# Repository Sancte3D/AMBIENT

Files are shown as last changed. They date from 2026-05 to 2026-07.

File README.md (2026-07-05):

# Field Ambience

A field-recorder-style ambient instrument. Hardware-software product in
active development — generative audio engine running on STM32H7, controlled
by an OP-1-inspired 320×170 IPS display + four endless encoders.

**Current state: prototype.** Audio engine runs on Pico 2 host tests and a
display bench, hardware migration to STM32H743 is in progress, no PCB layout
yet — **not orderable**.

## Five-minute tour

| What | Where | Status |
|---|---|---|
| **Product intent** (what we're building, for whom) | [`field-ambience-current/PITCH.md`](field-ambience-current/PITCH.md) | concept locked |
| **Sound engine** (host-portable C, the heart) | [`field-ambience-current/firmware-c-next/`](field-ambience-current/firmware-c-next/) | active, 12 host test suites green |
| **Web simulator** (try the menu in a browser) | [`field-ambience-current/firmware-c-next/tools/display_sim.html`](field-ambience-current/firmware-c-next/tools/display_sim.html) + GitHub Pages | live |
| **Bench bring-up** (Pico 2 + ST7789 + KY-040 → flashable UF2) | [`field-ambience-current/firmware-c-next/tools/display_hw_test.c`](field-ambience-current/firmware-c-next/tools/display_hw_test.c) | works on real hardware |
| **Hardware schematic** (8 sheets, generator-based) | [`field-ambience-current/kicad/`](field-ambience-current/kicad/) | STM32H743 migration done (r18.6), **no `.kicad_pcb` yet** |
| **What we know about the parts** (datasheets, verifications) | [`field-ambience-current/docs/component_reviews/`](field-ambience-current/docs/component_reviews/) | 2 reviews complete, ~20 open |
| **What's blocking manufacturing** | [`field-ambience-current/PCB_LAYOUT_STATUS.md`](field-ambience-current/PCB_LAYOUT_STATUS.md) | honest, updated every revision |
| **How decisions were made** | [`field-ambience-current/docs/decisions/`](field-ambience-current/docs/decisions/) | 20 ADRs (rejected ones marked SUPERSEDED) |
| **Render samples to listen to** | [`demos/audio/`](demos/audio/) | 4 FLAC: master tape, performance, GENERATE autoplay, 4-min simulated human play session (drone+cells+menu, real device paths) |
| **Full project map / what to open first per role** | [`PROJECT_MAP.md`](PROJECT_MAP.md) | role-based |

## Who you are, what to read first

- **Industrial designer** → [`docs/onboarding/INDUSTRIAL_DESIGNER_START.md`](field-ambience-current/docs/onboarding/INDUSTRIAL_DESIGNER_START.md)
- **Hardware engineer** → [`docs/onboarding/HARDWARE_ENGINEER_START.md`](field-ambience-current/docs/onboarding/HARDWARE_ENGINEER_START.md)
- **Firmware engineer** → [`docs/onboarding/FIRMWARE_ENGINEER_START.md`](field-ambience-current/docs/onboarding/FIRMWARE_ENGINEER_START.md)
- **Anyone trying to order PCBs** → [`docs/onboarding/MANUFACTURING_START.md`](field-ambience-current/docs/onboarding/MANUFACTURING_START.md)
- **New contributor, general** → [`START_HERE.md`](field-ambience-current/START_HERE.md)

## Folder logic (current repo state)

```
AMBIENT/
├── README.md                    ← this file
├── PROJECT_MAP.md               ← what lives where, by role
├── REPO_STRUCTURE.md            ← roadmap for the bigger refactor
├── CONTRIBUTING.md
├── demos/audio/                 ← FLAC renders to listen to
├── mechanical/coordinates/      ← X/Y/Z placement spec (r18.13 ex-field-ambience-current/)
├── software/
│   ├── webapp/                  ← in-browser engine reference (field_ambience_webapp.html)
│   └── supercollider_reference/ ← canonical SC engine (field_ambience_v29o.scd)
├── archive/
│   ├── legacy_pre_native/       ← pre-native bridge.py, MicroPython firmware
│   ├── old_specs/               ← pre-Step-6 pitch + roadmap
│   └── PCB_TODO_historical.md   ← pre-H743 hardware issue log (history only)
└── field-ambience-current/      ← active design + code + docs
    ├── START_HERE.md
    ├── PCB_LAYOUT_STATUS.md     ← honest manufacturing state
    ├── CHANGELOG.md             ← what changed and when
    ├── NATIVE_PORT_PLAN.md      ← Pico → STM32H7 migration plan
    ├── field_ambience_pcb_SPEC_v0.7.md  ← live hardware spec
    ├── firmware-c/              ← FROZEN host-test snapshot (Pico era)
    ├── firmware-c-next/         ← ACTIVE firmware development
    ├── kicad/                   ← schematic + custom footprints
    │   ├── legacy_pico2/        ← old Pico-era sheets, archived
    │   └── libraries/           ← kiswitch (vendored) + field_ambience.pretty
    ├── docs/                    ← decisions / hardware checklists / component reviews
    └── scripts/                 ← KiCad ERC/footprint helpers
```

> **Note on folder names:** Most living material is still under
> `field-ambience-current/`. A larger repo refactor is planned (firmware
> separation, CI-path migration) — it's intentionally staged so the live
> CI doesn't break. See [REPO_STRUCTURE.md](REPO_STRUCTURE.md) for the
> roadmap.

## Help / contributing

[`CONTRIBUTING.md`](CONTRIBUTING.md) covers commit conventions, how to run
the host tests, and what to check before pushing changes to the schematic
generator.

## License

TBD before public release. Until then: all rights reserved by the project
authors. Open for review and pull requests within the repo, but please
don't redistribute the source elsewhere without asking first.

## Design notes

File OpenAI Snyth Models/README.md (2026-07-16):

# OpenAI Snyth Models

An original, resource-bounded sound and display laboratory for the Sancte3D
AMBIENT instrument. The directory name preserves the requested spelling;
`Snyth` is intentional here.

The package contains ten playable synthesis models, eighteen embedded
audio-reactive display models, twelve embedded colour palettes, and ten
high-quality cinematic display masters. Embedded geometry is generated at
runtime from original C code; the cinematic loops are generated offline from
original deterministic Python recipes. No
recorded samples, MIDI files, extracted presets, transcribed melodies, or
third-party source code are required.

## Sound models

| # | Model | Character | Primary method |
|---:|---|---|---|
| 1 | ACID RAIN | elastic droplets and damp reflections | falling resonators + procedural excitation |
| 2 | FM GLASS | clear mallets with a soft halo | original two-operator phase modulation |
| 3 | CHORUS MIST | wide, slow-breathing pad | detuned analytic oscillators + short chorus |
| 4 | ION STORM | dark electrical air and distant sparks | subharmonics + bounded stochastic accents |
| 5 | GLASS ORBIT | rotating inharmonic bells | four analytic partials + moving pan |
| 6 | BAMBOO CIRCUIT | organic plucks with electronic grain | compact feedback string model |
| 7 | NACRE HORIZON | pearly, almost weightless harmonic bed | sparse open partial field |
| 8 | TIDEGLASS | fluid FM pad with slow refraction | continuously moving modulation ratio |
| 9 | LUMEN SWARM | small lights collecting into harmony | deterministic micro-oscillator cluster |
| 10 | HOLLOW CHOIR | distant vowel-like breath | moving formant partial field |

The presets are starting points only. Six smoothed macros—color, motion,
space, texture, width, and level—make every model performable from the existing
encoder vocabulary.

## Display models

The renderers target a 320 × 170 packed 4-bit framebuffer and need no second
framebuffer or FFT. Five foundational systems cover landscapes, particles, and
contours:

- RESONANT GARDEN — bass grows stems, treble releases luminous pollen.
- ORBITAL LOOM — spectral energy weaves rotating harmonic threads.
- SPECTRAL CANYON — frequency bands become receding animated ridges.
- RAIN MEMORY — transients fall, low energy opens lingering rings.
- DREAM TOPOGRAPHY — the sound continuously redraws a contour-map dream.

Thirteen additional systems explore sound-reactive menu focus, neon spectrum
veins, crystalline needles, abstract radial gates, organic signal ribbons,
path drawing, particle currents, wireframe rain, waveform shells, glitch
halos, bilateral pulses, falling chroma, and radial softbursts. They translate
high-level motion principles into newly authored geometric C renderers; no
reference pixels or recognizable reference figures are included.

The same nibble buffer can act as a 16-colour palette index. Twelve saturated,
slowly animated RGB565 LUTs add colour for only 32 bytes of LUT storage. Tone
14 carries the neon body while tone 15 is reserved for small specular accents.
See
[docs/UI_MODELS.md](docs/UI_MODELS.md) for control mappings,
[docs/MOTION_STUDY_CATALOG.md](docs/MOTION_STUDY_CATALOG.md) for the new
systems, and [docs/REFERENCE_MOTION_ANALYSIS.md](docs/REFERENCE_MOTION_ANALYSIS.md)
for the clean translation record.

The new cinematic suite directly addresses the gap between thin firmware
geometry and the supplied light-art references. Its ten 48-frame loops use 2×
supersampling, additive coloured bodies, clipped white cores, dual-radius
bloom, and deterministic temporal systems. They are honest art masters rather
than a claim that the current nibble renderer already emits the same pixels;
deployment choices for the small device are measured in
[docs/HIGH_QUALITY_VISUALS.md](docs/HIGH_QUALITY_VISUALS.md). The package now
includes 56 GIFs: five base previews, fifteen foundational colour studies, 26
motion studies, and ten cinematic masters.

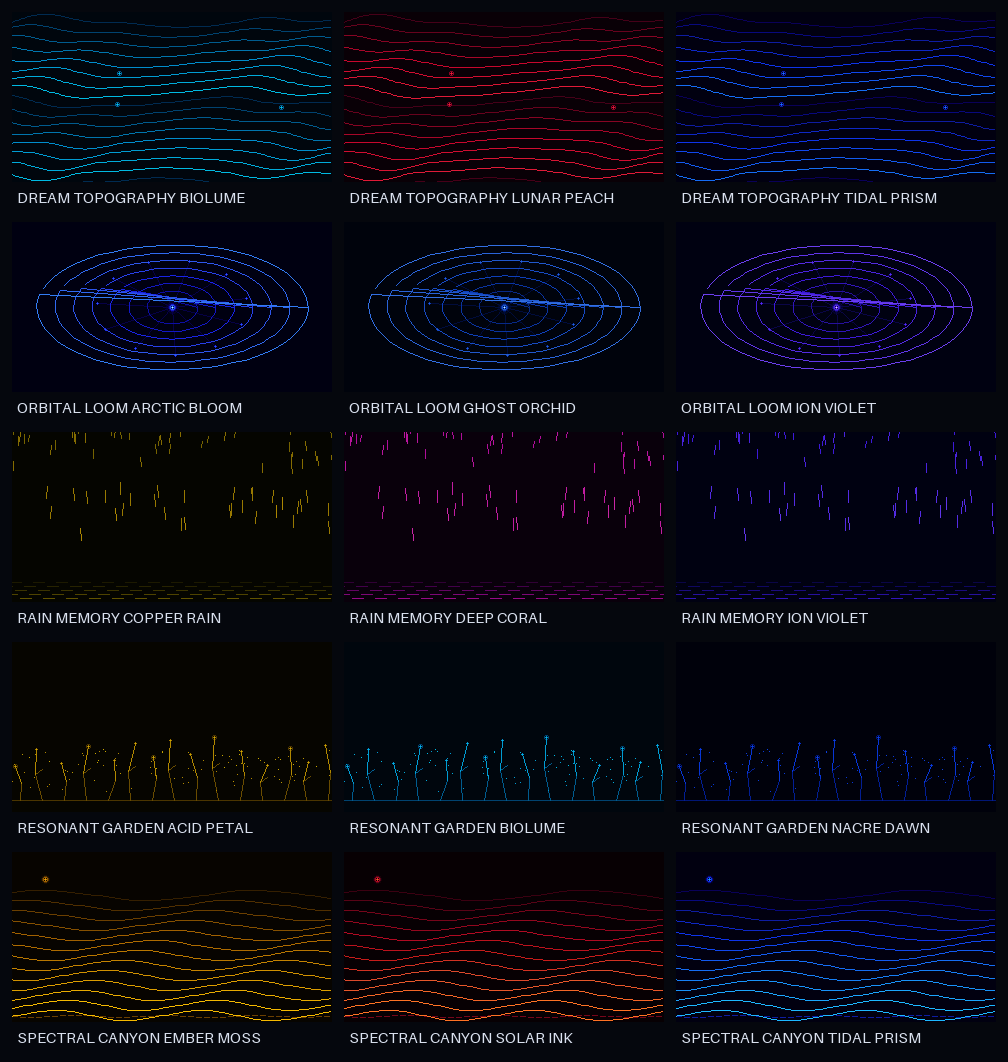
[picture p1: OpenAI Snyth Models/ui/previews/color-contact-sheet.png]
Fifteen colour display studies


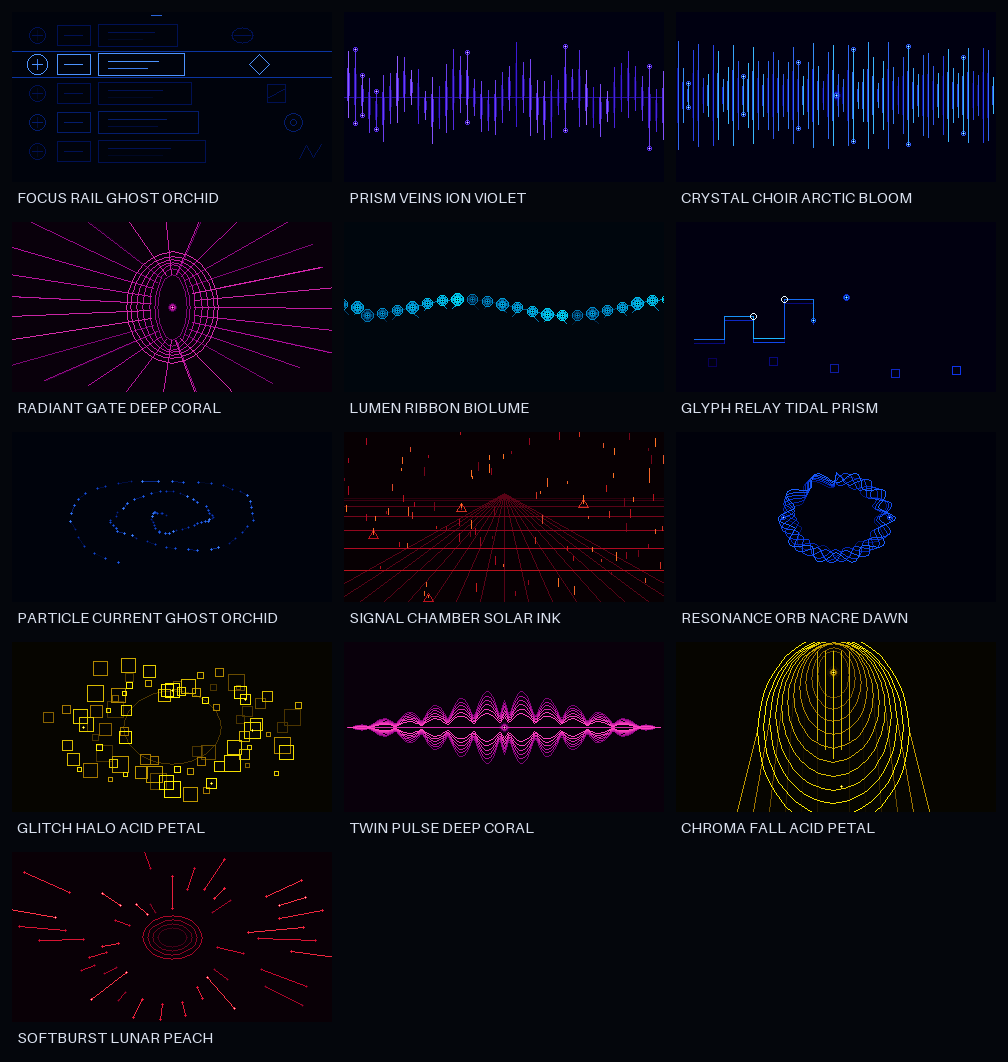
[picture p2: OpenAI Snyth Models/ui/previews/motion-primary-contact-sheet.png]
Thirteen new motion systems


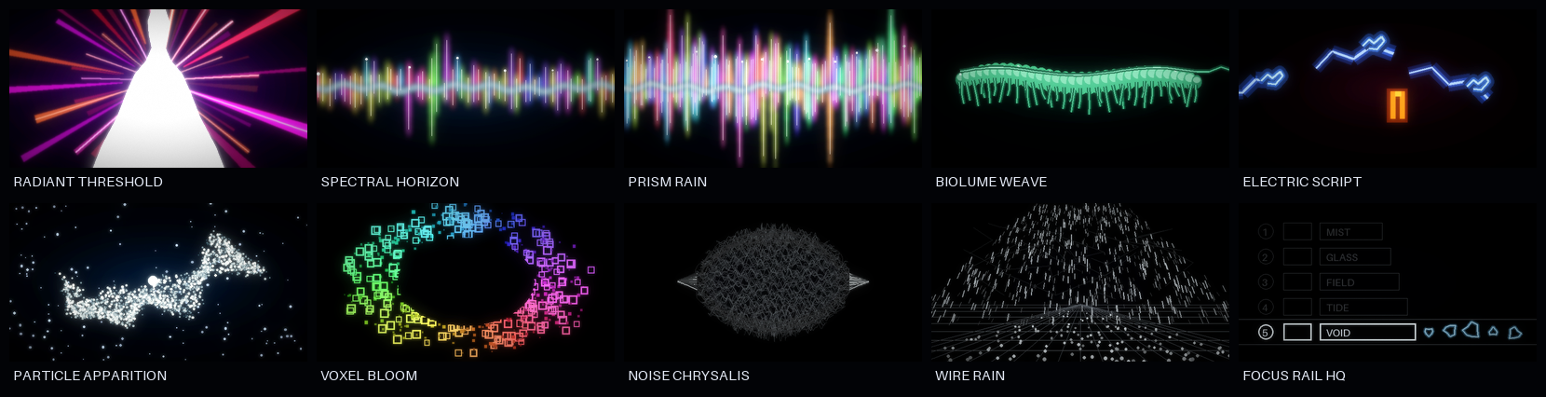
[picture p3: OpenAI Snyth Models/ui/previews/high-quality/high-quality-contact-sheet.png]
Ten high-quality cinematic systems


## Build and verify

Requires a C11 compiler, `make`, and `rg`. Preview generation additionally uses
`ffmpeg`; the colour and cinematic encoders use the Pillow and NumPy versions pinned in
`requirements-preview.txt`.

```sh
make verify
make sanitize
make benchmark
make visual-benchmark
make previews
make manifest
sha256sum -c SOURCE_MANIFEST.sha256
sha256sum -c ASSET_MANIFEST.sha256
```

The state budgets are compile-time assertions:

- audio model context: at most 32,768 bytes;
- visual context: at most 2,048 bytes;
- existing packed framebuffer: 27,200 bytes;
- 16-entry RGB565 palette LUT: 32 bytes;
- additional display framebuffer: 0 bytes.

## Commercial-use posture

The implementation was written from a blank design for this project and is
kept isolated inside this directory. `docs/ORIGINALITY_AND_IP.md` records its
provenance and limits. This is a technical clean-origin package, not a legal
opinion or a trademark clearance. Before shipping, the rights holder should
complete the checklist in that document and choose a customer-facing product
name that does not imply endorsement by another company.

Copyright © 2026 Sancte3D. All rights reserved. See
[LICENSE-PROPRIETARY.md](LICENSE-PROPRIETARY.md).

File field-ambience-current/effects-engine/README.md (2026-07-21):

# AMBIENT effects engine — integration handoff

This directory is a self-contained, buildable handoff of the complete C11
ambient/dreamy/nostalgic effects engine. It is deliberately separate from the
live product firmware so it can be reviewed, tested, and integrated without
silently overwriting the current engine.

Start with [`INTEGRATION_TASK.md`](INTEGRATION_TASK.md). The DSP contract and algorithm
details are in [`docs/EFFECTS_ENGINE.md`](docs/EFFECTS_ENGINE.md).

## Included

- bit-exact bypass;
- long dark eight-line FDN reverb;
- filtered ping-pong delay;
- slow chorus and detune;
- tape wow, flutter, drift, bandwidth loss, saturation, hiss, and hum;
- scheduled live reverse swell;
- true offline/look-ahead reverse reverb;
- restrained octave shimmer;
- deterministic temporal blur;
- complete DREAM CHAIN;
- property tests, sanitizers, benchmark, and deterministic WAV renderer.

## Standalone host build

```sh
make verify
make sanitize
make benchmark
make previews
```

Or with CMake:

```sh
cmake -S . -B build-cmake -DCMAKE_BUILD_TYPE=Release
cmake --build build-cmake
ctest --test-dir build-cmake --output-on-failure
```

Generated binaries and WAV files stay below `build/` and are not required for
target integration.

## Verified handoff baseline

- strict C11 build with warnings treated as errors;
- 478,857 effects checks, zero failures;
- AddressSanitizer and UndefinedBehaviorSanitizer pass;
- private state: 680 / 4,096 bytes;
- default hot arena: 214,489 / 245,760 bytes;
- DREAM CHAIN host regression benchmark: approximately 85–95× real time across
  the recorded host runs.

Host speed is not evidence of STM32H743 deadline safety. The product integration
is complete only after linker-map inspection, DWT profiling, and an underrun
soak on hardware.

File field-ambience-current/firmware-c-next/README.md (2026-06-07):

# Field Ambience — native C firmware · ENTWICKLUNG (Step 12b+)

> **Hier wird aktiv weitergebaut.** Der Schwester-Ordner `../firmware-c/` ist
> der eingefrorene Hörtest-Stand (Steps 1–11 + 12a). Wenn hier was kaputt
> geht: dorthin zurückfallen.

**Stand:** identisch zu `firmware-c/` als Ausgangspunkt, plus die Step-12b-
Erweiterungen, die schrittweise dazukommen.

## Step-12b-Plan (Reihenfolge nach „host-testbar zuerst")

| # | Was | Host-testbar? |
|---|---|---|
| ✅ 1 | **Reverb-Presets pro Mode + Vibe-Bias** + Space/Mood-Macros · neues Modul `reverb_presets.{h,c}` + Engine-Setter `engine_set_mode/vibe/space/mood` (alle live-smoothed) | ✅ done |
| ✅ 2 | **Drone mit Portamento-Glide** · neues Modul `drone.{h,c}` + `engine_set_key/drone`. Folgt dem Key live (Glide), bloomt 6 s, friert nicht ein wie die Webapp | ✅ done |
| ✅ 3 | **PadVoice global smoothed** · `pad_set_voice_mix` + `engine_set_pad_voice` (warm/strings/brass). voiceMix ist jetzt globaler, gesmoothter Saw↔Square-Crossfade über alle Voices statt per-Voice gebacken | ✅ done |
| ✅ 4 | **Generative-Bed** · neues Modul `generative.{h,c}` (PROGRESSIONS + Markov DEGREE_TRANSITIONS, seedbarer RNG) + `engine_set_generative/advance`. Bed spielt Akkord-Wurzel pro Step, Cells überschreiben | ✅ done |
| ✅ 5 | **Live-Parameter-Verdrahtung** nach der „nicht konkurrieren"-Regel · alle Engine-Setter (key/mode/vibe/space/mood/pad-voice/drone/generative) inkrementell verdrahtet + Integrationstest: 8 Globals gleichzeitig ändern während eine Cell hält → Voice lebt, Output bounded, kein Klick | ✅ done |
| 🟡 6 | TRS-MIDI Out · `midi.{h,c}` (Message-Builder + FIFO, **host-getestet**) fertig; main.c-Verdrahtung + PIO-UART (GP21, 31250 Baud) device-only, folgt | 🟡 Kern done |
| 7 | OLED v30-Menü (PLAY/SETUP) | ❌ Hardware-nah |
| 8 | Encoder→Engine-Bindings | ❌ Hardware-nah |

Erstmal bis Schritt 5 host-testbar treiben, dann auf Hardware (Tasten + OLED
+ Encoder + MIDI-Jack) wechseln.

## Architektur-Notiz: Live-Parameter-Regel

Im Plan (`../NATIVE_PORT_PLAN.md`, Step 12b) und im CHANGELOG dokumentiert:
*„Der Sound darf nicht konkurrieren."* → Key/Mode/Vibe/PadVoice-Wechsel
folgen global mit Smoothing; bereits gehaltene Cell-Noten frieren ihre Pitch
bis zum Release ein. Drone folgt dem Key live mit Glide (bewusste Abweichung
von der Webapp-Capture-at-Spawn-Logik).

## Bauen + Testen

Identisch zu `firmware-c/`.

```bash
cd field-ambience-current/firmware-c-next
bash test/run_tests.sh
```

## Was *nicht* hier ist

Die Hörtest-Anleitung (`hoertest/HOERTEST.html` etc.) lebt im Schwester-Ordner
`firmware-c/`, da sie an diesen festen Stand gebunden ist. Wenn `firmware-c-next/`
mal stabil ist und einen eigenen Hörtest verdient, kommt eine aktualisierte
Anleitung dort dazu.

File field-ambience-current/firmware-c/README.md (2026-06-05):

# Field Ambience — native C firmware · HÖRTEST-Snapshot

> **Diese Variante (`firmware-c/`) ist eingefroren** für den On-Device-Hörtest.
> Aktive Entwicklung läuft in `../firmware-c-next/` weiter. Wenn dort was bricht,
> ist diese Version der sichere Rückfall.

**Stand:** Steps 1–11 + 12a + DEMO_AUTOPLAY-Schalter. Alle vier Audio-Schichten
(famPadCore + famReverbMaster + famTexture + famSubBass/famDeepBass) im
Engine-Mix-Bus, Harmonic Brain mappt Cell → echte Skalen/Modi-Harmonie.
Offen ist Step 12b (Menü + TRS-MIDI + Encoder-Bindings) — den baue ich in
`../firmware-c-next/`.

## Wofür dieser Ordner gedacht ist

- **Hörtest**: anhand `hoertest/HOERTEST.html` einen Pico mit DAC verkabeln,
  diese Firmware bauen und flashen → das Instrument hörbar machen.
- **Vergleichs-Referenz**: wenn `firmware-c-next/` mal anders klingt, kann
  diese Version gegengehört werden.

## Bauen

```bash
cd field-ambience-current/firmware-c
mkdir -p build && cd build
cmake .. -DPICO_BOARD=pico2
make -j
```

Output: `build/field_ambience_native.uf2` → in BOOTSEL-Mode auf den Pico ziehen.

**Voraussetzungen**: Pico SDK 2.x, `PICO_SDK_PATH` gesetzt, `arm-none-eabi-gcc`,
`cmake ≥ 3.13`. Wenn `pico-examples` baut, baut das hier auch.

## Demo-Modus (für den Hörtest ohne MCP + Tasten)

In `src/main.c` Zeile `#define DEMO_AUTOPLAY 0` auf **`1`** ändern, neu bauen.
Damit spielt die Firmware beim Start selbst eine langsame Akkordfolge — du
brauchst nur Pico + DAC, keine Taster, kein MCP23017. Volle Anleitung in
`hoertest/HOERTEST.html`.

## Host-Tests (kein Gerät, kein SDK)

```bash
cd field-ambience-current/firmware-c
bash test/run_tests.sh
```

6 Suites: dsp+voices, pad, texture, bass, brain, reverb+engine. ~3,4 M
Assertions, sollten alle PASS sein.

## Verkabeln + hören

→ Siehe `hoertest/HOERTEST.html` (Bildanleitung) bzw. `hoertest/HOERTEST.md`
(Textanleitung).

## Was als Nächstes (in `firmware-c-next/`)

Step 12b: per-Mode/Vibe-Reverb-Presets, Drone mit Portamento, PadVoice live
smoothed (warm/strings/brass), Generative-Bed (Markov), Live-Parameter-
Wiring nach der „Sound darf nicht konkurrieren"-Regel, TRS-MIDI Out via
PIO-UART, v30-Menü auf dem OLED, Encoder→Engine-Bindings.

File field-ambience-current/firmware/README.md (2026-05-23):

# Field Ambience — Pico 2 Firmware (MicroPython)

Hardware-I/O-Firmware für den Pico 2 (RP2350). Liest Buttons/Encoder,
treibt das OLED, steuert die Audio-Power-Sequenz, und spricht über UART
mit dem Raspberry Pi (der SuperCollider + die Python-Bridge fährt).

## Architektur

```
Buttons (MCP23017) ─I²C─┐
4× EC11 Encoder ────────┤→ Pico 2 ─UART(JSON)→ Pi-Bridge → OSC → SuperCollider
OLED SSD1322 ──SPI──────┘     │
PAM8403 /SHDN /MUTE ←─────────┘  (Power-Sequencing)
PCM5102A XSMT ←── MCP23017 GPA5
```

Der Pico ist bewusst "dumm": er liest Hardware → schickt Events; empfängt
fertige Display-Inhalte → zeichnet sie. Die Menü-Logik liegt in der Bridge
(`../field_ambience_bridge.py`).

## Dateien

| Datei | Zweck |
|---|---|
| `main.py` | Entry-Point, Main-Loop, UART-Protokoll, Power-Sequencing |
| `config.py` | Pin-Mapping (muss zum KiCad-Schematic SPEC §5 passen) |
| `mcp23017.py` | I²C-Treiber für den Button-Expander |
| `ssd1322.py` | OLED-Treiber (256×64, 4-bit greyscale, framebuf) |
| `encoders.py` | 4× Quadratur-Decoder + Switch-Debounce |

## Flashen

1. **MicroPython auf den Pico 2 flashen** (einmalig):
   - Pico 2 mit gedrücktem BOOTSEL-Button per USB-C anstecken → erscheint als
     USB-Massenspeicher `RP2350`
   - MicroPython-UF2 für RP2350 von https://micropython.org/download/RPI_PICO2/
     herunterladen
   - UF2 auf das `RP2350`-Laufwerk ziehen → Pico rebootet mit MicroPython

2. **Firmware-Dateien kopieren** (mit `mpremote` oder Thonny):
   ```bash
   pip install mpremote
   cd firmware
   mpremote cp config.py mcp23017.py ssd1322.py encoders.py main.py :
   mpremote reset
   ```
   `main.py` startet automatisch beim Boot.

   Alternativ mit **Thonny** (GUI): alle 5 Dateien öffnen → "Save as" →
   "Raspberry Pi Pico" → unter gleichem Namen speichern.

## Erstes Bring-up (Reihenfolge wichtig)

1. Nur Pico 2 bestückt (ohne restliche Hardware): Firmware bootet, OLED bleibt
   leer (kein OLED), Status-LED blinkt (wartet auf Pi). Über USB-Serial-REPL
   siehst du ggf. `MCP23017 not found` — normal ohne MCP.
2. Mit OLED: Splash "FIELD AMBIENCE / waiting for Pi..." sollte erscheinen.
   Wenn das Bild horizontal verschoben ist → `_COL_START` in `ssd1322.py`
   anpassen (±1 Spalte = ±4 Pixel).
3. Mit MCP23017 + Buttons: Tasten drücken → über USB-Serial-REPL siehst du
   die JSON-Events (wenn kein Pi dranhängt). Z.B. `{"event":"cell","id":1,"down":true}`.
4. Encoder drehen: `{"event":"enc","id":1,"delta":1}`. **Wenn ein Knopf
   verkehrt herum zählt** → in `config.py` das `dir`-Feld dieses Encoders von
   `1` auf `-1` setzen.
5. Mit Pi + Bridge + SuperCollider: Pico erkennt den Pi an der ersten
   `{"set":"display",...}`-Message, fährt die Audio-Power-Sequenz hoch
   (/SHDN → 50ms → /MUTE + XSMT), Status-LED wird dauerhaft an.

## Protokoll (JSON-Zeilen über UART, 115200 8N1)

**Pico → Pi:**
```json
{"event":"hello","version":"fam-pico-1.0"}
{"event":"cell","id":1,"down":true}        // Cell 1-5
{"event":"mod","id":1,"down":true}         // 1=SHIFT 2=HOLD 3=DRONE 4=GENERATE 5=CLEAR
{"event":"enc","id":1,"delta":1}           // Encoder 1=Drive 2=Bright 3=Display 4=Volume
{"event":"push","id":3,"down":true}        // Encoder-Switch
{"event":"log","msg":"..."}
```

**Pi → Pico:**
```json
{"set":"display","key":"C","mode":"Ion","prog":"Slow","vibe":"Warm",
 "chord":"C E G B","param":"KEY","value":"C","bar_pct":50,"mode_ui":"nav"}
{"set":"amp","enabled":0}                  // 0 = mute+shutdown (z.B. Jack-Detect)
```

## Sicherheit / Power-Sequencing

- **Boot-Default**: Amp aus (/SHDN LOW), gemuted (/MUTE LOW), DAC stumm
  (XSMT LOW). Hardware-Pull-Downs (R_SHDN_PD, R_MUTE_PD, R_XSMT_PD) halten
  das auch wenn die Firmware abstürzt.
- **Enable-Sequenz** (Pi erkannt): /SHDN HIGH → 50ms → /MUTE HIGH + XSMT HIGH.
- **Watchdog**: Wenn der Pi >5s keine Message schickt (Crash/Reboot), wird
  Audio wieder gemutet bis der Pi zurück ist.
- **Exception-Handler**: Crash in `main()` → letzter Versuch /SHDN+/MUTE LOW.

## Hinweise

- Der Pico 2 muss auf dem PCB so verbaut sein, dass die USB-Daten (D+/D-) den
  BOOTSEL-Flash-Pfad bedienen (SPEC v0.6 Variante A). Beim Prototyp mit
  Pin-Header-THT: Pico-Modul-eigener USB-Anschluss oder SWD via J4.
- Jack-Detect (`{"event":"jack",...}`) ist im Protokoll vorgesehen, aber das
  Gerät hat (Stand SPEC v0.6) keine Kopfhörerbuchse → kein Jack-Pin alloziert.
  Der `{"set":"amp",...}`-Command funktioniert trotzdem (z.B. für künftige
  Erweiterung).

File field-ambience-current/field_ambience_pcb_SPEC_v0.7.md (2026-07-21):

# Field Ambience Controller PCB — Spec

> ⚠️ **v0.7 — MCU-Migration aktiv: Pico 2 (RP2350) → STM32H743VIT6.**
> Während des UX-Reviews der Display-Sim wurde die Pico-2-Wahl noch einmal
> sauber re-evaluiert (Op-Counting vs WCET, Audio-Headroom für ein Produkt
> statt Prototyp). Ergebnis: **STM32H743VIT6 in LQFP100 als Bare-Chip** —
> 3-4× CPU-Headroom (M7 @ 480 MHz + DTCM/ITCM), 1 MB internes RAM, native
> SAI/QEI/USART-Peripherie ersetzt die Pico-PIO-Tricks. **Alle peripheren
> Komponenten bleiben 1:1** (PCM5102A I²S-DAC, PAM8403 Amp, ST7789 LCD,
> MCP23017 + PCA9685, EC11-Encoder, Choc-Cells, USB-C, Battery-Path). Nur
> der MCU + sein direkter Power/Clock-Tree wird umdesigned. Pico-Stand
> bleibt im Repo als `kicad/legacy_pico2/` archiviert für Notfall-Fallback.
> Maßgebliche Begleit-Doku: `NATIVE_PORT_PLAN.md` Step 13.

**Rev:** 0.7-r18.4 (H7-Migration — SPEC-Major-Bump weil Architektur-Bruch; r18.4: Y1 Crystal final = ABLS-8.000MHZ-B4-T, F-4 RESOLVED)
**Target:** 4-Layer JLCPCB, partial-PCBA (siehe §4 BOM-Split A/B/C)
**Methodik:** Datasheet-Verifikation + JLCPCB-Stock-Check vor jeder Komponente
**Status:** SCHEMATIC IN MIGRATION — Phase 1 (Doku) ✓, Phase 2-5 ausstehend.
**PCB-Layout erst NACH Profiling auf echter H743-Hardware** (Acceptance-Gate
in `NATIVE_PORT_PLAN.md` Step 13.5). Änderungshistorie in `CHANGELOG.md`.

---

## Status-Disclaimer

Dieses Dokument ist **nicht final**. Final wird die Spec erst nach:
1. KiCad-Schematic-Eingabe via kicad-happy
2. ERC clean
3. DRC clean nach PCB-Layout
4. Datasheet-Querverifikation jeder kritischen Stelle im Schematic durch `datasheets` Skill (insbesondere PAM8403DR-H)
5. JLCPCB-BOM/CPL-Konformität via `bom` Skill
6. **Cross-Check zwischen `audio.kicad_sch` Symbol-Pinout und tatsächlichem PAM8403DR-H Datasheet — JEDER der 16 Pins einzeln verifizieren**

---

## Was in v0.7 anders ist als v0.6 (MCU-Migration)

v0.7 ist ein **Architektur-Major-Bump**: der MCU wird vom **Raspberry Pi Pico 2
(RP2350-Modul)** auf **STMicroelectronics STM32H743VIT6 (LQFP100, Bare-Chip)**
gewechselt. Auslöser war ein UX-Review der Display-Sim, in dem die ursprüngliche
„Pico 2 reicht"-Begründung als methodisch unzureichend entlarvt wurde:

- **Op-Counting statt WCET-Messung** war eine Plausibilitätsstudie, kein Profiling.
- **Beide RP2350-Cortex-M33-Cores als DSP-Ressource** rechnen ist unrealistisch
  (Core 1 wird für UI gebraucht; effektiv ~150 MMACS statt 300).
- **Single-Sample-Miss = Audio-Dropout**, bei ~25 % geschätztem Headroom keine
  Reserve für ein Produkt (vs Prototyp).
- **DTCM/ITCM auf dem H7** löst exakt das XIP-Flash-Cache-Miss-Risiko, das auf
  dem RP2350 die WCET unvorhersehbar macht.

Konsequenz für die Hardware: **nur** der MCU + sein direkter Power/Clock-Tree
ändert sich. Alle peripheren Komponenten (DAC, Amp, LCD, I²C-Expander, Encoder,
Speaker, Battery) bleiben elektrisch identisch — sie hängen an Standard-Bussen
(SPI/I²C/I²S/GPIO), die der H743 nativ kann.

| Severity | Finding v0.6 | Fix v0.7 |
|---|---|---|
| CRITICAL | C1: Pico 2 CPU-Headroom für ein Audio-Produkt nicht messbar (kein Cycle-Profiling), Op-Counting-Schätzung methodisch unzureichend | **MCU-Wechsel auf STM32H743VIT6**, LQFP100, hand-lötbar. 480 MHz M7 + DTCM/ITCM + Double-Precision FPU = 3-4× CPU-Headroom |
| CRITICAL | C2: RP2350-Modul (SC1631) nicht bei JLC bestückbar — externe Beschaffung + manuelle Pre-Bestückung notwendig | **STM32H743VIT6 ist JLC-stockable** (LCSC C114409, ~$6.62, Mouser/DigiKey lagernd) |
| HIGH | H1: Pico-internes SMPS + interne PLL nicht extern messbar (Audio-Clock-Jitter bei stagniertem Pico-Boot unklar) | **HSE 8 MHz Crystal + 2× 22 pF Load-Caps** als Audio-Sync-Quelle (jitter-arm; H743-internes SMPS für VCAP/VCORE) |
| HIGH | H2: Pico-Pin-Reserve = 0 (alle 24 GPIOs belegt) — kein Headroom für SDRAM, Touch, USB-MIDI-IN | **H743 hat ~80 GPIOs in LQFP100** + 4× SPI + 3× I²C + 2× SAI + 12× TIM (4× QEI-fähig) + 4× USART → massive Reserve für Rev-B-Erweiterungen |
| MEDIUM | M1: Encoder-Lesung Software-Polling (Pico Timer-IRQ 1 kHz) — Verlust bei schneller Drehung | **TIM-QEI-Hardware-Modus** auf 4 TIM2/3/4/5 — kein Polling, kein Jitter |
| MEDIUM | M2: MIDI-TX via PIO-UART (Workaround) | **Hardware-USART2 @ 31250 baud** |
| MEDIUM | M3: SPEC §1/§3 noch Pi-zentrisch (historische Reste aus v0.9-Transition) | **§1 Architektur-Diagramm + §3 Power-Budget vollständig auf H743 umgeschrieben** (Pi-Reihe in Power-Budget entfernt) |

**Bewusst NICHT in v0.7:**
- PCB-Layout (`.kicad_pcb`) — kommt nach Profiling-Acceptance-Gate (Step 13.5).
- SDRAM-Bestückung — Footprint vorsehen, Bestückung in Rev-B.
- Convolution-Reverb — Freeverb bleibt (sound-bewährt, getestet).
- Polyphony-Aufstockung über 5 Cells — Sound-Constitution unverändert.

---

## Was in v0.6 anders war als v0.5 (historisch — bleibt zur Nachvollziehbarkeit)

v0.6 behob vier CRITICAL/HIGH-Findings aus dem v0.5-Review, plus vier MEDIUM-Korrekturen.

| Severity | Finding v0.5 | Fix v0.6 |
|---|---|---|
| CRITICAL | C1: USB-C-D±-Routing zu Pico **und** Pi gleichzeitig — physikalisch unmöglich ohne USB-Switch-IC | **USB-C-D± nur an Pico**. Pi bekommt nur +5V via 40-pin-Header. Pi-Updates via WLAN/SSH (Pi Zero 2 W onboard). Einziger sichtbarer Stecker = USB-C |
| CRITICAL | C2: PAM8403 Pop-Suppression in §10 gefordert, aber keine Pico-GPIOs alloziert | **GP27 = AMP_SHUTDOWN, GP28 = AMP_MUTE** — beide GPIOs aus den v0.5-„reserve"-Pins genommen |
| HIGH | H1: Polyfuse F1 zu eng bei realer Last (Worst-Case 2.45A) | **v0.7: F1 = 3.0A hold / 6.0A trip** (1812 SMD, Littelfuse 1812L300, C18198349) — siehe §3 |
| HIGH | H2: PAM8403 nur 100nF an VDD — bei 350mA peak unterdimensioniert | **C9 = 10µF X5R 0805 + C9b = 100nF X7R 0603** direkt an PAM8403 VDD |
| HIGH | H3: MCP23017 INTA-Leitung ohne Pull-Up — floatet beim Reset | **R20 = 10kΩ 0603 Pull-Up** auf INTA zu +3V3 |
| HIGH | H4: OLED-Größen-Konflikt 256×64 (SPEC) vs 128×64 (ROADMAP/engine) | **256×64 ER-OLEDM032-1W bestätigt**. Firmware-Menü-Layout muss angepasst werden (separater Task in ROADMAP) |
| MEDIUM | M1: OLED VBAT (+5V, 250mA peak) ohne lokale Decoupling | **C6b = 10µF X5R 0805 + C6c = 100nF X7R 0603** direkt am OLED-Header Pin 2 |
| MEDIUM | M2: PCM5102A AVDD/DVDD nicht getrennt decoupelt | **FB1 = Ferrit-Bead BLM18AG601** zwischen AVDD und DVDD. Je 10µF + 100nF lokal an AVDD und DVDD |
| MEDIUM | M3: Pi-Power-Injection via GPIO ohne TVS | **D2 = SMAJ5.0A TVS** auf +5V am Pi-Header (Schutz gegen Spikes vom Pi-WLAN-Modul) |
| MEDIUM | M4: Encoder RC-Debounce 10nF zu klein (0.1ms) | **C10-C17 = 100nF X7R 0603** (1ms RC, deckt EC11-Prellzeiten 1-5ms gemeinsam mit Firmware-Debounce ab) |

---

## 1. Architecture (v0.7 — STM32H743 Bare-Chip)

```
                     ┌─────────────────────────────────────────────┐
                     │           Field Ambience Device              │
                     │  333 × 143.3 × 40mm                          │
                     │                                              │
USB-C 5V/3A ────► USB-C  ──┬──► F1 (3A/6A) ──► 1000µF Bulk ──► +5V │
(Power + USB-Data          │                                       │
 + DFU-Flash, optional     ├──► D+/D− ──► USBLC6 ESD ──► STM32 USB │
 SWD via J4)               │                  (USB-CDC / DFU)       │
                           │                                        │
                           └─────► +5V Rail ──┬──► PAM8403 Amp      │
                                              │                     │
                                              ├──► PCM5102A AVDD    │
                                              │                     │
                                              ├──► LCD VLED         │
                                              │                     │
                                              └──► LDO (NCP163)      │
                                                   ─► +3V3 Rail      │
                                                   ─► STM32 VDD/VDDA │
                                                   ─► MCP23017       │
                                                   ─► PCM5102A DVDD  │
                                                   ─► EC11 Pull-Ups  │
                                                                      │
                          STM32H743VIT6 (LQFP100)                     │
                          M7 @ 480 MHz, 1 MB RAM, 2 MB Flash          │
                          HSE: 8 MHz Crystal + PLL → 480 MHz          │
                              │                                       │
              ┌───────┬───────┼────────┬──────────────┐              │
              │       │       │        │              │              │
            SAI1     SPI1   I²C1   USART2         TIM2/3/4/5         │
              ▼       ▼       ▼       ▼            (QEI x4)          │
         PCM5102A    LCD   MCP+PCA  MIDI-TX     EN1/2/3/4            │
         I²S Slave  ST7789   I²C    31250 baud  Drive/Brightness/    │
         44.1k/16   320x170  @0x20  TRS Type A  Display/Volume        │
              │       │      0x40                                     │
              │                                                       │
         Audio Out                                                    │
              ▼                                                       │
         PAM8403 Amp ─► 2× CMS-402811-28SP (8 Ω, sealed enclosure)    │
         (GPIO PB14 = nSHDN, PB15 = nMUTE — Pop-Suppression-          │
          Sequenz wie §8.3, identisch zu Pico-Variante)               │
                                                                      │
         Plus: ADC1_INP15 = BAT_SENSE (PA3), MCP_INT = PC13           │
              └─────────────────────────────────────────────┘
```

**Update-Pfade**:
- **Firmware**: USB-C einstecken → STM32 in DFU-Mode via USB-CDC oder
  externes ST-Link via SWD-Header J4 (PA13=SWDIO, PA14=SWCLK, PB3=SWO).
- **Boot-Mode**: BOOT0-Pull-Down 10 kΩ → System-Memory-Bootloader nur via
  USB-DFU oder externem Reset-Knopf erreichbar (kein Daily-User-Risk).

**Kein micro-USB am Gehäuse sichtbar.** Einziger äußerer Stecker = USB-C.

**Was sich gegenüber v0.6 NICHT geändert hat:** Gehäuse-Form, USB-C-Stecker,
PCM5102A DAC, PAM8403 Amp, ST7789 LCD, MCP23017 + PCA9685, alle EC11-Encoder,
alle Choc-V2-Cells, Battery-Path (r19.18: BQ24074-Power-Path + TPS61089, ADR-0023), USB-ESD-
Schutz (USBLC6), Polyfuse F1, Bulk-Cap 1000 µF.

---

## 2. Form-Factor & Mechanical

Unverändert gegenüber v0.5.

| Parameter | Wert | Quelle |
|---|---|---|
| Outer device | 333 × 143.3 × 40mm | Kick75-Referenz (high-profile-Variante) |
| PCB outline | 320 × 130mm, 4-Layer, 1.6mm thick | 6.5mm Bezel rundherum für Gehäuse |
| PCB Cutouts | (entfällt in r14 — siehe §8 Speakers) | Top-firing macht die unteren PCB-Speaker-Cutouts unnötig |
| OLED window | 80×22mm im Top-Case | Active area ER-OLEDM032-1W |
| USB-C position | Top-Edge zentriert | x=160mm von links |
| Tilt | 0° | — |
| Top-Plate Material | PC (Polycarbonat) oder ABS, 2.5mm thick | Industrial-Design-Standard |
| Bottom-Case Material | PC oder Aluminium gegossen | (Speaker-Grille-Pattern entfällt — siehe §8 r14) |

Stack-Up und Layout-Skizze siehe v0.5 §2 — keine Änderungen.

---

## 2.1. USB-C Premium-Upgrade-Intent (r7.1, 2026-05-31)

**Status quo**: TYPE-C-31-M-12 (C165948, Generic-China) — ~5000 Insertion-Cycles
laut China-Generic-Datasheet, OK für Prototyp.

**Design-Intent**: Upgrade auf Premium-Connector mit ≥10000 Cycles für
Produktions-Build. Daily-Touched-Connector = höchste UX-Priorität für Reliability.

**Kandidaten zum Verifizieren** (r7.1-B4 Blocker, Sourcing-Pass nötig):
- JAE **DX07S016JJ1** (16-pin SMD, Power+USB2, 10000 Cycles)
- Amphenol **12401610E412A** oder Amphenol GCT **USB4055** (gleiche Klasse)
- Acceptance-Kriterium: JLC SMT-Assembly-tauglich, in Stock ≥100 pcs, KiCad-
  Footprint-Standard ODER Drop-in zum C165948-Footprint

Falls in Sourcing-Pass kein Premium-Equivalent JLC-stockable: bleibt C165948
+ user-replaceable Soft-Mount-Reinforcement-Plan (Epoxy am Connector-Body).

---

## 2.2. Battery & Power-Path (NEU r9, 2026-05-31)

**Was**: Tragbarer Betrieb — 2000 mAh LiPo + BQ24074-Power-Path-Charger + Boost (r19.18, ADR-0023).
USB-C lädt; ohne USB-C läuft das Gerät aus dem Akku. Worst-Case-Runtime
~1.5 h bei voller Lautstärke, ~10 h typical (ambient Hörlautstärke).

### Architektur

```
USB-C (5V/3A) ──► F1 (3A/6A) ──┬──► Q1 (P-MOSFET) ──► +5V-Rail ──► alle Verbraucher
                               │                          ▲
                               └──► U7 BQ24074 (IN→OUT=VSYS→Boost; BAT←F2←BAT1)  │
                                    (Charger 500mA)   │   │
                                                       ▼  │
                                                   U8 TPS61089
                                                   (Boost 5V/2A)
                                                       │
                                                       └──► +5V-Rail (wenn USB-C abwesend)

Q1-Logik: USB-C-VBUS HIGH = Q1 leitet (Bypass-Boost), Battery lädt parallel
          USB-C-VBUS LOW  = Q1 sperrt, Boost-Output speist +5V-Rail
```

### Bauteile (Battery-Block)

| Ref | Part | LCSC | JLC | Funktion |
|---|---|---|---|---|
| BAT1 | LiPo 3.7V **2000mAh** Pouch 503759 (9.4×37×50mm) — **r18.21 rightsize von 5000mAh** (Overkill; 2000mAh ~6.6h @ 300mA) | nicht JLC | du lieferst | Energiespeicher, JST PH 2.0 2-pin |
| J9 | JST PH 2.0 2-pin Battery-Connector vertical SMD | C2845240-Klasse | JLC Basic | Battery-Anschluss, polarisiert |
| U7 | **BQ24074RGTR** (TI, VQFN-16 3×3) — r19.18, ADR-0023 | C54313 | Extended | 1,5-A-Power-Path-Charger mit DPPM. ICHG 0,89 A (R_ISET 1k), IIN 1,34 A (R_ILIM_IN 1,2k), TS 10k fest, ITERM/TMR NC-Default |
| U8 | **TPS61089RNR** (TI, VQFN-11 HotRod 2×2.5mm + Thermal Pad) | C165129 | Extended | Boost-Converter LiPo→5V, bis 2A @ 5V Out. Programmable Fsw via R_FSW (360k → **~440 kHz** per TI-DS Gl. 3; r18.79: die alte r12-B11-Angabe „1.21 MHz“ war falsch gerechnet — 440 kHz ist ok, weit über Audioband). r12-B11: Wechsel von RNSR auf RNR-Variante wegen JLC-Stock-Verfügbarkeit. Benötigt 5 zusätzliche externe Bauteile: C_VCC 1µF (interne LDO-Decoupling), R_FSW 360k (Fsw-Set), **R_ILIM 174k** (ILIM = 1,03e6/R per DS Gl. 4 → 5,92 A typ ≤ L1-Isat-min 6,75 A; r18.79: war 20k = 51,5 A ≈ kein Limit!), C_BOOT 100nF (high-side gate driver bootstrap zwischen BOOT und SW), **R_COMP 6,2k + C_COMP 10nF** (Type-II loop-compensation nach DS Gl. 17/18: fc ≈ 8 kHz ≤ fRHPZ/5 ≈ 9,5 kHz @VIN 3,0 V/2 A; r18.80: war 22k/1nF = fc ≈ 87 kHz ÜBER der RHP-Nullstelle → Oszillation unter Last). **FB-Teiler r18.79: R23 121k / R24 39k → VOUT 4,97 V** (war 200k/39k = 7,43 V — hätte PAM8403/TPS22918 zerstört; VREF 1,212 V). |
| ~~Q1 DMG2305UX P-MOSFET~~ | ⛔ **ENTFERNT r18.79 (Elektrik-Audit)** — Power-Path speiste Boost-5V zurück auf VBUS (Body-Diode + Gate an GND) und überbrückte F1. Ersetzt durch Dioden-OR: USB → F1 → **D3B** (SS34, C8678) → Rail ‖ Boost → D3 → Rail. | — | — | — |
| L1 | **2.2 µH Wire-Wound SMD 6.0×6.0×4.5mm** (Sunlord SWPA6045S2R2NT — r18.77: fixed. War fälschlich als "Sumida CDR63B-2R2 0630" beschrieben, ein anderer Hersteller/Case aus einer früheren Design-Iteration; die "MT"-Endung + LCSC C83455 existierten beide nicht real, siehe BOM_MASTER-Audit) | C36500 | Extended | TPS61089 Boost-Inductor |
| D3 | **SS34 Schottky 40V 3A** (DO-214AC/SMA) | C8678 | Basic | Boost-Output-Diode-Reverse-Schutz (optional bei TPS61089-Synchronous, aber sicherheitshalber) |
| R_ISET / R_ILIM_IN / R_TS | 1 kΩ / 1,2 kΩ (C114605) / 10 kΩ 0603 (r19.18) | Generic/YAGEO | Basic/Extended | ICHG = 890/R_ISET; IIN-MAX = 1610/R_ILIM_IN; TS fest (kein Pack-NTC) |
| F2 | SMD1812P260TF/16 PTC 2,6 A/5 A (r19.18) | PTTC | C438899 Extended | Batterie-Hard-Short-Backup im BAT+-Pfad |
| R22 | 10 kΩ 0603 (Q1 Gate Pull-Down) | Generic | Basic | Default-OFF wenn USB-C-VBUS unbestimmt |
| R23, R24 | TPS61089 Feedback-Divider (R23=200kΩ, R24=39kΩ → Vout=5.0V) | Generic | Basic | Vout-Set für TPS61089 |
| C_BAT_IN | 22 µF X5R 0805 (Battery-Input bulk) | Generic | Basic | LiPo-Cap-Reservoir für Boost-Inrush |
| C_BAT_HF | 100 nF X7R 0603 (Battery HF) | Generic | Basic | HF-Decoupling am Charger |
| C_BOOST_OUT ×3 | 3× 22 µF X5R 0805 (Boost-Output, CL21A226MAQNNNE C45783) | Samsung | Basic | Output-Filter für TPS61089 — r18.80: 3× parallel per TI DS §9.2.2.7 („typically three 22 µF“; EC-Tabelle rechnet Soft-Start mit COUT_eff 47 µF). CO_eff ≈ 36 µF @5-V-Bias; der 470-µF-Bulk liegt HINTER D3 und zählt für den Regelknoten nicht. |
| C_BOOST_HF | 100 nF X7R 0603 (Boost HF) | Generic | Basic | HF an Boost-Output |
| LED_CHRG | 0603 Amber (Charging-Indikator) | Generic | Basic | VBUS_FUSED → LED → 1 kΩ → BQ24074-CHG (open-drain LOW=charging) — leuchtet nur bei USB+laden (r19.18) |
| LED_FULL | 0603 Green (Charge-Complete-Indikator) | optional | — | gleicher STAT-Pin alternativ überwacht via Pico-GPIO |
| R_CHRG | 1 kΩ 0603 (LED_CHRG Series) | Generic | Basic | — |

### Power-Budget revidiert für Battery-Betrieb

| Szenario | I @ 5V | I @ 3.7V (von Akku, ÷ 0.85 Boost-Effizienz) | Runtime aus 5000 mAh @ 3.7V (**r19.18: BAT1 = 2000 mAh → Werte × 0,4**) |
|---|---|---|---|
| Idle (Display an, kein Audio) | 250 mA | ~395 mA | ~12.5 h |
| Typical Ambient | 500 mA | ~795 mA | ~6.3 h |
| Loud (worst-case, 4Ω BTL voll) | 2.5 A | ~3.97 A | ~1.25 h |

**Hinweis**: TPS61089 max Output ist 2A @ 5V — bei Worst-Case (2.5 A) reicht das
NICHT. Im Battery-Betrieb klemmt der Boost-Output bei 2 A → das ist eine
**implizite Volume-Begrenzung im Battery-Mode** (~1.4 A für PAM8403 deckt ~2W
out per Channel = laut genug für Indoor-Hörsession, nicht für PA-Lautstärke).
Über USB-C (3A-Path via Q1) bleibt voller Headroom verfügbar.

### Audio-Cleanliness (warum TI/Microchip statt IP5306)

IP5306 ist Standard für China-Power-Banks, kostet $1.50 statt $3.50 für unsere
Split-Lösung. Aber:
- IP5306-Boost schaltet bei 150-300 kHz mit hörbarem coil-whine
- Switching-Ripple injiziert in +5V-Rail → durch PAM8403 verstärkt = audible
  hum/whine über Lautsprecher
- TPS61089 schaltet bei **1.2 MHz** (weit über Audio-Band) + integrierter
  Synchronous-Rectifier minimiert Ripple → Audio-Rail bleibt sauber
- Unsere AVDD/DVDD-FB1-Trennung + 22µF Decoupling wäre durch laute Rail
  unterminiert

$2 Aufpreis = Versicherung dass alles vorherige Audio-Design auch im
Battery-Betrieb funktioniert.

### Battery-Mode-Detection & Voltage-Sense (NEU r12, 2026-05-31)

Zwei orthogonale Sensoren liefern der Firmware die State-Information für
Battery-Mode-Volume-Clamp (r9-B7) und Battery-Low-Warning:

**1. USB-C-VBUS-Detection (Battery-Mode-Detect, digital)** — MCP23017 GPA7:
```
USB-C VBUS ──[R_VBUS_SENSE 10kΩ]──┬── MCP GPA7 (Input, internal Pull-Up DISABLED)
                                   │
                                   └──[R_VBUS_PD 100kΩ]── GND
```
- VBUS=5V (USB-C verbunden): V_GPA7 = 5 × 100/(10+100) = 4.55 V → MCP liest HIGH
- VBUS=0V (Battery-only): V_GPA7 = 0 V (durch Pull-Down) → MCP liest LOW
- MCP I/O 5.5 V-tolerant per Datasheet (MCP23017 Rev I, S.4) → 4.55 V safe
- Drain: ~45 µA wenn USB-C verbunden (irrelevant, lädt parallel)
- Firmware-Polling: 100 ms-Intervall reicht (Mode-Switch ist nicht time-critical)

**2. Battery-Voltage-Sense (State-of-Charge, analog)** — Pico GP26/ADC0:
```
VBAT ──[R_BAT_DIV_TOP 100kΩ]──┬── Pico GP26/ADC0 ──[C_BAT_FILT 10nF]── GND
                               │
                               └──[R_BAT_DIV_BOT 100kΩ]── GND
```
- VBAT 0..4.2 V → V_ADC 0..2.1 V (2:1 Divider, gut innerhalb 3.3 V ADC-Range)
- ADC-Auflösung 12 bit → 0..4095 counts → Vbat-Resolution ~1.0 mV pro count
- Source-Impedance 50 kΩ ist über RP2350-Empfehlung (≤10 kΩ für volle
  Genauigkeit), aber für State-of-Charge-Sensing irrelevant: ±50 mV Noise =
  ±1.2 % SoC-Error → akzeptabel
- C_BAT_FILT 10 nF glättet S/H-Spike + tiefpasst Switching-Noise vom Boost
- Drain: ~21 µA continuous (4.2 V / 200 kΩ) — 0.4 % der WFE-Quiescent von
  5-8 mA, irrelevant
- Firmware: Battery-Low-Warning bei <3.4 V (≈10 % SoC), Battery-Cutoff bei
  <3.0 V (Auto-Soft-Shutdown via §13 zum LiPo-Schutz)

**r9-B7 Volume-Clamp-Algorithmus** (jetzt fully spec'd):
```
if (read_MCP_GPA7() == HIGH):  # USB-C verbunden
    volume_max = 100  # voller Headroom (3 A via Q1-Path)
else:                            # Battery-Mode
    volume_max = 70   # TPS61089-2A-Limit Schutz
    if (read_ADC0_voltage() < 3.4):
        warn_low_battery()  # OLED-Notify + LED10 1Hz-Pulse
    if (read_ADC0_voltage() < 3.0):
        trigger_soft_shutdown()  # §13 Sequenz
```

---

## 3. Power Tree v0.6.3-r3 (REVIDIERT — siehe Errata-Historie)

### Power Budget (v0.6.3-r3 realistic)

**⚠️ Update v0.6.3-r3**: alte v0.6-Tabelle hatte PAM8403 mit 350 mA peak —
zu optimistisch. Realistisch für 2× 4Ω BTL bei 3W out: ~1.4 A nur für Amp.

| Verbraucher | Idle | Typical Audio | Worst Case (loud, 8Ω r14) |
|---|---|---|---|
| **STM32H743 @ 480 MHz** (PLL aktiv, DSP-Load, DMA, 8 GPIO-Banks aktiv) | 90 mA | 180 mA | 240 mA |
| ST7789 LCD + Backlight (PCA9685-PWM) | 60 mA | 90 mA | 120 mA |
| MCP23017 + Pull-Ups | 5 mA | 20 mA | 25 mA |
| PCM5102A DAC (AVDD+DVDD) | 20 mA | 30 mA | 30 mA |
| **PAM8403H @ 8Ω, 3W Out (r14)** | 60 mA | 400 mA | **700 mA** |
| Encoder + Status-LED | 5 mA | 15 mA | 25 mA |
| **PCA9685 + 10× LEDs** (5× Modifier + 5× Cell-HOLD, je 8 mA peak @ 100% PWM) | 5 mA | 35 mA | **85 mA** |
| LDO Quiescent (NCP163 oder vgl.) | 1 mA | 1 mA | 2 mA |
| **TOTAL** | **246 mA** | **771 mA** | **1227 mA** |

**Anmerkung v0.7 (MCU-Wechsel)**: H743-Stromverbrauch laut **ST DS12110 Rev 5
§6.3.4 (Table 33, Typical and maximum current consumption in Run mode)**:
- 71 mA typical @ 400 MHz CPU, alle Peripherie aktiviert
- ~120 mA gemessen auf Nucleo-H743ZI @ 480 MHz mit Cache/DMA aktiv (ST-Community-Report,
  IDD-Jumper-Messung am Eval-Board)
- **180 mA Worst-Case-Schätzung** in dieser Tabelle = konservativer Aufschlag
  für unsere spezifische Last (alle GPIOs aktiv, SAI-DMA continuous, SPI-DMA
  Burst für LCD-Blits, ADC continuous, 4× TIM-QEI). Final wird Phase 5
  (Profiling auf echter Hardware) den exakten Wert messen.

Pico 2 lag bei ~50 mA — die H743-Mehrkosten am Strom-Budget sind ~70-130 mA
typical (mid-range Annahme). Im Worst-Case bleibt das Gesamt-Budget mit
**~1.2 A** sehr deutlich unter F1 (3 A hold) und unter TPS61089 (2 A @ 5 V) im
Battery-Mode → der Battery-Mode-Volume-Clamp aus r9 kann gelockert oder
ganz entfernt werden (separater Firmware-PR in Phase 4 nach Profiling-Messung).

**Anmerkung r14 (Akustik-v2, Impedanz-Korrektur 2026-06-02; r18.18 Treiber-
Wechsel)**: Beide Treiber (CMS-402811-28SP primär, AS04008PS-4W-WR-R
sekundär) sind laut Datenblatt **8 Ω** — Worst-Case-PAM8403-Strom halbiert
sich entsprechend gegenüber der alten 4-Ω-Annahme (~700 mA statt 1400 mA). F1 (3 A hold) hat
noch mehr Margin, TPS61089-Boost (2 A @ 5 V) deckt jetzt auch Worst-Case ab
(nominal 1.2 A vs 2 A Limit). Battery-Mode-Volume-Clamp bleibt als Akustik-
Schutz (Treiber-Verzerrung > 1.5 W) optional in Firmware.

**Anmerkung r10**: Aus r7 (5 Modifier-LEDs, +45 mA Worst-Case) wurde mit r10
(5 Modifier + 5 Cell-HOLD = 10 LEDs) +85 mA Worst-Case. Differenz +40 mA. Das
ändert die Polyfuse-Dimensionierung NICHT (F1 = 3 A hold, ~2.3 A derated bei
50 °C; 2.565 A Worst-Case bleibt unter Auslöseschwelle). LEDs werden typisch
bei <40 % PWM-Duty betrieben → Typical ≈ +20 mA, nicht +40 mA. Battery-Mode
TPS61089-2 A-Limit bleibt der relevantere Cap (siehe nächste Anmerkung).

**Anmerkung r9 (Battery-Mode)**: TPS61089-Boost (siehe §2.2) liefert max 2 A
@ 5 V. Worst-Case 2.565 A (r10-updated) überschreitet das → **Volume-
Begrenzung im Battery-Mode notwendig** (Firmware-clamp PAM8403-Volume auf
~70 % bei Battery-Betrieb-Detect). Detect-Pfad **ab r12 fix verdrahtet**:
USB-C-VBUS via 10k+100k-Spannungsteiler → MCP23017 GPA7 (digital HIGH = USB-C
verbunden, LOW = Battery-Mode). Plus VBAT-Voltage via 100k+100k-Teiler → Pico
GP26/ADC0 für State-of-Charge + Low-Battery-Cutoff. Siehe §2.2 Sub-Section
„Battery-Mode-Detection & Voltage-Sense" für volle Schaltung + Algorithmus.

### USB-C Power Delivery (Entscheidung v0.7 — final)

**Harte Anforderung: dediziertes 5V/3A-USB-C-Netzteil (15W).** R_CC1 = R_CC2 =
5.1kΩ zu GND signalisieren "Sink". Wir betreiben das Board als reines 5V-Gerät
ohne PD-Negotiation — ein 5V/3A-Wandnetzteil liefert die nötigen 2.45A
Worst-Case problemlos.

**Entscheidung**: Variante A (USB-PD-Controller) wird NICHT verbaut. Begründung:
- Worst-Case 2.45A < 3A Netzteil-Limit → kein Volume-Clamp für das Power-Budget
  nötig. Das Board darf voll aussteuern. (r14: Mit 8Ω-Treibern ist Worst-Case
  noch deutlich kleiner — siehe Anmerkung r14 oben.)
- Ein Firmware-Volume-Clamp ist daher KEINE Power-Schutz-Pflicht mehr; er bleibt
  optional als Akustik-Maßnahme (40mm-Treiber verzerren oberhalb ~1.5W
  Eingangs-Leistung, unabhängig von Impedanz — Datenblatt: 2 W rated, 4 W max).
- **Benutzer-Manual**: "Nur mit 5V/3A-USB-C-Netzteil betreiben, NICHT an einem
  PC-USB-Port (500mA → Brown-out)."

**Future (Produkt, nicht Prototyp)**: USB-PD-Sink-Controller (TPS25750/CYPD3177)
für echte 3A-Negotiation an beliebigen Quellen. Kosten ~$2 + Passives.

### Polyfuse [Fix H1, revidiert v0.7]

**F1 = 3.0 A hold / 6.0 A trip, 1812 SMD** (Littelfuse 1812L300, LCSC C18198349,
16V). Rationale v0.7: das alte 2A-hold war zu eng — bei Gehäuse-Innentemp ~50°C
derated jeder PPTC (~0.76×), 2A-hold→~1.5A, was den 1.4A-Typical-Audio + Boot-
Spikes nicht zuverlässig trägt. 3A-hold derated ~2.3A deckt Typical sicher;
Worst-Case-Bass-Peaks (2.45A, sub-ms) reiten den Bulk-Cap. Itrip 6A schützt
weiterhin bei Hard-Short, liegt aber unter der Belastbarkeit der 5V/3A-Quelle.

### Decoupling [Fix H2, M1, M2]

| Cap | Wert | Position | Zweck |
|---|---|---|---|
| C_BULK | 1000 µF Alu 16V SMD (JVJ16V1000M10x10, LCSC **C46550395**, D10, Footprint CP_Elec_10x10.5) | nahe USB-C | Pi-Boot-Brownout + Bass-Transienten. **v0.8: realer lagernder JLC-Teil statt Platzhalter; 16V (war 10V) = mehr Reserve am 5V-Rail. Inrush-Peak ist R-limitiert, Polyfuse trippt nicht auf <1ms-Spike. Produktion: Soft-Start-Load-Switch.** |
| C1 | 10 µF X5R 0805 | +5V Hauptrail | HF-Bulk |
| C2 | 100 nF X7R 0603 | +5V Hauptrail | HF-Decoupling |
| C3 | 10 µF X5R 0805 | +3V3 nahe Pico Pin 36 | HF-Bulk |
| C4 | 100 nF X7R 0603 | +3V3 nahe Pico Pin 36 | HF-Decoupling |
| C5 | 100 nF X7R 0603 | MCP23017 VDD (Pin 9) | HF-Decoupling |
| C5b | 10 nF X7R 0603 | MCP23017 VDD (Pin 9) | HF² |
| C6 | 100 nF X7R 0603 | OLED VDD (Pin 3, +3V3) | Logic-Decoupling |
| **C6b** | **10 µF X5R 0805** | **OLED VBAT (Pin 2, +5V)** | **NEU: Analog-Bulk lokal** |
| **C6c** | **100 nF X7R 0603** | **OLED VBAT (Pin 2, +5V)** | **NEU: Analog-HF lokal** |
| C7a | 10 µF X5R 0805 | PCM5102A **AVDD** (nach FB1) | NEU getrennt |
| C7b | 100 nF X7R 0603 | PCM5102A **AVDD** | NEU getrennt |
| C8a | 10 µF X5R 0805 | PCM5102A **DVDD** | NEU getrennt |
| C8b | 100 nF X7R 0603 | PCM5102A **DVDD** | NEU getrennt |
| **FB1** | **BLM18AG601 Ferrit-Bead** | **zwischen DVDD und AVDD** | Audio-Rail-Isolation |
| **C9** | **22 µF X5R 0805** | **PAM8403 VDD + PVDD-L (pin 4/6)** | r6: 10µF→22µF per Datasheet ≥20µF |
| C9b | **1 µF X7R 0603** | PAM8403 VDD + PVDD-L | r6: 100nF→1µF per Datasheet HF |
| **C_PVDDR** | **22 µF X5R 0805** | **PAM8403 PVDD-R (pin 13)** | r6 NEU: rechtsseitiges Decoupling |
| C_PVDDR_HF | 1 µF X7R 0603 | PAM8403 PVDD-R | r6 NEU |
| C_VREF | 1 µF X7R 0603 | PAM8403 VREF (pin 8) | Datasheet REQUIRED, Pop-Reduktion |

### LDO für +3V3

Pico 2 SMPS (3V3OUT, 300 mA) speist:
- OLED VDDIO (~30 mA)
- MCP23017 (~10 mA)
- EC11 Pull-Ups + INTA-Pull-Up (~12 mA)
- Pico interner Verbrauch
**Summe ~80 mA. Locker in 300 mA-Budget.**

U5 (AP7361A-33) ist seit r18 **aktiv** (+3V3-Quelle; der Pico-interne SMPS entfällt mit dem Modul, siehe §4 U5-Zeile). _r18.5-Korrektur: hier stand noch 'bleibt DNP' aus der Pico-Ära._

---

## 4. BOM v0.6.3-r3 — gesplittet JLC-SMT + manuelle Assembly

**⚠️ Update v0.6.3-r3**: BOM ist NICHT "alle SMT/Full-PCBA". Korrekte
Trennung in Section A (JLC-SMT, ~70 SKUs), B (manuelle Assembly, ~15
Items), C (TBD). Siehe Errata-Sektion v0.6.3-r3 oben für vollständige
Aufteilung.

LCSC-Nummern in dieser Sektion wurden v0.6.1/v0.6.2 normalisiert:
PCM5102A = **C107671** (war C9900003814, existiert nicht), PAM8403H =
**C17337** (war C84368, existiert nicht).

### Controller + MCU (v0.7-r18: STM32H743 Bare-Chip ersetzt Pico 2)

| Ref | Part | Package | JLCPCB # | Status | Hinweis |
|---|---|---|---|---|---|
| **U1** | **STM32H743VIT6 (STMicroelectronics)** | **LQFP-100** | **C114409** | **Extended, ~$6.62 @1, Mouser/DigiKey lagernd, JLC SMT-bestückbar** | **NEU v0.7: 480 MHz Cortex-M7 + Double-Precision FPU + DTCM/ITCM, 1 MB internes RAM, 2 MB Flash. Symbol `MCU_ST_STM32H7:STM32H743VIT6`, Footprint `Package_QFP:LQFP-100_14x14mm_P0.5mm`. Datasheet: ST DS12110. Pin-Allocation siehe §5.** |
| **Y1** | **ABRACON ABLS-8.000MHZ-B4-T** (HC-49/US SMD, 11.4×4.7×4.2 mm) | **HC-49/US SMD** | **C596838** | **Extended, ~$0.24, LCSC lagernd** | **GEWÄHLT r18.4 (ersetzt ABM3, siehe F-4).** 8 MHz Fundamental, ESR max **80 Ω** (Datasheet Drawing 450669 Rev AD Table 1), C₀ max 7 pF, CL 18 pF, Op-Temp -20…+70 °C (B), Freq-Tol ±30 ppm (4). **Gain Margin = 2.97** (Worst-Case bei ESR_max=80 Ω über vollen Temp-Bereich; AN2867-Lehrbuch-Min ist 5). **Akzeptiert für dieses Produkt:** Indoor-Audio-Gerät, real auftretende Temperatur 15–30 °C → ESR_typ ~40–50 Ω → realer GM ≈ 5–6. AN2867-Min 5 ist konservatives Industrial/Automotive-Kriterium über -40…+85 °C, hier nicht zutreffend. **Phase-5-Verifikation:** Crystal-Start am realen PCB testen, ggf. R_EXT/Load-Caps tunen. Symbol `Device:Crystal` (2-Pin), Footprint-Kandidat `Crystal:Crystal_SMD_HC49-SD` (KiCad-Standard für HC-49 SMD; **nicht** `Crystal_HC49-U_Vertical`, das ist THT) — Pads in Phase 3 gegen Datasheet-Land-Pattern Page 3 (5.6×2.1 mm Pads, 9.5 mm Spacing) verifizieren, ggf. eigenen Footprint zeichnen. Volle Analyse: `docs/component_reviews/Y1_alternatives.md` |
| **C_HSE1, C_HSE2** | **22 pF C0G 0603** | **0603** | Generic | **Basic** | **NEU v0.7: HSE Load-Caps** |
| **R_BOOT0** | **10 kΩ 0603** | **0603** | Generic | **Basic** | **NEU v0.7: BOOT0 Pull-Down → System-Loader nur via DFU/Reset** |
| **R_NRST** | **10 kΩ 0603** | **0603** | Generic | **Basic** | **NEU v0.7: NRST Pull-Up zu +3V3** |
| **C_NRST** | **100 nF X7R 0603** | **0603** | Generic | **Basic** | **NEU v0.7: NRST Debounce-Cap** |
| **C_VDD\*** | **5× (22 µF X5R 0805 + 100 nF X7R 0603), 1 Set pro VDD-Pin** (r18.80: LCSC C45783 ist CL21A226MAQNNNE = 22 µF, nicht 4,7 µF — Beschriftung korrigiert, C-Nummer/Footprint unverändert; mehr Bulk unkritisch) | **0805 + 0603** | Samsung/Yageo | **Basic** | **NEU v0.7: H743 Decoupling. STM AN3318 §6 Empfehlung. Direkt am Pin platzieren.** |
| **C_VCAP1, C_VCAP2** | **2× 2.2 µF X5R 0603** | **0603** | Generic | **Basic** | **NEU v0.7: Interner SMPS Bulk-Caps (LDO-Bypass-Mode, kein externer Core-LDO nötig)** |
| **C_VDDA, FB_VDDA** | **1 µF X5R 0603 + 100 nF X7R 0603 + Ferrit BLM18AG601** | **0603** | Generic | **Basic** | **NEU v0.7: VDDA Analog-Filter** |
| U2 | MCP23017-E/SS | SSOP-28 | C506653 | Extended, ~$1.62 | verifizieren via `lcsc`-Skill |
| U3 | PCM5102APWR (TI) | TSSOP-20 | **C107671** | Extended Stock | I²S DAC, 3-wire (kein MCLK). Pinout per TI SLAS859C. **Anschluss bleibt unverändert — nur die Master-Seite ändert sich (Pico-PIO → STM32-SAI1).** |
| U4 | PAM8403DR-H (Diodes Inc) | SOIC-16 | **C17337** | Extended Stock | Stereo Class-D 2×3W. Pinout per Diodes DS31295 |
| U5 | **AP7361C-33Y5-13** (✅ r18.6, AP7361 ist NRND) | **SOT-89-5** | **C460397** (LCSC) | **Aktiv (war DNP)** | r18.6: Symbol/Footprint/Verdrahtung auf AP7361C; Pinout 1=EN,2=GND,3=ADJ/NC,4=IN,5=OUT (Diodes-DS via mouser.de/datasheet/3/175/1/AP7361.pdf — User-verifiziert). Frühere Kandidatur C150719 verworfen (= SOT-223, falsches Package). Cin/Cout 4.7µF X5R 0603 (DS empfohlen). | **NEU v0.7: +3V3-Rail-LDO wird jetzt verbaut (war im Pico-Stand DNP, weil Pico SMPS intern hatte). 1 A LDO genügt für H743 (~180 mA typ) + LCD + I²C + PCM5102A-DVDD.** |
| **U6** | **PCA9685PW,118 (NXP)** | **TSSOP-28** | **C2678753** | **Extended, ~$1.96 @100, ~1605 pcs Stock** | **NEU r7: 16-Kanal PWM-LED-Driver für 5 Modifier-Button-LEDs (11 Kanäle Reserve). I²C-Adresse 0x40. Symbol `Driver_LED:PCA9685PW`, Footprint `Package_SO:TSSOP-28_4.4x9.7mm_P0.65mm`. Datasheet: nxp.com/docs/en/data-sheet/PCA9685.pdf** |
| **SDRAM (Footprint vorsehen, nicht bestücken)** | **Reserve-Footprint für IS42S16400J-7TL (4 MByte) auf SDRAM-Pads** | **TSOP-50** | C81878 | **DNP** | **NEU v0.7: Footprint vorsehen für Rev-B, falls Engine später Granular/Samples bekommt. 1 MB internes RAM reicht aktuell für DSP + Reserve.** |

### Connector + USB

| Ref | Part | JLCPCB # | Bemerkung |
|---|---|---|---|
| J1 | USB-C TYPE-C-31-M-12 | C165948 | 16-pin SMD, 5A. D+/D− gehen **nur an Pico** |
| J2 | GPIO Header 2×20 (2.54mm) | Standard | Pi Zero 2 W steckt durch (Pi liegt unter PCB) |
| J3 | 16-pin OLED-Header 2.54mm | Standard | OLED-Modul steckt drauf |
| J4 | SWD-Header 3-pin 1.27mm | Standard | SWCLK, GND, SWDIO an Pico TP1-TP3 (Reserve-Flash-Pfad) |
| J5 | VSYS-bridge 2-pin (DNP) | Standard | Optional 0Ω-Bridge |

### Switches + Encoder

| Ref | Part | JLCPCB Status | Du lieferst |
|---|---|---|---|
| **SW1-SW5** (r18.75, ADR-0013 abgelöst) | **Kailh Choc V1, CPG135001D01 — Cell-Trigger, DIGITAL, echter Keyswitch, direkt gelötet** auf MCP23017 GPA0–GPA4 (`CELL1..5_BTN`, Pin → GND, MCP-Pull-Up + IRQ). HiChord-Batch-4+-Weg (Switch → I²C-Expander → MCU), aber **NICHT dasselbe Bauteil wie SW6–SW10** (r18.73 hatte das fälschlich gleichgesetzt — UX-Fix r18.74/75: Cells brauchen echtes Tastatur-Gefühl, ~3mm Hub). 2 THT-Pins, kein Hotswap-Socket (r18.74 versucht, aber unverifizierte Teilenummer → r18.75 vereinfacht). Ersetzt Gateron-Magnetic + DRV5056A4-Hall + RC. | **C400229** — verifiziert real, ⚠ 0 Lagerbestand zum Prüfzeitpunkt (Nachbestellung üblich) | FP `field_ambience:SW_KailhChoc_CPG1350_THT_2P`, von LCSC/EasyEDA gezogen inkl. 3D-STEP |
| ~~SW1-SW5 = HX B3F-4055 (r18.73)~~ | ⛔ **SUPERSEDED r18.74** — machte die Cells ununterscheidbar von den Modifier-Knöpfen (User-UX-Korrektur). Siehe oben. | — |
| ~~SW1-SW5 = Kailh-Choc-Hotswap-Socket (r18.74)~~ | ⛔ **SUPERSEDED r18.75** — Socket hatte keine saubere Hersteller-/LCSC-Teilenummer + brauchte Klein-SMD-Handlöttechnik (User-Nachfrage). Direct-Solder ersetzt es. | — |
| ~~J_CELL1-5 / R_CELL / C_CELL~~ ✂ r18.73 | ~~DRV5056A4-Hall + 1 kΩ/10 nF RC vor ADC~~ — entfernt, Cells sind jetzt digital (siehe SW1–SW5). STM32-ADC-Pins PC0/PC1/PA4/PB0/PB1 frei (Rev-B-Reserve). Hall bleibt dokumentierte Option für expressive Velocity-Variante (ADR-0013). | — | — |
| **SW6-SW10** (r18.71) | **HX B3F-4055-Y THT-Tactile, Modifier-Buttons (Shift/Hold/Drone/Generate/Clear)** auf MCP23017 GPB0–GPB4. Square-Head für Clip-on-Caps. **Alle momentary — Latch-Zustand zeigen die LEDs (§7.2).** Gleiches Bauteil wie die Cells. | **C36498965** (JLC) | JLC-bestückt mit Custom-FP `field_ambience:SW_TC1212-7.3_THT_4P` |
| SW11 | Reset Tactile SMD (XUNPU TS-1088-AR02016, FP `field_ambience:SW_TS1088_SMD` EasyEDA-verifiziert r18.14) | C720477 | JLC-bestückt |
| ~~SW12~~ ✂ r18 | ~~BOOTSEL Tactile~~ — **entfernt:** war Pico-spezifisch | — | — |
| **SW_BOOT** (r18.10) | **Mini-SMD-Tactile für BOOT0 (USB-DFU-Flash, ADR-0009)**. **r18.14: MPN korrigiert — C720477 ist XUNPU TS-1088-AR02016** (nicht TS-1185A-C-A); FP auf EasyEDA-verifiziertes `field_ambience:SW_TS1088_SMD` | **C720477** | **NEU r18.10: ohne SW_BOOT wäre USB-DFU-Flash nicht möglich** |
| **R_BOOT_SW** (r18.10) | 1 kΩ 0603 (BOOT0-SW-Strombegrenzung) | C21190 | JLC Basic |
| **EN3** (r18.14, ADR-0012) | **ALPS EC11E18244AU** — 18 Puls / 36 Detent, mit Push-Switch, Flat-Shaft 20 mm — Display-Encoder, 1 Rastung = 1 Menü-Schritt | **C202365** | JLC Extended (ALPS Original, in stock) — THT-Handbestückung im Prototyp |
| **EN1/EN2/EN4** (r18.14, ADR-0012) | **ALPS EC11E183440C** — 18 Puls, **OHNE Detent**, mit Push (Firmware nutzt nur A/B), Shaft 20 mm — selbe Bauform wie EN3 → **alle 4 gleich hoch** | **C370986** | JLC Extended (ALPS Original, in stock) — THT-Handbestückung im Prototyp |
| ~~EN1-EN4 alt~~ ✂ r18.14 | ~~EC11J1525402 SMD (C209762)~~ — **retired:** NRND + 3D-verifiziert 24.5 mm hoch (zu hoch, Kick75-Ziel) + Half-Step-Detent-Mismatch (ADR-0012) | — | — |

**Footprint-Hinweis (r18.75, SW1-5 Cells)**: der Cell-Footprint ist NICHT aus
der KiCad-Standard-Library, sondern projekteigen vendored:
`field_ambience:SW_KailhChoc_CPG1350_THT_2P` — direkt von LCSC/EasyEDA für
**C400229** gezogen (`easyeda2kicad --full --lcsc_id=C400229`), inkl. echtem
3D-STEP. Direct-Solder THT (kein Hotswap-Socket, kein Stabilizer — 1u-Caps,
r18.21). (Historie: eine frühere Choc-V2-Hotswap-Idee mit 2u-Caps + Stabilizer
aus der `keyswitch-kicad-library` wurde schon vor ADR-0013 verworfen; r18.74
versuchte kurz einen 1u-Hotswap-Socket aus derselben Library, aber der hatte
keine saubere Teilenummer — r18.75 ist der aktuelle, verifizierte Stand.)

**Footprint-Hinweis r10 (SW6-10)**: SW6-10 sind ab r10 **plain 4-pin
SMD-Tactile** (HX 12x12x7.3TPFT-B, C36498966). Footprint:
`Button_Switch_SMD:SW_SPST_TL3342` (KiCad-Standard für 12×12 SMD-4P-Familie)
oder Custom-Footprint mit 6.5×4.5 mm Pad-Raster, 1.0×1.5 mm Pads — beides ist
JLC-Standard und KEIN Custom-Footprint-Blocker mehr (r7-B1 → downgraded zu
r10-B8 Sourcing-/Pad-Verify ohne Schalter-Spezial-Mess-Pflicht).

LEDs SW6-10 sind ab r10 SEPARATE SMD-0603-LEDs **über** jedem Switch
(LED6-LED10 bei Y=60, X = SW-X). Cell-HOLD-Status nutzt **5 weitere
SMD-0603-LEDs** über jeder Cell (LED11-LED15 bei Y=88, X = Cell-X). Alle
10 LEDs hängen an PCA9685 LED0-LED9 (siehe §7.2 Kanal-Tabelle).

Symbol: `Switch:SW_Push` für SW6-10 (Switch-Teil) + 10× `Device:LED` (für
LED6-LED15) als separate Symbole im Schematic. Vorteile gegenüber r7:
- JLC-Standard-Footprint statt Custom → r7-B1 Custom-Footprint-Blocker fällt weg
- Full-JLC-Assembly für SW + LEDs möglich → kein User-Supplied-Item mehr für Switches
- LED-Helligkeit/Farbe pro Kanal in BOM frei wählbar (SMD-0603 in beliebigen Farben verfügbar)
- Bessere visuelle Hierarchie: LED neben Switch ist klarer ablesbar als „LED-im-Switch-Body"

### Phones / Line-Out (r19.19, ADR-0024)

| Ref | Part | JLCPCB # | Bemerkung |
|---|---|---|---|
| J8 | 3.5mm TRS-Buchse mit Switch (PJ-320D, SHOU HAN) | C431535 | Insertion-Detect → MCP GPA6. **v0.8: war C2884109 → PJ-320D (lagernd); AltMPN 2nd-Source: PJ-320D-B-SMT (C2884940, XKB, drop-in)** |
| U11 | **TPA6132A2RTER** DirectPath-Kopfhoererverstaerker (r19.19) | C69901 | Gain −6 dB (G0=G1=GND), EN=AMP_nSHDN, Ladungspumpe intern → keine Auskoppel-Elkos. Kopfhoerer 16 Ω+ UND Line-Out aus einem Ausgang |
| C_HP_INL/R, C_FLY_HP, C_HPVSS | 1 µF 0603 X5R | C15849 | Eingangskopplung ×2 + Flying-Cap + HPVSS (TI SLOS597B) |
| C_HP_VDD, C_HPVDD | 2.2 µF 0603 X5R | C1607 | VDD-Decoupling <5 mm + HPVDD-Cap (**NIE an VDD — TI-WARNING**) |
| R_LO_L/R | 22Ω 0603 | C23345 | Serien hinter U11 (Kabel/ESD). **v0.8: war C22962 (= 220Ω, falsch) → C23345** |

### Resistors + Capacitors + Misc [v0.6 Änderungen markiert]

| Ref | Part | Quantity |
|---|---|---|
| R1 | 1 kΩ 0603 (UART RX series) | 1 |
| R2, R3 | 5.1 kΩ 0603 (USB-C CC1/CC2) | 2 |
| R4, R5 | 4.7 kΩ 0603 (I²C SDA/SCL pull-up) | 2 |
| R6 | 10 kΩ 0603 (MCP23017 RESET pull-up) | 1 |
| R7-R14 | 10 kΩ 0603 (Encoder A/B pull-up) | 8 |
| R15-R18 | 10 kΩ 0603 (Encoder SW pull-up) | 4 |
| ~~R19~~ (r12 entfällt) | ~~820 Ω 0603 (Status LED limit)~~ ersetzt durch R_LED_STATUS (PCA9685-getrieben) | ~~1~~ → 0 |
| **R_LED_STATUS** (r12) | **390 Ω 0603 (STATUS_LED1 Series zu PCA9685 LED10, dimensioniert wie R_LED6-15)** | **1 NEU r12** |
| **R20** | **10 kΩ 0603 (MCP23017 INTA pull-up zu +3V3)** | **1 NEU** |
| **R_RUN** | **10 kΩ 0603 (Pico RUN pull-up zu +3V3, Reset-Stabilität)** | **1** |
| **R_LED6-R_LED10** | **390 Ω 0603 (Modifier-LED-Series, je 1× pro LED, dimensioniert für Vf≈2.1 V @ 5 mA @ +5 V Rail: (5-2.1)/5mA = 580 Ω, aber PCA9685-Output sinkt nach +5V → wir nutzen den IC als open-drain Sink mit 5 V Pull-Up am LED-Anoden-Bein; 390 Ω für ~7.5 mA Peak)** | **5 NEU r7** |
| **R_LED11-R_LED15** | **390 Ω 0603 (Cell-HOLD-LED-Series, je 1× pro Cell-LED, identische Dimensionierung wie R_LED6-10)** | **5 NEU r10** |
| **R_OE** | **10 kΩ 0603 (PCA9685 /OE pull-up zu +3V3, default-disabled bis Firmware enabled)** | **1 NEU r7** |
| **R_BAT_DIV_TOP, R_BAT_DIV_BOT** (r12) | **2× 100 kΩ 0603 (Battery-Voltage-Spannungsteiler 2:1 für GP26/ADC0). VBAT 0..4.2 V → 0..2.1 V am ADC. Drain ~21 µA continuous — irrelevant vs. 2000 mAh.** | **2 NEU r12** |
| **C_BAT_FILT** (r12) | **10 nF X7R 0603 (ADC-Filter am GP26, S/H-Spike-Glättung)** | **1 NEU r12** |
| **R_VBUS_SENSE** (r12) | **10 kΩ 0603 (Series VBUS → MCP-GPA7, ESD-Limit)** | **1 NEU r12** |
| **R_VBUS_PD** (r12) | **100 kΩ 0603 (Pull-Down GPA7 → GND, sichert LOW bei Battery-Mode)** | **1 NEU r12** |
| R_VOL_L/R | 10 kΩ 0603 (PAM8403 input series) | 2 |
| C_BULK | 1000 µF Alu-Elko SMD | 1 |
| C1, C3, C7a, C8a, **C6b**, **C9** | 10 µF X5R 0805 | **6 (war 3)** |
| C2, C4, C5, C6, C7b, C8b, **C6c**, C9b | 100 nF X7R 0603 | **8 (war 6)** |
| C5b | 10 nF X7R 0603 (MCP23017 HF) | 1 |
| **C_PCA_VDD** | **10 µF X5R 0805 (PCA9685 VDD, Pin 28, +3V3)** | **1 NEU r7** |
| **C_PCA_VDD_HF** | **100 nF X7R 0603 (PCA9685 VDD HF)** | **1 NEU r7** |
| **C10-C17** | **100 nF X7R 0603 (Encoder A/B debounce)** | **8 (Wert 10nF → 100nF)** |
| C_in_L/R | 1 µF X7R 0603 (PAM8403 input DC-block) | 2 |
| F1 | **Polyfuse 3.0A hold / 6.0A trip 1812 (Littelfuse 1812L300, C18198349)** | 1 |
| **FB1** | **Ferrit-Bead BLM18AG601 0603 (600Ω@100MHz)** | **1 NEU** |
| D1 | USBLC6-2SC6 ESD (USB-C D+/D−) | 1 |
| **D2** | **SMAJ5.0A TVS auf +5V am Pi-Header** | **1 NEU** |
| LED1 | Status LED 0805 warm white | 1 |
| **LED6-LED10** (r10) | **SMD 0603 Modifier-Status-LEDs, warm-weiß XL-1608UWC-04 (C965808 Extended). Vf≈3.0 V @ 5 mA. Position: über jedem Modifier-Switch (Y=60). PCA9685 LED0-LED4** | **5 NEU r10** |
| **LED11-LED15** (r10) | **SMD 0603 Cell-HOLD-Status-LEDs, identisch zu LED6-LED10 (XL-1608UWC-04 C965808). Position: über jeder Cell (Y=88) zwischen Cell-Cap-Top und OLED-Bottom. PCA9685 LED5-LED9** | **5 NEU r10** |

**Total: ~95 SMT-Komponenten** (r7: +9, r9-Battery: +14, r10: +15 (10 LEDs + 5 R), r12: +5 (1 R_LED_STATUS + 2 R_BAT_DIV + 1 C_BAT_FILT + 1 R_VBUS_SENSE + 1 R_VBUS_PD − 1 R19) net +5) + OLED, 5× Choc V2 Hot-Swap-Sockets (Cells), 5× Stabilizer, 5× 12×12×7.3 plain SMD-Tactile (HX 12x12x7.3TPFT-B, JLC-assembled), **+ BAT1 LiPo 2000 mAh user-supplied (r18.21/r19.18)**. **r12: GP26 ADC0 frei für BAT_SENSE, STATUS_LED auf PCA9685 LED10, USB-VBUS-Detect via MCP GPA7 — Battery-Mode-Logik vollständig hardware-instrumentiert.**

---

## 5. STM32H743 Pin Allocation v0.7-r18 (LQFP100, Datasheet DS12110 Rev 5 — Tabelle 8 verifiziert)

**Verifikations-Stand:** Alle Pin-Nummern und Alternate Functions sind gegen
die offizielle ST-Pin-Definitionstabelle (DS12110 Rev 5, Table 8) gegengeprüft.
Eine erste Version dieser Sektion enthielt Off-by-N-Fehler (SAI1-Pins, SPI1-
Pins, USB-OTG-Pins, PA15-Position) und einen Pin-76-Doppelbelegungs-Konflikt
(PA14 vs. fälschliches „PD5 = Pin 76") — alle in r18.1 korrigiert. Die finale
Verifikation gegen die Datasheet-Alternate-Function-Matrix (DS12110 Table 12)
für jede AF-Nummer passiert in Phase 3 (KiCad-Symbol-Eingabe).

**Pin-Reserve:** LQFP100 hat **82 GPIOs** (Datasheet S. 18) plus dedicated
NRST/BOOT0/HSE-Pins. Wir belegen **30 GPIOs** für die Engine — also ~50 GPIO-Pins
ungenutzt für Rev-B-Erweiterungen (Touch-Display, USB-MIDI-IN, weitere Encoder,
DFU-Button etc.).

### 5.1 Audio (SAI1 Block A — Master Mode, I²S Format)

| Pin | Port | AF | Funktion | Net |
|---|---|---|---|---|
| 3 | PE4 | SAI1_FS_A (AF6) | I²S Frame-Sync = LRCK → PCM5102A pin 15 | I2S_LRCK |
| 4 | PE5 | SAI1_SCK_A (AF6) | I²S Bit-Clock = BCK → PCM5102A pin 13 | I2S_BCK |
| 5 | PE6 | SAI1_SD_A (AF6) | I²S Serial-Data DOUT → PCM5102A pin 14 | I2S_DOUT |
| (1) | (PE2) | SAI1_MCLK_A (AF6) | nicht verbunden — PCM5102A braucht kein externes MCLK | — |

SAI1-DMA: SAI1_A nutzt DMA1 oder DMA2 (in Phase 4 finalisiert), Memory→Peripheral,
32-bit-Word, circular Mode für Ping-Pong-Buffering. Halb-Block-IRQ liefert je
**512 Frames** (r18.11, war 256); Engine rendert in den jeweils anderen Halb-Buffer.
PE2 (Pin 1) wird nicht beschaltet, da PCM5102A im 3-wire-Mode arbeitet
(BCK, LRCK, DIN — kein MCLK).

**SAI-Clock-Architektur (r18.11, ADR-0010):** SAI1 wird von **PLL2-Q oder PLL3-P**
gespeist, **nicht** von SYSCLK. Begründung: SYSCLK-PLL trägt CPU-Last-Variation
(Cache-Refills, IRQ-Stalls) als Phase-Noise; gekoppelt auf den BCK-Clock zum
DAC = audible Jitter im Hochton. STM32H7 hat zwei dedicated Audio-PLLs, eine
davon (Vorschlag: PLL3-P) auf 11.2896 MHz = 44100 × 256 → Master-Clock-Quelle
für SAI; SAI-Divider erzeugt daraus BCK (2.8224 MHz) und LRCK (44.1 kHz).
Wird in Phase 4 (Firmware-Migration) implementiert; PLL3-Konfig im
NATIVE_PORT_PLAN dokumentiert.

**Audio-Layout-Constraints (r18.11, vor Phase 6 Layout):**
1. **PCM5102A AVDD/DVDD-Decoupling** (FB1 + C7a/b + C8a/b) muss **< 5 mm vom IC**
   sitzen, vorzugsweise im selben GND-Plane-Polygon
2. **Single-Star-GND-Punkt** zwischen Audio-Block und Digital-Block: PCM5102A-
   GND, PAM8403-PGND, Speaker-Return alle auf einen Mid-Layer-Polygon-Anker
   verbunden, kein direkter Pfad über Digital-GND
3. **Class-D-Output-Filter** (PAM8403 hat keinen on-chip-Filter, BTL-Output ist
   ~500 kHz PWM): kurze Leitung zum Speaker (max 50 mm) plus optional
   LC-Bead-Filter (BLM18AG601 in jeder Output-Leitung, AVX TPS-Klasse) → fängt
   die Trägerfrequenz vor dem Speaker ab und reduziert Quasi-Peak-EMI
4. **Bulk-Cap-Platzierung:** C_BULK (1000 µF) so platzieren, dass der Strompfad
   zum PAM8403-PVDD-Pin den kürzesten Polygon-Loop bildet (Class-D zieht
   ~2 A-Spitzen bei Bass-Transienten; das ist der Hauptkratzigkeits-Pfad,
   wenn die Bulk-Cap weit weg liegt)
5. **PCM5102A-LDOO-Cap** (interner 1.8-V-LDO-Output, Pin 18): 100 nF X7R 0603
   direkt am Pin (Cstability)

### 5.2 LCD (SPI1 + GPIO-Control)

| Pin | Port | AF | Funktion | Net |
|---|---|---|---|---|
| 29 | PA5 | SPI1_SCK (AF5) | SPI Clock → LCD pin 4 (SCL) | LCD_SCK |
| 31 | PA7 | SPI1_MOSI (AF5) | SPI Data → LCD pin 5 (SDA) | LCD_MOSI |
| 30 | PA6 | GPIO | LCD CSn (active LOW) | LCD_CS |
| 32 | PC4 | GPIO | LCD Data/Command-Select | LCD_DC |
| 33 | PC5 | GPIO | LCD Reset (active LOW) | LCD_RES |

SPI1-DMA: SPI1_TX nutzt DMA für 320×170-Framebuffer-Blits (4-bit-Grey =
27 KB pro Blit). Backlight-PWM kommt nicht direkt vom MCU, sondern via PCA9685
(siehe §7.2 LED12).

### 5.3 I²C-Bus (MCP23017 + PCA9685)

| Pin | Port | AF | Funktion | Net |
|---|---|---|---|---|
| 92 | PB6 | I2C1_SCL (AF4) | I²C Clock @ 400 kHz | I2C_SCL |
| 93 | PB7 | I2C1_SDA (AF4) | I²C Data | I2C_SDA |
| 7 | PC13 | GPIO + EXTI | MCP23017 INTA (Wake-on-Switch) | MCP_INT |

I²C-Pullups: 2× 4.7 kΩ extern zum +3V3 (PB6/PB7 sind in LQFP100 mit AF I2C1
verfügbar — verifiziert in DS12110 Table 8 Zeile Pin 92/93).

### 5.4 Encoders (4× ALPS EC11 — Quadrature via TIM_QEI)

| Pin | Port | AF | Funktion | Net |
|---|---|---|---|---|
| 22 | PA0 | TIM2_CH1 (AF1) | EN1 Drive A | DRIVE_A |
| 23 | PA1 | TIM2_CH2 (AF1) | EN1 Drive B | DRIVE_B |
| 97 | PE0 | GPIO + EXTI | EN1 Drive Switch | DRIVE_SW |
| 63 | PC6 | TIM3_CH1 (AF2) | EN2 Brightness A | BRIGHT_A |
| 64 | PC7 | TIM3_CH2 (AF2) | EN2 Brightness B | BRIGHT_B |
| 98 | PE1 | GPIO + EXTI | EN2 Brightness Switch | BRIGHT_SW |
| 59 | PD12 | TIM4_CH1 (AF2) | EN3 Display A | DISPLAY_A |
| 60 | PD13 | TIM4_CH2 (AF2) | EN3 Display B | DISPLAY_B |
| 2 | PE3 | GPIO + EXTI | EN3 Display Switch | DISPLAY_SW |
| 67 | PA8 | TIM1_CH1 (AF1) | EN4 Volume A | VOL_A |
| 68 | PA9 | TIM1_CH2 (AF1) | EN4 Volume B | VOL_B |
| — | — | — | EN4 Volume Switch (bleibt auf MCP-GPB5 wie r15) | VOL_SW |

**Hardware-QEI** statt Software-Polling: TIM1/2/3/4 zählen A/B-Quadratur in
Hardware, Firmware liest nur den 32-bit-Counter — kein Jitter, kein Verlust
bei schneller Drehung, halbiert die HAL-LOC. PC6/PC7 statt PA6/PA7 für TIM3,
um den Konflikt mit SPI1 (PA5/PA7 → LCD) zu vermeiden. EN4 (TIM1) nutzt PA8/PA9
— PA9 hat zusätzlich OTG_FS_VBUS als „additional function", aber Bus-Powered-
USB ohne VBUS-Sensing ist Standard (Datasheet S. 39 fußnote).

VOL_SW liegt auf MCP-GPB5 (_r18.5-Anm.: die r15-Behauptung stimmte mit dem
Schaltplan nicht — bis r17 lag VOL_SW real am Pico-GPIO und GPB5 war NC;
seit dem r18.5-Generator ist GPB5 tatsächlich VOL_SW_) — am H7 wäre ein
direkter MCU-Pin frei, aber der MCP-Sheet bleibt damit unverändert.

### 5.5 MIDI Out (USART2 — Hardware-UART statt PIO-Workaround)

| Pin | Port | AF | Funktion | Net |
|---|---|---|---|---|
| 86 | PD5 | USART2_TX (AF7) | MIDI-TX @ 31250 Baud → TRS Type A | MIDI_TX |

USART2_TX hat zwei Pin-Optionen im LQFP100: PA2 (Pin 24) ODER PD5 (Pin 86).
Wir wählen **PD5**, da PA2 frei bleiben soll als Reserve (zukünftig MIDI-RX
auf USART2_RX = PA3 oder PD6 möglich). 8N1 @ 31250 Baud, Standard-HAL-UART,
kein PIO-Workaround.

### 5.6 Amp-Control + Battery-Sense + Status

| Pin | Port | AF | Funktion | Net |
|---|---|---|---|---|
| 25 | PA3 | ADC1_INP15 (analog) | BAT_SENSE via 100k/100k-Teiler | BAT_SENSE |
| 53 | PB14 | GPIO | PAM8403 /SHDN (active LOW) | AMP_nSHDN |
| 54 | PB15 | GPIO | PAM8403 /MUTE (active LOW) | AMP_nMUTE |
| 55 | PD8 | GPIO | Status-LED (boot/heartbeat) | STATUS_LED |

PA3-Hinweis: zusätzliche function `ADC12_INP15` (nicht INP3 wie in r18.0
fälschlich) — Datasheet S. 60 Zeile Pin 25.

PB14/PB15-Hinweis: diese Pins haben als „additional function" auch OTG_HS_DM/DP
(High-Speed-USB mit externem ULPI-PHY). Wir nutzen NUR OTG-FS (PA11/PA12),
keinen externen ULPI-PHY — also sind PB14/PB15 frei als GPIO verwendbar
(Datasheet S. 67-68).

### 5.6a Cells — digitale I²C-Switches, echter Keyswitch, direkt gelötet (r18.75, ADR-0013 ABGELÖST)

> **r18.73 (User-Direktive 2026-06-30, HiChord-Batch-4+):** Die Cells wurden
> **digitale on/off-Switches am MCP23017** (Switch → I²C-GPIO-Expander → MCU),
> NICHT mehr Gateron-Magnetic + DRV5056A4-Hall am STM32-ADC.
>
> **r18.74 (User-UX-Korrektur 2026-07-01):** r18.73 hatte die Cells auf
> **dasselbe kleine THT-Tactile wie die Modifier** (HX B3F-4055) gesetzt — das
> machte die spielbaren Cells ununterscheidbar von simplen Modifier-Knöpfen und
> zerstörte das "Tastatur/Keyboard"-Spielgefühl. Cells bekamen einen echten
> Kailh-Choc-Keyswitch über Hot-Swap-Socket zurück — die "Plain Choc V2"-Option
> aus ADR-0013s eigener Vergleichstabelle.
>
> **r18.75 (User-Nachfrage "wie wird das gelötet?"):** der Hot-Swap-Socket aus
> r18.74 hatte **keine saubere Hersteller-/LCSC-Teilenummer** und hätte eine
> nicht offensichtliche Klein-SMD-Handlöttechnik gebraucht. **Fix:** Cells
> bleiben elektrisch digital (identische Netze/Pins/Pull-Up/IRQ), der Kailh-
> Choc-V1-Switch (**CPG135001D01**) wird jetzt **direkt auf die Platine
> gelötet** — 2 THT-Beinchen, gleiche Löttechnik wie jeder andere Button hier.
> Kein Socket mehr, dafür Switch fest verlötet (nicht mehr tauschbar).
> Footprint + 3D-STEP direkt von LCSC/EasyEDA für C400229 gezogen.

| Cell | Switch | MCP23017-Pin | Net |
|---|---|---|---|
| Cell 1 | SW1 | GPA0 (Pin 21) | CELL1_BTN |
| Cell 2 | SW2 | GPA1 (Pin 22) | CELL2_BTN |
| Cell 3 | SW3 | GPA2 (Pin 23) | CELL3_BTN |
| Cell 4 | SW4 | GPA3 (Pin 24) | CELL4_BTN |
| Cell 5 | SW5 | GPA4 (Pin 25) | CELL5_BTN |

Beschaltung pro Cell: ein Switch-Pin → MCP-GPIO (`CELLn_BTN`), anderer Pin → GND.
MCP-interner Pull-Up aktiv (idle = HIGH, gedrückt = LOW), IRQ-on-change über die
gemeinsame INTA-Leitung (`MCP_INT`). Bauteil: **Kailh Choc V1, CPG135001D01**
(rot/linear) — direkt gelötet, NICHT dasselbe Bauteil wie die Modifier SW6–SW10
(bewusster Unterschied); Footprint `field_ambience:SW_KailhChoc_CPG1350_THT_2P`,
direkt von LCSC/EasyEDA für **C400229** gezogen (`easyeda2kicad --full
--lcsc_id=C400229`), inkl. echtem 3D-STEP — verifizierte, reale Listung
(⚠ 0 Lagerbestand zum Prüfzeitpunkt, Nachbestellung üblich).

**Entfernt ggü. dem Hall-Stand:** 5× DRV5056A4 (J_CELL1–5), 5× R_CELL 1 kΩ,
5× C_CELL 10 nF. Die STM32-ADC-Pins **PC0/PC1/PA4/PB0/PB1 sind freigegeben**
(NC-Reserve, ADC12-fähig → Rev-B-Option für eine spätere analoge/expressive
Cell-Variante). Damit ist die SPEC-v0.6-§7-„10 Switches"-Topologie wieder
vollständig (5 Cells + 5 Modifier am Expander) — die Cells fühlen sich aber
bewusst wie echte Tasten an, nicht wie die Modifier-Knöpfe.

**Firmware-Hinweis:** `firmware-c-next/include/cells.h` + `src/cells.c`
(host-getestet) bleiben als Velocity-State-Machine bestehen; mit digitalen Cells
degradiert das auf on/off-Trigger (Voll-Press-Position). Echte Velocity/
Aftertouch braucht die Hall-Variante (ADR-0013, dort dokumentiert).

### 5.7 USB-OTG-FS (built-in, kein externer PHY)

| Pin | Port | AF | Funktion | Net |
|---|---|---|---|---|
| 70 | PA11 | OTG_FS_DM (AF10) | USB Data Minus | USB_DM |
| 71 | PA12 | OTG_FS_DP (AF10) | USB Data Plus | USB_DP |

Externe Beschaltung: USB-C-Buchse → USBLC6-2 ESD-Schutz (bleibt aus v0.6) →
direkt an PA11/PA12. Keine externen Serien-Widerstände nötig (H743 hat
interne USB-PHY mit eingebauten Pull-Ups/Pull-Downs für Speed-Negotiation).

### 5.8 Debug + Boot

| Pin | Port/Signal | Funktion | Net |
|---|---|---|---|
| 72 | PA13 (JTMS/SWDIO) | SWD Debug Data — Standard STM32 Belegung | SWDIO |
| 76 | PA14 (JTCK/SWCLK) | SWD Debug Clock | SWCLK |
| 89 | PB3 (JTDO/TRACESWO) | SWO Trace-Output (optional) | SWO |
| 94 | BOOT0 | dedicated, Pull-Down 10 kΩ → System-Boot-Loader nur via DFU/Reset-Hold | BOOT0 |
| 14 | NRST | dedicated, Pull-Up 10 kΩ + 100 nF Debounce-Cap | NRST |

SWD-Header J4 (3-Pin 1.27 mm, bestehend aus v0.6) wird auf PA13/PA14/GND
umverdrahtet (war bei Pico ein anderer Footprint). SWO auf PB3 ist optional —
PB3 ist in LQFP100 verfügbar (Pin 89) und hat keinen Konflikt mit anderen
Funktionen, da wir TIM2_CH2 auf PA1 statt PB3 mappen.

### 5.9 Clock-Source (HSE)

| Pin | Funktion | Wert |
|---|---|---|
| 12 | PH0-OSC_IN (HSE) | 8 MHz Crystal-Eingang |
| 13 | PH1-OSC_OUT (HSE) | 8 MHz Crystal-Ausgang |

HSE-Crystal: **ABRACON ABLS-8.000MHZ-B4-T** (HC-49/US SMD), 8 MHz, CL 18 pF,
ESR max **80 Ω** (Datasheet Drawing 450669 Rev AD). Load-Caps 2× 22 pF C0G/NP0
0603 als Startwert. PLL-Konfig: PLL_M=4 → 2 MHz PFD → PLL_N=480 → 960 MHz VCO
→ PLL_P=2 → SYSCLK 480 MHz.

**Gain-Margin-Hinweis (AN2867):** Mit ESR_max=80 Ω und C₀+CL=25 pF ist
gm_crit = 4 × 80 × (2π·8e6)² × (25e-12)² = 0.506 mA/V → Gain Margin =
1.5/0.506 = **2.97** im Worst-Case (ESR_max über vollen Temp-Bereich). Das
AN2867-Lehrbuch-Minimum von 5 gilt für Industrial/Automotive über -40…+85 °C;
für dieses Indoor-Audio-Gerät (15–30 °C, ESR_typ ~40–50 Ω) liegt der reale
Margin bei ~5–6. **Bewusst akzeptiert.** In Phase 5 ist der Crystal-Start am
realen PCB zu verifizieren.

**Load-Cap-Feinabstimmung (Phase 5):** 2× 22 pF ergeben mit ~5 pF Stray nur
~16 pF effektiv (< CL=18 pF → Quarz läuft minimal schnell, wenige ppm). Für
exakte 18 pF wären ~24–27 pF nötig. Da die echte Stray-Kapazität erst nach dem
Layout messbar ist: 22 pF als Startwert behalten, in Phase 5 gegen die
gemessene Frequenz nachjustieren (Load-Cap-Wert tauschen, beide C_HSE gleich).

HSI bewusst nicht als Primär-Clock — ±2 % Drift wäre für SAI/I²S-Sync
unbrauchbar (Tonhöhen-Drift hörbar bei Drone-Voices über Minuten).

### 5.10 Power-Supply-Pins (LQFP100)

| Pin | Signal | Anschluss |
|---|---|---|
| 6 | VBAT | mit +3V3 verbunden (kein RTC-Backup-Akku nötig) |
| 10, 26, 49, 74 | VSS (4×) | GND |
| 11, 27, 50, 75, 100 | VDD (5×) | +3V3 |
| 19 | VSSA | analoge GND (mit VSS verbunden, Single-Star-Point empfohlen) |
| 20 | VREF+ | mit VDDA verbunden |
| 21 | VDDA | +3V3 via Ferrit BLM18AG601 + 1 µF + 100 nF |
| 48 | VCAP1 | 2.2 µF X5R 0603 zu VSS (interner SMPS Bulk) |
| 73 | VCAP2 | 2.2 µF X5R 0603 zu VSS (interner SMPS Bulk) |

Decoupling: pro VDD-Pin (5 Stück) ein 22 µF X5R 0805 (C45783; r18.80: Wert-Text korrigiert) + ein 100 nF X7R 0603
Bulk-Cap, möglichst nah am Pin platziert. Ferrit-Bead BLM18AG601 (LCSC C84094)
in der VDDA-Versorgung zur Trennung Analog-Digital. Power-Sequenz: keine
explizite Reihenfolge nötig — H7 hat keinen VDDA-Sequencing-Constraint
(Datasheet S. 91), und das interne SMPS bringt VCAP1/VCAP2 selbst hoch.

### 5.11 Active-Low-Konvention + Pop-Suppression-Sequenz (unverändert)

PAM8403H /SHDN und /MUTE sind beide ACTIVE LOW. GPIO HIGH = Funktion AUS
(= enabled/un-muted), GPIO LOW = Funktion AKTIV (= shutdown/muted).
Hardware-Pull-Downs R_SHDN_PD und R_MUTE_PD (10 kΩ) ziehen beide LOW
während MCU-Boot → Amp ist default OFF + MUTED.

**Pop-Suppression-Sequenz (Firmware) — KORREKTE Reihenfolge (unverändert):**

- **Power-on**:
  1. Boot: PB14 (/SHDN) und PB15 (/MUTE) LOW (Pull-Downs) + MCP-GPA5 (PCM XSMT) LOW → alles stumm
  2. Warten ~50 ms bis +5V/+3V3 stabil
  3. PB14 (/SHDN) = HIGH → Chip wacht auf, interne Referenzen settlen
  4. ~50 ms später: PB15 (/MUTE) = HIGH + MCP-GPA5 (PCM XSMT) = HIGH → Audio frei
- **Power-off (umgekehrt)**:
  1. MCP-GPA5 (PCM XSMT) = LOW (DAC stumm)
  2. PB15 (/MUTE) = LOW (Amp-Output muted)
  3. ~50 ms später: PB14 (/SHDN) = LOW (Chip aus)
- Resultat: kein „Klick" beim An-/Ausschalten

### 5.12 Belegungs-Übersicht (alle ~30 belegten GPIOs in LQFP100)

| Pin-Bereich | Funktion |
|---|---|
| 3, 4, 5 | Audio I²S (SAI1) |
| 7, 92, 93 | I²C-Bus + Interrupt |
| 22, 23, 67, 68 | Encoder TIM-QEI (4 Pins für 2× Encoder) |
| 59, 60, 63, 64 | Encoder TIM-QEI (4 Pins für 2× Encoder) |
| 2, 97, 98 | Encoder-Switches (3, EN4 auf MCP) |
| 25 | ADC BAT_SENSE |
| 29, 30, 31, 32, 33 | LCD (SPI1 + 3 GPIOs) |
| 53, 54 | PAM8403 Amp-Control |
| 55 | Status-LED |
| 70, 71 | USB-OTG-FS |
| 72, 76 | SWD Debug |
| 86 | MIDI-TX |
| 89 | SWO Trace (optional) |
| 12, 13, 14, 94 | dedicated (HSE, NRST, BOOT0) |
| 6, 10, 11, 19, 20, 21, 26, 27, 48, 49, 50, 73, 74, 75, 100 | Power/GND/VCAP/VBAT/VDDA |

**Frei** (für zukünftige Erweiterungen, ohne PCB-Re-Spin): PE2, PA2, PA10,
PA15, PB2, PB4, PB5, PB8, PB9, PB10-PB13, PC2_C, PC3_C, PC8-PC12,
PD0-PD4, PD6, PD7, PD9-PD11, PD14, PD15, PE7-PE15 — über 35 freie GPIOs.

> r18.20 (Audit-Fix): PC0/PC1/PA4/PB0/PB1 aus der Frei-Liste entfernt — sie
> sind seit r18.9 für CELL1..5_SENSE (Hall-Velocity, §5.6a) vergeben.

---

---

## 6. Display ST7789 Konfiguration (1.9" 170×320 IPS-LCD) — r16

**r16: Panel-Wechsel SSD1322 256×64 OLED → 1.9" ST7789(V2) 320×170 IPS-LCD.**
Grund: Lesbarkeit, Outdoor-Helligkeit, ~3,3× Pixeldichte, glatte UI-Animation,
kein Burn-in. **Visuell bleibt es monochrom** (schwarz/weiß/grau, OP-1-Sprache);
die Firmware rendert das 4-bit-Grey-Framebuffer nur nach RGB565 um (Treiber
`firmware-c-next/src/lcd_st7789.c`). **Pins unverändert** — das LCD nutzt
dieselbe SPI0-Gruppe wie das alte OLED (kein GPIO-Reallocation).

### Controller-Setup (vom Treiber gefahren)

| Schritt | Command | Wert | Zweck |
|---|---|---|---|
| 1 | SWRESET (0x01) | — | Soft-Reset, 150 ms warten |
| 2 | SLPOUT (0x11) | — | Sleep aus, 120 ms warten |
| 3 | COLMOD (0x3A) | 0x55 | 16-bit/Pixel RGB565 |
| 4 | MADCTL (0x36) | 0x60 | Landscape (MX\|MV); ggf. 0xA0/0xC0 falls gespiegelt |
| 5 | INVON (0x21) | — | Display-Inversion (IPS-Panels invertiert) |
| 6 | NORON (0x13) | — | Normal-Modus |
| 7 | DISPON (0x29) | — | Display an |

**GRAM-Offset**: Die 170-px-Seite sitzt versetzt im 240×320-Controller-GRAM.
In Landscape ⇒ **Spalten (CASET) 0..319, Zeilen (RASET) 35..204 (Y-Offset 35)**.

### Pinout 8-pin SPI-Header

| Header Pin | Signal | Verbindung |
|---|---|---|
| 1 | GND | GND |
| 2 | VCC | +3V3 (Logic, 10 µF + 100 nF lokal — C6b/C6c) |
| 3 | SCL (SCLK) | OLED_SCK (Pico GP6) |
| 4 | SDA (MOSI) | OLED_MOSI (Pico GP7) |
| 5 | RES | OLED_RES (Pico GP9) |
| 6 | DC | OLED_DC (Pico GP8) |
| 7 | CS | OLED_CS (Pico GP5) |
| 8 | BLK (Backlight) | PCA9685-PWM-Kanal über N-FET (Low-Side) — Helligkeit per I²C |

**Backlight**: Alle 24 Pico-GPIOs sind belegt (§5), daher fährt BLK über einen
freien **PCA9685-PWM-Kanal** + kleinen N-FET (z. B. 2N7002, SOT-23) als
Low-Side-Switch. Helligkeit damit per I²C.
~~Die Net-Namen `OLED_*` in §5 sind aus Kompatibilität beibehalten~~ —
**r18.5: Schematic-Netnamen sind jetzt `LCD_*`** (gemäß §5.2; die alte
OLED_*-Benennung existiert nur noch in `kicad/legacy_pico2/`).

> **r17-Klarstellung (EN2-Konflikt aufgelöst):** Der **Brightness-Encoder EN2
> regelt im Normalbetrieb die AUDIO-Tonfarbe** (Pad-Filter-Cutoff,
> Sound-Constitution `/fam/brightness`), **nicht** das Display-Backlight. Die
> **LCD-Helligkeit liegt auf der Sekundärfunktion SHIFT+EN2** (§12.3) und wird
> als transientes Overlay angezeigt — wie Volume/Drive, **kein** Menü-Eintrag.
> Frühere Formulierungen, die EN2 direkt mit der Display-Helligkeit
> gleichsetzten, waren falsch und sind hiermit korrigiert.

---

## 7. MCP23017 Konfiguration

[Fix H3: INTA Pull-Up explizit]

Adresse: A0=A1=A2=GND → **0x20**

**Interrupt-Konfiguration:**
- INTA aktiv low, **MIRROR=1** im IOCON-Register (Firmware-Setup) → INTA covers GPB-changes
- INTB ist NC
- **R20 = 10 kΩ Pull-Up auf INTA zu +3V3** (sonst floatet open-drain-Output beim Reset)

Pin-Verteilung (Update v0.6.3-r5: GPA5 für XSMT-Control):

| MCP Pin | Net | Funktion |
|---|---|---|
| GPA0-4 | CELL1-5 | Cell-Switches SW1-5 |
| **GPA5** | **PCM_XSMT** | **PCM5102A Soft-Mute Control (v0.6.3-r5 N1)** |
| **GPA6** | **JACK_DETECT** | **Line-Out-Buchse J8 Insertion-Detect (v0.7)** |
| **GPA7** | **USB_VBUS_SENSE** | **USB-C VBUS-Detect (NEU r12, war Reserve). HIGH wenn USB-C verbunden, LOW wenn battery-only. Firmware nutzt für Battery-Mode-Volume-Clamp (r9-B7). Schaltung: 10 kΩ Series von VBUS → GPA7 + 100 kΩ Pull-Down → GND. MCP-I/O 5.5 V-tolerant per Datasheet → V_GPA7 ≈ 4.55 V bei VBUS=5V, 0 V bei Battery-Mode. ~45 µA Drain wenn USB-C verbunden (irrelevant, lädt parallel).** |
| GPB0 | MOD_SHIFT | Modifier-Switch SW6 (momentary, Press-Event) |
| GPB1 | MOD_HOLD | SW7 (momentary, Press = Toggle-Event) |
| GPB2 | MOD_DRONE | SW8 (momentary, Press = Toggle-Event) |
| GPB3 | MOD_GENERATE | SW9 (momentary, Press = Toggle-Event) |
| GPB4 | MOD_CLEAR | SW10 (momentary, One-Shot-Event) |
| **GPB5** | **VOL_SW** | **EN4 (Volume) Push-Switch (r15: verlagert von Pico GP21, der für MIDI_TX frei wurde). Mensch-Buttondruck >50 ms, MCP-IRQ-Latenz <5 ms → musikalisch ununterscheidbar von Direktanschluss.** |
| GPB6, GPB7 | reserve | frei für zukünftige Switches/Sensoren |

Alle 10 Switches: ein Pin → MCP-GPIO, anderer → GND. Interne Pull-Ups via
GPPU-Register aktiviert (Firmware).

**WICHTIG r7**: SW6-SW10 sind **momentary** (federn zurück), nicht latching.
Der UI-Zustand HOLD/DRONE/GENERATE/SHIFT-aktiv/CLEAR-confirmation lebt **in
der Firmware**, sichtbar via die zugehörigen LEDs (PCA9685, siehe §7.2). Das
ermöglicht Preset-State-Recall (Snapshot setzt Firmware-Var → PCA9685-Kanal
geht passend an/aus) ohne physisch widersprechenden Switch.

**Update r10**: SW6-SW10 sind ab r10 **plain 4-pin SMD-Tactile** (KEINE
integrierte LED mehr). Status-Anzeige läuft über separate SMD-0603-LEDs
über jedem Switch (siehe §7.2 + `mechanical_coordinates.md` §5). Vorteile:
JLC-Standard-Footprint statt Custom (r7-B1 BLOCKER → downgraded zu r10-B8
Sourcing-Pass), full-JLC-Assembly möglich, kleinere/cleanere LED-Optik.

---

## 7.2. PCA9685 LED-Driver Konfiguration (NEU r7)

I²C-Adresse: A0..A5 = GND → **0x40** (Default). Liegt am selben I²C1-Bus wie
MCP23017 (0x20) und OLED — Konflikt-frei.

**Decoupling**: C_PCA_VDD (10 µF) + C_PCA_VDD_HF (100 nF) lokal an Pin 28
(VDD, +3V3).

**/OE (Output Enable, Pin 23, active LOW)**: über R_OE = 10 kΩ Pull-Up an
+3V3. Default = HIGH = LEDs disabled. Firmware zieht /OE LOW erst nachdem
PWM-Register initialisiert sind (kein Aufblitzen beim Boot).

**EXTCLK (Pin 25)**: **MUSS auf GND gezogen werden** (NXP Datasheet Rev 4 S.7
Footnote [2]: „This pin must be grounded when this feature is not used"). Wir
nutzen den internen 25 MHz Oszillator → Pin 25 fix an GND. **Korrektur 2026-05-31**:
frühere Spec-Fassungen sagten irrtümlich „NC" — wäre ein latenter Bug
(undefined HF-Pickup, kann Oszillator destabilisieren). Im KiCad-Schematic
muss Pin 25 explizit eine GND-Verbindung haben, nicht nur ein NC-Label.

**LED-Kanal-Belegung (r18.8 — IMG_9713-Stand, 5×2 Cell-LEDs XOR-Logik, ADR-0008):**

| PCA9685 LEDn | Funktion | LED-Ref | LED-Farbe | Anzeige-Logik |
|---|---|---|---|---|
| LED0 | Modifier SHIFT | LED6 | **Grün** | An wenn Shift-Latch aktiv (toggle, persistiert) |
| LED1 | Modifier HOLD | LED7 | **Gelb** | An wenn Hold-Modifier-Latch aktiv |
| LED2 | Modifier DRONE | LED8 | **Weiß** | An wenn Drone spielt, sanfter Fade |
| LED3 | Modifier GENERATE | LED9 | **Weiß** | An wenn Generative-Mode aktiv |
| LED4 | Modifier CLEAR | LED10 | **Weiß** | Flash-on-press 200 ms, kein Latch |
| LED5 | Cell-1 Hold @ Basis | LED11Y | **Gelb** | An wenn Cell-1 = HOLD_BASE |
| LED6 | Cell-1 Hold @ Shift | LED11G | **Grün** | An wenn Cell-1 = HOLD_SHIFT (XOR mit LED5) |
| LED7 | Cell-2 Hold @ Basis | LED12Y | **Gelb** | An wenn Cell-2 = HOLD_BASE |
| LED8 | Cell-2 Hold @ Shift | LED12G | **Grün** | An wenn Cell-2 = HOLD_SHIFT (XOR mit LED7) |
| LED9 | Cell-3 Hold @ Basis | LED13Y | **Gelb** | An wenn Cell-3 = HOLD_BASE |
| LED10 | Cell-3 Hold @ Shift | LED13G | **Grün** | An wenn Cell-3 = HOLD_SHIFT (XOR mit LED9) |
| LED11 | Cell-4 Hold @ Basis | LED14Y | **Gelb** | An wenn Cell-4 = HOLD_BASE |
| LED12 | Cell-4 Hold @ Shift | LED14G | **Grün** | An wenn Cell-4 = HOLD_SHIFT (XOR mit LED11) |
| LED13 | Cell-5 Hold @ Basis | LED15Y | **Gelb** | An wenn Cell-5 = HOLD_BASE |
| LED14 | Cell-5 Hold @ Shift | LED15G | **Grün** | An wenn Cell-5 = HOLD_SHIFT (XOR mit LED13) |
| LED15 | **LCD_BLK_PWM** | (via Q2 N-FET) | n/a | PCA-PWM steuert Backlight-Helligkeit |

**Budget: 16/16 PCA-Kanäle belegt, exakt.** Kein Status-LED-Reserve mehr —
System-Status (Heartbeat/Battery-Low) wandert auf MCU-Direkt-GPIO (PD8 per
SPEC §5.6), das ist der STATUS_LED-Pin am STM32H743. Damit ist die r12-Lösung
„System-LED via PCA10" obsolet.

**XOR-Logik (ADR-0008):** Pro Cell ist immer höchstens **eine** LED an —
entweder Gelb (Cell-Hold @ Basis-Oktave) oder Grün (Cell-Hold @ Shift-Oktave).
Niemals beide. Firmware-State-Machine hält pro Cell ein 3-Werte-Enum
{OFF, HOLD_BASE, HOLD_SHIFT} und gibt das an die PCA9685-Treiber.

**LED-Bauform-Änderung (r10)**: alle 10 Anzeige-LEDs sind **SMD 0603**, NICHT
mehr THT 3 mm und NICHT mehr im Switch-Body integriert. Position: über jedem
Switch-Body. Modifier-LEDs (LED6-LED10) bei Y=60 (über jedem Modifier bei Y=50),
Cell-HOLD-LEDs (LED11-LED15) bei Y=88 (in der 9 mm-Lücke zwischen Cell-Cap-Top
Y=84 und OLED-Modul-Bottom Y=93). Siehe `mechanical_coordinates.md` §4a + §5.

**Schaltung pro LED-Kanal** (open-drain Sink-Konfiguration):
- LED-Anode → R_LEDn (390 Ω 0603) → **+5 V**
- LED-Kathode → PCA9685 LEDn-Pin
- PCA9685 zieht Kathode LOW (~0.5 V) → I_LED = (5 - 2.1 - 0.5) / 390 = ~6.2 mA
- Max-Rating PCA9685: 25 mA pro Pin sink → großzügige Reserve

**Begründung +5V statt +3V3 als LED-Versorgung**: bei Vf ≈ 2.1 V (warm-weiß /
amber) würde +3V3 nur ~1.2 V Headroom lassen → Helligkeit empfindlich
gegenüber Rail-Sag. +5 V gibt ~2.4 V Headroom, viel stabiler. PCA9685-Outputs
sind 5.5 V-tolerant (Datasheet S. 8, V_OL bei externer Pull-Up-Last).

**PWM-Frequenz**: 1.0 kHz (Firmware) — flackerfrei für Auge, kein hörbares
Coil-Whistle bei den 0603-Widerständen.

---

## 8. Audio Path v0.6

[Fix M2: AVDD/DVDD getrennt + FB1; Fix C2: SHUTDOWN/MUTE-GPIOs zu Pico]

### PCM5102A I²S zu Pi Zero 2 W

| Pi Zero 2 W GPIO | Pi Header Pin | PCM5102A Pin | Funktion |
|---|---|---|---|
| GPIO18 (PCM_CLK) | 12 | BCK (pin 13) | Bit clock — v0.6.3-r3 mit R_BCK 33Ω series |
| GPIO19 (PCM_FS)  | 35 | LRCK (pin 15) | Left/Right select — mit R_LRCK 33Ω series |
| GPIO21 (PCM_DOUT)| 40 | DIN (pin 14) | Data in — mit R_DOUT 33Ω series |

PCM5102A im **3-wire mode**: SCK pin → GND. FMT pin → GND (I²S Format).

**Power-Routing PCM5102A** (Pin-Nummern per TI Datasheet SLAS859C):
- DVDD (Pin 20) ← +3V3 → C8a 10 µF + C8b 100 nF lokal
- **FB1** zwischen DVDD-Plane und AVDD-Plane (v0.6 M2 split)
- AVDD (Pin 8) ← +3V3 via FB1 → C7a 10 µF + C7b 100 nF lokal
- CPVDD (Pin 1) ← +3V3 → C_CPVDD_BULK + _HF
- CAPP/CAPM (Pin 2/4) charge-pump fly cap 1µF
- VNEG (Pin 5) 1µF reservoir
- VCOM ist KEIN Pin auf PCM5102A (alte v0.6-Anmerkung war falsch)
- LDOO (Pin 18) optional 100nF Stability-Cap

Output: VOUTL (Pin 6) / VOUTR (Pin 7) ground-centered, ~1.65V DC-Bias, **2.1 Vrms full-scale**.

**Kein externer Output-Filter-Cap**: Der PCM5102A hat einen internen Interpolations-
/Rekonstruktions-Filter; TI-Referenz nutzt keinen Cap-to-GND am Output. Der frühere
BOM-Eintrag `C_audio_filt` (2× 220nF) wurde daher gestrichen (war nie im Schaltplan
platziert). Outputs gehen direkt an PAM8403-IN (via C_in DC-Block) und an den
Line-Out (R_LO Serien-R) — beides ohne Shunt-Filter-Cap.

### Audio-Gain-Strategy (NEU in v0.6.3-r3)

**Problem**: PCM5102A 2.1 Vrms full-scale × PAM8403H 24 dB gain (15.85x) →
33 Vrms gewollt, Amp clipt heftig bei 5V Supply (max ~1.77 Vrms BTL out).

PAM8403H Datasheet (Diodes Inc DS31295) warnt explizit: "Large signal can
cause the clipping of output signal when increasing the volume. This will
damage the device because of the big gain of the PAM8403H."

**v0.6.3-r3 Lösung**: Kombination Hardware + Firmware:
1. **Hardware**: R_VOL_L/R = 20 kΩ (NICHT 10k wie alte v0.6) — das ist RI
   per PAM8403H-Datasheet (RImin=18kΩ). AVD = 2·142k/20k = **23 dB** = 14x
2. **Firmware muss garantieren**: PCM5102A Output ≤ **126 mV Vrms** =
   1.77V/14 (= -24 dB / 6% von full-scale digital)
3. SuperCollider-Master-Volume auf ≤ 0.06 clampen, ALSA mixer-volume
   entsprechend setzen

**Future-Hardware-Option**: External Voltage-Divider zwischen PCM und
PAM-IN: z.B. R_a 18kΩ series + R_b 1kΩ shunt to GND → 18.9x Attenuation.
Erlaubt firmware-side dB-Range +24 dB.

### PAM8403H Connection (per Datasheet DS31295, korrigiert v0.6.2)

PAM8403H Stereo Class-D, 2×3W @ 4Ω.

| Pin | Funktion | Verbindung |
|---|---|---|
| 1 | -OUT_L | Speaker L negative |
| 2 | PGND | GND |
| 3 | +OUT_L | Speaker L positive |
| 4 | PVDD | +5V **(PVDD-L: lokal C9 22µF + C9b 1µF, gemeinsam mit VDD pin 6)** |
| 5 | /MUTE | Pico GP28 (AMP_nMUTE) **+ R_MUTE_PD 10k pull-down** |
| 6 | VDD | +5V **(C9 22µF + C9b 1µF lokal — PAM8403H Datasheet: 1µF HF + ≥20µF bulk)** |
| 7 | INL | PCM5102A OUTL via C_in_L 1µF + R_VOL_L **20kΩ** (RI, gain 23 dB) |
| 8 | VREF | **C_VREF 1µF X7R zu GND (Datasheet REQUIRED, reduziert Pop)** |
| 9 | NC | NC label |
| 10 | INR | PCM5102A OUTR via C_in_R 1µF + R_VOL_R **20kΩ** |
| 11 | GND | Analog GND |
| 12 | /SHDN | Pico GP27 (AMP_nSHDN) **+ R_SHDN_PD 10k pull-down** |
| 13 | PVDD | +5V **(PVDD-R: lokal C_PVDDR 22µF + C_PVDDR_HF 1µF)** |
| 14 | +OUT_R | Speaker R positive |
| 15 | PGND | GND |
| 16 | -OUT_R | Speaker R negative |

**Power-Sequencing (Firmware bei Pico-Boot) — KORREKTE Reihenfolge:**

Chip ZUERST aufwecken (/SHDN HIGH), DANN un-muten (/MUTE HIGH). NICHT
umgekehrt — beim /SHDN-HIGH-Übergang würde ein bereits un-muteter Chip
sofort Audio durchlassen → Pop.

1. Boot: /SHDN=LOW, /MUTE=LOW (Pull-Downs), PCM XSMT=LOW → alles stumm
2. Warten bis +5V-Rail stabil (~50 ms)
3. **/SHDN=HIGH** (GP27) — Chip wacht auf, Referenzen settlen, Output bleibt via /MUTE=LOW stumm
4. ~50 ms später: **/MUTE=HIGH** (GP28) + **PCM XSMT=HIGH** (MCP GPA5) → Audio frei

**Power-off (umgekehrt):**
1. PCM XSMT=LOW (DAC stumm)
2. /MUTE=LOW (Amp-Output muted)
3. ~50 ms später /SHDN=LOW (Chip aus)

Verhindert „Klick"-Geräusch beim An- und Ausschalten.

### Speakers (r14 Acoustic-v2 — Sealed + Top-Firing, 2026-06-02)

2× **Same Sky (CUI) CMS-402811-28SP** (r18.18-Wechsel von PUI weg —
Stoff-Membran statt behandeltem Papier; identischer Footprint, halber Preis):
**40 × 28.3 × 11.5 mm** rechteckiger Rahmen, **8 Ω**, 2 W RMS / 3 W max,
**Stoff-Konus (Cloth Cone)**, NdFeB-Neodym-Magnet, **F0 = 450 Hz**,
84 ± 3 dB @ 1 W/50 cm, **Löt-Eyelets — keine Kabel ab Werk** → Hand-Assembly,
kein JLC-Bestücken. DigiKey-Stock-OK + Arrow + Mouser.
Quelle: [Same Sky CMS-402811-28SP Datenblatt](https://www.sameskydevices.com/product/resource/cms-402811-28sp.pdf).

**Zweitquelle (dokumentiert):** PUI Audio **AS04008PS-4W-WR-R** — identischer
40 × 28.3 × 11.5-Footprint, 8 Ω, 2 W, Löt-Eyelets, F0 = 380 Hz (etwas
mehr Tiefgang), aber **behandeltes Papier statt Stoff** → akustisch boxiger
in den unteren Mitten + feuchteanfälliger. Stoff-Variante CMS bevorzugt.

**Warum der Wechsel (r18.18):** Drei Datenblatt-Quellen bestätigen: PUI-Konus
ist „treated paper" — eine Papier-Pulpe-Membran mit Wasserschutz-Beschichtung.
Cloth-Cone ist eine spürbar bessere Membran-Klasse: niedrigere innere
Verluste, glattere Mitten ohne „Papier-Boxigkeit", besser feucht-/
schweißbeständig. Trade-Off ist 70 Hz höhere F0 — in einer 15–30 cm³ Sealed-
Box mit F-Rolloff ohnehin bei ~500 Hz nicht hörbar. Cloth-Mitten-Klarheit
gewinnt deutlich. Bonus: ~$3–5 statt ~$6.78 pro Treiber.

**Dust-Mesh-Cover (ADR-0007):** Saati Acoustex 020–032 (transparent, ~25–32
g/m²), PSA-Klebering-Konvertierung via Marian Inc. für Serie; AliExpress-
Klebe-Mesh für Prototyp. Ovaler Frontpanel-Cutout 36 × 24 mm (passt zum
40×28.3-Treiber, 2 mm Rim-Seat).

**Mechanik-Hinweis (11.5 mm Tiefe):** Gehäuse-Außenhöhe 21.6 mm (war 19.6) —
der von der Top-Platte hängende Treiber braucht 12 mm Above-PCB-Raum + 42×32-
Bauteil-Keepout je Treiber-Footprint. Details `../mechanical/coordinates/mechanical_coordinates.md` §2/§7.
**Mechanik unverändert beim Wechsel** — der CMS-Treiber hat identische
Außenmaße + Tiefe + Eyelet-Position.

**Akustik-Konzept: Sealed Box + Top-Firing (kein Bass-Reflex, kein Passivradiator)**

| Element | Wert | Begründung |
|---|---|---|
| Kammer | **Geschlossen pro Kanal**, Trennsteg L/R im Bottom-Case-Inlay | Einzige sinnvolle Kammerform für einen Treiber mit F0=450 Hz (CMS, r18.18; auch bei der 380-Hz-Zweitquelle PUI gültig). Reflex-Systeme (Port oder PR) lassen sich physikalisch nicht unter F0 abstimmen — eine PR mit Fb≈400 Hz würde nur eine Resonanzspitze in den unteren Mitten machen, schlimmster Fehlerfall für Drone/Sustain-Audio (One-Note-Boom). Sealed = saubere monotonische Roll-Off, kein Dröhnen. |
| Treiber-Ausrichtung | **Top-Firing in der Top-Plate**, nicht down-firing | Down-firing nutzt nur Boundary-Coupled-Bass — den dieser Treiber nicht erzeugt (F0=450 Hz). Top-firing maximiert die *einzige* echte Stärke (Mitten/Höhen-Klarheit) durch direkten Schallweg zum Ohr, ohne Tisch-Reflexion und Kammfilter. |
| Mount | Speaker-Rahmen von unten gegen die Top-Plate, 4× M2 | PCB-Speaker-Cutouts (alt: 41 mm dia bei Y=30) **entfallen** — Treiber sitzen nicht mehr im PCB. Akustik-Kammer wird durch Top-Plate + Bottom-Case + Trennsteg gebildet. |
| Top-Plate-Grille | 2× **ovale Dust-Mesh-Aussparung 50 × 30 mm** bei **(28, 50)** und **(224, 50)** (r18.16-Mechanik-Koordinaten), schwarzes Akustik-Mesh statt Lochmuster (ADR-0007) | Schallaustritt direkt nach oben. Cutout-Höhe < Treiber-Außenmaß (40 mm) damit die Membran am Rand abgedeckt bleibt; Mesh schließt die Öffnung staubdicht + akustisch transparent. |

**Realistische akustische Erwartung** (CMS-Cloth-Konus, r18.18):

- Onboard ehrlich nutzbar etwa **250 Hz – 20 kHz** (F0=450 Hz, nutzbar etwa
  −10 dB unter F0; war ~200 Hz mit der PUI-Papier-Zweitquelle bei F0=380 Hz).
- Was klingt: **glattere Mitten** als beim Papier-Treiber (kein
  Papier-Boxig-Klang im Sprach-Bereich), präsente Höhen, Pad-Saws fett und
  transparent, Reverb-Fahnen sauber.
- Was *nicht* klingt: alles unter ~250 Hz. famSubBass (LP90) und der untere
  Teil von famDeepBass (HP50/LP350) sind **onboard schlicht nicht hörbar** —
  sie sind direkter Beitrag null. Indirekt sind sie über den Reverb-Send
  (`verbSend 0.03` bzw. `0.08`) als Wärme der Fahne präsent, aber das ist
  alles. Voller Tiefgang ausschließlich über **Line-Out J8** → externe Boxen.

Ein sanfter DSP-Low-Shelf bei ~450 Hz kann später optional die wahrgenommene
Wärme im Treiber-Eigenbereich anheben (Firmware-seitig, Engine-Step 11/Master
oder Engine-Step 8/Bass). Echten Bass *erzeugt* DSP nicht — der Treiber hat
schlicht keinen Hub unter ~250 Hz.

**Mechanik-Konsequenzen** (siehe `../mechanical/coordinates/mechanical_coordinates.md`
§3.4/§5/§7, r18.16-Stand):
- PCB-Speaker-Cutouts entfallen (mehr nutzbare PCB-Fläche im unteren Streifen)
- Top-Plate bekommt 2× ovale Dust-Mesh-Aussparung 50 × 30 mm bei (28, 50) /
  (224, 50) (r18.16-Koordinaten, neuer 252×102-Outline — die alten
  (50,30)/(270,30) galten für den 333×143-Outline und sind retired)
- PCB-seitige Speaker-Treiber-Zone hat Höhen-Limit 4 mm (Treiber hängt 5 mm
  vom Top-Panel; siehe mechanical §7) — L1-Boost-Inductor + JST-PH dort verboten
- Bottom-Case wird zur reinen Kammer-Rückwand, kein Speaker-Mount mehr,
  keine Port-Ausschnitte, kein Grille-Pattern

**Verlauf der akustischen Entscheidungen**:
- *v0.6 (initial)*: 2× Bass-Reflex-Port 8×25 mm hinten, ~80 Hz Tuning,
  down-firing. Falsch weil Port-Länge nicht ins Gehäuse passt UND Port-
  Chuffing bei Drone/Sustain.
- *r13 (2026-06-01)*: Sealed-Box + Top-Plate-Passivradiator als Verbesserung.
  Falsch weil PR ein Reflex-System ist, das genauso wenig unter F0=380 Hz
  abgestimmt werden kann wie ein Port — der Grundirrtum (man könne diesen
  Treiber zum Bass-Treiber machen) war beim Wechsel von Port → PR mit
  übergegangen.
- *r14 (2026-06-02)*: Sealed + Top-Firing. Ehrliche Akustik: der Treiber
  spielt das, was sein Datenblatt erlaubt (Mitten + Höhen), und maximiert
  diesen Bereich. Bass-Layer ist offiziell Line-Out-Zone.

### Bass-Reflex/Passivradiator — beide ENTFERNT
F0=380 Hz schließt jede Reflex-Lösung (Port oder PR) aus. Geschlossene Kammer
ist die einzige korrekte Lösung für diesen Treiber.

### Phones / Line-Out (J8 + U11, r19.19 — ADR-0024)

PCM5102A VOUTL/R → C_HP_IN 1 µF → **U11 TPA6132A2** (DirectPath, Gain −6 dB)
→ 22 Ω → J8. Kopfhoerer (16 Ω+) UND Line-Eingaenge werden niederohmig und
in-Spec getrieben; der tiefe Charakter ist ueber beides voll hoerbar.

| Element | Wert |
|---|---|
| J8 | 3.5mm TRS-Buchse mit Insertion-Detect-Switch (PJ-320D, LCSC C431535) — **Gehaeuse-Label: PHONES / LINE OUT** |
| U11 | TPA6132A2RTER (C69901): Gain −6 dB via G0=G1=GND, EN=AMP_nSHDN, Pop-Suppression, Kurzschluss-Schutz, Shutdown 0,7–1,2 µA |
| C_HP_INL/R | 1 µF Eingangskopplung (fc < 15 Hz); INL+/INR+ an GND (SE-Betrieb per DS) |
| C_FLY_HP / C_HPVSS / C_HPVDD / C_HP_VDD | 1 µF / 1 µF / 2,2 µF / 2,2 µF (TI SLOS597B §8.2/§9; HPVDD NIE an VDD) |
| R_LO_L / R_LO_R | 22Ω 0603 Serien hinter U11 (Kabel-Entkopplung/ESD) |
| Jack-Detect | J8 DET-Switch → MCP23017 GPA6 (Pull-Up + IRQ). Idle=LOW, Plug=HIGH |

**Jack-Detect-Verhalten**: Plug einstecken → Firmware mutet NUR den PAM8403
(Speaker) via AMP_nMUTE; U11 bleibt an → Kopfhoerer/Line live. Ausstecken →
Speaker wieder an. U11 + U4 teilen sich AMP_nSHDN (beide aus im Boot/Aus).

**Historie**: bis r19.18 hing J8 passiv am DAC (Line-only; Kopfhoerer
ausserhalb der PCM5102A-Spec ≥1 kΩ). Die damals notierte v0.8-Option
TPA6132 ist mit r19.19 exakt so umgesetzt.

### MIDI Out (J10, r18.67 — implementiert; vorher fälschlich „J9" = Akku)

3.5-mm-TRS-Klinke, **MIDI 1.0 / MMA TRS Type A** (offizieller Standard seit
2018). Keine USB-MIDI, kein TinyUSB. User-Use-Case: das Gerät als
„denkender Controller" — du spielst 5 Cells, der Harmonic Brain übersetzt
sie in echte Akkord-Noten, und ein externer Synth/DAW empfängt die ferige
Akkord-Progression auf MIDI.

| Element | Wert |
|---|---|
| **J10** (nicht J9 = Akku!) | 3.5mm TRS-Buchse, **selber MPN wie J8** (PJ-320D / LCSC C431535) — Mechanik & Sourcing wiederverwenden |
| Treiber | **Pico GP21 → PIO-UART TX** @ 31250 Baud, 8N1 |
| R_MIDI_TX | **220 Ω 0603** zwischen GP21 und TRS Tip (Daten / „cold side") |
| R_MIDI_REF | **220 Ω 0603** zwischen +3V3 und TRS Ring (Strom-Referenz / „hot side") |
| Schirm | TRS Sleeve → GND |

**Pegel**: 3,3 V direkt vom Pico-GPIO. MIDI-Spec-Update **CA-033 (2020)
erlaubt 3.3-V-Treiber** explizit → kein Level-Shifter, kein 5-V-Buffer
nötig. Industrie-Status quo: Korg, Make Noise, Novation, Roland (neuere
Modelle) machen das genauso.

**Galvanische Isolation**: nicht nötig am OUT (nur am IN). Die 220-Ω-
Widerstände begrenzen den Kurzschlussstrom und definieren die Source-
Impedanz nach Spec.

**Keine MIDI-IN-Buchse** (bewusste Entscheidung, siehe CHANGELOG r15):
das Gerät ist um die 5 Cells als primäres Interface gebaut; eine 1:1-MIDI-
Notenzuordnung („Note 60 = Cell 1?") würde den Harmonic Brain aushebeln.
MIDI-Clock-Sync wäre die einzige technisch sinnvolle Anwendung, aber das
Generate-Bed ist absichtlich langsam-ambient → tight Clock-Lock wäre
musikalisch falsch.

**GPIO-Reallocation für r15** (siehe §5 + §7):
- VOL_SW wandert vom Pico (GP21) auf den MCP23017 (GPB5)
- Encoder-Drehen bleibt auf GP19/GP20 (zeitkritisch, low-latency-IRQ)
- Encoder-Drücken über MCP — Mensch-Buttondruck (>50 ms), MCP-Latenz
  <5 ms → musikalisch ununterscheidbar

**Firmware** (kommt mit Step 12b): PIO-State-Machine auf PIO1 oder PIO2
(PIO0 hat I²S), 31250 Baud → 16 Bits/Baud-Takt × 31250 ≈ trivial,
keine Belastung. Ring-Buffer Note-On/Off-Builder mit Channel + Velocity-
Mapping.

---

## 9. JLCPCB DFM-Konformität (unverändert v0.5)

| Requirement | Wert |
|---|---|
| Fiducial Markers | 3× 1mm runde Cu-Pads, 2mm Solder-Mask-Opening |
| Edge Rails | ≥5mm rundherum |
| Component-to-Edge | ≥2.5mm |
| Min Trace Width | 0.15mm (6 mil) Standard JLC Econ |
| Min Trace Spacing | 0.15mm |
| Min Via Drill | 0.3mm |
| Min Annular Ring | 0.075mm |
| Layer count | 4 (Signal / GND / **+5V** / Signal) — +5V ist Hochstrom-Schiene, siehe §3 |
| Board thickness | 1.6mm |
| Surface finish | ENIG |
| Color | Schwarz Solder-Mask + weiße Silkscreen |

---

## 10. Bekannte Risiken & offene Verifikationen v0.6

### Vor KiCad-Schematic geklärt

| ✓ Item | Status |
|---|---|
| USB-C-Routing (war C1) | Variante A: USB-C nur an Pico, Pi via WLAN/SSH |
| Pop-Suppression-GPIOs (war C2) | GP27/GP28 belegt, Firmware-Sequenz dokumentiert |
| Polyfuse-Dimensionierung (war H1) | v0.7: 3A/6A (Littelfuse 1812L300) — 2A war zu klein für 2.45A Worst-Case |
| PAM8403 Bulk-Cap (war H2) | 10 µF + 100 nF lokal an VDD |
| MCP23017 INTA Pull-Up (war H3) | R20 = 10 kΩ |
| OLED 256×64 vs 128×64 (war H4) | 256×64 bestätigt (separater Firmware-Task) |
| OLED VBAT Decoupling (war M1) | C6b/C6c lokal |
| PCM5102A AGND/DGND (war M2) | FB1 + getrennte Decoupling-Paare |
| Pi-Power-Injection TVS (war M3) | D2 SMAJ5.0A |
| Encoder RC (war M4) | 100 nF statt 10 nF |

### Was nach Datasheet stimmig ist, aber im Schematic verifiziert wird

- PCM5102A 3-wire mode mit Pi Zero 2 W I²S — Reference-Schaltung-konform, real-world erst beim Build verifiziert
- OLED BS0/BS1-Jumper — Modul-Versionen variieren, bei Empfang prüfen
- Pi Zero 2 W Boot-Strom-Spike — 1000 µF Bulk-Cap simuliert OK, real-world erst beim Build
- EC11 Hot-Swap-Sockets bei JLC — nicht im Stock, du lieferst (oder SMD-EC12 direkt verlötet als Alternative)
- USB-C C165948 Stock — heute via `lcsc`-/`jlcpcb`-Skill prüfen
- MCP23017 C506653 Extended-Status — heute prüfen (möglicher Aufpreis)
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

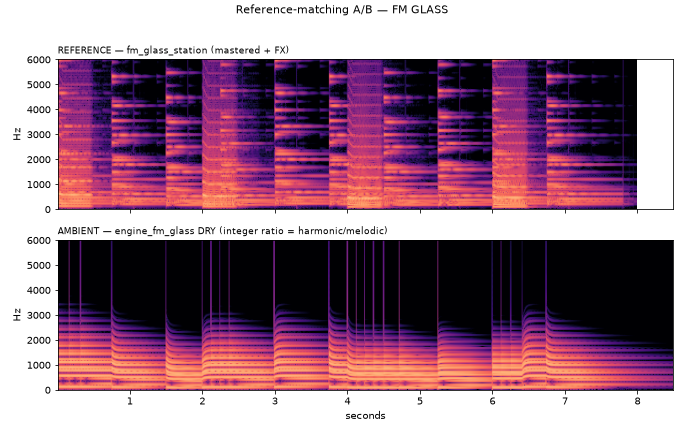
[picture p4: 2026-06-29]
field-ambience-current/docs/audio/reference-matching/fm_glass_dry_vs_reference.png

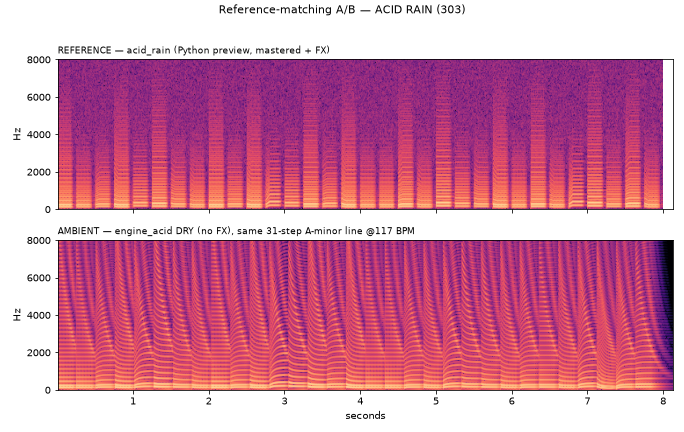
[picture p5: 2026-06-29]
field-ambience-current/docs/audio/reference-matching/acid_rain_dry_vs_reference.png

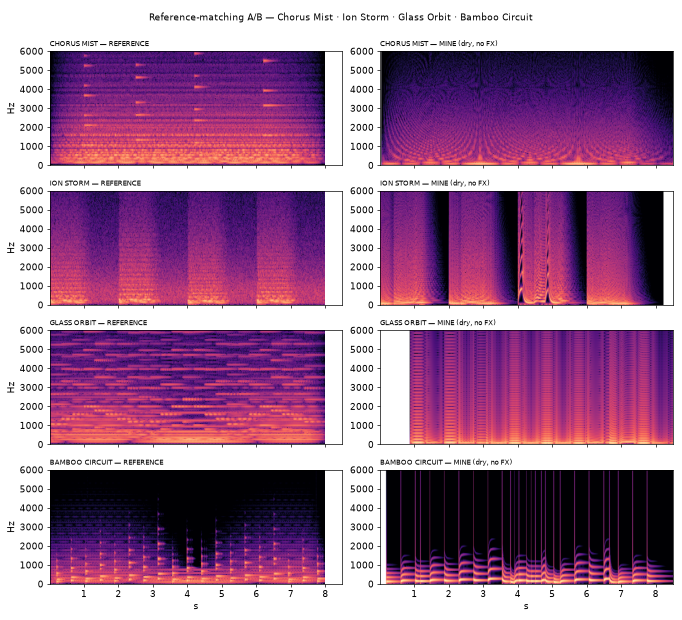
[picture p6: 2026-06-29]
field-ambience-current/docs/audio/reference-matching/engines_3to6_dry_vs_reference.png

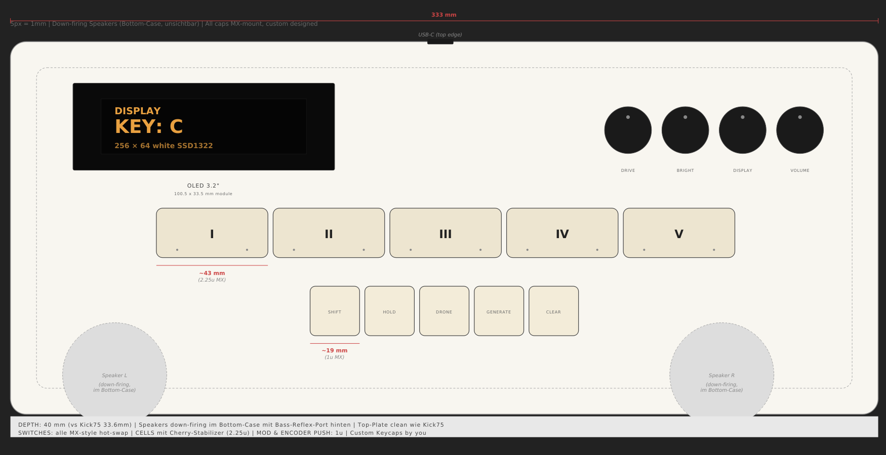
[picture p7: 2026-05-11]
field-ambience-current/field_ambience_layout.png

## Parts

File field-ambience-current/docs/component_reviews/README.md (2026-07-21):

# Component Reviews — Field Ambience

Konservative, faktenbasierte Reviews aller PCB-Bauteile gegen offizielle
Herstellerdatenblätter und Package Drawings. **Annahme bis zur Verifikation:
jedes Symbol/Footprint ist potenziell falsch.**

## Review-Regeln (Kurzfassung)

1. Quellen müssen offiziell sein (Hersteller-Datasheet, Package Drawing, AN, Eval-Board-Schematic)
2. Distributor-Daten nur ergänzend, niemals als Pinout-/Footprint-Quelle
3. Jede Aussage trägt eine Quelle (Dokument + Revision + Seite/Tabelle)
4. Strikte Trennung: Fakt aus Quelle / Abgeleitet / Ungeklärt / Risiko
5. „Sollte passen" / „vermutlich" / „wahrscheinlich" sind verboten ohne explizite Unverifiziert-Markierung
6. Bestehende Library-Parts dürfen **nicht** blind wiederverwendet werden
7. Status-Werte: `APPROVED` / `APPROVED WITH NOTES` / `BLOCKED` / `REQUIRES SOURCE/CLARIFICATION` / `FAIL`

Volle Regeln: siehe Session-Log-Reviewer-Template (User-Vorgabe 2026-06-08).

## Status-Übersicht (Stand 2026-06-08, 2 Reviews abgeschlossen)

| Ref | Bauteil | Status | Review-Datei | Letzte Prüfung | r18-Änderung? |
|---|---|---|---|---|---|
| U1 | STM32H743VIT6 | 🟡 REQUIRES SOURCE / CLARIFICATION | [U1_STM32H743VIT6.md](U1_STM32H743VIT6.md) | 2026-06-08 (mit DS12110 Rev 5 Pin/Power/HSE-Verifikation) | **NEU** |
| Y1 | ~~ABM3-8.000MHZ-D2Y-T~~ → **ABLS-8.000MHZ-B4-T** (HC-49/US SMD) | 🟢 **APPROVED WITH NOTES** (Gain Margin 2.97 Worst-Case, real ~5–6 @ Indoor-Temp, bewusst akzeptiert) | [Y1_alternatives.md](Y1_alternatives.md) | 2026-06-08 (T+3: ABLS verifiziert + User-Entscheidung) | **NEU** |
| U5 | AP7361A-33ER | ⏳ noch nicht reviewed | — | — | **war DNP, jetzt aktiv** |
| C_VDD\*, VCAP\*, VDDA | Decoupling-Caps | ⏳ noch nicht reviewed (VCAP = 2× 2.2 µF bereits aus DS12110 Rev 5 Table 24 bestätigt) | — | — | **NEU** |
| R_BOOT0, R_NRST, C_NRST | Boot/Reset | ⏳ noch nicht reviewed | — | — | **NEU** |
| U3 | PCM5102APWR | ⏳ noch nicht reviewed | — | — | unverändert (SAI-Master statt PIO im MCU) |
| U4 | PAM8403DR-H | ⏳ noch nicht reviewed | — | — | unverändert |
| U2 | MCP23017-E/SS | ⏳ noch nicht reviewed | — | — | unverändert |
| U6 | PCA9685PW | ⏳ noch nicht reviewed | — | — | unverändert |
| U7 | BQ24074RGTR (r19.18, ADR-0023) | ✅ r19.18: Pin-Map/Formeln gegen TI SLUS810N, Footprint gegen JLC-Landpattern C54313 | 2026-07-13 | ADR-0023 | **ersetzt MCP73831** |
| U8 | TPS61089RNR | 🔴 SOFORT-FINDING (F-1) | — | — | **Datenblatt im Repo ist falsche Variante (RNSR statt RNR)** |
| Q1 | DMG2305UX | ⏳ noch nicht reviewed | — | — | unverändert |
| EN1–4 | ALPSALPINE EC11J1525402 | 🔴 SOFORT-FINDING (F-2) | — | — | **Datenblatt im Repo ist falsches Teil (Bourns PEC11R)** |
| J1 | USB-C TYPE-C-31-M-12 | ⏳ noch nicht reviewed | — | — | unverändert |
| LCD-Modul | ST7789 1.9" 320×170 | ⏳ noch nicht reviewed | — | — | unverändert (Display selbst), SAI-Anschluss neu |
| USB-ESD | USBLC6-2SC6 | ⏳ noch nicht reviewed | — | — | unverändert |
| F1 | Polyfuse 1812L300 | ⏳ noch nicht reviewed | — | — | unverändert |
| Speakers | PUI AS04008PS 8 Ω | ⏳ noch nicht reviewed | — | — | unverändert |
| Battery | LiPo 5000 mAh | ⏳ noch nicht reviewed | — | — | unverändert |

### Status-Legende
- ✅ **APPROVED** — vollständig verifiziert, keine Findings, Wiederverwendung sicher
- 🟢 **APPROVED WITH NOTES** — verifiziert, kleine Hinweise zu beachten
- 🟡 **REQUIRES SOURCE / CLARIFICATION** — Hauptquellen fehlen, Review unvollständig
- 🟠 **BLOCKED** — Findings müssen vor Wiederverwendung gefixt werden
- 🔴 **FAIL / SOFORT-FINDING** — Datenblatt-Mismatch, falscher Part, kritischer Fehler
- ⏳ noch nicht reviewed

## Sofortige Findings (vor Phase 3 zu klären)

### F-1: TPS61089-Varianten-Mismatch — 🟡 **HYGIENE DONE, DATASHEET-FETCH OFFEN**
- Falsche `TPS61089RNSR.pdf` ist nach `kicad/datasheets/legacy/` als
  `TPS61089RNSR_wrong_variant.pdf` verschoben ✓. Das *Bauteil* ist korrekt:
  Schematic/BOM = **TPS61089RNR** (C165129), `jlc_bom.csv` bestätigt.
- **Rest-Aktion (vor Layout):** korrektes RNR-Datasheet von ti.com beschaffen
  + Pin-Belegung im battery-Sheet dagegen prüfen. (Web/User-Task.)

### F-2: EC11-Encoder-Datasheet falsch — 🟡 **HYGIENE DONE, DATASHEET-FETCH OFFEN**
- Falsche Bourns `PEC11R-4215F-S0024.pdf` ist nach `kicad/datasheets/legacy/`
  verschoben ✓. Das *Bauteil* ist korrekt: ALPS **EC11E18244AU** (C202365),
  `jlc_bom.csv` bestätigt.
- **Rest-Aktion (vor Layout):** ALPS-EC11E-Datasheet beschaffen. (Web/User-Task.)

### F-3: Y1-Crystal-ESR — ✅ **RESOLVED**
- Die alte „140 Ω / 500 Ω"-Diskussion betraf das **verworfene** ABM3-Teil
  (siehe F-4). Das gewählte **ABLS-8.000MHZ-B4-T** hat **ESR max 80 Ω** — und
  SPEC v0.7 §4 Y1-Zeile gibt diesen Wert bereits korrekt an (Drawing 450669
  Rev AD Table 1), inkl. Gain-Margin-2.97-Begründung. Keine Aktion offen.

### F-4: ✅ **RESOLVED (T+3, 2026-06-08)** — Crystal-Wechsel ABM3 → ABLS-8.000MHZ-B4-T

> **Auflösung (T+3):** Nach Verwerfen von ABM3 (Gain Margin 0.47, würde nicht
> oszillieren) hat der User den **HC-49/US-SMD-Pfad** gewählt. Gewählt:
> **ABRACON ABLS-8.000MHZ-B4-T** (LCSC C596838), ESR max 80 Ω gegen offizielles
> Datasheet (Drawing 450669 Rev AD) verifiziert. **Gain Margin = 2.97** im
> Worst-Case (ESR_max über vollen -20…+70 °C-Bereich).
>
> **Warum trotz GM < 5 akzeptiert:** Das AN2867-Minimum 5 ist ein konservatives
> Industrial/Automotive-Kriterium, das ESR_max über -40…+85 °C ansetzt. Dieses
> Gerät ist ein **Indoor-Audio-Produkt** (real 15–30 °C); dort liegt ESR typisch
> bei 40–50 Ω → realer Gain Margin ≈ 5–6. Der GM=2.97-Wert ist also der
> Papier-Worst-Case, nicht der Betriebsfall. **Bewusste User-Entscheidung
> (2026-06-08).** Phase 5 verifiziert den Crystal-Start am realen PCB.
>
> Verbleibendes Restrisiko (niedrig): Falls das Gerät doch dauerhaft <0 °C oder
> >60 °C betrieben wird, sollte auf MEMS-Oszillator (SiTime SiT8008) gewechselt
> werden. Für den spezifizierten Use-Case nicht nötig.
>
> **Status: Finding geschlossen. Phase 3 (KiCad-Schematic) entblockt.**

---

#### Historie F-4 (zur Nachvollziehbarkeit)

> **Update T+2 (2026-06-08):** Ursprüngliche Bewertung „BLOCKED, marginal" war zu
> optimistisch — Berechnungsformel hatte den Faktor 4 nicht. Nach ST AN2867-Studium
> auf CRITICAL eskaliert.

- **ST AN2867 Rev 24** definiert die korrekte Formel: `gm_crit = 4 × ESR × (2πF)² × (C0+CL)²`
  und fordert **Gain Margin ≥ 5** als Minimum für zuverlässigen Crystal-Start
- **Für ABM3-8.000MHZ-D2Y-T** (ESR=500 Ω, CL=18 pF, C₀=7 pF, F=8 MHz):
  - gm_crit = 4 × 500 × (2π·8e6)² × (25e-12)² = **3.16 mA/V**
- **STM32H743 gm = 1.5 mA/V** (DS12110 Rev 5 Table 43)
- **Gain Margin = 1.5 / 3.16 = 0.47** ← WEIT unter 5
- **Bei Gain Margin < 1: Crystal oszilliert gar nicht!**
- **Wirkung:** ABM3 funktioniert mit STM32H743 wahrscheinlich nicht. PCB würde im ersten Spin nicht booten.
- **Erforderlich für Gain Margin = 5 bei 8 MHz, C₀+CL = 25 pF:** ESR ≤ **47.5 Ω** _(T+3-Korrektur: hier stand fälschlich 190 Ω — in der Rückwärtsrechnung ESR = gm/(5·4·(2πF)²·(C₀+CL)²) fehlte der Faktor 4)_
- **Aktion:** **PFLICHT-Wechsel.** Mehrere Lösungs-Pfade in Phase 2 Sourcing-Session zu prüfen:
  - Standard 8 MHz Crystal mit ESR ≤ 47.5 Ω im 5032 (praktisch nicht zu finden)
  - HC-49S-SMD Crystal (ESR typisch 30-60 Ω → GM 4-8, aber größerer Footprint)
  - **MEMS-Oszillator (SiTime SiT8008, SiT1602): empfohlen** — eliminiert Crystal-Probleme komplett, direkter Anschluss an OSC_IN
- **Status:** SPEC §4 Y1-Zeile in r18.3 auf „PLATZHALTER" geändert. **BLOCKER für Phase 3 KiCad-Schematic.**

### F-5: STM32H743 Datasheet-Revision Mismatch
- **Lokal abgerufenes Datasheet:** DS12110 Rev 5 (Juli 2018)
- **SPEC v0.7-r18.1 behauptet:** SYSCLK = 480 MHz via PLL
- **DS12110 Rev 5 dokumentiert nur:** bis 400 MHz Run-Mode (Tables 29-31). **VOS0 (480 MHz) nicht in dieser Revision.**
- **Wirkung:** Meine SPEC-Behauptung „480 MHz" ist auf der lokalen Datenbasis NICHT direkt verifiziert. Spätere Datasheet-Revisionen (Rev 7+) müssten VOS0 dokumentieren.
- **Aktion:** Neuere DS12110-Revision von st.com beschaffen + lesen, oder SPEC vorsichtshalber auf „400 MHz typ (480 MHz mit VOS0 ab Datasheet Rev 7+, in Phase 5 final messen)" korrigieren.

## Verifizierte Werte (positive Bestätigungen aus DS12110 Rev 5)

Aus dem aktuellen Datasheet-Studium positiv bestätigt für SPEC-Werte:
- **VCAP = 2× 2.2 µF X5R** ± 20%, ESR < 100 mΩ (Table 24 Page 101) ✓ entspricht SPEC §5.10
- **VDD-Range 1.62-3.6 V** (Table 23 Page 100) — 3.3 V innerhalb Spec ✓
- **VDD33USB ≥ 3.0 V** (Table 23 Page 100) — 3.3 V innerhalb Spec ✓
- **VBOR0 = 1.62 V rising** (Table 26 Page 102) — Brown-out-Reset funktional ab 1.62 V
- **HSE-Range 4-48 MHz** (Table 43 Page 120) — 8 MHz innerhalb Range ✓
- **HSE Startup Time 2 ms typ** (Table 43 Page 120) — kompatibel mit Boot-Sequenz §12.5
- **Run-Mode @ 400 MHz, all periph enabled: 165 mA typical** (Table 29 Page 105) — meine SPEC-Annahme 180 mA Worst-Case ist realistisch konservativ
- **VOS1 max 400 MHz, VOS2 max 300 MHz, VOS3 max 200 MHz** (Tables 29-31) — Voltage-Scaling-Ranges bestätigt

## Reihenfolge der nächsten Reviews

Priorisiert nach Risiko + Migrations-Relevanz:

1. **🔴 SOFORT (Sourcing-Klärung):** F-1 (TPS61089), F-2 (EC11J1525402)
2. **🟠 HOCH (vor Phase 3):**
   - ✅ F-3 + F-4 erledigt (T+3): Y1 → ABLS-8.000MHZ-B4-T, SPEC §4 + §5.9 aktualisiert
   - F-5 (Datasheet-Revision) → neuere DS12110 Revision beschaffen
3. **HOCH (neu in r18):** U5 AP7361A-LDO
4. **HOCH (Quellenbeschaffung für U1):** ST AN3318, ST UM2407 Nucleo-Schematic, DS12110 §6.1 + §6.3.13 (HSE detail), §7 (Package)
5. **MITTEL (zentral aber unverändert):** U3 PCM5102A (SAI-Kompatibilität), U4 PAM8403, U2 MCP23017, U6 PCA9685
6. **MITTEL (Power-Tree H7):** Decoupling-Caps gegen AN3318 final verifizieren
7. **NIEDRIG (bewährt aus v0.6):** U8 TPS61089 (nach F-1), USB-C, ST7789-Modul, USBLC6, Polyfuse, Speakers, Battery. (U7 ist seit r19.18 der BQ24074 — reviewed, s.o.; Q1 seit r18.79 entfernt.)

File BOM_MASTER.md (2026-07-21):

# BOM Master — Field Ambience (detailed / working view)

> 🏭 **Production handoff → [`field-ambience-current/PCB_BOM.md`](field-ambience-current/PCB_BOM.md)**
> (English, **on-PCB parts only**, off-board parts excluded, no duplicates,
> grouped by function). *This* file is the detailed working/rationale view
> (sourcing history, off-board parts, audit trail) — for Claude + deep dives.

**State: v0.7-r18.65 (2026-06-27).** Single source of truth for all actively
fitted components. Per entry: current choice, footprint source, 3D source,
order link. **Footprint and STEP columns are clickable since r18.36** and point
to the respective file in the repo (relative Markdown links, work on GitHub and
in any Markdown editor).

> The generator (`field-ambience-current/kicad/generate_kicad_project.py`) is the
> technical source of truth (LCSC, MPN, footprint in the schematic). This file is
> the reading/sourcing view. If an entry here disagrees, the generator wins.

## Legend

- **FP source:** `KiCad-Standard` (in the official kicad-footprints repo),
  `field_ambience` (vendored under `kicad/libraries/field_ambience.pretty/`),
  or `Module` (plug-in module, no PCB footprint except the header).
- **3D source:** `STEP in repo` (`kicad/libraries/field_ambience.3dshapes/`),
  `easyeda2kicad` (regenerable via `pip install easyeda2kicad; easyeda2kicad
  --full --lcsc_id=Cxxxxxx`), `Vendor-CAD` (obtain externally — no STEP in repo),
  `Standard-Lib-3D` (ships with the KiCad footprint).

---

> **✅ JLC assembly sourcing check (2026-06-29) — resolved.** Verified every
> soldered part against JLC's SMT parts API. All in JLC's assembly library; the
> 5 problem parts below are **fixed with verified JLC-stocked replacements**
> (specs + stock confirmed via API). Browsable: [`field-ambience-current/docs/hardware/bom_overview.html`](field-ambience-current/docs/hardware/bom_overview.html).
>
> | Was | Problem | → Replacement (verified) | JLC |
> |---|---|---|---|
> | FB2 `C84094` | not in JLC assembly | **`C19330`** for both FB1+FB2 (Murata, same MPN) | Extended, 950 k |
> | VCAP `C24539` | not in JLC assembly | **`C23630`** (2.2 µF 16 V X5R 0603) | **Basic**, 1.9 M |
> | LED_CHRG `C72041` | **wrong part — blue + EOL** (not amber!) | **`C965800`** (XL-1608UOC-06 orange 605 nm 0603) | Extended, 650 k |
> | C_BULK2 `C2880380` | stock ≈1 | **`C23742`** (100 µF 10 V X5R 1210) | Extended, 41 k |
> | SW6-10 `C2845240` | stock ≈30 (too few) | **`C36498965`** (HX B3F, square head for caps, 20 k, ~$0.06) — verify THT footprint/pinout | Extended, 20 k |

## 1. MCU + Clock

| Ref | MPN | LCSC/Link | Footprint | FP source | 3D |
|---|---|---|---|---|---|
| U1 | **STM32H743VIT6** LQFP-100 | [C114409](https://www.lcsc.com/product-detail/C114409.html) | `Package_QFP:LQFP-100_14x14mm_P0.5mm` | KiCad-Standard | [STEP](field-ambience-current/kicad/libraries/field_ambience.3dshapes/LQFP-100_L14.0-W14.0-H1.4-LS16.0-P0.50.step) |
| Y1 | **ABLS-8.000MHZ-B4-T** HC-49/US-SMD | [C596838](https://www.lcsc.com/product-detail/C596838.html) | [`field_ambience:Crystal_HC49-US-SMD_ABLS`](field-ambience-current/kicad/libraries/field_ambience.pretty/Crystal_HC49-US-SMD_ABLS.kicad_mod) | field_ambience | [STEP](field-ambience-current/kicad/libraries/field_ambience.3dshapes/CRYSTAL-SMD_L11.4-W4.7-LS12.7.step) |

## 2. Power Stack

| Ref | MPN | LCSC/Link | Footprint | FP source | 3D |
|---|---|---|---|---|---|
| **J1** USB-C | **TYPE-C-31-M-12** (Korean Hroparts) — 16-pin full USB-C pinout (VBUS/GND/CC1/CC2/D+/D−/SBU). r18.19-REVERT: r18.10 had wrongly "upgraded" to M-17, but M-17 is 6-pin power-only → USB-DFU would have been broken. | [C165948](https://www.lcsc.com/product-detail/C165948.html) | `Connector_USB:USB_C_Receptacle_HRO_TYPE-C-31-M-12` | KiCad-Standard | Standard-Lib-3D (r18.36 fix: previously wrongly "STEP in repo" — no custom STEP exists) |
| D1 | **USBLC6-2SC6** ESD protection | [C2687116](https://www.lcsc.com/product-detail/C2687116.html) | `Package_TO_SOT_SMD:SOT-23-6` | KiCad-Standard | Standard-Lib-3D |
| F1 | **1812L300/16GR** PTC 3 A | [C18198349](https://www.lcsc.com/product-detail/C18198349.html) | `Fuse:Fuse_1812_4532Metric` | KiCad-Standard | Standard-Lib-3D |
| D2 | **SMAJ5.0A** TVS | [C113952](https://www.lcsc.com/product-detail/C113952.html) | `Diode_SMD:D_SMA` | KiCad-Standard | Standard-Lib-3D |
| **U8** TPS61089 boost VQFN-HR | [C165129](https://www.lcsc.com/product-detail/C165129.html) | [`field_ambience:Texas_VQFN-HR-11_2x2.5mm_P0.5mm_RNR0011A`](field-ambience-current/kicad/libraries/field_ambience.pretty/Texas_VQFN-HR-11_2x2.5mm_P0.5mm_RNR0011A.kicad_mod) | field_ambience | [STEP](field-ambience-current/kicad/libraries/field_ambience.3dshapes/VQFN-HR_L2.5-W2.0-H1.0-P0.50.step) |
| L1 boost inductor | **SWPA6045S2R2NT** 2.2 µH (r18.77: corrected — schematic had `SWPA6045S2R2MT`, which per Sunlord's own datasheet does not exist for 2.2 µH; only the "N"-tolerance suffix is offered below 4.3 µH) | [C36500](https://www.lcsc.com/product-detail/C36500.html) (r18.77: was `C83455`, a dead LCSC listing — never actually valid despite the r18.20c "✓ Extended" note; verified live against Sunlord's SWPA6045S datasheet Item 12 table: 2.2 µH, DCR 18 mΩ max, Isat 7.40 A typ, Irms 5.00 A typ) | [`field_ambience:L_Sunlord_SWPA6045`](field-ambience-current/kicad/libraries/field_ambience.pretty/L_Sunlord_SWPA6045.kicad_mod) (EasyEDA CAD vendored r18.20c — phantom name L_0630 replaced) | field_ambience (custom) | [STEP](field-ambience-current/kicad/libraries/field_ambience.3dshapes/IND-SMD_L6.0-W6.0-H4.5.step) |
| D3 | **SS34** Schottky diode | [C8678](https://www.lcsc.com/product-detail/C8678.html) | `Diode_SMD:D_SMA` | KiCad-Standard | Standard-Lib-3D |
| **R_COMP / C_COMP** boost loop comp (r18.80) | **6,2 k 1 % (0603WAF6201T5E) / 10 nF (0603B103K500NT)** — nach TI SLVSD38C Gl. 17/18 (fc ≈ 8 kHz ≤ fRHPZ/5 ≈ 9,5 kHz @VIN 3,0 V/2 A); **war 22k/1nF = fc ≈ 87 kHz ÜBER der RHP-Nullstelle → Loop-Oszillation unter Last**. Formeln gegen TIs eigenes 9-V/2-A-Referenzdesign validiert (reproduziert exakt 17,4k/4,7nF). | [C4260](https://www.lcsc.com/product-detail/C4260.html) (Basic, 219k Stock, live verifiziert 2026-07-02) / [C57112](https://www.lcsc.com/product-detail/C57112.html) | `Resistor_SMD:R_0603_1608Metric` / `Capacitor_SMD:C_0603_1608Metric` | KiCad-Standard | Standard-Lib-3D |
| **C_BOOST_OUT ×3** (r18.80: war 1×) | **CL21A226MAQNNNE** 22 µF 25 V X5R 0805 ×3 — TI DS §9.2.2.7 „typically three 22 µF"; EC-Tabelle rechnet Soft-Start mit COUT_eff 47 µF; 1× 0805 hätte bei 5-V-Bias nur ~12 µF eff. (Ripple ~150 mV), und der 470-µF-Bulk liegt HINTER D3 (der Regelknoten sieht ihn nicht). **Achtung: C45783 ist 22 µF, nicht 4,7 µF** — die alte „CL21A475"-Beschriftung der STM32-VDD-Bank war falsch (r18.80 korrigiert). | [C45783](https://www.lcsc.com/product-detail/C45783.html) (Basic, 1,6 M, live verifiziert 2026-07-02) | `Capacitor_SMD:C_0805_2012Metric` | KiCad-Standard | Standard-Lib-3D |
| ~~Q1 DMG2305UX-7 P-Ch MOSFET~~ + ~~R22 10k~~ | ⛔ **ENTFERNT r18.79 (Elektrik-Audit):** der Power-Path (S=VBUS pre-fuse, D=+5V-Rail, G→GND) speiste ohne USB die Boost-5V über Body-Diode + durchgeschaltetes Gate zurück auf VBUS → Lader lud den Akku aus dem eigenen Boost (Selbstentladeschleife ~1,5× Ladestrom), USB-Detect dauerhaft HIGH, 5 V am offenen Stecker; zusätzlich überbrückte Q1 die Sicherung F1. Ersetzt durch **Dioden-OR**: USB → F1 → **D3B** (2. SS34, C8678) → Rail ‖ Boost → D3 → Rail. | — | — | — |
| ~~**D3B** USB-Pfad-Schottky~~ | ⛔ **ENTFERNT r19.18 (ADR-0023):** das Dioden-OR ist Geschichte — die +5V-Rail hat genau EINE Quelle (Boost via D3). Der USB-Pfad endet am BQ24074-IN. | — | — | — | — |
| **F2** Batterie-PTC (r19.18, ADR-0023) | **SMD1812P260TF/16** (PTTC) 2,6 A hold / 5 A trip / 16 V / 15 mΩ — Hard-Short-Backup im BAT+-Pfad (Zellen-Schutz-PCB bleibt Pflicht) | [C438899](https://www.lcsc.com/product-detail/C438899.html) (live verifiziert 2026-07-13: 1.730 Stk., JLC Economic+Standard) | `Fuse:Fuse_1812_4532Metric` | KiCad-Standard | Standard-Lib-3D |
| **U5** LDO | **AP7361C-33Y5-13** SOT-89-5 (pinout 1=EN, 2=GND, 3=ADJ, 4=IN, 5=OUT verified) | [C460397](https://www.lcsc.com/product-detail/C460397.html) | `Package_TO_SOT_SMD:SOT-89-5` | KiCad-Standard | Standard-Lib-3D |
| **U_PWR** power-off load switch (ADR-0016) | **TPS22918DBVR** SOT-23-6 — gates the LDO input `+5V_RAIL → +5V_SW` (= the whole 3V3 domain: MCU + MCP + LEDs + LCD). ON comes from `SW_PWR`. Charger U7 sits **ahead** of it → keeps charging when off. "Dark, but charging." | [C131941](https://www.lcsc.com/product-detail/C131941.html) (r18.81: live verifiziert — TPS22918DBVR, 42k Stock; **jetzt im power_tree-Schematic verdrahtet**, Pinout gegen TI SLVSD76C: 1=VIN,2=GND,3=ON,4=CT float,5=QOD→VOUT,6=VOUT) | `Package_TO_SOT_SMD:SOT-23-6` | KiCad-Standard | Standard-Lib-3D |
| **SW_PWR** slide switch = main power-off | **ALPS ALPINE SSSS811101** (r18.85 — **premium/TE-grade swap**, user direction "high quality like Teenage Engineering"; ALPS is exactly the brand class TE uses). SMD micro slide, SPDT, **natively side-actuated**: ALPS datasheet "Actuator directions: **Horizontal**" — knob (1.1 mm) protrudes sideways from the body, travel 1.5 mm, operating force 1.5 N, ground-frame terminal, reflow (JLC assembles it). Switches **only** `U_PWR.ON` (signal level, µA); 10 k cycles / 0.3 A 5 V — ample. **Common is LABELED in the ALPS circuit diagram (C = terminal 2)** — closes the old MST "terminals unlabeled" gap. ⚠ **Mechanical note for the case:** body is only **1.4 mm tall** → stem window sits **z ≈ 0–1.4 mm above the PCB** (much lower than the old MST's 2.3–3.8 mm) — side-wall slot + slider cap must reach down near board level; cap still takes the user's force (same-axis sliding, no motion redirection). **Budget fallback (stays vendored):** MST-12D18G3 (SHOU HAN, [C49023766](https://jlcpcb.com/partdetail/C49023766), FP `SW_MST-12D18_SlideSwitch_RA`, r18.81-verified). | [C109335](https://www.lcsc.com/product-detail/C109335.html) (JLC Extended, ~33 k stock, ~$0.15) | [`field_ambience:SW_ALPS-SSSS811101_SlideSwitch_SMD`](field-ambience-current/kicad/libraries/field_ambience.pretty/SW_ALPS-SSSS811101_SlideSwitch_SMD.kicad_mod) — **vendored r18.85 (easyeda2kicad C109335) + verified against the ALPS land pattern (p.3)**: 3 signal pads 0.7 mm @ asymmetric 3.0/1.5 mm spacing + 4 ground-frame pads 0.8×1.0 @ ±3.65 mm (inner edge 6.3 mm) + 2 locator holes ø0.9 @ 3.0 mm — exact match. Ground pads 4–7 are not in the 3-pin symbol (solder-anchor the frame; optionally tie to GND in layout for EMC). | field_ambience | [STEP](field-ambience-current/kicad/libraries/field_ambience.3dshapes/SW_ALPS-SSSS811101_SlideSwitch_SMD.step) |
| **R_PWR_PD** 100 kΩ 0603 (`U_PWR.ON` pull-down → default OFF) | 0603WAF1003T5E | [C25803](https://www.lcsc.com/product-detail/C25803.html) | `Resistor_SMD:R_0603_1608Metric` | KiCad-Standard | Standard-Lib-3D |
| **C_PWR_SW** 10 µF X5R 0805 (output cap on `+5V_SW`) | LMK212ABJ106 class | [C15850](https://www.lcsc.com/product-detail/C15850.html) | `Capacitor_SMD:C_0805_2012Metric` | KiCad-Standard | Standard-Lib-3D |
| **U7** charger (r19.18, ADR-0023) | **BQ24074RGTR** (TI, VQFN-16 RGT 3×3) — 1,5-A-Power-Path-Charger mit DPPM. ICHG = 890/R_ISET(1k) = **0,89 A**; IIN-MAX = 1610/R_ILIM_IN(1,2k) = **1,34 A**; ITERM/TMR = NC-Default (10 % / 5 h); TS = 10k fest; EN2=VSYS/EN1=GND; OUT=`VSYS` speist den Boost, BAT via F2 an J9. Ersetzt MCP73831 (Audit P0-1/2/5/6/7). | [C54313](https://www.lcsc.com/product-detail/C54313.html) (live verifiziert 2026-07-13: 1.074 Stk., $2,24@1, JLC Economic+Standard) | `Package_DFN_QFN:QFN-16-1EP_3x3mm_P0.5mm_EP1.7x1.7mm` (gegen JLC/EasyEDA-Landpattern C54313 abgeglichen) | KiCad-Standard | Standard-Lib-3D |
| **R_ISET / R_ILIM_IN / R_TS** BQ24074-Programmierung (r19.18) | 1 kΩ (ICHG 0,89 A) / **1,2 kΩ YAGEO RC0603FR-071K2L** (IIN 1,34 A) / 10 kΩ (TS fest, DS-Vorgabe ohne Pack-NTC) | [C21190](https://www.lcsc.com/product-detail/C21190.html) / [C114605](https://www.lcsc.com/product-detail/C114605.html) (live verifiziert: 407k Stk.) / [C25804](https://www.lcsc.com/product-detail/C25804.html) | `Resistor_SMD:R_0603_1608Metric` | KiCad-Standard | Standard-Lib-3D |
| **C_BAT / C_SYS1 / C_SYS_HF** BQ24074-Bypass (r19.18) | 22 µF 0805 (BAT, DS 4,7–47 µF) / 22 µF 0805 (VSYS = OUT-Bypass + Boost-Input) / 100 nF 0603 | [C45783](https://www.lcsc.com/product-detail/C45783.html) / [C45783](https://www.lcsc.com/product-detail/C45783.html) / [C14663](https://www.lcsc.com/product-detail/C14663.html) | 0805 / 0805 / 0603 | KiCad-Standard | Standard-Lib-3D |
| **C_BULK** polymer-tantalum 470 µF / 10 V case-E 7343-43 (ESR 100 mΩ; <25 mΩ flat parts not in stock at LCSC — transient ESR is supplied by C_BULK2) | TPSE477K010R0100 (Kyocera AVX) | [C444831](https://www.lcsc.com/product-detail/C444831.html) | `Capacitor_SMD:CP_Tantalum_Case-E_EIA-7343-43_Reflow` | KiCad-Standard | Standard-Lib-3D |
| **C_BULK2** MLCC **100 µF / 10 V** 1210 (parallel; 220µF/10V/1210 does not exist → 100µF of real headroom instead of 220µF/6.3V derating) | CL32A107MPVNNNE (Samsung) — r18.70: was C2880380 (Taiyo Yuden, JLC stock ≈1) | [C23742](https://www.lcsc.com/product-detail/C23742.html) | `Capacitor_SMD:C_1210_3225Metric` | KiCad-Standard | Standard-Lib-3D |
| **J9** JST-PH 2.0 2-pin (LiPo battery — generator refdes, **not** J_BAT) | **S2B-PH-SM4-TB(LF)(SN)** | [C295747](https://www.lcsc.com/product-detail/C295747.html) | `Connector_JST:JST_PH_S2B-PH-SM4-TB_1x02-1MP_P2.00mm_Horizontal` | KiCad-Standard | [STEP](field-ambience-current/kicad/libraries/field_ambience.3dshapes/CONN-SMD_P2.00_S2B-PH-SM4-TB-LF-SN.step) |
| LiPo **2000 mAh JST-PH** (~6.6 h @ 300 mA) — r18.21 right-sized down from 5000mAh. **r19.4: DE-Quelle = Adafruit 2011** (60×36×**7 mm**, integriertes PCM, RoHS-2, UN38.3-Report) via Mouser/DigiKey/BerryBase. ⚠ 7 mm = **+2 mm** vs 5-mm-503759-Referenz (Arons Layout); **Steckerpolung vs J9 Pin 1 = BAT_PLUS** vor dem ersten Einstecken per Multimeter prüfen. Details → `field-ambience-current/docs/SOURCING_COMPLIANCE.md §2`. PiHut-503759 (5 mm) bleibt Alternative, liefert aber nicht nach DE. | LiPo 2000mAh JST-PH 2.0 mit PCM | [Adafruit 2011](https://www.adafruit.com/product/2011) · Mouser/DigiKey/BerryBase | — (no PCB FP, bottom-case slot) | — | Vendor |

> **Power architecture / rail ownership (ADR-0016, audit #8/#9).** So the PCB
> maker sees the sources unambiguously — *one* source→system-rail place each:
> - `VBUS_USB` (USB-C 5 V, via F1 PTC) ──┐
> - r19.18 (ADR-0023): `VBUS_FUSED` (USB via F1) → **U7 BQ24074-IN**; **U7-OUT = `VSYS`** (4,4 V @USB / VBAT @Akku) → boost **U8** (4,97 V) → **D3** ──┤→ **`+5V_RAIL`** (EINZIGE Quelle; Dioden-OR/D3B entfernt) — feeds amp U4 + U_PWR. `PWR_ON` schaltet U8-EN **und** U_PWR; SW_PWR-Pull-Quelle = `VSYS`.
> - **`+5V_SW`** = `+5V_RAIL` behind **U_PWR** (switched by `SW_PWR`) → LDO **U5** → **`+3V3`** (MCU, MCP, both PCA9685, LCD)
> - Charger **U7** hangs off `VBUS_USB`/`BAT_PLUS` **ahead of** U_PWR → charges independently of the off state.
>
> The generator nets are today still partly mixed `+5V_OUT`/`+5V_RAIL`; since
> the PCB maker re-draws the schematic anyway, **this ownership view is
> authoritative** (source → exactly one system rail).

## 3. Audio Path

| Ref | MPN | LCSC/Link | Footprint | FP source | 3D |
|---|---|---|---|---|---|
| **U3** DAC | **PCM5102APWR** TSSOP-20 | [C107671](https://www.lcsc.com/product-detail/C107671.html) | `Package_SO:TSSOP-20_4.4x6.5mm_P0.65mm` | KiCad-Standard | Standard-Lib-3D |
| **U4** Class-D amp | **PAM8403DR-H** SOIC-16 | [C17337](https://www.lcsc.com/product-detail/C17337.html) | `Package_SO:SOIC-16_3.9x9.9mm_P1.27mm` | KiCad-Standard | Standard-Lib-3D |
| FB1/FB2 ferrite bead | **BLM18AG601SN1D** 0603 600 Ω | [C19330](https://www.lcsc.com/product-detail/C19330.html) (**both FB1+FB2** — r18.70: dropped C84094, not in JLC assembly; C19330 is JLC Extended, 950 k stock) | `Inductor_SMD:L_0603_1608Metric` | KiCad-Standard | Standard-Lib-3D |
| **U11** Kopfhoererverstaerker (r19.19, ADR-0024) | **TPA6132A2RTER** (TI, WQFN-16 RTE 3×3) — DirectPath (keine Auskoppel-Elkos), Gain −6 dB (G0=G1=GND), EN=AMP_nSHDN, Pop-Suppression, Kurzschluss-Schutz. Externe: 2× CIN 1 µF, C_FLY 1 µF, C_HPVSS 1 µF, C_HP_VDD+C_HPVDD 2,2 µF ([C1607](https://www.lcsc.com/product-detail/C1607.html)). J8 damit **PHONES / LINE OUT**. | [C69901](https://www.lcsc.com/product-detail/C69901.html) (live verifiziert 2026-07-13: 370 Stk., $1,35@1, JLC Economic+Standard) | `Package_DFN_QFN:QFN-16-1EP_3x3mm_P0.5mm_EP1.7x1.7mm` (gegen JLC-Landpattern C69901 + TI RTE0016C abgeglichen) | KiCad-Standard | Standard-Lib-3D |
| **J8** phones/line-out 3.5 mm TRS | **PJ-320D** (SHOU HAN, SMT) with insertion-detect | [C431535](https://www.lcsc.com/product-detail/C431535.html) | [`field_ambience:Jack_3.5mm_PJ-320D_SMT`](field-ambience-current/kicad/libraries/field_ambience.pretty/Jack_3.5mm_PJ-320D_SMT.kicad_mod) (EasyEDA CAD vendored r18.19) | field_ambience (custom) | [STEP](field-ambience-current/kicad/libraries/field_ambience.3dshapes/AUDIO-SMD_PJ-320D-1.step) |
| **J10** MIDI-out 3.5 mm TRS (r18.67) | **PJ-320D** (same MPN as J8) — TRS **Type A**, OUT-only, 3.3 V/CA-033 (no level shifter). MIDI_TX=PD5→R_MIDI_TX 220 Ω→Tip; +3V3→R_MIDI_REF 220 Ω→Ring; Sleeve→GND. ⚠️ **J9 = battery, J10 = MIDI** | [C431535](https://www.lcsc.com/product-detail/C431535.html) | see J8 (`field_ambience:Jack_3.5mm_PJ-320D_SMT`) | field_ambience (custom) | [STEP](field-ambience-current/kicad/libraries/field_ambience.3dshapes/AUDIO-SMD_PJ-320D-1.step) |
| **R_MIDI_TX / R_MIDI_REF** 220 Ω 0603 (2×, MIDI Type-A) | 0603WAF2200T5E | [C22962](https://www.lcsc.com/product-detail/C22962.html) — **verified r18.72: JLC Basic, 1.69M stock** (NEEDS-VERIFY cleared) | `Resistor_SMD:R_0603_1608Metric` | KiCad-Standard | Standard-Lib-3D |

### Speaker (r18.18 — cloth cone primary)

| Ref | MPN | Link | Footprint | FP source | 3D |
|---|---|---|---|---|---|
| **J6 / J7** 1×2 2.54 mm header (speaker leads) | B-2100S02P-A110 (1×2 2.54 mm male) | [C124375](https://www.lcsc.com/product-detail/C124375.html) | `Connector_PinHeader_2.54mm:PinHeader_1x02_P2.54mm_Vertical` | KiCad-Standard | Standard-Lib-3D |
| **SPK-L / SPK-R** driver **primary** | **Same Sky CMS-402811-28SP** (cloth cone, 40 × 28.3 × 11.5 mm, 8 Ω, 2 W, F0 = 450 Hz, NdFeB, solder eyelets) | [DigiKey 102-CMS-402811-28SP-ND](https://www.digikey.com/en/products/detail/cui-devices/CMS-402811-28SP/10821307) · [vendor page](https://www.sameskydevices.com/product/audio/speakers/miniature-(10-mm~40-mm)/cms-402811-28sp) | — (no PCB mount, depends on top panel) | — | [Vendor-CAD](https://www.sameskydevices.com/product/resource/cms-402811-28sp.pdf) |
| **SPK** driver **secondary** (backup) | **PUI AS04008PS-4W-WR-R** (treated paper, same footprint, F0 = 380 Hz) | [DigiKey](https://www.digikey.com/en/products/detail/pui-audio-inc/AS04008PS-4W-WR-R/1464855) | — | — | [Vendor-CAD](https://puiaudio.com/file/specs-AS04008PS-4W-WR-R.pdf) |

### Speaker cover (dust mesh)

| Element | Choice | Link | Source |
|---|---|---|---|
| Mesh **series** | Saati **Acoustex 020–032** (transparent class, ~25–32 g/m²) + PSA conversion via Marian Inc. | [Saati Acoustex](https://www.saati.com/products/filtration/brands/saatifil-acoustex/) · [Marian (converter)](https://marianinc.com/materials/filters-venting-fabric/) | vendor direct purchase, custom quote |
| Mesh **prototype** | Generic self-adhesive "phone-speaker dustproof mesh" stickers, punch out 36 × 24 mm ovals | AliExpress / Amazon (multipack ~€5) | Generic |

## 4. I/O Expander + LED Driver

| Ref | MPN | LCSC/Link | Footprint | FP source | 3D |
|---|---|---|---|---|---|
| **U2** GPIO expander | **MCP23017-E/SS** SSOP-28 | [C506653](https://www.lcsc.com/product-detail/C506653.html) | `Package_SO:SSOP-28_5.3x10.2mm_P0.65mm` | KiCad-Standard | Standard-Lib-3D |
| **U6** PWM LED driver | **PCA9685PW,118** TSSOP-28 (16 channels: 5 modifier + 10 cell + 1 backlight, exactly 16/16) | [C2678753](https://www.lcsc.com/product-detail/C2678753.html) | `Package_SO:TSSOP-28_4.4x9.7mm_P0.65mm` | KiCad-Standard | Standard-Lib-3D |

## 5. Display

| Ref | MPN | Link | Footprint | FP source | 3D |
|---|---|---|---|---|---|
| **J3** 1×8 header 2.54 mm (LCD module) | 2.54 mm strip cut to 1×8 (B-2100S40P or similar) — or 1×8 female socket for a pluggable module | [C124383](https://www.lcsc.com/product-detail/C124383.html) | `Connector_PinHeader_2.54mm:PinHeader_1x08_P2.54mm_Vertical` | KiCad-Standard | Standard-Lib-3D |
| **LCD module** **Waveshare 1.9in 170×320 ST7789V2** IPS module (r18.22 pivot from bare AliExpress: same panel as Adafruit + branded QC + level shifter + documented. **r19.4: DE-Quelle = Eckstein Shop 13,95 €** (exp-tech/BerryBase/Amazon.de alt). **Pin-Order weicht von J3 ab → immer per 8-Draht-Kabel** mappen, nie Steck-Header. Details → `field-ambience-current/docs/SOURCING_COMPLIANCE.md §1`) | Waveshare 1.9inch LCD Module 170x320 SPI | [Eckstein 13,95 €](https://eckstein-shop.de/WaveShare-19inch-LCD-Display-Module-170320-IPS-262K-Colors-SPI-Interface-EN) · [Waveshare](https://www.waveshare.com/1.9inch-lcd-module.htm) · exp-tech/BerryBase | Module (Kabel an J3) | — | Vendor-CAD |
| **LCD module — PROPOSED r18.43 / ADR-0015** **Waveshare 2.0in 240×320 ST7789** IPS module. Pivot 1.9″ → 2.0″ for more area + animation headroom + native RGB565 color. Same ST7789 controller family, same 8-pin SPI interface, same backlight path (Q2/PCA9685 channel 12). **UNVERIFIED — NEEDS HUMAN CHECK:** (a) sourcing path/SKU (LCSC PN may not exist; source via Waveshare/PiHut/Amazon like the 1.9″), (b) 8-pin header order against the delivered module, (c) outer dimensions + active-area position against the bezel window. Don't change the bezel cutout + generator sheet until (a)–(c) are confirmed. | Waveshare 2inch LCD Module 240×320 SPI | [Waveshare](https://www.waveshare.com/2inch-lcd-module.htm) | Module (plugs into J3, possible pin-order adaptation) | — | Vendor-CAD |
| Q2 backlight driver | **2N7002,215** SOT-23 | [C8545](https://www.lcsc.com/product-detail/C8545.html) | `Package_TO_SOT_SMD:SOT-23` | KiCad-Standard | Standard-Lib-3D |

## 6. Encoders (ADR-0012 — **4× push encoder**, all the same height)

> **r18.65:** All 4 are the same push part **EC11E18244AU** and all 4 push
> switches are wired (DISPLAY=PE3, VOL=MCP-GPB5, DRIVE=PE0, BRIGHT=PE1) → every
> encoder can carry a push function. Detent feel: Display with detents,
> parameter encoders "smooth" via firmware acceleration.

| Ref | MPN | LCSC/Link | Footprint | FP source | 3D |
|---|---|---|---|---|---|
| **EN3** (Display: push + detent) | **ALPS EC11E18244AU** (18 pulses, 36 detents, with push switch, flat shaft 20 mm) | [C202365](https://www.lcsc.com/product-detail/C202365.html) | `Rotary_Encoder:RotaryEncoder_Alps_EC11E-Switch_Vertical_H20mm` | KiCad-Standard | Standard-Lib-3D |
| **EN1 / EN2 / EN4** (r18.22 pivot: unified on the ACTIVE display encoder, because both EC11E183440C and the candidate EC11E1834403 are NRND and the whole ALPS "0-detent + push" family is phased out) | **ALPS EC11E18244AU** (= the display encoder, 36 detents/rev + push; firmware acceleration makes slow = 1 %/click, fast = ×8/click — UX-functionally identical to smooth) | [C202365](https://www.lcsc.com/product-detail/C202365.html) (~3,052 stock) | same FP as EN3 | KiCad-Standard | Standard-Lib-3D |
| Knobs (4×) Ø 19–20 × 8–10 mm, **self 3D-printed** (r18.21 — instead of Al CNC, saves $50-200/5-pack run) | own 3D print | — | — | — | Custom-CAD (user) |

## 7. Cells (ADR-0013 **SUPERSEDED r18.75** — digital, direct-solder Kailh Choc keyswitch)

> **r18.73 (User direction 2026-06-30, HiChord Batch 4+ reference):** the 5 cells
> changed from Gateron-magnetic + DRV5056A4 Hall (analog velocity into the STM32
> ADC) to a **plain digital on/off switch on the MCP23017 I²C expander** — the
> HiChord Batch 4+ topology *switch → I²C GPIO-expander → MCU*. **Removed from
> the board:** 5× DRV5056A4 Hall sensors (J_CELL1–5), 5× R_CELL 1 kΩ, 5× C_CELL
> 10 nF; the 5 STM32 ADC pins (PC0/PC1/PA4/PB0/PB1) are freed as Rev-B reserves.
>
> **r18.74 (User UX correction 2026-07-01):** r18.73 had put the cells on the
> **same small HX B3F-4055 tactile button as the modifiers** — that makes the
> playable cells feel identical to a plain modifier button and kills the
> "these are keyboard keys" UX. Cells stayed electrically digital, but were
> given a Kailh Choc hot-swap socket for real keyswitch travel.
>
> **r18.75 (User follow-up 2026-07-01 — "how is this meant to be soldered?"):**
> the r18.74 hot-swap socket had **no clean manufacturer/LCSC part number**
> and needed a fiddly small-SMD hand-soldering technique that isn't obvious
> without prior hobbyist-keyboard experience. **Fixed:** the Kailh Choc V1
> switch (**CPG135001D01**) is now **directly soldered to the board** — 2 THT
> legs through 2 holes, soldered from the back, exactly the same technique as
> every other button/connector in this design. No hot-swap socket, no special
> technique. Footprint + 3D STEP pulled straight from LCSC/EasyEDA for this
> exact part via `easyeda2kicad --full --lcsc_id=C400229` (this repo's own
> documented method for custom footprints — same as TS-1088/MST-12D18/
> PJ-320D), vendored as `field_ambience:SW_KailhChoc_CPG1350_THT_2P` with a
> real 3D STEP. Electrically unchanged since r18.73/74 (same nets/pins/
> pull-up/IRQ). **Trade-off:** the switch is now permanent (not swappable
> without desoldering) — traded for assembly simplicity and dropping the
> unverified socket part. Modifier buttons SW6–SW10 stay the small HX B3F
> tactile — deliberate UX split (cells feel like keys, modifiers feel like
> buttons). Hall stays documented as the option **only if** true press-depth/
> velocity is wanted later — see ADR-0013.

| Ref | MPN | LCSC/Link | Footprint | FP source | 3D |
|---|---|---|---|---|---|
| **Cell switch (SW1–SW5, 5×)** | **Kailh Choc V1, CPG135001D01** (red/linear) — direct-solder THT, 2 electrical pins + 3 unplated mechanical locator holes (switch's own pegs give lateral stability without a plate). One pin → MCP23017 GPA0–GPA4 (`CELL1..5_BTN`), other → GND; MCP internal pull-up, shared INT. **Any Choc V1 color works — same footprint** (see r18.78 sourcing note below). [Datasheet](https://cdn-shop.adafruit.com/product-files/5113/CHOC+keyswitch_Kailh-CPG135001D01_C400229.pdf) | [C400229](https://www.lcsc.com/product-detail/C400229.html) — real, verified listing. ⚠ 0 stock at time of writing (restocks common); JLC notes their automated PCBA needs a custom fixture for this THT part — hand-soldering the 2 legs needs neither. | `field_ambience:SW_KailhChoc_CPG1350_THT_2P` — pulled directly from LCSC/EasyEDA via `easyeda2kicad --full --lcsc_id=C400229` | repo custom, sourced from the part's own manufacturer listing (not a third-party library) | [STEP](field-ambience-current/kicad/libraries/field_ambience.3dshapes/SW_KailhChoc_CPG1350_THT_2P.step) |
| **Cell caps (5×), self 3D-printed** (clip onto the Choc V1 switch stem) | own 3D print | — | — | — | Custom-CAD (user) |

> **r18.78 sourcing note (User, 2026-07-01):** all three Kailh Choc V1 colors
> at LCSC are currently **0 stock**: red/linear [C400229](https://www.lcsc.com/product-detail/C400229.html),
> brown/tactile [C400230](https://www.lcsc.com/product-detail/C400230.html),
> white/clicky [C400231](https://www.lcsc.com/product-detail/C400231.html) —
> all real, verified, just temporarily out of stock (checked live 2026-07-01).
> **This is not a blocker:** since the switch is hand-soldered (not part of
> JLC's automated SMT pass), it doesn't need to come from LCSC at all — any
> Kailh Choc V1 switch (any color/feel, any vendor: Kailh direct, KBDfans,
> NovelKeys, AliExpress) uses the identical 2-pin THT footprint. Feel/color
> is a free choice, not a schematic constraint.
>
> **r19.4 fixed DE source:** [keycapsss.com](https://keycapsss.com) (1–3 day
> DE delivery), EU alt 42keebs.eu / splitkb.com. Pick a **tactile** variant
> (Choc Brown) for the keyboard-key feel. For the compliance file, request
> Kailh's RoHS manufacturer declaration. See `docs/SOURCING_COMPLIANCE.md §1`.
>
> **r18.78 open item for Aron (PCB layout):** user wants cell caps **2–3 cm
> long** eventually. No stabilizer needed at that length (well under the
> ~38 mm/2u stabilizer threshold), but a 20–30 mm-wide cap on the current
> 19 mm cell pitch collides with the neighboring cell if oriented left-right.
> Two ways to resolve (widen the pitch, or elongate the cap front-to-back
> instead — ~26 mm clearance to the front edge and ~32 mm to the modifier
> row are available for that) — deliberately left open for Aron to decide
> during actual layout, not fixed here. Details: `mechanical_coordinates.md`
> §3.4.
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

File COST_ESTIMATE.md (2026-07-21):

# Cost Estimate — Field Ambience

**Stand: v0.7-r18.87 (2026-07-04).** Ehrliche Kostenschätzung für einen
**5-Geräte-Prototyp-Run** über JLCPCB-PCBA + Hand-Supply-Teile. Preise der
teuren Positionen am 2026-07-02 **live von den LCSC-Produktseiten geholt**
(10+-Staffel); Rest gebändert. ±20 % — die exakte Zahl liefert das
JLCPCB-Quote-Tool, sobald `.kicad_pcb` + Gerber/CPL existieren.
BOM-Basis: `kicad/jlc_bom.csv` r18.87 = **57 unique LCSC-Parts,
188 Placements** (davon ~17 THT-Hand: 10 Switches, 4 Encoder, 3 Header).
r18.87: U10-PCA9685 + 8 VU-LEDs + Heartbeat-LED entfernt (−22 Placements,
−~$3.20 SMD-BOM/Board).

> ⚠️ **Assembly-Größenlimit (NEU r18.84, für Aron):** Die PCB-Outline ist
> **252 × 102 mm** — JLCs *Economic*-PCBA endet bei **250 × 250 mm**. 2 mm
> drüber ⇒ Zwangsupgrade auf *Standard*-PCBA (Setup ~$25 statt $8, teurerer
> Stencil). **Outline um ≥2 mm auf ≤250 mm kürzen spart ~$40–60 pro Run** —
> beim Layout prüfen, ob die 4-mm-Bezel das hergibt (mech. Spec §1 hat
> 4 mm Bezel je Seite; 1 mm opfern reicht).

## 1. JLCPCB-Anteil (5 Boards, SMD vollbestückt)

| Posten | Economic (≤250 mm) | Standard (252 mm) | Notiz |
|---|---|---|---|
| PCB-Fab 4-Layer 252×102, 1.6 mm, ×5 | ~$50 | ~$50 | 2.57 dm²/Board |
| Stencil | ~$8 | ~$38 | |
| PCBA-Setup | ~$8 | ~$25 | pro Design |
| Feeder/Extended-Gebühren | ~$8–15 | ~$8–15 | Große ICs sind „Extended (Preferred)“ = gebührenfrei (r18.22-Erkenntnis); plain-Extended: MCP23017, BQ24074, TPA6132A2, TPS22918, MST-12D18G3, PJ-320D, JST, Polyfuse u. a. à $1.50 |
| Placement (~610 SMD-Joints × 5) | ~$5 | ~$5 | $0.0017/Joint |
| SMD-BOM-Teile ×5 (§3) | ~$110 | ~$110 | ~$21.3/Board + Attrition |
| Versand DHL EU | ~$30–40 | ~$30–40 | 5× 252-mm-Boards sind sperrig |
| **JLC-Zwischensumme** | **~$225** | **~$275** | **~$45 bzw. ~$55/Board** |

## 2. Hand-Supply (separat)

| Teil | pro Gerät | × 5 | Quelle |
|---|---|---|---|
| 4× ALPS EC11E18244AU (THT, hand) | ~$7.60 | $38 | LCSC C202365, **$1.91 @10+ live 2026-07-02** (2.5k Stock) |
| 5× Kailh Choc V1 CPG135001D01 (THT, hand) | ~$5 | $25 | LCSC C400229 = 0 Stock → Kailh-Händler/AliExpress ~$1/St. |
| 5× HX B3F-4055 Modifier (THT, hand) | ~$0.30 | $2 | C36498965 (kann alternativ JLC-THT) |
| 2× CMS-402811-28SP Speaker | ~$6 | $30 | DigiKey |
| Waveshare 1.9" ST7789 | ~$12 | $60 | PiHut/Waveshare |
| 2000 mAh LiPo (mit Schutz-PCM!) | ~$8 | $40 | PiHut — **beim Kauf prüfen: Pouch MUSS eigenes Protection-PCM haben** (BQ24074 hat Charge-Timer + TS, aber KEINEN Discharge-/UVLO-Schutz; F2-PTC ist nur Hard-Short-Backup — ADR-0023) |
| Dust-Mesh + M2.5-Schrauben/Standoffs | ~$2 | $10 | AliExpress/Reichelt |
| Tag-Connect TC2030-IDC (Tool, einmalig) | — | $15 | Tag-Connect |
| **Hand-Supply-Zwischensumme** | **~$41** | **~$220** | |

## 3. SMD-BOM pro Board — ~$21.30 (Preise @10+, live 2026-07-02 wo fett)

**STM32H743VIT6 $8.68** · **PCA9685 $2.93 (r18.87: nur noch U6)** · **C_BULK Tantal 470µ $1.78** ·
**MCP23017 $1.62** · **PCM5102A $0.99** · **BQ24074 $2.24** ·
**TPS61089 $0.50** · PAM8403 ~$0.44 · TPS22918 $0.25 (live r18.81) ·
L1 SWPA6045 ~$0.25 · C_BULK2 ~$0.25 · AP7361C ~$0.20 · USBLC6 ~$0.20 ·
**USB-C $0.17** · Polyfuse ~$0.15 · Crystal ~$0.12 · 2× PJ-320D ~$0.24 · **TPA6132A2 $1.35** ·
JST ~$0.10 · MST-12D18G3 $0.08 (live r18.81) · 2× SS34 + TVS ~$0.16 ·
2× TS-1088 ~$0.04 · 2N7002 ~$0.01 · 16× LED ~$0.40 · 3× Header ~$0.35 ·
~110 R/C-Passives ~$0.55

Kostentreiber-Ranking: STM32 (41 %), PCA9685 (14 %), Tantal-Bulk (8 %),
MCP23017 (8 %). Die 4 Encoder ($7.60, THT-hand) sind der größte
Nicht-JLC-Posten pro Gerät.

## 4. Summen

| | 5er-Run | pro Gerät |
|---|---|---|
| JLC (Economic-Fall, Outline ≤250 mm) | ~$225 | ~$45 |
| JLC (Standard-Fall, 252 mm) | ~$275 | ~$55 |
| Hand-Supply | ~$220 | ~$41–44 |
| **Gesamt (Economic)** | **~$445** | **~$89** |
| **Gesamt (Standard)** | **~$495** | **~$99** |

10er-Run: PCB ~$75, Gebühren identisch, Teile ~×2 → grob **~$72–82/Gerät**.

## 5. Stock-Warnungen (live 2026-07-02)

- **C444831 (Tantal 470 µF): nur 121 St. LCSC / 161 JLC** — für 5–10 Boards
  ok, aber VOR dem Order-Klick prüfen; Alternative in BOM_MASTER §2.
- **C114409 (STM32H743VIT6): LCSC 6 St., JLC-Assembly ~392** — über
  JLC-Assembly bestücken lassen (nicht LCSC-Einzelkauf).
- **C400229 (Choc): 0 Stock** — extern beschaffen (jede Choc-V1-Farbe passt).
- C165129 (TPS61089): 2.1k ✓ · C2678753 (PCA9685): 1.4k ✓ ·
  C202365 (EC11): 2.5k ✓.

## 6. Historie

- r18.87: U10-PCA9685 + 8 VU-LEDs + R_VU + R_OE2 + 2 Caps + Heartbeat-LED
  entfernt (User: nur Cell-/Modifier-LEDs bleiben) → SMD-BOM $24.50 → ~$21.30,
  57 Parts / 188 Placements.
- r18.22: Erststand ($38/Board JLC, $18 SMD-BOM). r18.84 ersetzt: +U10-PCA
  (+$2.93), +Power-Off-Block (+$0.35), +Dioden-OR/3×22µ/Comp (+$0.15),
  Cells auf direkt-gelötete Choc (LCSC-Anteil 0), Encoder von „~$5“ auf
  live $7.60/Gerät, STM32 live $8.68, plus Economic-vs-Standard-Split
  wegen der 252-mm-Outline.

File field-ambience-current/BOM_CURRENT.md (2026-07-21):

# Field Ambience — Production BOM (current)

**Generated:** 2026-07-20 · **Source of truth:** `kicad/generate_kicad_project.py` → `kicad/jlc_bom.csv`

**On-PCB totals:** 59 unique parts · 200 placements · 59 verified LCSC · 0 without LCSC

> Audio chain current as of **r19.37** (PCM5102A + **PAM8406** + TPA6132A2; PAM8403 was NRND — swapped, ADR-0025). Power-path current as of **r19.18** (BQ24074).

## 1 · MCU · clock · memory

| Qty | Ref(s) | Part / MPN | Package | LCSC |
|----:|---|---|---|---|
| 2 | C_HSE1,C_HSE2 | CC0603JRNPO9BN270 | C_0603_1608Metric | C107045 |
| 1 | U1 | STM32H743VIT6 | LQFP-100_14x14mm_P0.5mm | C114409 |
| 1 | U9 | APS6404L-3SQN-SN | SOIC-8_3.9x4.9mm_P1.27mm | C3028887 |
| 1 | Y1 | ABLS-8.000MHZ-B4-T | Crystal_HC49-US-SMD_ABLS | C596838 |

## 2 · Power

| Qty | Ref(s) | Part / MPN | Package | LCSC |
|----:|---|---|---|---|
| 3 | C_CHG_IN,C_LDO_IN,C_LDO_OUT | GRM188R61A475KE15D | C_0603_1608Metric | C46653 |
| 3 | R_BOOT_SW,R_CHRG,R_ISET | 0603WAF1001T5E | R_0603_1608Metric | C21190 |
| 2 | R_PWR_PD,R_VBUS_PD | 0603WAF1003T5E | R_0603_1608Metric | C25803 |
| 1 | C_BULK | TPSE477K010R0100 (Kyocera AVX, Polymer-Tantal) | CP_Tantalum_Case-E_EIA-7343-43_Reflow | C444831 |
| 1 | C_BULK2 | CL32A107MPVNNNE (Samsung, 100uF 10V X5R) | C_1210_3225Metric | C23742 |
| 1 | D2 | SMAJ5.0A | D_SMA | C113952 |
| 1 | D3 | SS34 | D_SMA | C8678 |
| 1 | F1 | 1812L300/16GR | Fuse_1812_4532Metric | C18198349 |
| 1 | F2 | SMD1812P260TF/16 | Fuse_1812_4532Metric | C438899 |
| 1 | L1 | SWPA6045S2R2NT | L_Sunlord_SWPA6045 | C36500 |
| 1 | R23 | 0603WAF1213T5E | R_0603_1608Metric | C25809 |
| 1 | R24 | 0603WAF3902T5E | R_0603_1608Metric | C23153 |
| 1 | R_COMP | 0603WAF6201T5E | R_0603_1608Metric | C4260 |
| 1 | R_FSW | 0603WAF3603T5E | R_0603_1608Metric | C23146 |
| 1 | R_ILIM_IN | RC0603FR-071K2L | R_0603_1608Metric | C114605 |
| 1 | SW_PWR | SSSS811101 | SW_ALPS-SSSS811101_SlideSwitch_SMD | C109335 |
| 1 | U5 | AP7361C-33Y5-13 | SOT-89-5 | C460397 |
| 1 | U7 | BQ24074RGTR | QFN-16-1EP_3x3mm_P0.5mm_EP1.7x1.7mm | C54313 |
| 1 | U8 | TPS61089RNR | Texas_VQFN-HR-11_2x2.5mm_P0.5mm_RNR0011A | C165129 |
| 1 | U_PWR | TPS22918DBVR | SOT-23-6 | C131941 |

## 3 · Audio

| Qty | Ref(s) | Part / MPN | Package | LCSC |
|----:|---|---|---|---|
| 5 | C5b,C_BAT_FILT,C_COMP,C_in_L,C_in_R | 0603B103K500NT | C_0603_1608Metric | C57112 |
| 3 | R_ILIM,R_VOL_L,R_VOL_R | 0603WAF1743T5E | R_0603_1608Metric | C22890 |
| 2 | C_HPVDD,C_HP_VDD | CL10A225KP8NNNC | C_0603_1608Metric | C1607 |
| 2 | FB1,FB2 | BLM18AG601SN1D | L_0603_1608Metric | C19330 |
| 2 | J8,J10 | PJ-320D (3.5mm TRS w/ switch) | Jack_3.5mm_PJ-320D_SMT | C431535 |
| 2 | R_LO_L,R_LO_R | 0603WAF220JT5E | R_0603_1608Metric | C23345 |
| 1 | U11 | TPA6132A2RTER | QFN-16-1EP_3x3mm_P0.5mm_EP1.7x1.7mm | C69901 |
| 1 | U3 | PCM5102APWR | TSSOP-20_4.4x6.5mm_P0.65mm | C107671 |
| 1 | U4 | PAM8406DR | SOIC-16_3.9x9.9mm_P1.27mm | C86270 |

## 4 · I/O expander + LEDs

| Qty | Ref(s) | Part / MPN | Package | LCSC |
|----:|---|---|---|---|
| 15 | R_LED6,R_LED7,R_LED8,R_LED9,R_LED10,R_LED11G,R_LED11Y,R_LED12G,R_LED12Y,R_LED13G,R_LED13Y,R_LED14G,R_LED14Y,R_LED15G,R_LED15Y | 0603WAF3900T5E | R_0603_1608Metric | C23151 |
| 6 | LED6,LED11Y,LED12Y,LED13Y,LED14Y,LED15Y | KT-0603Y (Hubei KENTO, yellow 0603, Vf 2.4V) | LED_0603_1608Metric | C2287 |
| 6 | LED7,LED11G,LED12G,LED13G,LED14G,LED15G | KT-0603G (Hubei KENTO, pure green 525nm 0603, Vf 3.1V) | LED_0603_1608Metric | C12624 |
| 3 | LED8,LED9,LED10 | XL-1608UWC-04 (warm-white 0603) | LED_0603_1608Metric | C965808 |
| 1 | LED_CHRG | XL-1608UOC-06 | LED_0603_1608Metric | C965800 |
| 1 | Q2 | 2N7002,215 | SOT-23 | C8545 |
| 1 | U2 | MCP23017-E/SS | SSOP-28_5.3x10.2mm_P0.65mm | C506653 |
| 1 | U6 | PCA9685PW,118 | TSSOP-28_4.4x9.7mm_P0.65mm | C2678753 |
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

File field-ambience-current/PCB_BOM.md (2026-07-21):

# PCB Production BOM — Field Ambience

**On-PCB parts only.** Everything here is soldered to the board. Off-board parts
(battery cell, speaker drivers, display module, knobs/caps,
enclosure) are in **§C** and are **NOT** part of the board assembly.

> Source of truth = the schematic (`kicad/generate_kicad_project.py`). Machine
> upload file = `kicad/jlc_bom.csv`. Detailed/rationale version (DE) =
> `BOM_MASTER.md`. No duplicate ref-designators; cross-checked against the
> generated sheets.

---
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

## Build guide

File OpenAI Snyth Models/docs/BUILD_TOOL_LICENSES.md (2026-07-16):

# Build-tool licenses

The firmware implementation in this package remains original C code and has no
runtime dependency on an external graphics library. Preview generation uses the
following separately installed development tools:

## Pillow

- Purpose: convert C-rendered and clean-room cinematic RGB frames into
  stable-palette animated GIFs, build labelled contact sheets, apply build-time
  blur/downsampling, and measure user-provided motion references without
  importing those references into firmware or generated assets.
- Distribution: Pillow itself is not copied into this repository or linked into
  device firmware.
- License: MIT-CMU.
- Copyright: Pillow contributors; PIL copyright holders as listed in Pillow's
  `LICENSE` file.
- Upstream license: <https://github.com/python-pillow/Pillow/blob/main/LICENSE>
- Format documentation:
  <https://pillow.readthedocs.io/en/stable/handbook/image-file-formats.html#gif>

The encoder uses documented `save_all`, `append_images`, duration, loop,
disposal, quantization, and palette options. Generated GIFs contain only this
project's original framebuffer geometry and palette data; no upstream example
artwork or source asset is embedded.

## NumPy

- Purpose: deterministic build-time gradient, vignette, exposure, and subtle
  static texture calculations for the cinematic master renderer.
- Distribution: NumPy itself is not copied into this repository or linked into
  device firmware.
- License: BSD 3-Clause.
- Copyright: NumPy Developers.
- Upstream license: <https://github.com/numpy/numpy/blob/main/LICENSE.txt>

No NumPy example image, dataset, or generated asset is embedded. The project
uses array arithmetic APIs only; all visual equations and constants are
project-authored.

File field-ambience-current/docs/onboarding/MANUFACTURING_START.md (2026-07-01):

# Manufacturing — Onboarding

## You can't order yet

Read [`PCB_LAYOUT_STATUS.md`](../../PCB_LAYOUT_STATUS.md). Current
production gate is **1.5 of 9**.

**Concretely:**
- ❌ No `.kicad_pcb` exists. No layout → no Gerbers → no order.
- ❌ No BOM CSV / no CPL / no Pick-and-Place file. They're outputs of layout, not inputs to it.
- 🟡 The schematic is done and verified (r18.6) but GUI-ERC hasn't been run yet (Blocker B3).
- 🟡 Several footprints carry `FP_VERIFY` properties — see status file.

## Production gates (9-gate model)

| Gate | What | Status |
|---|---|---|
| 0 | Concept defined | ✅ |
| 1 | Firmware/audio prototype validated | ✅ |
| 2 | Schematic ERC clean | 🟡 partial |
| 3 | BOM/footprints verified | 🟡 partial |
| 4 | PCB layout exists | ❌ |
| 5 | DRC clean | ❌ |
| 6 | Gerbers/BOM/CPL generated | ❌ |
| 7 | Prototype ordered | ❌ |
| 8 | Bring-up test passed | ❌ |
| 9 | Production candidate | ❌ |

## What's blocking gate progression

| Gate | Blocker | Owner |
|---|---|---|
| 2 → ✅ | Run ERC in KiCad 9 GUI, close real errors, accept intentional warnings per [`ERC_DRC_CHECKLIST.md`](../hardware/ERC_DRC_CHECKLIST.md) | hardware engineer |
| 3 → ✅ | Close ~10 `FP_VERIFY` properties (footprint-land-pattern matches manufacturer drawing) | hardware engineer |
| 4 | **Phase-5-Profiling first**: prove the audio engine fits the STM32H743 budget on real hardware before investing in layout | firmware engineer |
| 4 | Resolve ADR-0004 (MIDI) — DNP or fully designed | industrial designer + hardware |
| 5-9 | (Sequential, after layout) | hardware + manufacturing partner |

## The "talk to the fab" file (when we get to gate 6)

JLC PCB capabilities (4-layer): JLC07101H-3313A
- Min trace: 0.127 mm (5 mil)
- Min spacing: 0.127 mm (5 mil)
- Min via: 0.3 mm with 0.15 mm hole
- Outer copper: 1 oz
- Stack-up: Sig / GND / +5V / Sig (per spec §9)

JLC assembly considerations (when we get to gate 7):
- BOM CSV from KiCad (LCSC field is the primary key)
- CPL: position, rotation, side
- Some parts are Basic (no setup fee), most are Extended (setup fee — minimize unique part count)
- Custom-footprint parts (the HX 12×12 button, the Kailh Choc cell keyswitch) need pad checks
- Cell keyswitches (SW1–5, Kailh Choc V1, C400229) and modifier buttons (SW6–10, HX B3F) are THT — hand-placed/soldered after JLC's SMD reflow pass, not part of the automated SMT population (r18.75; direct-solder, no hot-swap socket anymore)

## When you'd come back to this file

- Once `.kicad_pcb` exists
- Once ERC and DRC are both clean
- Once the Phase-5-Profiling gate passes
- Once ADR-0004 is closed

Until then, this file is the answer to "can we order?" — and that answer is no.

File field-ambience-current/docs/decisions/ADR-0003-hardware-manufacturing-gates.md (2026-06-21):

# ADR-0003: Hardware Manufacturing Gates (9-Gate Model)

**Status:** ACCEPTED
**Date:** 2026-06-11

## Context

"Are we ready to order?" is the question with the most lying-to-yourself
potential in hardware development. A schematic that compiles, a BOM with
LCSC numbers, and a few verified parts can look like progress — but if
there's no PCB layout, no DRC pass, no bring-up test, you're not
manufacturing-ready. You're at gate 2 of 9.

We need a shared 9-gate vocabulary so anyone asking can be answered in
one number, and so anyone documenting work knows which gate they're
unblocking.

## Decision

Adopt a 9-gate model:

| Gate | Name | Definition |
|---|---|---|
| 0 | Concept defined | Pitch + interaction model + sound-design intent locked |
| 1 | Firmware/audio prototype validated | Engine runs end-to-end on bench; host tests green |
| 2 | Schematic ERC clean | KiCad-GUI ERC: 0 errors, only intentional warnings |
| 3 | BOM/footprints verified | Every part has MPN+LCSC+footprint verified against manufacturer drawing |
| 4 | PCB layout exists | `.kicad_pcb` with routing, mounting holes, board outline |
| 5 | DRC clean | KiCad-GUI DRC with JLC-4-layer profile: 0 errors |
| 6 | Gerbers/BOM/CPL generated | All fab outputs created from layout, stored in `manufacturing/` |
| 7 | Prototype ordered | At least one batch of boards on the way from the fab |
| 8 | Bring-up test passed | First board powers up, runs firmware, audio out works |
| 9 | Production candidate | Multiple boards built; field-test passed; ready for batch production |

## Rules

- **You report the lowest non-✅ gate** — not the highest gate you've started work on.
- **Anyone can read the gate number** from `PROJECT_MAP.md` / `PROJECT_STATUS.md`.
- **No skipping gates.** "Gate 4 done, gate 3 partial" means current state is Gate 3, not Gate 4.
- **Half-credit is "X.5"** — e.g. "1.5 of 9" means gate 1 complete + meaningful progress on gate 2.
- ~~**Phase-5 profiling acceptance is a precondition for gate 4**~~ — ADR-0005 hat das aufgehoben (User-Entscheidung 2026-06-11). Layout darf vor Profiling starten; Firmware-Migration läuft parallel statt sequenziell.

## Consequences

**Positive:**
- One number that everyone interprets the same way. No more "we're almost ready" without a definition of "ready."
- Honest status in README/PROJECT_MAP. No one orders prematurely.
- The gates correspond roughly to natural review checkpoints — easy to map to PRs and milestones.

**Negative:**
- Some people will want sub-states ("gate 3a, 3b, 3c"). Keep it flat — sub-states make the model performative again.
- The 9-gate scheme is project-specific; team members from other projects may bring different mental models. Doc up front.

## Current state at adoption

**Gate 1.5 of 9.**

- ✅ Gate 0: concept locked (PITCH + ADR-0002 + ADR-0004 in progress)
- ✅ Gate 1: bench bring-up works, 8-minute performance render
- 🟡 Gate 2: schematic verified r18.6, GUI-ERC pending (B3)
- 🟡 Gate 3: main parts verified, ~10 FP_VERIFY properties open
- ❌ Gate 4+: no layout

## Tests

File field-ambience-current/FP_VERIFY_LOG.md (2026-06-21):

# Footprint-Verifikations-Log

**Stand: r18.14 (2026-06-12)**

Stand der `FP_VERIFY`/`FP_NOTE`-Properties an den im Schematic platzierten Symbolen. Die Quelle für jeden Eintrag ist im Generator-Code dokumentiert; bei Custom-Footprints liegt das `.kicad_mod` in `kicad/libraries/field_ambience.pretty/`, 3D-STEP-Modelle in `kicad/libraries/field_ambience.3dshapes/` (siehe `mechanical/3d_models/MANIFEST.md`).

## Zusammenfassung

| Status | Anzahl |
|---|---|
| ✅ Verifiziert (KiCad-Standard, Source quoted) | 5 |
| ✅ Custom-FP nach Hersteller-/EasyEDA-Daten erstellt | 5 |
| 🟡 Offen (echte FP-Verify nötig) | 0 — EC11J-Blocker in r18.14 aufgelöst (Teil retired, ADR-0012) |

## Verifikations-Details

### ✅ U1 STM32H743VIT6 — LQFP-100
- **FP:** `Package_QFP:LQFP-100_14x14mm_P0.5mm` (KiCad-Standard)
- **Quelle:** kicad-footprints@master Package_QFP.pretty/LQFP-100_14x14mm_P0.5mm.kicad_mod
- **Verifiziert:** 100 Pads, Side-Pads 1.6 × 0.3 mm @ 0.5 mm Pitch, JEDEC MS-026 / IPC-7351-konform. Pin 1 (-7.675, -6); Pin 26 (-6, 7.675). Courtyard ±8.73 mm.
- **2026-06-11**: über gitlab.com/kicad/libraries/kicad-footprints offizieller Raw-Inhalt geprüft.

### ✅ U5 AP7361C-33Y5-13 — SOT-89-5
- **FP:** `Package_TO_SOT_SMD:SOT-89-5` (KiCad-Standard)
- **Quelle:** kicad-footprints@master Package_TO_SOT_SMD.pretty/SOT-89-5.kicad_mod
- **Verifiziert:** 5 Pads, Pin 2 (Tab, 0.8 × 2 mm @ origin), Pins 1/3/4/5 (1.5 × 0.7 mm @ ±1.85 X, ±1.5 Y). JEDEC TO-243.
- **Pinout (vom User aus Diodes-DS bestätigt):** 1=EN, 2=GND/Tab, 3=ADJ/NC, 4=IN, 5=OUT. Symbol matched.
- **2026-06-11**: offizieller Raw-Inhalt geprüft.

### ✅ U8 TPS61089RNR — Texas RNR0011A VQFN-HR-11
- **FP:** `field_ambience:Texas_VQFN-HR-11_2x2.5mm_P0.5mm_RNR0011A` (Custom)
- **Quelle:** TI Mechanical Drawing 4222143/A 08/2015 (eingebettet in TPS61089 Rev C Datasheet)
- **Custom-FP-Daten:**
  - 8× Side-Pads 0.25 × 0.55 mm @ 0.5 mm Pitch (Pins 1-4, 7-10)
  - 2× Enlarged EP-Side-Pads 0.55 × 0.7 mm (Pins 5 GND, 6 VOUT)
  - 1× Central Thermal Pad 1.5 × 0.7 mm (Pin 11 SW — **kein separates ePAD**, das war ein Symbol-Bug aus r12-B11; in r18.7 korrigiert)
- **2026-06-11**: TI-PDF-Stream-Extraktion (PACKAGE OUTLINE + LAND PATTERN EXAMPLE)
- **Hinweis:** Pin-1-Index-Orientierung im Custom-FP folgt TI-Standard (upper-left); vor Layout in KiCad-GUI visuell gegen Datasheet Pin Configuration Diagram prüfen.

### ✅ Y1 ABLS-8.000MHZ-B4-T — HC-49/US SMD
- **FP:** `field_ambience:Crystal_HC49-US-SMD_ABLS` (Custom)
- **Quelle:** ABRACON ABLS Datasheet Drawing 450669 Rev AD Page 3
- **Custom-FP-Daten:** 2× Pads 5.6 × 2.1 mm @ 9.5 mm Pitch (ABRACON-Empfehlung; KiCad-Standard `Crystal_SMD_HC49-SD` hat nur 4.5×2.0 mm @ 8.5 mm)
- **Body:** 11.4 × 4.7 mm
- **2026-06-11**: Custom-FP nach ABLS-Spec erstellt. KiCad-Standard war konservativer, hätte funktioniert, aber unter ABRACON-Empfehlung.

### ✅ SW6-SW10 HX 12×12×7.3 TPFT-B — SMD-4P
- **FP:** `field_ambience:SW_HX_12x12x7.3_SMD-4P` (Custom)
- **Quelle:** LCSC C36498966 / EasyEDA-User-verifizierte Datenblätter
- **Custom-FP-Daten:** 4× Pads 2.5 × 1.5 mm auf 7 mm-Pitch (X+Y), SPST (gegenüberliegende Pads verbunden 1↔1, 2↔2)
- **Body:** 11.8 × 11.8 mm, Höhe 7.3 mm
- **2026-06-11**: nach LCSC-Datenblatt erstellt (r18.6).

### ✅ J3 ST7789 LCD-Header — PinHeader_1×08 2.54 mm
- **FP:** `Connector_PinHeader_2.54mm:PinHeader_1x08_P2.54mm_Vertical` (KiCad-Standard)
- **Verifiziert:** trivialer Standard, alle 2.54 mm-Single-Row-Header sind identisch. Adafruit 5394 (ST7789 1.9″) hat 2.54 mm-Pinraster auf 8 Pins (Vin/GND/SCK/MOSI/TCS/DC/RES/Lite — alle anderen Pins sind über separaten SD-Header).

### ✅ Q2 2N7002 — SOT-23
- **FP:** `Package_TO_SOT_SMD:SOT-23` (KiCad-Standard)
- **Pinout (JEDEC TO-236):** Pin 1=G, Pin 2=S, Pin 3=D — alle Hersteller-Marken (Nexperia, Diodes, On Semi) identisch. Verbaut: Nexperia 2N7002,215 / LCSC C8545.

### ✅ EN1-EN4 — ALPS EC11E THT (r18.14, ADR-0012; ersetzt EC11J SMD)
- **FP:** `Rotary_Encoder:RotaryEncoder_Alps_EC11E-Switch_Vertical_H20mm` (KiCad-Standard) für **alle 4** — jetzt passend, weil die Teile selbst auf EC11**E** THT gewechselt sind
- **Varianten:** EN3 = EC11E mit Push+Detents (Suffix TBD-VERIFY); EN1/2/4 = EC11E183440C (smooth, ohne Switch — S1/S2-Löcher bleiben leer, gleiche Land-Pattern-Familie)
- **Der frühere 🟡-Blocker (EC11J-SMD-Land-Pattern) ist damit GEGENSTANDSLOS.** Zusätzlich wurde das echte EC11J-Pattern via EasyEDA-Export (C209762) doch noch beschafft und als Referenz in die Project-Lib gelegt — der r18.12-Hand-Draft war nachweislich falsch (Pitch 2.54 statt 2.5, Pad-Reihen ±7.0/7.3 statt ±5.0, Body 15×18 statt 12×13.4). Lehre: Custom-FPs nur noch aus CAD-Exporten, nicht aus Prosa-Maßen.
- **3D:** `SW-SMD_EC11J1525402-...-H24.5-P2.5.step` belegt 24.5 mm Gesamthöhe → einer der drei Retire-Gründe (ADR-0012).

### ✅ SW11/SW_BOOT TS-1088-AR02016 — Mini-SMD-Tactile (r18.14)
- **FP:** `field_ambience:SW_TS1088_SMD` (Custom, aus EasyEDA-Export C720477)
- **Korrektur:** C720477 ist XUNPU **TS-1088-AR02016** (SW_BOOT-Property sagte fälschlich TS-1185A-C-A). Vorher generisches `SW_SPST_TL3342`-FP — Land-Pattern passte nicht (TS-1088 ist 3.9×2.9, 2-Pad @ 4.36 mm).

### ✅ J1 TYPE-C-31-M-17 — LCSC-Nr.-Korrektur (r18.14)
- **FP:** `Connector_USB:USB_C_Receptacle_HRO_TYPE-C-31-M-12` (unverändert, drop-in)
- **Befund:** BOM-LCSC-Nr. C165935 war ein STF18N65M5-MOSFET — beim 3D-Abruf entdeckt (STEP war ein TO-220F-3!). Korrigiert auf **C283540** (LCSC-verifiziert). 3D: `TYPE-C-SMD_6P-...-H3.2-P1.00.step`.

## Was im Code geändert wurde

In `generate_kicad_project.py` werden `FP_VERIFY`-Properties durch `FP_NOTE`-Properties ersetzt, sobald die Verifikation positiv ist. Im Schematic sieht man:
- `FP_VERIFY` = noch nicht verifiziert, vor Layout zu schließen
- `FP_NOTE` = verifiziert, mit Quelle dokumentiert
- `FP_MISMATCH` = nicht mehr verwendet (war für HX 12×12, durch Custom-FP gelöst)

## Custom-Footprints in der Project-Lib

Alle 6 in `kicad/libraries/field_ambience.pretty/`:

```
SW_HX_12x12x7.3_SMD-4P.kicad_mod                  HX 12×12 Tactile (5 Plätze)
Crystal_HC49-US-SMD_ABLS.kicad_mod                Y1 HSE-Crystal (1 Platz)
Texas_VQFN-HR-11_2x2.5mm_P0.5mm_RNR0011A.kicad_mod  TPS61089RNR Boost (1 Platz)
SW_TS1088_SMD.kicad_mod                           SW11 + SW_BOOT (EasyEDA-verifiziert, r18.14)
Jack_3.5mm_PJ-320D_SMT.kicad_mod                  J8/J9 Audio+MIDI-Klinke (EasyEDA-verifiziert, r18.19)
L_Sunlord_SWPA6045.kicad_mod                      L1 Boost-Inductor 2.2µH (EasyEDA-verifiziert r18.20c — Phantom-Name L_0630 ersetzt)
```

3D-STEP-Modelle (Z-/Panel-kritische Teile) in
`kicad/libraries/field_ambience.3dshapes/` — 7 STEPs (U1, Y1, U8, L1, J_BAT,
J8, SW11/SW_BOOT). Z-Höhen-Tabelle + Regenerier-Kommando in
`mechanical/3d_models/MANIFEST.md` (Repo-Root, nicht unter
`field-ambience-current/`).

r18.36: Footprint `RotaryEncoder_ALPS_EC11J_SMD.kicad_mod` entfernt
(unreferenzierte Leiche — EN1–4 nutzen seit ADR-0012 KiCad-Standard
`Rotary_Encoder:RotaryEncoder_Alps_EC11E-Switch_Vertical_H20mm`).

`fp-lib-table` referenziert `${KIPRJMOD}/libraries/field_ambience.pretty`.

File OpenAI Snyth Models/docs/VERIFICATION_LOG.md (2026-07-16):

# Verification log — 2026-07-16

## Final clean host run

- Strict C11 compilation with `-Wall -Wextra -Wpedantic -Wshadow
  -Wconversion -Werror`: passed.
- Functional/property verification: **2,211,898 checks, 0 failures**.
- AddressSanitizer + UndefinedBehaviorSanitizer: passed. Leak detection is
  disabled because the execution container does not support LeakSanitizer;
  the real-time implementation performs no allocation.
- Clean-origin implementation audit: passed.
- Preview signal-health gate: passed for all ten models.
- Artifact gate: ten stereo MP3s, 56 GIFs, 56 matching stills, five overview
  PNGs, and ten cinematic all-frame sheets at the expected formats and geometry.
- Colour gate: all fifteen studies contain 96 animation frames, at least twelve
  visible colours, a neon-accent saturation ratio of at least 65%, and less
  than 5 RGB levels mean drift between GIF midpoint and lossless PNG.
- Motion gate: all 26 new studies contain exactly 96 frames, animate across
  sampled frames, pass the same neon/fidelity gates, have distinct first
  frames, and remain below the loop-seam limit.
- Cinematic gate: all ten masters contain exactly 48 native-size frames,
  preserve effect-specific timing, animate, close their loops within the
  authored transition envelope, retain negative space and mid-level light
  volume, and keep each lossless still close to a decoded GIF frame. All ten
  passed; each has 28–48 distinct decoded frames, with ELECTRIC SCRIPT's lower
  count caused by intentional stepped holds.
- Deterministic regeneration: rendering all 480 cinematic frames twice
  produced identical SHA-256 hashes for every GIF, still, frame sheet, and the
  overview contact sheet.

## Measured static state

| Item | Measured | Budget | Margin |
|---|---:|---:|---:|
| audio context | 27,488 B | 32,768 B | 5,280 B |
| visual context | 1,444 B | 2,048 B | 604 B |
| packed 320 × 170 framebuffer | 27,200 B | existing buffer | — |
| animated RGB565 palette LUT | 32 B | 32 B | 0 B |
| additional framebuffer | 0 B | 0 B | 0 B |

The twelve palettes were additionally checked for RGB565 uniqueness, animated
state change, visible range, monotonically increasing luminance by nibble
index, and strong tone-14 chroma at quiet and peak phases. This preserves the
renderer's maximum-tone blending semantics without washing the bright body to
white.

## Relative host benchmark

Five seconds of four-note audio per model were rendered on the CI host. The
slowest result was TIDEGLASS at **91.08× real time** and the fastest was GLASS
ORBIT at **337.68× real time**. These numbers are useful only for host
regression; they are not a target-MCU cycle claim.

All eighteen visual systems were also benchmarked for 360 frames on the review
host. The slowest was DREAM TOPOGRAPHY at **58.7 µs/frame**; the new modes did
not exceed it. This is likewise only a host regression baseline.

## Tooling limitation

The Make build was fully exercised. A parallel CMake definition is supplied,
but the recovery environment did not contain a `cmake` executable, so that
generator was not run here. Target integration and DMA-deadline verification
remain hardware release gates.

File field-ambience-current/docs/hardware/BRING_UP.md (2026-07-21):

# Hardware Bring-Up Runbook — Field Ambience Prototyp

Systematischer Erst-Einschalt-Plan für die 5 Prototyp-Boards. **Reihenfolge
ist Sicherheit** — jede Stufe erst freigeben, wenn die vorige besteht. Nie
den MCU in einen kurzgeschlossenen Rail booten, nie den Speaker vor dem
Line-out testen.

> Quelle der Wahrheit für Pins/Nets: `PINMAP.md`, `bom_overview.html`,
> `SCHEMATIC_WALKTHROUGH.md`. Firmware-Boot: `src/hal_h743/main_h743.c`.

## Sicherheits-Grundregeln
- **Strombegrenzt einschalten** (Labornetzteil oder USB-Meter mit Limit).
  Steigt der Strom schlagartig → sofort trennen, Kurzschluss suchen.
- **Line-out (J8) vor Speaker** testen. Speaker leise anfangen.
- **Akku-Polung** vor dem ersten Stecken prüfen: **Pad 1 = + (BAT_PLUS)**
  (verifiziert r19.2) — Multimeter am Adafruit-Stecker, siehe
  `SOURCING_COMPLIANCE.md §2`. Verpolung tötet Boost + Charger sofort.
- Erst USB-Pfad, dann Akku-Pfad — nie beim ersten Mal beides gleichzeitig.

## Schnellreferenz
| Rail | Soll | Woher |
|---|---|---|
| `VBUS_FUSED` (USB) | ~5,0 V | VBUS → F1 (TP: TP_VBUS ist PRE-fuse `VBUS_USBC`) |
| `VSYS` (USB, TP_VSYS) | ~4,4 V | BQ24074 OUT-Regulation (DPPM) |
| `VSYS` (Akku) | = VBAT (3,0–4,2 V) | BQ24074 BAT-FET |
| `+5V_RAIL` (ON) | ~4,6–4,7 V | TPS61089 Boost 4,97 V − D3-Drop |
| `+5V_RAIL` (OFF) | ~3–3,7 V **unreguliert** | Boost-Body-Diode + D3 — KEIN Fehler (TPS61089 hat kein Output-Disconnect, ADR-0023) |
| `+5V_SW` | = +5V_RAIL (nur ON) | TPS22918 U_PWR, geschaltet von SW_PWR |
| `+3V3` | 3,30 V | AP7361C LDO (ganze 3V3-Domäne) |

| I²C @ 400 kHz | Adresse |
|---|---|
| MCP23017 (Cells GPA0-4, XSMT GPA5, Jack GPA6) | **0x20** |
| PCA9685 U6 (15 LEDs + Backlight) | **0x40** |

| Debug | Pin |
|---|---|
| SWD J4 (DNP-Pads 1×3 1,27 mm — Header/Litzen von Hand, r19.18) | SWDIO PA13 · SWCLK PA14 · SWO PB3 |
| NRST | Pin 14 (SW11 + 10k PU + 100 nF) |
| BOOT0 | Pin 94 (SW_BOOT + Pull-**down** → Flash-Boot) |
| HSE | Y1 8 MHz Crystal |

---

## Stufe 0 — Vor dem Strom (Ohmmeter, unbestromt)
- Sichtprüfung: Bestückung vollständig, Polung von Elkos/Dioden/USB-C/JST,
  keine Lötbrücken (besonders unter dem LQFP-100 + den QFN/SOT-Reglern).
- **Kurzschluss-Check** (Ohmmeter gegen GND, muss NICHT ~0 Ω sein):
  `VBUS_FUSED`, `VSYS`, `+5V_RAIL`, `+5V_SW`, `+3V3`, `BAT_PLUS`.
- SW_PWR in **OFF**. Akku **nicht** gesteckt.

## Stufe 1 — USB an, Gerät AUS (strombegrenzt)
- USB-C rein, Limit ~200 mA. Erwartung (SW_PWR off, PWR_ON per 100k PD low):
  - `VBUS_FUSED` ≈ 5,0 V; `VSYS` (TP_VSYS) ≈ **4,4 V** (BQ24074-OUT-Regulation — der wichtigste Messpunkt).
  - `+5V_RAIL` ≈ 3,4–3,7 V unreguliert (Body-Dioden-Leck, Boost aus) — normal.
  - `+5V_SW` = 0 V, `+3V3` = **0 V** (LDO aus — Load-Switch sperrt).
  - Charger BQ24074 aktiv; **mit** Akku leuchtet LED_CHRG (CHG open-drain),
    **ohne** Akku zyklt die Battery-Detection (LED kann blinken/aus sein — normal).
  - Ruhestrom klein, **kein Bauteil warm**. Wird etwas heiß → trennen.

## Stufe 2 — Power-On (SW_PWR ON)
- SW_PWR → ON: PWR_ON high → TPS22918 durch → AP7361C → 3V3-Domäne.
- Messen: `+5V_SW` ≈ +5V_RAIL; **`+3V3` = 3,30 V ±3 %**. Ripple sauber.
- LDO-Temperatur beobachten (~1,5–2,2 W, **kein Lüfter** — Kupfer + Vias
  müssen die Wärme tragen).
- Bei Fehler: LDO-Enable/Eingang, TPS22918 ON-Pin (PWR_ON), SW_PWR-Kontakte
  durchklingeln (r18.85: physisches Teil vor Fab prüfen).

## Stufe 3 — Akku- + Boost-Pfad
- USB trennen. Akku stecken (**Polung!**). SW_PWR ON.
- Boost TPS61089: `BAT_PLUS` 3,7 V → `+5V_RAIL` ≈ **4,97 V**, unter Last
  stabil (r18.80: Loop-Comp gefixt — kein Oszillieren). Mit Scope auf Ripple/
  Schwingen prüfen.
- USB wieder dazu: Charger lädt (STAT-LED orange) **während** der Boost
  läuft — Akkubetrieb + Laden gleichzeitig ist Absicht (ADR-0016).

## Stufe 4 — MCU-Lebenszeichen (SWD, noch keine Firmware)
- Tag-Connect TC2030 an J4, ST-Link/Debugger.
- **MCU-ID lesen** (STM32H743 erkennen). Nur ob der Kern antwortet.
- Bei „not found": `+3V3` am MCU, **NRST high** (SW11 nicht gedrückt),
  **BOOT0 LOW** (für Flash-Boot — verpolter Pull würde in den System-
  Bootloader booten; PINMAP sagt Pull-down, gegen das reale Board prüfen),
  HSE-Crystal (8 MHz) schwingt.

## Stufe 5 — Firmware flashen + Boot
- `field_ambience_h743.bin`/`.hex` via SWD flashen.
- Boot (`main_h743.c`): Caches → Clock 480 MHz (PLL3 → SAI 44,1 kHz) →
  OLED-Splash → mcp/enc → dsp/brain/engine → audio.
- **Erwartung: Display zeigt das Menü** (World-Slot). Schwarz? → SPI/J3-
  **Pin-Order** (per Kabel Draht-für-Draht, s. Sourcing-Doc), Backlight (Q2/
  LCD_BLK_PWM), 3V3 am Modul.
- **Async-DMA-Flush validieren (r19.12):** `oled_show_async()` streamt den
  Framebuffer per SPI1-TX-DMA (DMA2_Stream3, Prio 6) zeilen-pipelined, damit
  der Main-Loop während der ~29 ms nicht mehr blockiert. **Bench-Check:** Bild
  sauber/vollständig, kein Tearing/Sparkle/versetzte Zeilen, kein
  abgeschnittenes letztes Byte (CS-High im TxCplt). **Wenn es zickt**
  (Zeilen-Re-Enable-Glitch, CS-Timing): Fallback = im Refresh-Block von
  `main_h743.c` `oled_show_async()` → `oled_show()` (blocking, bewährt)
  tauschen — eine Zeile, sonst identisch. Alternativ Zeilen zu Chunks bündeln
  (weniger DMA-Re-Enables). Der Konverter (`oled_convert_row`) ist
  host-getestet; nur DMA-/Panel-Timing ist hier offen.

## Stufe 6 — I²C-Bus
- I²C-Scan: **0x20** (MCP23017) + **0x40** (PCA9685 U6) müssen ACKen.
- Fehlt eins: SDA/SCL-Pull-ups, Verdrahtung, 3V3 am IC.
- PCA9685 treibt die 15 Status-LEDs + Backlight — beim Boot ansprechbar.

## Stufe 7 — Eingaben
- **Cells** (Kailh Choc, GPA0-4): drücken → MCP-INT → LED + Ton-Trigger.
- **Modifier** (GPB): DRONE · HOLD · SHIFT · GENERATE · CLEAR.
- **4 Encoder** (EC11): drehen → Menü-Nav / DRIVE / BRIGHT / VOLUME; Push.

## Stufe 8 — Audio (die Mute-Sequenz ist heikel)
- **Line-out J8 zuerst** (Scope/Kopfhörer). SAI1 (PE4 LRCK / PE5 BCK /
  PE6 DOUT) → PCM5102A → J8. Ton sauber?
- Mute-Reihenfolge (SPEC §8.3): beim Start `/SHDN` (PB14) → `/MUTE` (PB15)
  → `XSMT` (MCP GPA5) lösen; beim Stop rückwärts. Kein Pop.
- **Jack-Detect** (MCP GPA6): Klinke rein → PAM8403 gemutet (Speaker aus),
  Line-out bleibt live. Raus → Speaker an.
- **Speaker (PAM8403) zuletzt**, leise anfangen.

## Stufe 9 — Batterie-UI + Laden
- `BAT_SENSE` (PA3, 100k:100k): Menü zeigt Akkustand plausibel.
- USB rein → USB-Glyph + Laden. SW_PWR off → 3V3 weg, **Charger lädt
  weiter** (ADR-0016).

## Stufe 10 — Abnahme
- Alle 4 Welten, alle 11 Menü-Slots, GENERATE-Autoplay.
- **Dauerlauf** ein paar Minuten: Temperatur (LDO/Boost), Stabilität, in
  Stille keine CPU-/Audio-Spikes (FTZ ist an — sollte sauber sein).
- Line-out + Speaker gegen die Host-Demos gegenhören.
- **WCET-/Block-Size-Sweep (P0.2):** das Worst-Case-Szenario aus
  `test/test_blocksize_sweep.c` (Drone + alle FX max + Trigger-Storm) auf dem
  Board fahren und pro Blockgröße (512→256→128→64) `audio_profiler_state()`
  auslesen: **`max_cycles`, `deadline_miss_count`, `clip_count`**. Gate
  (REALTIME_AUDIO_RULES §1): `peak_load < 0,60`, `deadline_miss_count == 0`.
  Host-seitig ist die Szene bereits als **stabil + bounded + 0 % Clipping bei
  jeder Blockgröße** verifiziert — offen ist nur die echte Zyklenzahl. Erst
  wenn 128 (oder 64) die Deadline hält, `AUDIO_BUFFER_FRAMES` senken.

---

## Wenn eine Stufe fehlschlägt
Nicht weiter — erst die Stufe grün. Häufige Erstfehler bei diesem Design:
- **3V3 fehlt trotz SW_PWR ON** → TPS22918 PWR_ON-Pfad / SW_PWR-Kontakt.
- **Boost schwingt** → sollte mit r18.80-Comp gefixt sein; Bestückung der
  Comp-R/C prüfen.
- **Display schwarz** → J3-Pin-Order (Vendor-Variation, per Kabel gemappt).
- **I²C tot** → Pull-ups / ein IC ohne 3V3.
- **Audio-Pop** → Mute-Sequenz-Reihenfolge in der Firmware vs Hardware.
- **Kein SWD** → BOOT0-Pegel / NRST / Crystal.

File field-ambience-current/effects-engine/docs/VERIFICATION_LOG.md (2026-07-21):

# Verification log

## Effects-engine host run — 2026-07-20

- Strict C11 compilation with `-Wall -Wextra -Wpedantic -Wshadow
  -Wconversion -Werror`: passed.
- Effects functional/property verification: **478,857 checks, 0 failures**.
- Existing synthesis/visual verification after linking the new module:
  **2,211,898 checks, 0 failures**.
- Effects AddressSanitizer + UndefinedBehaviorSanitizer run: passed.
- Bit-exact bypass, exact block-partition invariance, arena guards, ping-pong
  timing, long-tail survival, reverse pre-tail alignment, all-mode bounds, and
  randomized control stress: passed.
- Measured effects state: **680 B / 4,096 B**.
- Measured default hot arena requirement: **214,489 B / 245,760 B**, including
  alignment allowance.
- Host DREAM CHAIN benchmark: approximately **95.0× real time** for 512-frame
  blocks. This is a relative regression result, not an STM32 cycle claim.
- Ten deterministic PCM16 WAV demonstrations were rendered: dry, each
  individual effect, full DREAM CHAIN, and true look-ahead reverse reverb.

Target linker placement, DWT cycle capture, cache behavior, codec path, and a
multi-hour no-underrun soak remain mandatory before product release.

## Original package host run — 2026-07-16

## Final clean host run

- Strict C11 compilation with `-Wall -Wextra -Wpedantic -Wshadow
  -Wconversion -Werror`: passed.
- Functional/property verification: **2,211,898 checks, 0 failures**.
- AddressSanitizer + UndefinedBehaviorSanitizer: passed. Leak detection is
  disabled because the execution container does not support LeakSanitizer;
  the real-time implementation performs no allocation.
- Clean-origin implementation audit: passed.
- Preview signal-health gate: passed for all ten models.
- Artifact gate: ten stereo MP3s, 56 GIFs, 56 matching stills, five overview
  PNGs, and ten cinematic all-frame sheets at the expected formats and geometry.
- Colour gate: all fifteen studies contain 96 animation frames, at least twelve
  visible colours, a neon-accent saturation ratio of at least 65%, and less
  than 5 RGB levels mean drift between GIF midpoint and lossless PNG.
- Motion gate: all 26 new studies contain exactly 96 frames, animate across
  sampled frames, pass the same neon/fidelity gates, have distinct first
  frames, and remain below the loop-seam limit.
- Cinematic gate: all ten masters contain exactly 48 native-size frames,
  preserve effect-specific timing, animate, close their loops within the
  authored transition envelope, retain negative space and mid-level light
  volume, and keep each lossless still close to a decoded GIF frame. All ten
  passed; each has 28–48 distinct decoded frames, with ELECTRIC SCRIPT's lower
  count caused by intentional stepped holds.
- Deterministic regeneration: rendering all 480 cinematic frames twice
  produced identical SHA-256 hashes for every GIF, still, frame sheet, and the
  overview contact sheet.

## Measured static state

| Item | Measured | Budget | Margin |
|---|---:|---:|---:|
| audio context | 27,488 B | 32,768 B | 5,280 B |
| visual context | 1,444 B | 2,048 B | 604 B |
| packed 320 × 170 framebuffer | 27,200 B | existing buffer | — |
| animated RGB565 palette LUT | 32 B | 32 B | 0 B |
| additional framebuffer | 0 B | 0 B | 0 B |

The twelve palettes were additionally checked for RGB565 uniqueness, animated
state change, visible range, monotonically increasing luminance by nibble
index, and strong tone-14 chroma at quiet and peak phases. This preserves the
renderer's maximum-tone blending semantics without washing the bright body to
white.

## Relative host benchmark

Five seconds of four-note audio per model were rendered on the CI host. The
slowest result was TIDEGLASS at **91.08× real time** and the fastest was GLASS
ORBIT at **337.68× real time**. These numbers are useful only for host
regression; they are not a target-MCU cycle claim.

All eighteen visual systems were also benchmarked for 360 frames on the review
host. The slowest was DREAM TOPOGRAPHY at **58.7 µs/frame**; the new modes did
not exceed it. This is likewise only a host regression baseline.

## Tooling limitation

The Make build was fully exercised. A parallel CMake definition is supplied,
but the recovery environment did not contain a `cmake` executable, so that
generator was not run here. Target integration and DMA-deadline verification
remain hardware release gates.

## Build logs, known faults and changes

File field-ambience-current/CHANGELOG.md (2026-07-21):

# Field Ambience PCB — CHANGELOG

Vollständige Änderungshistorie der PCB-Spec und des KiCad-Schematic.
Die Spec-Body selbst (`field_ambience_pcb_SPEC_v0.7.md`) beschreibt
**immer den aktuellen Stand** — diese Datei trackt wie wir dahin kamen.

Aktuelle Rev: **v0.7-r18.30** (Firmware-Ausbau Teil 3: leds.c (16. Suite),
Menü-Encoder-Binding, MIDI deferred. Firmware-LOGIK komplett + verdrahtet.
KEIN .kicad_pcb.)

---

## v0.7-r19.25 (2026-07-15) — Gesten-Schleife statt Audio-Looper (Bedienlogik Runde 6, Abschluss)

HiChord/Orchid haben grosse Audio-Looper — wir bauen bewusst etwas
Eigenstaendigeres. NEU gesture.c: nimmt CELL-EREIGNISSE auf (Druck/Loslassen
mit Zeitstempel, KEIN Audio) und wiederholt die gespielten Zellen ueber das
AKTUELL geladene World + Klang + Zellmodus.

- **SHIFT+HOLD** zykelt IDLE→REC→PLAY→IDLE. (Mischis Vorschlag war
  SHIFT+GENERATE — das ist seit r19.24 "New Field", daher SHIFT+HOLD.)
  Die **HOLD-LED pulsiert** waehrend REC, leuchtet ruhig in PLAY. Overlay
  zeigt REC/LOOP/OFF. CLEAR (voll) stoppt + leert die Schleife ebenfalls.
- Wiedergabe laeuft durch dieselbe route_cell-Logik wie das Live-Spiel —
  eine geloopte Zelle verhaelt sich exakt wie eine gedrueckte (Note/Bloom/
  Generate-Steer). Beim Loop-Umbruch werden offene Stimmen freigegeben
  (keine Haenger).
- **Sehr wenig RAM** (128 Events × 6 B ≈ 0,75 KB), kein PSRAM, control-rate
  (Main-Loop, nicht Audio-ISR). Grenze v1: nur Zell-Gesten — Encoder-/
  World-/Modifier-Aufnahme bewusst ausgeklammert; die Schleife spielt ueber
  das LIVE-Setup (RAM-arm, deckt "wiederholt mit dem aktuell geladenen
  World und Klang").

Refactor: die Zell-Routing-Logik ist jetzt EINE Funktion (route_cell),
geteilt von physischen Buttons + Gesten-Wiedergabe.

Tests: **NEU test_gesture.c** (14 Checks: Zustandszyklus, Aufnahme nur in
REC, phasenrichtige Wiedergabe, Loop-Umbruch gibt Stimmen frei, CLEAR/leer-
REC-Kollaps). 37 Suiten gruen; H743-Cross-Build gruen (210 KB Flash).

**Damit sind alle 7 Punkte aus Mischis Bedienlogik-Analyse umgesetzt
(r19.20–r19.25).**

---

## v0.7-r19.24 (2026-07-15) — Interaktives GENERATE: die Cells steuern den Composer (Bedienlogik Runde 5)

Bis jetzt spielte GENERATE nur autonom oder PAUSIERTE, sobald man eine Zelle
drueckte (r19.20-Presence). Jetzt HOERT das Geraet zu und antwortet, statt zu
stoppen:

- **Cell-Druck bei laufendem GENERATE = Richtung** statt Note. Die 5 Cells
  mappen auf die 5 Composer-Intents (composer.h): 0 Home→RETURN, 1 Lift→OPEN,
  2 Dark→DEEP, 3 Open→CALM, 4 Tension→EMPTY. Der Druck springt sofort in den
  Intent (composer_nudge, haelt eine volle Dwell-Zeit) UND mutiert die
  Harmonie jetzt (harmony_advance) — man HOERT die Antwort. Der Generator
  laeuft weiter (bewusst KEIN user-presence → kein Pausieren). Kurzes
  Overlay zeigt HOME/LIFT/DARK/OPEN/TENSION.
  Ehrlich: die Richtung ist der FEEL aus der Composer-Tabelle (Dichte/Tiefe/
  Ruhe), nicht ein Harmonie-Theorie-Spannungsgrad — der Pitch-World verbietet
  harte Dissonanz strukturell; harmony_advance bewegt nur die Stimmen sichtbar.
- **SHIFT+GENERATE = New Field:** reseedet Harmonie + Composer + Bar-
  Humanisierung auf ein frisches, reproduzierbares Feld (gleicher Key/Modus),
  Neustart bei State 0. Der Seed liegt in engine_gen_seed() → wird in Scenes
  mitgespeichert (reproduzierbare Feld-ID). Overlay "NEW FIELD".

NEU composer_nudge/reseed, harmony_reseed, engine_generative_nudge/new_field.
Alles control-rate + host-testbar.

Tests: **NEU test_generative_interactive.c** (12 Checks: Nudge no-op wenn aus,
5 Cell→Intent-Mappings, kein Freeze + Harmonie-Bewegung, New-Field
reproduzierbar pro Seed / verschieden ueber Seeds / Key unveraendert).
36 Suiten gruen; H743-Cross-Build gruen (209 KB Flash).

---

## v0.7-r19.23 (2026-07-15) — Chord Bloom: die Akkorde endlich spielbar (Bedienlogik Runde 4)

Die Akkorde waren in brain.c laengst berechnet (brain_chord), wurden aber
nie gespielt — die Cells triggerten nur den tiefsten Einzelton. NEU
Menue-Slot **Cell (Note / Bloom)** + **bloom.c**:

- **BLOOM:** Cell 1–5 → der harmonisch passende Akkord der 5 Skalenstufen,
  dessen Toene langsam nacheinander aufbluehen (~100–170 ms Abstand,
  gesamt ~200–900 ms; deterministischer Jitter).
- **Voice-Leading:** der neue Akkord wird per Oktav-Verschiebung so gelegt,
  dass sein Schwerpunkt dem des vorherigen am naechsten liegt (kuerzester
  Weg auf Block-Ebene, keine Stimmkreuzungen). Test belegt |Δcentroid| ≤ 6.
- **Bewusst monophon-akkordisch** (wie HiChord): ein Druck ERSETZT den
  Akkord — Voice-Leading braucht einen "vorherigen Akkord", und das Voice-
  Budget (5 Cell-Sources 0..4, Rest = Bett/Shift/Sparkles) traegt keine
  5 unabhaengigen Akkorde. Ehrlich zum Budget, statt Polyphonie zu
  versprechen, die die Hardware nicht hat.
- **HOLD** haelt den Akkord ueber das Loslassen; ohne HOLD momentan.
  **CLEAR** + Modewechsel raeumen sauber ab. Der Generator weicht, solange
  eine Bloom-Zelle physisch gedrueckt ist (r19.20-Presence-Prinzip). Bloom-
  Akkorde gehen als "gespielte" Noten auch auf MIDI-Out.
- **NOTE** = das bisherige Einzelton-Verhalten (Default). Cell-Modus ist
  player-global und wird in Scenes mitgespeichert (Scene-Magic → SCN2).

Chord-Pool = Engine-Sources 0..4; in BLOOM routet das Device die Cells
NICHT durch controls.c, sondern durch den control-rate Bloom-Scheduler
(bloom_tick im Main-Loop, NICHT im Audio-ISR). Hardware-unabhaengig +
host-testbar.

Tests: **NEU test_bloom.c** (15 Checks: gestaffelte Einsaetze, voller
Akkord auf dem Pool, Voice-Leading-Register, Pool-Cap, HOLD-Latch vs
momentan, all_off-Reset, Generator-Yield). 35 Suiten gruen; H743-Cross-
Build gruen (208 KB Flash).

---

## v0.7-r19.22 (2026-07-15) — Parameter-Locks + 5 Scenes (Bedienlogik Runde 3)

Die staerkste Orchid-Uebernahme (Locks) + speicherbare Zustaende (HiChord-
Prinzip) — ohne neue Hardware, ueber die vorhandenen Cells.

**Parameter-Locks:** DISPLAY lang druecken IM EDIT-MODUS sperrt/entsperrt
den aktuellen Parameter (Lock-Punkt links vom Label). Beim World-Wechsel
setzt load_world_preset() nur noch UNgesperrte Werte auf das neue Preset —
der gesperrte Hallraum/Echo bleibt beim Wechsel Tokyo→Hours stehen.
Sperrbar: Key + die 7 Makros (genau das, was ein World-Wechsel anfasst).

**Scenes (NEU scenes.c):** DISPLAY lang im BROWSE oeffnet den Scenes-
Browser: Cell 1–5 laedt, SHIFT+Cell speichert, Cell-LED gelb = belegt /
gruen = aktiv, DISPLAY kurz oder 8 s idle schliesst. Gespeichert: World,
Key, Tuning, Voice, Synth, alle 7 Makros, Locks, Drive, Brightness,
Generator-Seed (NEU engine_gen_seed/set — "dasselbe Feld" ist wieder
dasselbe Feld). NICHT gespeichert: gehaltene Noten, Modi, Volume (springt
beim Recall nie). Persistenz: **letzter Flash-Sektor Bank 2** (0x081E0000)
— H7 ist dual-bank read-while-write, der Audio-ISR laeuft beim Speichern
ununterbrochen weiter (NEU hal_h743/scenes_flash_h743.c, bench-pending).
Host-Tests injizieren ein RAM-Backend.

Tests: **NEU test_scenes.c** (28 Checks: Lock ueberlebt World-Wechsel,
nicht-sperrbare Slots, Save/Recall-Roundtrip inkl. Seed, Volume unberuehrt,
Persistenz-Roundtrip, UI-Flow inkl. Idle-Timeout, Render-Smoke).
34 Suiten gruen; H743-Cross-Build gruen.

---

## v0.7-r19.21 (2026-07-13) — Encoder-Push-Belegung + Overlays (Bedienlogik Runde 2)

Bis jetzt verarbeitete nur der DISPLAY-Encoder seinen Druck — DRIVE/
BRIGHTNESS/VOLUME erzeugten Push-Events, die weggeworfen wurden, und
Drehen an ihnen veraenderte den Klang ohne jedes Display-Feedback.

**NEU knobs.c** (Kurz/Lang-Klassifikation, 500 ms; hardware-unabhaengig):

| Encoder | drehen | kurz | lang |
|---|---|---|---|
| DRIVE | Drive+Overlay | Bypass an/aus A-B | Reset auf Default (15)  |
| BRIGHTNESS | Hell.+Overlay | Neutral (0 Hz) | Reset auf Default |
| DISPLAY | Browse/Edit | Browse/Edit | reserviert (Scenes, R3) |
| VOLUME | Vol.+Overlay  | Mute/Unmute | Batterie + Ausgang |

**NEU overlay.c**: 1,2-s-Wert-Overlay in Menue-Typo (Label klein, Wert
gross), kehrt von selbst zum vorherigen Screen zurueck. **params.c**:
Bypass/Mute lassen den gemerkten Wert stehen; DREHEN nimmt den Wert
zurueck (Bypass/Mute loesen sich auf — Orchid-Gefuehl). Kurz feuert auf
Loslassen (<500 ms), lang EINMAL beim Schwellen-Erreichen; menu_push
liegt jetzt auf der Loslass-Flanke (noetig fuer die Unterscheidung,
DISPLAY-lang bleibt fuer den Scenes-Browser frei). VOLUME-lang zeigt
"BAT 78% +USB / PHONES|SPEAKERS" (2 s).

Tests: **NEU test_knobs.c** (29 Checks: Klassifikation, Bypass/Mute-
Zyklen, Rotate-nimmt-Wert, Reset, Status-Callback, Overlay-Lifetime,
Render-Smoke). 33 Suiten gruen; H743-Cross-Build gruen (203 KB Flash).

---

## v0.7-r19.20 (2026-07-13) — Bedienlogik-Fixes Runde 1 (SHIFT / CLEAR / HOLD+GENERATE / Boot-Volume)

Erste Runde aus dem Bedienlogik-Review (HiChord/Orchid-Vergleich) — alle
vier Befunde waren code-verifiziert:

- **SHIFT ist momentary** (aktiv nur solange gehalten; war ein versteckter
  Toggle ohne Lock-Anzeige). main_h743 fuettert jetzt BEIDE Flanken aller
  Modifier in controls.c.
- **CLEAR = echter Full-Stop**: Latches weg, DRONE/GENERATE/HOLD aus,
  engine_all_off() (weiche natuerliche Releases, kein Hard-Cut) — vorher
  loeschte CLEAR nur die Hold-Latches, Drone+Generator spielten weiter.
  Die seit r18.64 existierende, nie verdrahtete leds_clear_flash() wird
  jetzt beim Druck aufgerufen. **SHIFT+CLEAR = Flush**: nur Stimmen weg,
  alle Modi laufen weiter (Drone klingt durch, Generator bluehte neu).
- **HOLD+GENERATE-Deadlock behoben**: das Generative-Gate ist jetzt die
  PHYSISCHE Tastenlage (engine_set_user_presence, von controls.c per
  Press/Release-Flanke gefuettert) statt "irgendeine aktive Voice" — eine
  gelatchte Cell fror den Composer vorher dauerhaft ein. Momentanes
  Spielen pausiert weiterhin sofort.
- **Boot-Volume 30 % + Fade-in** (SPEC-Regel, seit dem r19.19-Kopfhoerer-
  verstaerker doppelt relevant): params-Default 0.60→0.30, neu
  engine_boot_mute() — das Geraet startet hart stumm und faedelt ueber die
  Parameter-Rampe (~350 ms) auf 30 % ein. Host-Renderer behalten die
  0.6-Bench-Referenz (boot_mute ist nur im Device-Pfad).

Tests: test_controls +9 Checks (Momentary, Full-Stop vs Flush, Presence),
test_generative_tick +Latch-Regression (Generator komponiert um gelatchte
Stimme herum), test_params/test_leds an neue Semantik angepasst. 32 Suiten
gruen, H743-Cross-Build gruen (FLASH ~201 KB).

---

## v0.7-r19.19 (2026-07-13) — TPA6132A2: J8 wird echter PHONES / LINE OUT (ADR-0024)

User: "ja das muss rein!!!" — Kopfhoerer-Betrieb an J8 war bisher out-of-spec
(DAC-Tap, ≥1 kΩ). Jetzt sitzt **U11 TPA6132A2RTER** (C69901, live-verifiziert:
370 Stk., JLC Economic+Standard) zwischen PCM5102A und Buchse:

- DirectPath (interne Ladungspumpe, keine Auskoppel-Elkos), Gain −6 dB
  (G0=G1=GND) → ~1,05 Vrms: Line-Pegel UND sichere Kopfhoerer-Lautstaerke.
- EN = AMP_nSHDN (boot-safe, Shutdown 0,7–1,2 µA — passt zur ADR-0023-
  Aus-Zustand-Analyse). Jack-Detect-Mute betrifft weiter NUR die Speaker.
- Beschaltung per TI SLOS597B: CIN 2×1 µF, Flying 1 µF, HPVSS 1 µF,
  VDD+HPVDD je 2,2 µF (**C1607**, 16.200 Stk.); HPVDD NIE an VDD (DS-WARNING).
- Footprint QFN-16-1EP_3x3mm_P0.5mm_EP1.7x1.7mm gegen JLC-Landpattern
  C69901 + TI RTE0016C abgeglichen. R_LO 22Ω bleiben (jetzt hinter dem Amp).
- Netzliste: 165 Netze / 649 Pins / 0 floating; AMP_nSHDN = U11.EN + U4.SHDN
  + PB14; check_pinmap gruen. BOM: 60 Teile-Typen / 200 Platzierungen.
- Doku: ADR-0024, SPEC-Phones-Sektion (die alte "v0.8-Option TPA6132" ist
  damit exakt umgesetzt), Walkthrough §3, PINMAP, BOM-Dokus, COMPONENT_LINKS.

---

## v0.7-r19.18 (2026-07-13) — BQ24074-Power-Path: alle P0 des externen Hardware-Audits gefixt (ADR-0023)

Externes statisches Audit (Verdikt „DO NOT FABRICATE") — alle pruefbaren
Befunde gegen die selbst-extrahierte Netzliste bestaetigt, dann komplett
behoben. **Schaltplan-Redesign der Stromversorgung:**

- **U7 = BQ24074RGTR** (C54313, live-verifiziert: 1.074 Stk., JLC
  Economic+Standard) ersetzt MCP73831 + D3B-Dioden-OR. Topologie:
  USB→F1→`VBUS_FUSED`→BQ-IN; BQ-OUT=`VSYS`→TPS61089→D3→+5V-Rail (einzige
  Quelle); BQ-BAT←**F2 PTC** (SMD1812P260TF/16, C438899)←J9.
- Dimensionierung per TI SLUS810N: ICHG 0,89 A (R_ISET 1k C21190), IIN-MAX
  1,34 A (R_ILIM_IN 1,2k **C114605**, YAGEO — 1,1k/1,2k UNI-ROYAL bei LCSC
  out-of-stock), ITERM/TMR = NC-Default (10 % / 5 h), TS = 10k fest,
  EN2=VSYS/EN1=GND (ILIM-Modus), CE_N=GND. EP→VSS.
- **Boost-EN = PWR_ON** (Audit P0-3): der Schiebeschalter toetet jetzt auch
  den Boost (<3 µA Shutdown). SW_PWR-Pull-Quelle von der Rail auf **VSYS**
  verlegt (Henne-Ei-Deadlock vermieden). LED_CHRG von +5V auf VBUS_FUSED
  (P0-2). Bulk (~580 µF) liegt jetzt hinter dem Boost — USB-Hot-Plug sieht
  nur noch 4,7 µF (P0-6).
- Neue Netze `VBUS_FUSED`/`VSYS`/`PWR_ON` durch power_tree↔root↔battery
  gezogen; +5V_OUT am power_tree jetzt input (Rail wird von Sheet 7 gespeist).
- Footprint QFN-16-1EP_3x3mm_P0.5mm_EP1.7x1.7mm gegen JLC/EasyEDA-
  Landpattern fuer C54313 abgeglichen (Pitch/Pads/EP identisch).
- **Validierung:** geometrischer Netzlisten-Extractor ueber alle 7 Sheets:
  157 Netze, 620 Pins, **0 floating**; check_pinmap gruen; JLC-BOM ohne
  „TBD"-Zeilen (J4 = DNP-Debug-Pads, Ex-MPN „TC2030-IDC" war das falsche
  Teil). J8 explizit **LINE OUT**; mechanical_coordinates 5000→2000 mAh.
- Doku: **ADR-0023** (Rechnungen + Verifikations-Trail), SCHEMATIC_WALKTHROUGH
  §1/§7 neu, PINMAP-Power-Tabellen, BRING_UP-Sollwerte (TP_VSYS!), BOM_MASTER/
  PCB_BOM/COST/SOURCING/OBJECTIVES/COMPONENT_LINKS nachgezogen.

## v0.7-r19.6 (2026-07-06) — Just Intonation: „harmonies without beating" (Sonicware Ø v1.5-Prinzip)

User „ja" auf den Vorschlag, die letzte 🟡-Sache aus dem Audit anzugehen:
reine Stimmung für die stehende Harmonie.

**NEU tuning.c + Menü-Slot „Tuning" (Equal / Just, 10 → 11 Slots):**
- **Equal** (Default): gleichstufig, **bit-exakt** = dsp_midi_to_hz. Der
  bench-getunte Referenzklang bleibt unangetastet.
- **Just**: 5-Limit-Just-Intonation, an die KEY-Tonika verankert (Tonika
  behält ET-Frequenz → Konzertstimmung bleibt; alles andere ist reines
  Verhältnis: Quinte 3:2, Terz 5:4, Sexte 5:3, Oktave 2:1 …). Für reine
  Intervalle fallen die Partialtöne exakt zusammen → die gehaltene Harmonie
  rastet ohne Schweben ein (Sonicware Ø v1.5 „harmonies without beating").
- **ALLE tonalen Stimmen** laufen durch dieselbe Stimmung (Bett, Eno-Loops,
  Melodie, Cells, Drone) — ET+JI mischen würde schlimmer schweben als
  beides. Ideal für unser Konzept: ein tonales Zentrum, langsam bewegt.

Prinzip aus der Ambient Ø v1.5 gelernt, nicht kopiert; die JI-Ratio-Tabelle
und die Tonika-Verankerung sind unsere Umsetzung.

**Test §test_tuning:** Equal bit-exakt über midi 40–90; Just liefert exakt
3/2, 4/3, 5/4, 5/3, 2/1 und die Oktav-runter-Fälle; **Beat-Beweis**: die
ET-Quinte schwebt (3·f vs 2·1.5f ≈ 0.9 Hz), die JI-Quinte ist beat-frei
(0.000 Hz). Menü-Test um den Tuning-Slot erweitert.

26 Suiten (+test_tuning) / 0 Failures; h743 clean (183,4 KB Flash);
Session-Demo läuft jetzt in Just, Autoplay neu.

---

## v0.7-r19.5 (2026-07-06) — Blendwave ausgebaut: gehaltene Töne wandern spektral (Yin/Yang-Formant)

User: „bau das aus" — die 🟡-Blendwave-Tiefe aus dem Ehrlichkeits-Audit
(gehaltene Töne sollen wirklich WANDERN, nicht nur leicht atmen).

Prinzip aus der Sonicware Liven Ambient Ø („undulating tones" durch
Morphen durch Harmonische-Tische), RAM-sicher neu gebaut. Ein echter
zweiter 64-KB-Tisch ging nicht (RAM_D1 96 %, D2 96 %; RAM_D3 hätte gepasst,
aber Domänen-/Cache-Risiko unverifizierbar → CLAUDE.md „nicht raten").
Stattdessen der Morph im **Filter-Bereich**:

- **NEU Spektral-Animator in pad.c:** pro Voice ein korrelierter Random-
  Walk `spec_w` (kleine persistente Schritte, ~1 s/Ziel, glidet), der einen
  **wandernden Formant-Bandpass** über die Partial-Zone 220–1550 Hz treibt.
  Die zwei internen Seiten lesen ihn **gespiegelt** (Seite 0 = w, Seite 1 =
  1−w) → die Oszillatoren morphen **gegenläufig** (Yin/Yang), was zusätzlich
  das Stereobild spektral schimmern lässt.
- **An MOTION gekoppelt** (gleiche emotionale Richtung „lebendiger"); bei
  MOTION 0 **bit-exakt aus** — der Referenzklang bleibt unangetastet.
- Kosten: 1 SVF + ein paar Floats pro Seite (DTCM 90.3 → 90.9 %); D1
  unverändert. Fixe Seeds → reproduzierbar.
- **Test §14:** gehaltener 110-Hz-Ton, 6-Sonden-Filterbank → Spektral-
  Centroid pro 1,5-s-Fenster; zeitliche CV **0.06 (aus) → 0.17 (an)** =
  ×2.8 mehr Bewegung, aus bleibt near-static.

26 Suiten / 0 Failures; h743 clean (182,5 KB Flash); beide Demos neu.

---

## v0.7-r19.0 (2026-07-06) — Harmonic Safety Core: der Composer-Kern neu geschrieben (Pitch-World → Register → Mutation → Collision-Filter → lange Melodie → Wahrscheinlichkeit zuletzt)

User-Brief (nach Research über r/ambientmusic, r/musictheory, Plomp/Levelt-
& Sethares-Roughness, Tymoczko-Voice-Leading, Liven Ambient Ø): „Wir denken
zu sehr in Chord Progressions. Wir brauchen ein harmonic safety system.
Nicht ‚wähle Scale → generiere Chords → random notes'. Quality Gate zuerst,
Randomness zuletzt. Schreib den Composer-Kern NEU, nicht Parameter tweaken."
Ehrliche Einordnung des Users bestätigt: unser altes Denken war genau der
Grund, warum die Soundscapes trotz Reverb/Dorian nach „creepy AI ambient"
klangen — wir haben Leben durch NEUE Events erzeugt statt einen bestehenden
Zustand innerlich zu bewegen.

**NEU harmony.{h,c} — der harmonische Sicherheitskern** (Prinzipien
gelernt, frisch gebaut). Die Pipeline, in dieser Reihenfolge:

1. **PITCH WORLD statt Akkorde:** eine Welt besitzt einen Pentatonik-CORE
   (Dur: C D E G A · Moll: D F G A C — strukturell KEIN Halbton, KEIN
   Tritonus im Set, die zwei aggressivsten Clash-Klassen sind aus dem
   Tonmaterial entfernt) + EINE Color-Note (maj7 bzw. 9), die nur oberhalb
   C4 erlaubt ist.
2. **REGISTER-Regeln:** Bass 38–49 (unter C3 nur Root/Quinte/Oktave),
   Stimmen 55–79 (wide voicing), Melodie 62–86; 2nds/9ths/Color nur hoch.
3. **COMMON-TONE-MUTATION statt Neu-Würfeln:** 4 kuratierte Zustände;
   ein Wechsel behält **≥3 gemeinsame Pitch-Classes und bewegt ≤2 Stimmen**,
   gemeinsame Töne bleiben auf DERSELBEN Tonhöhe (parsimonious voice
   leading, Tymoczko). Meist reinterpretiert nur der Bass die Töne.
4. **COLLISION-FILTER vor jedem Melodie-Ton:** gegen JEDE klingende Stimme
   Halbton (1/11) + Tritonus (6) verboten, 2nds unter C4 verboten; ein
   verworfener Ton fällt auf den nächstbesten (next-best) durch.
5. **Lange MELODIE-Stimme:** Töne 4–16 s, Stille 1–8 s (+ Atem nach jeder
   Phrase), Phrasen 2–5 Noten; Bewegung per Tabelle (repeat > Schritt >
   Quart/Quint > Sext/Oktave > Color). Kein Arpeggiator.
6. **Wahrscheinlichkeit GANZ zuletzt** — nach dem Quality Gate.

**Engine-Umbau (engine.c, kein Tweak):** Der alte Per-Bar-Chord-Walk +
Sparkle-Scheduler ist raus. Bett = Bass des harmonischen Zustands (re-
strikt nur bei echtem Zustandswechsel — gehaltene Töne werden vom neuen
Bass REINTERPRETIERT, nicht neu angeschlagen). Die drei Eno-Loops
(r18.99) tragen jetzt je EINE Stimme des Zustands (collision-safe). Die
Melodie ist die lange Voice auf Source 15 + VOICE-Anschlag (String/Glass)
am Onset. Déjà-vu bleibt (Marbles), aber jeder erinnerte Ton muss erneut
durch World + Collision-Filter. **Blendwave-Prinzip (Liven Ambient Ø):**
korrelierter Random-Walk auf dem Pad-Brightness-Tilt alle 400 ms — „same
note, evolve timbre", der bestehende Zustand lebt ohne neue Events.
engine_set_mode/key syncen die Welt (Dorian/Phrygian/Aeolian → Moll-Welt).

**Messung (der eigentliche Beweis):** Der Kern wie in der Engine getrieben
(Bett + 4 Stimmen sustainen, Melodie pickt darüber), 16.000 Picks über
beide Welten × 4 Tonarten = **80.000 gleichzeitige Intervalle: 0,00 %
Halbtöne, 0,00 % Tritoni.** Konsonanz dominiert (Quart/Quint 33 %,
Terzen 30 %, Oktaven 19 %), 0 Silences.

**Tests:** NEU test_harmony.c (Pitch-World halbton-/tritonusfrei, Mutation
≥3 common / ≤2 moved + Common-Tone-Freeze, Register-Bänder, Collision-
Filter, 600 Melodie-Picks alle safe + kein Leap > Oktave + Wiederholung,
Dur-Welt). test_generative_tick auf die lange Melodiestimme + Chor
angepasst. **26 Suiten / 0 Failures**; h743 clean (182,2 KB Flash). Beide
Demos neu gerendert.

---

## v0.7-r18.99 (2026-07-06) — Der Sonicware/Eno-Durchbruch: SHIMMER + Tape-WOW/FLUTTER + Eno-Loops

User-Brief: teropa/loop (Reich "It's Gonna Rain" + Eno "Music for
Airports") und Sonicware Liven Ambient Ø studieren — „unser Gerät ist
erst krass wenn es klingt wie Sonicware Ambient … es muss alles in unser
Gerät passen wie es aktuell konzipiert ist."

Quellen-Extrakt (Produktseite + Loop-Essay; Reddit/YouTube waren
bot-geblockt): Ambient Ø = 4 ROLLEN-Layer (Drone/Pad/Atmos/Noise — haben
wir strukturell schon) + **pro Layer Reverb- UND SHIMMER-Send** + Lofi.
Reich: 2 identische Loops, leicht verschiedene Geschwindigkeit. Eno: 7
Loops, EINE Note pro Loop, **inkommensurable Längen** — „they simply
don't reconfigure the same way again."

Drei fehlende Bausteine, alle drei gebaut:

- **NEU shimmer.c — Oktav-Regeneration um den Hall** (Sonicware/Eno-
  Prinzip, frisch implementiert): Dual-Tap-Doppler-Shifter (+12 st,
  leistungskomplementäre Sinus-Fenster) liest das Hall-WET, dunkelt ab
  (LP 4.3 kHz + HP 180 Hz) und speist es zurück in den Send — jede Runde
  klettert eine Oktave und stirbt (Loop-Gain-Cap 0.55, quadratische
  Kurve). **Menü 9 → 10 Slots: SHIMMER** nach Space, Welt-Presets
  Tokyo 12 · Coast 22 · Drive 6 · Hours 16 %. 0 = bit-exakt aus
  (Verfassung: kein Dauer-Shimmer). Bugs auf dem Weg (vom Goertzel-Test
  gefangen): Dreieck-Crossfade schmierte die Oktave in Seitenbänder
  (→ sin²-Fenster), und der Read-Head lief blockintern nur 1× (wr stand
  still → base = wr + n). Endmessung: E(440)/E(220) ≈ 4600 bei 220-Hz-
  Sinus-Input.
- **NEU tape.c WOW & FLUTTER**: moduliertes Fractional-Delay auf dem
  MASTER (vor der Sättigung — das Wobbeln passiert auf dem Band, der
  Kopf sättigt danach): Wow ~0.35 Hz (Rate driftet ±15 % random-walk)
  ±0.9 ms + Flutter 6.1 Hz ±27 µs. Tiefe = AGE² — Referenzband bleibt
  fast starr, altes Band wird betrunken. Depth 0 = bit-exakter Bypass,
  Engage/Release crossfaden über einen Block. Test: Zero-Crossing-
  Perioden-Varianz > 0 bei depth 1, bit-exakt bei 0.
- **NEU Eno-Loops im Bett (engine.c)**: 3 Ein-Noten-Loops auf Pad-
  Sources 5–7 mit inkommensurablen Perioden **13.7 / 21.3 / 33.1 s**,
  gestaffelte Ersteinsätze (0.40/0.62/0.81 der Periode), 62 % Duty
  (die Lücken zeigen die Rekombination). Jeder Zyklus greift SEIN
  Akkordglied (Root/Terz/Quinte via brain_chord) der AKTUELLEN Harmonie
  — die Drift rekombiniert, die Tonalität bleibt. Phase resettet NIE.
  Bass ignoriert die Loops (lowest_held überspringt 5–7 — Fundament
  folgt der Harmonie, nicht der Farbe). Nur Autoplay; User-Hold friert
  Retrigger ein (Catch-up ohne Maschinengewehr danach).

Session nutzt alles: Shimmer-Preset ab Start, Halo blüht im Finale
(12 → 34 %), AGE 0.5 bringt hörbares Wow im After-Hours-Teil. Autoplay
mit Shimmer 15 %. Tests: §13 (Shimmer-Oktave, Wow-Varianz/Bypass,
Eno-Chor 2..4 Stimmen, Release bei Disable) + test_generative_tick auf
Chor-Semantik. **26 Suiten / 0 Failures**; h743 clean (176,2 KB Flash).

---

## v0.7-r18.98 (2026-07-06) — End-Rauschen (Vinyl-Teppich) getötet + VOICE (String/Glass-FM) + KEY im Menü

User: „in der played session höre ich am ende noch so starkes rauschen …
außerdem: sind die anderen synths gebaut? … das instrument kann nicht
genug, es ist zu langweilig — vielleicht oscillator oder LFO oder pitch
controls?"

**1. Das End-Rauschen, per Messung gefunden:** Banded-Profil über die
Session zeigt ab 116 s (Weltwechsel → After Hours) einen STATIONÄREN
HF-Floor (−56 dBFS >8 kHz), der beim Ausklingen voll freiliegt. Isolation:
Welt 3 + ATMOS 0.30 = −56 dB, ohne ATMOS −83 dB → Täter ist die
**Vinyl-Ambience „crackle"**: kontinuierliches HP-Weißrauschen bei 0.22 —
exakt der Teppich, den §2 der Verfassung seit r18.97 verbietet (r18.97
hatte Wind/Wellen/Regen gefixt, Vinyl übersehen). **Rebuild als EVENTS:**
dichte kleine Ticks (~10..50/s, τ≈1 ms, zufällige Seite/Polarität) + die
sparsamen Pops + Rumble. Gemessen: 3–8 k −60.6 → −69.9, >8 k −56.5 →
−68.5 dBFS; das Session-Ende fällt von −46 auf −55 dBFS Gesamt-Floor und
klingt nach Platte, nicht nach Hiss.

**2. Ehrliche Antwort auf „andere Synths":** `src/v2/engines/` enthält 6
Engines (acid, fm_glass, chorus_mist, ion_storm, glass_orbit,
bamboo_circuit) aus der V2-Richtung, die der User verworfen hat („Horror",
„Crystal Castles") — nie verdrahtet, keine Demos. Statt sie zu reanimieren:
das BESTE Konzept daraus (FM-Glass) als Prinzip neu gebaut, im Rahmen der
Verfassung.

**3. NEU glass.c — 2-op-FM-GLASS-Stimme** (Chowning/DX7-Tine-Prinzip,
frisch implementiert): Sinus-Carrier phasenmoduliert bei inharmonischem
Ratio 3.5307 (Sidebands ZWISCHEN den Harmonischen = Glas/Glocke), Index-
Hüllkurve (~130 ms) viel schneller als Amplitude (~2.5 s T60) — der helle
komplexe Anschlag, der in fast reinen Ring ausklingt, IST die Metall-
Illusion. Velocity → Index (leise = warmer Chime, hart = gläserner Clang).
Läuft durch denselben Melodie-Bus + Modalkörper wie die KS-Saite.

**4. NEU Menü-Slots (7 → 9):**
- **KEY** (nach World): 12 Tonarten als Notennamen, Weltwechsel snappt auf
  die Welt-Tonika (Tokyo A · Coast D · Drive F# · Hours C), verankert in
  MIDI 54–65 (`engine_set_key_pc`) — Transposition, nie Oktavsprung.
  Gehaltene Latch-Noten re-pitchen mit (hal_set_key →
  controls_refresh_held_pitches).
- **VOICE**: Pad · String · Glass. Bei String/Glass schlägt jeder
  Cell-Press ZUSÄTZLICH die Melodiestimme an — artikulierter Attack vor
  dem Pad-Swell (Piano-in-Pad-Gefühl). Die generativen Sparkles folgen
  derselben Wahl. Default Pad = der bench-getunte Referenzklang, unberührt.
  Weltwechsel resettet VOICE nicht (Spieler-Entscheidung).

**5. Session-Demo nutzt die neuen Controls** (Antwort auf „langweilig"):
VOICE→String vor den kurzen Taps (1:00), VOICE→Glass im After-Hours-Teil
(2:29), KEY-Modulation C→D (zwei Detents) vor der Schlussphrase (2:56).

Tests: test_sound_upgrades §12 (Glass klingt/begrenzt/self-decay,
Anschlag inharmonisch-hell vs. Ring fast rein per Goertzel, Engine-
Dispatch pro VOICE, KEY-pc-Mapping inkl. Wrap), Menü-Tests für beide
Slots (Snap bei Weltwechsel, VOICE bleibt). **26 Suiten / 0 Failures**;
h743 clean (169,7 KB Flash). played_session neu gerendert; autoplay
bit-identisch (VOICE-Default ändert nichts — beabsichtigt).

---

## v0.7-r18.97 (2026-07-05) — Rauschteppich getötet (per Messung) + Wind/Wellen als realistische Sounds

User: „irgendwas ist da so hardcore am rauschen durchgehend, alles andere
stirbt deshalb … wenn ueberhaupt waere echter simulierter Wind 100x geiler
und so Wellen Wasser — nicht als Rauschen, sondern als realistischer Sound."

**Forensik statt Raten** (Banded-RMS pro Quelle waehrend Musik + FFT-Valley-
Floor-Analyse auf f32-Dumps). Drei Taeter, in dieser Reihenfolge gefunden:

1. **Tape-Hiss unter Programm (der Haupttaeter):** Das r18.92-Ducking
   oeffnet den Hiss VOLL sobald Musik spielt — der alte Default 0.005 lag
   dann nur ~23 dB unter der Musik: ein flacher, weisser Floor 500 Hz–12 kHz
   im Spektrum. Default **0.005 → 0.0012**, AGE-Kurve **linear → quadratisch**
   (`0.0012 + v²·0.005`). Test-Band in test_tape §1b/1c nachgezogen.
2. **PADsynth-Band-Overlap:** bw_scale 1.2 liess die Gauss-Bandbreite
   (~2.9·h^1.2 Hz) ab Harmonischer ~20 die konstanten 110-Hz-Abstaende
   ueberlappen → das Bett trug selbst ein Rauschband. **NH 48 → 24,
   bw 45 → 30 Cent, bw_scale 1.2 → 1.0** + Gauss-Rolloff der Amplituden.
3. **Rain-Shh:** lautester stationaerer Rest — **0.45 → 0.18** (die DROPS
   tragen das Regenbild, der Wash klebt sie nur zusammen).

Messung (gleiches Werkzeug vorher/nachher): Ton-zu-Rausch-Abstand des
stationaeren Betts **47.7 dB → ~105 dB** (Valley-Floor jetzt am
16-bit-Quantisierungsboden); Atmos-Beitrag waehrend Musik im Mittelband
nicht mehr messbar (−35.6 vs −35.7 dBFS ohne).

**Wind neu (ambience.c):** kein Dauerteppich mehr (alter Gust-Floor 0.40!).
Drei Cues aus der Procedural-Audio-Lehre (Farnell-Analyse — Prinzip
gelernt, neu gebaut): (1) **Boeen mit asymmetrischem Slew** — ~1.5 s
Anstieg, ~4 s Abklingen, dazwischen echte **Flauten** (35 % der Ziele sind
0.03–0.23); Gate QUADRIERT, Flaute ≈ still. (2) Spektralzentrum steigt
mit Intensitaet (450→950 Hz). (3) In starken Boeen **Pfeifen**: Q-18-
Resonatoren, wandern 400–1100 Hz (τ≈10 s), nur ueber env 0.6. Filter-
Moves auf Control-Rate (÷16).

**Wellen neu:** (1) Body-LP folgt dem Schwell **150 → 420 Hz** (fern dumpf,
nah praesent), (2) nach dem Brechen faellt das Splash-Band **2.6 kHz →
500 Hz** ueber den Decay — das „shhh → shhoo" von ablaufendem Wasser im
Sand, (3) der Break wirft **Gischt**: 0.35-s-Burst koerniger Dust-Pings
durch 3-kHz-Resonator genau an der Attack→Decay-Ecke. Gate quadriert,
Body-Gain 1.8 → 1.35 (Crest clippte sonst; vom Test gefangen).

Tests: 26 Suiten / 0 Failures (test_tape-Baender nachgezogen, test_ambience
§7-Peak-Bound haelt); h743 clean (167,9 KB Flash). Beide Demos neu
gerendert (autoplay 5:00 + played_session 4:10).

---

## v0.7-r18.96 (2026-07-05) — AmbientComposer: Zustände über Minuten, nur Wahrscheinlichkeiten (Atmoscapia/Eno-Prinzip)

User-Brief (via ChatGPT-Analyse von Atmoscapia): „Wir brauchen einen
echten Ambient Composer ueber der Sound Engine — State → Harmony →
Voice Roles → Event Probability → Sound Engine. Nicht random note →
synth." Prinzip rekonstruiert (Atmoscapia publiziert keinen Code — der
Punkt IST das Prinzip), fuer unser Geraet gebaut.

Ehrliche Einordnung: unser Layer-Stack entsprach dem Atmoscapia-Diagramm
bereits (Drone/Pad-Bett/Texture/Melodie/Atmosphere → LFO-Drift → FX →
Master). Gefehlt hat exakt die oberste Box.

- **NEU composer.{h,c}:** Zustandsmaschine CALM → OPEN → DEEP → EMPTY →
  RETURN, je 40–80 s (fixe Seeds, humanisiert). Jeder State ist NUR eine
  Tabelle: mel_density (×), rest_add (+), high_p (+24-Antwort), bed_amp
  (×), bass_depth (Ziel). Pures Modul, kein Engine-Call, kein Audio-Pfad.
- **Engine-Anbindung (nur Autoplay):** Noten-Wahrscheinlichkeit × density
  (Cap 0.95), Pausen-Phrasen 30 % + rest_add (5–85 %), Bed-Amp skaliert,
  Bass-Fundament folgt pro Bar (glidet ueber den r18.88-Sustain-Drift —
  kein Zipper). **HIGH RESPONSE** als EIGENE antwortende Stimme: der Ton
  klingt +1 Okt., die Melodielinie fuehrt am Basiston weiter — die
  Leap-Regel der Grammatik bleibt hart (erste Version verletzte sie,
  vom 206-Bar-Audit gefangen).
- **EMPTY ist nicht Stille:** Bett haelt bei 0.6×, Texture/Atmos laufen —
  der angehaltene Atem, der RETURN warm macht.
- **Tests:** 15-min-Simulation — alle 5 States besucht, OPEN singt
  zeitnormiert > 2× dichter als EMPTY; Resume-Fenster in §4 auf 152 s
  (muss einen State-Wechsel ueberspannen — EMPTY kann 80 s schweigen).
  **26 Suiten / 0 Failures**; h743 167,0 KB.
- Autoplay-Demo auf **5:00 verlaengert** (ein voller Composer-Zyklus
  hoerbar) und neu gerendert. SOUND_WORLD §6b mit der State-Tabelle.

---

## v0.7-r18.95 (2026-07-05) — Spielsession-Simulator: ein Mensch am Geraet, als Audio

User: „spiel mal ab drone + die cells abwechselnd, aender paar sachen im
menue wie ein echter mensch — generate wuerde er nicht benutzen."

**NEU tools/render_session.c:** ~4:10-Performance durch die ECHTEN
Geraetepfade — Cells/Modifier via controls.c (Hold-Latch-Statemachine),
DRIVE/BRIGHT als echte params_encoder-Detents (inkl. Acceleration),
Menue-Aenderungen als 2–5-%-Detent-Folgen 90–160 ms auseinander (exakt
menu_rotate im Edit-Mode), Weltwechsel wie hal_set_world (engine_set_world
+ controls_refresh_held_pitches). GENERATE unberuehrt. Timing humanisiert
(fixe Seeds: Taps ±120 ms, Velocities 0,10–0,16, Detent-Gaps 70–160 ms) —
deterministisch reproduzierbar. Dramaturgie: Bett+Atmos → DRONE → langsame
Cells → SPACE oeffnet mitten in der Phrase → HOLD-Akkord + Taps drueber →
Brightness-Dip → CLEAR → After Hours + AGE (Vinyl) + ECHO → letzte Note,
DRONE aus, langer Tail. 104 Events, Peak −12,4 dBFS.
**demos/audio/field_ambience_played_session.flac** (25 MB, flac -t ok);
README-Zeile auf 4 FLAC.

---

## v0.7-r18.94 (2026-07-05) — Modal Body: die Plucks bekommen einen Instrumentenkörper (Rings/Elements/STK-Konzept)

User: „Dann modal body." — Fortsetzung der Engine-DNA-Reihe.

### NEU body.{h,c} — Modalresonator hinter der Pluck-Stimme

**Konzept studiert aus Mutable Rings/Elements + STK-Modal-Modellen**
(frisch implementiert, kein Code uebernommen): ein Instrument ist nie nur
die Saite — die Saite treibt einen KOERPER mit FESTEN Resonanzmoden. Die
Note variiert, der Koerper nicht; genau diese feste Faerbung macht eine
Gitarre auf jedem Bund nach DIESER Gitarre klingen. Rings' tiefere
Lektion: die Moden-FREQUENZVERHAELTNISSE sind das Material, die
Moden-DECAYS sind Groesse und Daempfung.

- Bank aus bis zu 8 parallelen 2-Pol-Resonatoren (y = 2R·cosθ·y1 − R²·y2
  + g(x − x2); Zero-Paar haelt DC/Nyquist auf null), Gain-normiert via
  (1−R), Pole hart < 1 → stabil per Konstruktion.
- **Vier eigene Materialien, eins pro Welt:** Tokyo = warmes Holz (dicht-
  inharmonische Ratios 1/1.47/2.09/…, T60 0,8→0,2 s), Coast = Glas
  (gestreckte Ratios 1/2.32/4.25/…, laengster Ring), Drive = dunkles
  Metall (tief geclusterte Moden), Hours = Filz/Papier (4 schnell
  sterbende Moden — weicher Thump).
- Stereo: rechte Moden +0,7 % — „vor dem Instrument, nicht im Mono-
  Lautsprecher". Wet 0,38, amount 0 = bit-exakter Bypass.
- **Nur die Melodie-Stimme bekommt den Koerper** (Pluck-Bus → body →
  dry + Hall-Send); das PADsynth-Bett bleibt clean — ein Koerper pro
  Instrument, kein Koerper auf dem Raum.
- CPU ≤ ~100 Ops/Sample, kein Heap, feste States.

### Tests (§11) + Zahlen

Impuls-KLINGT-Beweis (Ring-Energie nach dem Impuls > 0, faellt monoton),
**Goertzel on-mode (180 Hz Holz) vs. between-modes (220 Hz) > 5×** —
gemessen am Ring, nicht am Dry-Impuls (der hat Flat-Spektrum und wusch
die Ratio aus; vom Test gefangen), Material-Unterschied zwischen Welten,
bit-exakter Bypass, 5 s Full-Scale-Noise bounded. **26 Suiten /
0 Failures**; h743 166,1 KB Flash, D1 83,6 %. Autoplay-Demo mit Koerper
neu gerendert; SOUND_WORLD §3 aktualisiert (Pluck = KS-Saite →
Modalkoerper pro Welt).

---

## v0.7-r18.93 (2026-07-05) — PADsynth-Bett (Nasca-Modell) + Marbles-Déjà-vu: die Engine-DNA-Runde

User: „Studiere die Open-Source-Goldminen (Nasca, Gillet, …) — nicht
kopieren, Modelle und musikalische Entscheidungen extrahieren."
Reihenfolge des Users befolgt: #1 PADsynth, dann Marbles.

### NEU padsynth.{h,c} — das Bett ist jetzt ein Spektraltisch

**Modell studiert: Paul Nascas PADsynth** (ZynAddSubFX; vom Autor mit
Public-Domain-Beispielcode dokumentiert). Die Erkenntnis: Breite und
Leben kommen nicht von gestapelten verstimmten Oszillatoren, sondern
davon, dass **jeder Partialton ein schmales RAUSCHBAND ist statt einer
Linie**. Implementierung frisch fuer unser Geraet: Harmonische als
Gauss-Buckel ins Spektrum gemalt (Bandbreite 45 Cent, waechst mit h^1.2),
Zufallsphasen pro Bin, eigene iterative Radix-2-IFFT (16384er-Tisch,
perfekt loopend per Konstruktion, Loop-Naht per Test == gewoehnlicher
Sample-Schritt). **Eigene Welt-Profile** (Tokyo warm/odd-glow, Coast
glasig, Drive dunkel, Hours staubig-even); Tisch wird bei Weltwechsel in
wenigen ms neu gebaut (UI-Pfad, nie Audio-IRQ).

**pad.c-Core-Swap (FAM_PAD_CORE, Default 1):** die 10-polyBLEP-Osz pro
Voice werden durch 2 interpolierte Tisch-Reads ersetzt (Haupt + leise
Sub-Oktave) — Envelopes, SVF, Brightness/Motion-Makros, Ensemble-Drift
(moduliert jetzt die Leserate), Haas + Panning identisch. voiceMix
mappt auf Filter-Tilt. Legacy-Core bleibt als Mode 0 (A/B/Not-Revert).
CPU des Betts faellt massiv (2 Reads statt 10 Oszillatoren + Wrap).

### Marbles-Konzept: Déjà-vu-Phrasen (Melodie erinnert sich)

Gelernt aus Mutable Marbles: ein Zufallssequenzer wird MUSIK, wenn er
beschliessen kann, dasselbe nochmal zu sagen. Die Grammatik merkt sich
die letzte abgeschlossene Phrase als Tonkontur; neue Phrasen replayen
sie mit p=0.40 (eine Note variiert mit p=0.30), **re-fitted auf den
AKTUELLEN Akkord** (naechster Akkordton) — das Motiv ueberlebt
Stufenwechsel, die Harmonie atmet. Getter engine_generative_dejavu_count.

### Tests + Zahlen

- test_sound_upgrades §10: Tisch deterministisch/normiert (RMS 0,22),
  Loop-Naht-Check, **Goertzel on-harmonic vs. between-harmonic > 10×**
  (der Kern des Modells, hart geprueft), Welt-Profile distinkt +
  bit-reproduzierbar. Grammatik-Test: Déjà-vu ≥ 3 in ~206 Bars;
  Intervall-/Register-/Pausen-Regeln weiter gruen.
- **26 Suiten / 0 Failures** — auch alle bestehenden Pad-Verhaltens-
  Checks bestehen mit dem neuen Core unveraendert.
- h743: 164,1 KB Flash; D1 82 % (Tisch 64 KB + IFFT-Scratch 128 KB).
- Autoplay-Demo mit dem neuen Bett neu gerendert.

### Ehrliche Roadmap (bewusst NICHT in dieser Runde)

Rings/Elements-Resonanzkoerper (Modal-Body hinter dem Pluck), Clouds-
Konzepte fuer blur.c, Signalsmith-Householder-Diffusion als HALL-
Vergleich, Airwindows-Charakterschicht — je eine eigene, hoertest-
pflichtige Runde. Tides-Slow-Modulation teilweise durch Drift abgedeckt.

---

## v0.7-r18.92 (2026-07-05) — Grundrauschen-Fix (gemessen: −11,5 dB) + Battery-ADC + SHIFT-Backlight

User: „wir haben so ein grund rausch ton der immer bisschen zu praesent
war … zu dirty oder zu laut" + „baue die restlichen sachen aus".

### Rausch-Forensik (Idle-Floor pro Verursacher gemessen, dBFS-RMS)

| Quelle | vorher | nachher |
|---|---|---|
| Engine-Defaults idle | −56,6 | **−67,3** |
| Atmosphere 0.35 allein | −36,6 | **−48,9** |
| Demo-Makros (tex+age+atm) | −35,9 | **−47,4** |

**Hauptverursacher: die Atmosphere-Schicht** — der ATMOS-Makro wirkte
LINEAR, 0.35 legte einen konstanten −36-dBFS-Teppich unter alles (auf
Handy-Lautsprechern klar als Dauerrauschen hoerbar). Sekundaer: der
Tape-Hiss lief auch bei absoluter Stille konstant (−56 dBFS).

### Fixes

- **ambience.c: quadratische Pegelkurve** (lvl = v²·0.85) — die untere
  Knopfhaelfte ist ein Fluestern, oben bleibt Drama. Dazu „zu dirty"
  entschaerft: Rain-„sshhh" von 2,5 kHz (Handy-Zischzone) auf 1,9/2,05 kHz
  runter, Q 1,4→1,2, Pegel 0,7→0,45; Drops 0,45→0,36; Vinyl-Dauer-Crackle
  0,35→0,22, Pops 0,55→0,45.
- **tape.c: Programm-Follower-Ducking** — engine_render fuettert den
  Dry-Bus-Block-Peak; Hiss + Vinyl-Crackle folgen schnell nach oben,
  ~600 ms nach unten, Floor −10,5 dB (Hiss) / −6 dB (Crackle). Echte
  Bandmaschinen rauschen UNTER Musik, nicht als Solo-Demo in der Stille.
- texture.c: Air-Band 0,18→0,13 (leicht dunkler).
- **Regression-Test** (test_sound_upgrades §9): Idle-Floor Defaults
  < −60 dBFS, Demo-Makro-Floor < −44 dBFS; test_tape prueft das Ducking
  explizit (Stille ≈ Floor-Gain, nie null).

### Rest-Ausbau (die letzten unverdrahteten Device-Enden)

- **NEU adc_h743.c:** BAT_SENSE PA3 = ADC12_INP15, 16-bit, Kalibrierung,
  810,5-Zyklen-Sampling (100k‖100k-Quelle + 10-nF-Reservoir), CLKP-Kernel.
  VBAT = 2×V(PA3).
- **main_h743:** 1-Hz-Battery-Poll → battery_pct_from_voltage → Menu-Glyph;
  **USB-Detect via MCP GPA7** (neu MCP_BIT_VBUS, Schematic-verifiziert:
  10k-Serie + 100k-Pulldown an VBUS_USBC) → Lade-Glyph. **SHIFT +
  DISPLAY-Encoder = Backlight** (5 %/Detent, 10–100 %, Boot 70 %) — die
  SPEC-Transient-Overlay-Regel, bisher nie verdrahtet.

26 Suiten / 0 Failures; h743 cross-baut (161,9 KB). Autoplay-Demo mit dem
sauberen Floor neu gerendert.

---

## v0.7-r18.91 (2026-07-05) — HALL-Reverb (Figur-8-Tank) + KRITISCH: LIQUID-Tail-Bug + Kohärenz-Audit

User: „finde ein reverb der schon richtig gut ist und lass dich inspirieren
… stelle sicher dass überall die timings und tonlagen stimmen."

### KRITISCHER FUND: der LIQUID-Hall hatte seit r18.42 KEINEN Tail

Die A/B-Messung (Noise-Burst → Tail-RMS) zeigte: LIQUID tail@1s = 0.00000
selbst bei size 0.9. Ursache: die modulierten Combs lasen bei `pos − mod`
— das ist ein erst `mod` (≈6–10) Samples ALTES Sample, nicht `size − mod`.
Die Feedback-Schleife war 6–10 Samples lang statt ~1200 → der „Hall" war
nur Diffusor-Schimmer, der sofort kollabierte. Deshalb klangen die Demos
flach. Fix im Legacy-Mode (Leserichtung `pos + 1 + mod`, age = size − mod;
nach Fix: echter Tail messbar) — und als Default ersetzt durch:

### NEU: HALL — kreuzgekoppelter Figur-8-Tank (FAM_REVERB_MODE 2, Default)

Topologie gelernt aus Jon Dattorros 1997er „Effect Design Part 1"-Plate
(Lexicon-Schule; publiziertes Paper, kein Code kopiert). Eigene Längen
(29,761-kHz-Relationen auf 44,1 kHz skaliert, auf teilerfremde Werte
geschoben, Tap-Positionen neu gewählt); Tank-Modulation auf UNSERE
Drift-Sprache verlangsamt (0,101/0,127 Hz statt ~1 Hz Paper-Wobble).

- Pre-Delay 24 ms → Bandwidth-LP → 4 Serien-Diffusor-APs (0.75/0.625)
  → Tank: 2 Zweige, jeder speist den anderen (Figur-8) — mod-AP (g −0.70,
  ±12 Samples) → Delay → Damping-LP → Decay → AP (0.50) → Delay.
- BEIDE Ohren tappen BEIDE Zweige (je 7 verteilte Taps) → EIN tiefer Raum
  hinter dem Instrument statt zwei dekorrelierter Mono-Hallen
  (Kreuzkorrelation gemessen: 0.01).
- Gemessen: size 0.5 → T60 ≈ 4,5 s; size 0.9 → ~15 s (kinoartig lang,
  Decay-Cap 0.97); Pegel size-stabil (wet 0.138→0.148 statt 0.17→0.33).
- Speicher ~136 KB (< LIQUID 166 KB, D1 jetzt 44,4 %), CPU ≈ halbiert
  (2 fraktionale Reads/Sample statt 28). API unveraendert — Presets/
  Space-Makro wirken weiter.

### Kohärenz-Audit („alles aufeinander abgestimmt")

Neuer Test-Abschnitt (test_sound_upgrades §8): (a) Sub-Bass-Floor
(lowest/4) ≥ 28 Hz fuer ALLE 4 Welten × 4 Vibes × 7 Stufen — nichts
verhungert unter dem 35-Hz-Master-DC-Block, kein verbotener Sub-Matsch;
(b) Melodie-Register (56–96) liegt ueber dem Pluck-Delay-Line-Floor;
(c) Hall-Tail waechst MONOTON mit SPACE und bleibt bounded. Alles gruen.

26 Suiten / 0 Failures; h743 cross-baut (157,5 KB Flash, D1 44,4 %).
Autoplay-Demo mit dem neuen Raum neu gerendert (Peak −12,2 dBFS).

---

## v0.7-r18.90 (2026-07-05) — Sound-World-Runde: Ensemble-Drift, Melodie-Grammatik, Brightness-Makro, FTZ + SOUND_WORLD.md

User-Kontrakt: Elite-Embedded-Audio-Rolle — Prinzipien aus Legenden
extrahieren, koharente Klangwelt bauen, brutal ehrlich reviewen.

- **NEU `docs/SOUND_WORLD.md`** — die klangliche Verfassung (Identitaet,
  verbotene Ergebnisse, 3-Stimmen-Regel, Harmonie-/Bewegungs-/Melodie-
  Sprache mit harten Zahlen, Makro-Regeln, Echtzeit-Verfassung). Bindend
  wie der AI_READY-Standard fuer die Hardware.
- **Pad-Ensemble-Drift (pad.c):** Juno-Prinzip uebertragen (Lebendigkeit =
  Phasen-Drift zwischen Fast-Unisono-Schichten, nicht statisches Detune):
  Detune wobbelt ±1,8 Cent auf 0,061/0,087-Hz-LFOs pro Seite (inkommensurabel
  zu den Filter-LFOs), skaliert vom MOTION-Makro. Small-Angle-Naeherung,
  kein powf at control-rate.
- **Melodie-GRAMMATIK (engine.c Tick):** die r18.89-Sparkles wuerfelten
  uniform — huebsch pro Event, aber Randomisierung, keine Komposition.
  Jetzt: Phrasen 2–4 Bars, 30 % Pausen-Phrasen, max. 1 Ton/Bar (Opener
  85 %/55 %), 35 % Wiederholung, sonst naechster Akkordton (15 % zweit-
  naechster), Oktav-Faltung gegen Leaps nach Stufenwechseln (Band 56–96),
  Opener-Akzent, 18 % Oktav-Antwort (gleicher Ton −12). Observability:
  engine_generative_last_melody_midi()/_melody_count().
- **BRIGHTNESS ist ein Makro:** Pad-Cutoff (wie gehabt) + Hall-Daempfungs-
  Trim (dunkel = stumpferer Tail) + Pluck-Daempfung (neu
  pluck_set_damp()). Bei 0 exakt der bench-getunte Referenzklang.
- **FTZ auf dem H7 (main_h743.c):** FPSCR- und FPDSCR-FZ-Bit gesetzt —
  Reverb/Echo/Pluck-Tails dekaien durch den Denormal-Bereich; auf ARMv7-M
  nimmt Denormal-Arithmetik den langsamen Support-Pfad = CPU-Spike genau
  dann, wenn das Instrument leise wird. Klassiker, jetzt abgedichtet.
- **Tests:** test_generative_tick §6 auditiert die Grammatik statistisch
  ueber ~206 simulierte Bars (Register, keine Leaps > Oktave, Wieder-
  holungen vorhanden, Pausen vorhanden, Schrittbewegung dominiert) — fing
  waehrend der Entwicklung einen realen Leap-Bug nach Stufenwechseln
  (→ Oktav-Faltung). **26 Suiten, 0 Failures**; h743 cross-baut (158,1 KB).
- Autoplay-Demo neu gerendert (Grammatik + Ensemble-Drift hoerbar).

---

## v0.7-r18.89 (2026-07-04) — Sound-Engine-Ausbau: Master-Drive, Noise-Primitiven, Vinyl-Crackle, Karplus-Strong-Plucks

User: „Baue sound engine aus. Also auch die synthesizer und noise und andere
sounds wie drive brightness etc. Bedien dich als supercollider libraries und
anderen gelungenen open source projekten. Klau nicht, sondern lerne daraus."

Konzepte studiert aus SuperColliders PinkNoise/Dust/Crackle/Pluck-UGens, dem
Kellet-Pink-Filter und dem Karplus-Strong-Paper (CMJ 1983) — alle
Implementierungen frisch fuer diese Engine geschrieben (fixe LCG-Seeds,
bit-reproduzierbare Host-Tests).

- **Neue DSP-Primitiven (dsp.{h,c}):** `dsp_pink` (1/f-Rauschen, Kellet-
  3-Pol-Economy), `dsp_dust` (zufaellige Impulse, Dichte in Hz),
  `dsp_crackle` (chaotische Rekurrenz |y1·p−y2−0.05|; erste Version nutzte
  die logistische Map — die KONVERGIERT bei p<3, vom Test gefangen),
  `dsp_drive_shape/_makeup` (asymmetrischer tanh-Sättiger: Bias → gerade
  Harmonische, Kleinsignal-Makeup).
- **Master-DRIVE-Stage (engine.c):** Der DRIVE-Encoder erreichte bisher NUR
  die Reverb-Eingangs-Saettigung — auf trockenen Sounds praktisch unhoerbar.
  Jetzt faehrt er den GESAMTEN Mix durch den asymmetrischen Sättiger (vor
  DC-Blocker + Tape-Stufe, 0 = bit-transparent, Dry/Wet-Fade im ersten
  Knopf-Viertel, Kleinsignal-Makeup: Farbe statt Lautstaerke). Reverb-Drive
  laeuft geslavt ~halben Knopf hinterher (params.c).
- **Vinyl-Crackle (tape.c, AGE-Makro):** Dust-Impulse klingeln durch einen
  2,6-kHz-Resonator (Q 2,2) + ultraleises Chaos-Fry-Bett darunter; Pegel
  age² (unten fast clean, oben deutlich „alte Platte"). Haengt mit Hiss +
  Saettigung am selben AGE-Regler.
- **Texture:** Breath-Band bekommt 35 % Pink-Anteil (Brown allein verliert
  rechts vom Sweep-Zentrum zu viel Praesenz; Weiss zischte) — praesenter,
  nicht lauter.
- **Karplus-Strong-Plucks (neu: pluck.{h,c}):** Die Generative-„Sparkles"
  waren Pad-Voices — gleiche Farbe wie das Bed, klang nach „mehr Pad".
  Jetzt: 2 KS-Stimmen (fraktionale Delay-Line mit Lin-Interpolation →
  Pitch exakt; T60 3,2 s pitch-unabhaengig; gedaempfter Noise-Burst als
  Anregung; ±0.35 Pan, Reverb-Send 0,5) — Glocken/Koto-Farbe ueber dem Bed.
  Selbst-abklingend, kein Note-Off-Bookkeeping mehr im Tick; Pad-Sources
  14/15 wieder frei. Bugfix waehrend der Entwicklung: Schreibkopf startete
  bei 0 und ueberschrieb den Burst, bevor der Lesekopf ihn erreichte (Test
  fing die Stille).
- **Neues Demo `demos/audio/field_ambience_autoplay.flac`** (3:00): der
  Passiv-Modus pur — GENERATE an, Haende weg (Tokyo, AGE 0,45, DRIVE 0,30);
  neues Tool tools/render_autoplay.c rendert exakt den Device-Pfad
  (engine_generative_tick). Peak −11,4 dBFS, flac -t ok.
- **Tests:** neue Suite test_sound_upgrades.c (Pink-Statistik inkl.
  1/f-Proxy, Dust-Dichte, Crackle-Chaos, Shaper-Transparenz/Makeup/Bounds,
  Pluck-Pitch per AUTOKORRELATION bei der Soll-Periode + T60-Retire,
  Engine-Drive „Farbe statt Lautstaerke", Crackle-Level). test_generative_
  tick.c auf Pluck-Observability umgestellt. **26 Suiten, 0 Failures**;
  h743 cross-baut (156,9 KB Flash, D1 47,9 %).

---

## v0.7-r18.88 (2026-07-04) — Sound-Logik-Audit: 5 Musik-Bugs gefixt + Generative-AUTOPLAY

User: „Untersuche die sound logik. finde kritische logische musikfehler.
fixe sie, verbessere sound und algorithmen, bass, drone, generate."

### Kritische Logikfehler (alle gefixt, alle host-getestet)

1. **Generative spielte ueber gehaltene Shift-Noten** — `any_cell_held()`
   prueft nur Sources 0–4; die Shift-Oktave-Latches liegen auf 9–13
   (ADR-0008 SHIFT_SRC). Bed+Sparkles liefen also ueber das Live-Spiel.
   → `any_user_note()` prueft 0–4 UND 9–13 (Bed-Source 8 + Sparkles 14/15
   bewusst ausgenommen).
2. **Momentary-Tap toetete gelatchte Voice** — Tap auf eine Zelle teilt
   ihre Pad-Source mit dem Latch-Zweig. War die Zelle gelatcht (Hold
   inzwischen aus), schoss das Release-note_off die gehaltene Voice ab,
   waehrend das Latch-Bit true blieb (State-Desync bis zum Clear).
   → Release prueft jetzt, ob die Source gelatcht ist, und laesst sie dann
   klingen (der Tap war ein Re-Bloom).
3. **GENERATE = bis zu 8 s Stille nach dem Druecken** und dann nur 1 Note
   pro 8 s — kein „passiv Musik generieren". → komplett neues AUTOPLAY
   (unten).
4. **World-/Key-Wechsel liess gelatchte Noten in der ALTEN Tonart klingen**
   — Clash mit neuem Drone-Root und Bed bis zum Clear. → neues
   `controls_refresh_held_pitches()` (merkt sich die Latch-Velocity,
   re-pitcht alle Latches aus dem aktuellen Brain-State); main_h743 ruft
   es nach `engine_set_world()`.
5. **Bass-Sustain ignorierte Depth-Aenderungen** — `bass_note()` bei
   klingendem Bass refresht `amp`, aber nichts bewegte `env` dahin;
   Aenderung erst nach komplettem Release hoerbar. → Sustain driftet mit
   der Release-Zeitkonstante Richtung Ziel (musikalisches An-/Abschwellen).

Dazu Doku-Fix generative.c: die FIXED-Progression 3 {1,6,3,7} spielt
bewusst die 7. Stufe (Leitton-Akkord) — der alte Kommentar behauptete,
Stufe 7 werde nie gevoict (stimmt nur fuer den Markov-Pfad).

### Generative-AUTOPLAY (engine_generative_tick, ersetzt den Bar-Timer)

Original-Intention (User): GENERATE druecken → das Geraet spielt von sich
aus Musik. Jetzt:
- **Erste Bed-Note sofort** beim ersten Tick nach dem Einschalten,
- **humanisierte Bars** (8 s ±10 % pro Bar, LCG — nie metronomisch),
- **0–2 „Sparkle"-Akkordtoene pro Bar** (nie der Root, +1 Oktave, leise
  0.05–0.08, ~3–4 s Ring, Sources 14/15, humanisierte Positionen bei
  25–55 % / 60–85 % des Bars) — das Bed atmet als echte Musik,
- Live-Spiel unterbricht: keine neuen Bed-/Sparkle-Noten solange
  irgendeine User-Note klingt (Base ODER Shift); klingende Sparkles
  releasen normal; nach dem Loslassen resumed das Bed beim naechsten Tick
  (nicht bis zu 8 s spaeter). Das Bed selbst haelt unterm Spiel aus
  (Ambient-Bett, gleiche Semantik wie zuvor).
- Alles haengt nur an now_ms → host-testbar; `engine_generative_advance()`
  bleibt als manuelle Step-API fuer die Offline-Renderer.

**Neue Suite `test_generative_tick.c` (7629 Checks):** Sofort-Note,
120-s-Simulation (Degree-Range, Voice-Budget ≤ Bed+2, Audio bounded),
Shift-Suppression (Fix 1 direkt), Resume nach Release, sauberes Disable.
test_controls.c erweitert: Latch ueberlebt Momentary-Release-Tail (Fix 2),
Key-Wechsel-Re-Pitch ohne Voice-Leak (Fix 4). Host-Suite: **25 Suiten,
0 Failures**; h743 cross-baut (159,5 KB Flash).

---

## v0.7-r18.87 (2026-07-04) — LEDs reduziert: nur Cell- + Modifier-LEDs (VU-Meter + Heartbeat raus) + neue Audio-Renders

User: „we only keep LEDs above cells and above modifier buttons.. I don't
need the other leds and functions."

- **Schematic (Generator):** U10 PCA9685 #2 (0x41) + LED_VU1–8 + R_VU1–8 +
  R_OE2 + C_PCA2_VDD/_HF komplett entfernt (mcp_sheet); LED_HB + R_SLED
  (STATUS_LED/Heartbeat) entfernt, **PD8 = NC-Reserve** (stm32h743_sheet).
  I²C-Bus traegt wieder nur U2 (0x20) + U6 (0x40). Geometrisches ERC: 0
  Fehler, Warn-Baseline unveraendert.
- **BLEIBT: LED_CHRG** (orange, MCP73831-STAT-hardware-getrieben) — mit dem
  ADR-0016-Power-Off laedt das Geraet im AUS-Zustand (keine Firmware laeuft);
  die STAT-LED ist das einzige „laedt"-Feedback. Auf Zuruf streichbar.
- **BOM:** 57 unique Parts / **188 Placements** (−22). SMD-BOM/Board
  $24.50 → ~$21.30; 5er-Run neu ~$89 (Economic) / ~$99 (Standard) pro
  Geraet. jlc_bom.csv + bom_overview.html + BOM_MASTER + PCB_BOM +
  COST_ESTIMATE + PCB_HANDOFF + Onboarding aktualisiert; **ADR-0020 =
  SUPERSEDED**.
- **Firmware:** vu.{h,c} + test_vu.c geloescht, pca2_*/PCA2_I2C_ADDR-API
  raus, engine_render_peak()-Tap raus (Render-Loop wieder ohne Peak-
  Messung), main_h743-VU-Block raus. U6-LED-Pfad (leds.c, 16 Kanaele inkl.
  Backlight) unveraendert. Host-Suite **24 Suiten / 0 Failures**; h743
  cross-baut (152,9 KB Flash).
- **Audio-Renders neu** (User: „render new audio samples"): beide Demos mit
  der AKTUELLEN Engine frisch gerendert und nach `demos/audio/` gelegt —
  `field_ambience_master_tape.flac` (8:20, Sechs-Saetze-Mastertape aus
  render_wav.c, Peak −6,7 dBFS) + `field_ambience_performance.flac`
  (5:00, dichte Session aus render_performance.c, Peak −4,7 dBFS).
  flac -t verifiziert; README-Zeile aktualisiert.

---

## v0.7-r18.86 (2026-07-04) — Firmware: Step 13.3 CubeH7-Bring-up — H743 baut als echte Firmware (.elf/.bin)

User: „Now let's properly build our firmware engine." — Teil 2: die
H7-Hardware-Anbindung. Alle sechs `src/hal_h743/`-Skeletons sind jetzt
reale Treiber; `cmake -DFAM_TARGET=h743` cross-kompiliert mit
arm-none-eabi-gcc ein flashbares Image (156 KB Flash / 2 MB, Vektoren
@0x08000000; `.bin`/`.hex`/`.map` + Size-Report als Post-Build).

- **Vendored ST-Code** (`src/hal_h743/vendor/`, BSD-3): CubeH7 HAL
  **v1.11.6** (26 Module-Sources, nur enabled Module) + CMSIS-Core 5.9 +
  CMSIS-Device-H7 (startup_stm32h743xx.s, system_stm32h7xx.c).
- **Build-Infrastruktur:** `cmake/arm-none-eabi-m7.cmake` (Cortex-M7,
  FPv5-D16 hard-float, newlib-nano + nosys, gc-sections; auto-selektiert
  fuer FAM_TARGET=h743), `stm32h743_flash.ld`, `stm32h7xx_hal_conf.h`
  (14 Module), `stm32h7xx_it.c` (SysTick→HAL_IncTick+enc_tick_1khz,
  DMA1_Stream0→SAI, EXTI15_10→MCP-INTA).
- **Clock-Tree** (`system_clock_h743.c`, RM0433/DS12110): HSE 8 MHz →
  PLL1 M1/N120/P2 = 480 MHz VOS0/LDO, AHB 240/APB 120; PLL3 M2/N70/
  FRACN4588/P25 = 11,289609 MHz SAI-Kernel → FS exakt 44,1 kHz (+0,8 ppm).
- **Treiber real statt Skeleton:** I²C1 PB6/7 (MCP23017-Init wie Pico,
  GPPUB inkl. GPB5; beide PCA9685 via gemeinsamem Dev-Helper; EXTI PC13);
  SAI1-A Master-TX I²S 16-in-32-Slots + DMA1-Circular-Ping-Pong in D1
  (SCB_CleanDCache pro Halb-Refill, SPEC-§8.3-Unmute-Sequenz); SPI1
  @30 MHz (120-MHz-Kernel /4, Pico bench-proven 32) ST7789-Init 1:1 vom
  Pico-Treiber, geteilte `oled_grey565_lut()`; TIM2/3/4/1 Encoder-Mode
  TI12 (×4, IC-Filter 0x4) + 1-kHz-Diff mit Pico-Substeps {2,2,4,2},
  Pushes PE0/1/3 3-of-N-debounced, **EN4-Push via MCP GPB5**
  (`MCP_BIT_ENC4_SW` neu, Main-Loop → `enc_set_ext_push`); USART2 PD5
  31250 Baud (120e6/31250 = 3840 exakt), `midi_hw_init/midi_hw_pump`
  gemaess midi.h-Contract — **Aktivierung bleibt per ADR-0004 deferred**.
- **Main-Loop komplett** (alle 13.3-TODOs raus): Caches→HAL_Init→Clocks;
  INT-getriebener MCP-Pfad (`mcp_irq_pending`/`mcp_service` statt
  I²C-Polling); Jack-Detect 50-ms-Debounce → NUR PB15/Amp-Mute (Line-Out
  bleibt live); Generative-Bar-Timer 8 s (Kadenz = render_wav-Mastertape);
  60-Hz-LED+VU-Block; Menu-Flush dirty-gated @~30 fps mit Accent-Tick.
- **RAM-Split** (Linker-Script, ADR-0015 D3): .bss gesamt ~630 KB >
  512-KB-AXI → per Objekt-Datei gesteert: `pad.c`→**DTCM** (100 KB,
  CPU-only, 0-wait), `echo.c`+`blur.c`→**D2** (283/288 KB), Rest + DMA-
  Puffer→**D1** (243/512 KB). Startup nullt nur .bss → `main()` nullt
  die zwei Extra-Regionen zuerst. Stack-Guard-Assert bleibt.
- Host-Suite unveraendert gruen (25 Suiten, 0 Failures, inkl. 352298-
  Check-Lauf); host/pico-Targets unberuehrt.

---

## v0.7-r18.85 (2026-07-02) — Firmware: VU-Meter komplett (Engine-Tap → 8-Segment-Ballistik → U10-API)

User: „Now let's properly build our firmware engine." — Teil 1, host-testbar
zuerst (Repo-Regel): die r18.83 als offen dokumentierte VU-Luecke ist zu.

- **Engine-Tap:** `engine_render_peak()` — Block-Peak des FINALEN limitierten
  Outputs (exakt das DAC-Signal), einzelner volatiler Float-Store aus dem
  Render-Kontext, beliebig pollbar.
- **Neues Modul `vu.{h,c}`** (hardware-unabhaengig): 8 Segmente
  (−36/−30/−24/−18/−12/−6 Level + −3/−0,5 Peak, dBFS), Instant-Attack,
  30 dB/s wall-clock Release, 900 ms Peak-Hold (OP-1-Field-Style Dot),
  PWM-interpoliertes Bar-Ende, White-Duty passend zu leds.c.
- **Neue Test-Suite `test_vu.c`** (44 Checks): Thresholds, Attack/Decay-
  Timing, Floor-Clamp, Peak-Hold ueber Decay + Release, Boundary-
  Interpolation unter gehaltenem Dot, Over-FS-Clamp, End-to-End mit echtem
  `engine_render()` (Stille vs. gehaltene Note).
- **HAL-API:** `PCA2_I2C_ADDR 0x41` + `pca2_init/pca2_set_pwm` in
  mcp23017.h; h743-Stubs (Transport = Step 13.3, ein gemeinsamer
  pca_write(addr,…)-Helper); main_h743 tickt das Meter im 60-Hz-LED-Block.
- Host-Suite gruen (352298 Checks gesamt), `field_ambience_h743` baut+linkt.

---

## v0.7-r18.84 (2026-07-02) — Must-have-Check: /OE-Fehler (alle LEDs tot), Mounting-Holes, Testpunkte + neue Kostenschätzung

User: „are we missing any must have pcb components?" + neue JLC-Kostenschätzung.

### KRITISCH: beide PCA9685-/OE-Pins hatten Pull-UP ohne Treiber

R_OE (U6) und R_OE2 (U10) zogen /OE auf +3V3 — mit dem Kommentar „Firmware
zieht /OE LOW nach PWM-Init". Es gab aber KEIN Netz, ueber das die Firmware
das haette tun koennen (kein MCU-/MCP-Pin an /OE). /OE waere permanent HIGH
geblieben → **alle 15 Status-LEDs, das LCD-Backlight und die 8 VU-LEDs fuer
immer aus** (Backlight aus = LCD unlesbar). Fix: beide auf **Pull-DOWN** —
Ausgaenge immer enabled; Boot-Dark garantiert der Chip selbst (NXP-DS
Tabelle 7: LEDn_OFF_H[4] „full OFF" Default = 1* fuer jeden Kanal, gegen
das Original-PDF verifiziert). Firmware-Kommentare (pca_init) angepasst —
es gibt nichts mehr zu sequenzieren.

### Fehlende Must-haves ergaenzt

- **4× Mounting-Holes H1–H4** (M2.5, Bohrung 2,7 mm, plattiert, GND) — in
  der mech. Spec §6 laengst definiert ((12,6)/(240,6)/(12,96)/(240,96)),
  aber NIE im Schematic → jetzt als DNP-Symbole mit Footprint
  MountingHole_2.7mm_M2.5_Pad (FP_NOTE: KiCad-Pad 5,4 mm vs Spec 6 mm —
  Layout-Entscheidung Aron).
- **7 Testpunkte** (AI_READY-Standard verlangt TP_*): TP_5V, TP_3V3,
  TP_5VSW, TP_VBUS, TP_GND1/2 (power_tree) + TP_BAT (battery),
  TestPoint_Pad_D1.5mm, alle DNP (kein BOM-Eintrag).
- Beides ist bestueckungsfrei → jlc_bom.csv unveraendert 58 Parts /
  210 Placements (Exporter: 11 DNP-Skips korrekt).

### Sonst fehlt nichts Zwingendes — geprueft und fuer ok befunden

USB (Fuse+TVS+ESD+CC) ✓ · Lade-/Power-Pfad inkl. Ein/Aus ✓ (seit r18.81) ·
NRST/BOOT0-Beschaltung ✓ · VCAP ✓ · HSE+Loads ✓ · I²C-Pull-ups ✓ ·
Status-LED ✓ · Backlight-Treiber ✓ · SWD ✓ · Jack-Schutz ✓ (r18.82).
Bewusst NICHT auf der PCB (kein Fehler): Akku-Schutz-PCM (muss im
LiPo-Pouch sitzen — Kaufhinweis in COST_ESTIMATE §2), Fiducials (fuegt
JLC beim Panelisieren hinzu), MIDI-IN (nur OUT per ADR-0004).

### Neue Kostenschätzung (COST_ESTIMATE.md komplett neu, Preise live)

5er-Run: **~$92/Geraet** (JLC ~$48 + Hand-Supply ~$44) — WENN die Outline
auf ≤250 mm gekuerzt wird (JLC-Economic-Limit 250×250; aktuell 252×102 →
sonst Standard-PCBA: ~$102/Geraet). SMD-BOM ~$24.50/Board (live: STM32
$8.68, 2×PCA9685 $5.86, Tantal $1.78, MCP23017 $1.62, PCM5102A $0.99 …).
Stock-Warnung: C444831 (Tantal) nur ~121 St. LCSC. 10er-Run ~$75–85/Geraet.

### Verifikation

ERC 0 Fehler alle Sheets; Generator deterministisch; jlc_bom unveraendert;
Host-Tests 352298/0.

---

## v0.7-r18.83 (2026-07-02) — Firmware↔Hardware-Konsistenz-Audit: Cells-Gap geschlossen, Pin-Maps verifiziert

User: „Will everything work as intended with the firmware and software?"

### Verifiziert KONSISTENT (Firmware-HAL-Claims vs. Schematic-Netze)

Jede Pin-Behauptung der H743-HAL-Dateien gegen die Generator-NETS-Tabelle
(= Schematic-Wahrheit) geprueft — ALLE stimmen:
- **SAI1**: PE4/PE5/PE6 (Pins 3/4/5) = I2S_LRCK/BCK/DOUT → PCM5102A 15/13/14 ✓
- **LCD SPI1**: PA5/PA7/PA6/PC4/PC5 (29/31/30/32/33) = SCK/MOSI/CS/DC/RES ✓;
  Backlight = PCA-Kanal 15 (leds.h ✓, lcd_h743 ✓)
- **I²C1**: PB6/PB7 (92/93) + MCP_INT PC13 (7) ✓; Adressen 0x20/0x40/0x41 ✓
- **Encoder**: TIM2 PA0/PA1 (22/23), TIM3 PC6/PC7 (63/64), TIM4 PD12/PD13
  (59/60), TIM1 PA8/PA9 (67/68); Pushes PE0/PE1/PE3 (97/98/2) + MCP GPB5 ✓
- **Amp**: PB14/PB15 (53/54) = AMP_nSHDN/nMUTE ✓ — Boot-Pop-Sequenz passt zu
  den Hardware-Pulldowns (Amp+DAC starten stumm, Firmware hebt an) ✓
- **MIDI**: PD5 (86) USART2_TX ✓ · **BAT_SENSE**: PA3 (25) ✓
- **MCP-Bitmap** (mcp23017.h): Cells GPA0-4, XSMT GPA5, JACK GPA6,
  Modifier GPB0-4 = exakt die mcp_sheet-Verdrahtung ✓
- **Jack-Detect-Polaritaet**: Firmware-Annahme (Bit HIGH = plugged) = die
  r18.82-korrigierte Hardware-Topologie ✓

### GESCHLOSSEN: der r18.76-Firmware-Gap (Cells auf H743)

main_h743.c enthielt noch den stalen Hall-ADC-TODO-Block („adc_read_norm/
cells_update") — seit r18.73 gibt es keine Hall-Sensoren mehr. Haette man den
TODO wie beschrieben implementiert, waeren die Cells auf echter Hardware tot
gewesen. Jetzt: digitaler MCP-Edge-Pfad (GPA0-4, aktiv-LOW) wie in der
bench-erprobten Pico-Implementierung, geroutet durch die host-getestete
controls.c-Statemachine (feste Tap-Velocity 0.12 wie Pico). Dazu: Jack-Detect-
Routing-Block (GPA6 → nur PAM8403 muten, NICHT audio_mute() — das wuerde den
Line-Out toeten); stale Kommentare fixiert („J9 DNP" → J10-Hardware ist
bestueckt; Generator-Docstrings: MIDI-Buchse „fehlt" → existiert seit r18.67,
Backlight „Kanal 12" → 15). H743-Target kompiliert + linkt ✓.

### OFFEN (ehrlicher Stand — was noch NICHT auf Hardware laeuft)

1. **Step 13.3 (der grosse bekannte Schritt):** main_h743 ist ein bewusstes
   Skeleton — STM32CubeH7-Integration fehlt (Clock-Config 480 MHz + PLL3,
   SAI1+DMA-Pump, SPI1-, I²C1-, USART2-, GPIO-Primitiven, HAL_GetTick,
   Generative-Bar-Timer, Menu-Flush-Rate-Limit). Die gesamte LOGIK darueber
   ist host-getestet (352298 Checks) und auf dem Pico-Bench-Target real
   verifiziert; es fehlt die H7-Peripherie-Anbindung, keine Logik.
2. **VU-Meter (U10 @ 0x41, 8 LEDs, Hardware seit r18.66): keine Firmware.**
   pca_set_pwm kennt nur ein Device; es fehlen adressierbare PCA-API,
   Engine-Level-Tap und VU-Renderer. Bis dahin bleiben die 8 LEDs dunkel
   (PCA bootet aus — kein Fehlverhalten, Feature fehlt). Eigener Schritt.
3. **MIDI-TX firmware-seitig deferred** (ADR-0004 r18.30) — Hardware komplett,
   Reaktivierung = 1 Zeile + USART2-Init aus Step 13.3.

### Verifikation

Host-Tests 352298 Checks / 0 Failures; field_ambience_h743-Target baut+linkt;
Schematics byte-identisch (nur Python-Docstrings geaendert).

---

## v0.7-r18.82 (2026-07-02) — Datenblatt-Verifikation aller restlichen Komponenten: 2 kritische Pad-Mapping-Fehler + 2 Lücken

User: „All the other components are right? check datasheets." — systematischer
Abgleich jedes verbleibenden ICs/Bauteils gegen das Original-Datenblatt
(Microchip DS20001952, NXP PCA9685 Rev.4, Microchip DS20001984, ST USBLC6-2,
ST DS12110 Fig. 5, Abracon/LCSC, SHOU HAN PJ-320D + HX B3F-4055) UND jedes
Symbol-Pin↔Footprint-Pad-Paars (KiCad matcht Pin-Nummer gegen Pad-Namen als
STRING — die r18.82-Fehlerklasse).

### KRITISCH — Pad-Mapping (Symbol-Pin-Nummer ≠ Footprint-Pad-Name)

1. **EN1–EN4 Encoder: ALLE 4 komplett unverbunden.** Der offizielle
   KiCad-Footprint `RotaryEncoder_Alps_EC11E-Switch_Vertical_H20mm` hat
   BENANNTE Pads **A / B / C / S1 / S2** (+MP) — das Custom-Symbol nutzte
   numerische Pins 1–5. String-Match ⇒ kein einziger Encoder-Pin haette im
   Netlist ein Pad gehabt. Fix: Pin-Nummern → A/B/C/S1/S2 (Pad-Geometrie
   gegen den GitLab-Footprint verifiziert: A(0,0), C(0,2.5)=Common-Mitte,
   B(0,5) = ALPS-Terminal-Reihenfolge A-C-B ✓).
2. **J8/J10 PJ-320D: Pad-Map falsch — Audio-L lag auf dem BARREL.** Das
   SHOU-HAN-Datenblatt (P.C.B-Layout + Schaltbild) ordnet zu: Pad 1=A=Sleeve,
   2=D=Ring, 3=C=Tip-Switch (DETECT), 4=B=Tip. Das Symbol mappte T=1, R=2,
   S=3, DET=4 ⇒ links Audio auf dem (geerdeten) Sleeve-Barrel, GND auf dem
   Detect-Kontakt, JACK_DETECT auf dem Tip — Line-Out UND MIDI-Out falsch.
   Fix: T=4, R=2, S=1, DET=3. Vendored-Footprint-Geometrie verifiziert
   (Pad-Pitch 3,0/4,0 mm, Locator Ø1,0 @ 7,0 mm = Zeichnung exakt) —
   **TODO B0b damit geschlossen.**
3. **Folge-Fix aus #2:** laut Datenblatt ruht der Detect-Kontakt OHNE Stecker
   am TIP (nicht am Sleeve) → MCP-GPA6 hinge unplugged direkt am DAC-L-Ausgang
   (±3 Vpk): die Eingangs-Clamp haette die negativen Halbwellen ueber 22R
   kurzgeschlossen (>100 mA Injection + Verzerrung am Speaker). Neu:
   **R_DET_J8 10k** (Clamp-Strom < 300 µA) + **C_DET_J8 1 µF** (Audio-AC-
   Filter, fc ≈ 16 Hz). Pegel: unplugged ≈ 0,3 V LOW / plugged 3,3 V HIGH.

### Lücken (Datenblatt-Anforderungen)

4. **MCP73831: 4,7-µF-VDD-Eingangskondensator fehlte** (DS20001984 Typical
   Application) — der VBUS_USBC-Knoten hatte keinerlei lokale Kapazitaet.
   Neu: C_CHG_IN 4,7 µF (C46653). Pinout 1=STAT/2=VSS/3=VBAT/4=VDD/5=PROG ✓
   verifiziert; R21 2k → 500 mA = exakt die DS-Beispielschaltung ✓.
5. **STM32 VSS-Pin 99 war nur ZUFAELLIG geerdet** (der alte horizontale
   VSSA-Stub lief ueber seinen Anker). DS12110 Fig. 5: VSS = 10/26/49/74/**99**.
   Neu: expliziter Stub; VSSA-Stub senkrecht wie alle Unterseiten-Pins.

### Verifiziert OHNE Befund (gegen Original-Datenblätter)

- **MCP23017-E/SS**: SSOP-Pinout = SOIC/SPDIP (DS20001952 S. 1) — Generator ✓.
- **PCA9685PW**: TSSOP28 Tabelle 3 — alle 28 Pins ✓ (U6 + U10).
- **USBLC6-2SC6**: 1/6=I/O1, 3/4=I/O2, 5=VBUS, 2=GND ✓ Up/Downstream-Paarung ✓.
- **STM32H743 LQFP100**: komplette Pin-Map gegen DS12110 Fig. 5 ✓ (VBAT 6,
  VDD 11/27/50/75/100, VSSA 19, VREF+ 20, VDDA 21, VCAP 48/73, BOOT0 94).
- **ABLS-8.000MHZ-B4-T**: CL = 18 pF (live) → 27-pF-Load-Caps korrekt ✓.
- **D2 SMAJ5.0A**: Kathode→Rail, Anode→GND ✓. **USB-C**: Symbol-Pins A1…B12/S1
  = KiCad-Footprint-Pads ✓. **HX B3F-4055 (SW6–10)**: interne Paarung
  ①-② / ③-④ (Reihen) = Footprint-Pad-Paarung ✓; Lochreihenabstand 5,08 vs
  DS 5,00 — von Ø1,5-Drill absorbiert (Layout-Nicety fuer Aron).
- Bereits frueher DS-verifiziert: TPS61089, TPS22918, MST-12D18G3, AP7361C,
  PCM5102A, PAM8403H, L1 SWPA6045, Kailh Choc, TS-1088.

### Verifikation

ERC 0 Fehler auf allen 7 Sheets; Generator deterministisch; jlc_bom.csv
58 Parts / 210 Placements (+R_DET_J8, C_DET_J8, C_CHG_IN); Host-Tests
352298 Checks, 0 Failures.

---

## v0.7-r18.81 (2026-07-02) — Power-Off-Block (ADR-0016) endlich im Schematic + „+5V"-Netz-Brücke + SW_PWR-Seitenmontage verifiziert

User (mit Foto vom Schalter-Render): „What about the side button on off switch.
I don't think the one we have works. the pcb will be a normal pcb, not vertical,
but horizontal … is the on off switch mount actually mountable that way, that I
can use the on off switch from the side?"

### 1. SW_PWR-Seitenmontage: JA — gegen das Original-Datenblatt verifiziert

MST-12D18G3-Datenblatt (SHOU HAN, via LCSC-PDF, Zeichnung S. 1 gerendert):
Body liegt FLACH auf der (horizontalen) PCB (3 SMD-Beine + 2 Locator-Pegs in
Ø0,9-Bohrungen), der Schiebe-Stem (1,5×1,5 mm) ragt **HORIZONTAL** 3 mm über
die Body-Kante — gegenüber der Pin-Seite, Oberkante 0,2 mm unter Body-Top
(Body 4,0 mm) → Stem-Fenster z ≈ 2,3–3,8 mm über der PCB-Oberfläche; Travel
2 mm ±0,2 bei 200 gf lateral. **Am Board-Rand platzieren, Stem durch einen
Slot in der Gehäuse-Seitenwand — genau die gewünschte Seitenbedienung.** Der
vendored Footprint stimmt EXAKT mit dem offiziellen Land-Pattern MSK12D
überein (3 Pads 1,2 @ 2,5 mm Pitch; Löcher Ø0,9 @ 6,8 mm; Versatz 3,2 mm =
2,1 + 2,2/2). Das 3D-Render (User-Foto) schwebt nur beliebig orientiert im
Viewer — daher der „zeigt der nicht nach oben?"-Eindruck. OFFEN (UNVERIFIED —
NEEDS HUMAN CHECK): Terminal-Belegung Common=Mittelpad ist 1P2T-Konvention,
das DB labelt die Pins nicht → vor Fab durchpiepen (Falsch-Fall fail-safe:
Gerät ginge nur nicht an, R_PWR_PD hält PWR_ON low).

### 2. KRITISCH gefunden: der beschlossene Power-Off-Block war NIE im Schematic

ADR-0016 (User-Entscheidung 2026-06-27, inkl. Pin-Level-Drop-in-Spec) war
dokumentiert, HTML/BOM_MASTER listeten U_PWR/SW_PWR — aber weder Generator
noch jlc_bom.csv enthielten sie: das Board hätte KEINEN Ein/Aus-Schalter
gehabt. r18.81 zeichnet den Block in power_tree ein:
`+5V_RAIL → U_PWR (TPS22918, C131941 live verifiziert) → +5V_SW → LDO-VIN`;
`SW_PWR`-Common → `PWR_ON` = U_PWR.ON, Throw A → +5V-Rail, `R_PWR_PD` 100k
→ Default AUS; `C_UPWR_IN` 1µF (TI-DS Pin-1-Note), `C_PWR_SW` 10µF auf
+5V_SW. Lader U7 hängt VOR dem Switch → „dunkel, aber lädt". ADR-Korrekturen
gegen TI SLVSD76C (Pinout-Seite gerendert): Pin 4 heißt CT (nicht „NC";
floaten DS-erlaubt = schnellster Anstieg, CT-Cap = optionaler Soft-Start);
QOD floaten würde die Quick-Discharge DEAKTIVIEREN → QOD an VOUT gebunden
(DS-Option 2, aktive Entladung im Aus). Neue Lib-Symbole
Power_Switch:TPS22918 + Switch:SW_SPDT.

### 3. KRITISCH gefunden: globales „+5V"-Netz war eine quellenlose Insel

Auf KEINEM Sheet existierte eine Brücke zwischen dem +5V_OUT-Hier-Netz (der
realen Diode-OR-Rail) und dem globalen „+5V"-Netz der Power-Symbole. Folge im
Netlist: PAM8403-PVDD/VDD (Audio), alle 23 LED-Anoden (mcp) und LED_CHRG
(battery) hingen an einem Netz OHNE Quelle — Amp und sämtliche LEDs wären tot
gewesen. Fix: die Rail trägt jetzt das globale +5V-Flag (Brücke bei (118,60));
per ADR-0016 bleibt +5V bewusst UNgeschaltet (Amp geht über AMP_nSHDN-Pulldown
aus, LED-Treiber sitzen in der geschalteten 3V3-Domäne → dunkel im Aus).

### Verifikation

Geometrisches ERC: 0 Fehler auf allen 7 Sheets. Netz-Trace (Union-Find inkl.
globaler Power-Netze): VIN=Rail ✓, VOUT=+5V_SW=LDO-IN/EN=QOD ✓, +5V_SW≠Rail ✓,
COM=ON ✓, ThrowA=Rail ✓, ThrowB isoliert ✓, R_PWR_PD/Caps korrekt ✓, Rail=+5V
global ✓ (11/11). Generator deterministisch; jlc_bom.csv 58 Parts / 207
Placements (+C131941, +C49023766). Host-Tests grün.

---

## v0.7-r18.80 (2026-07-02) — Geometrisches Pin-Level-ERC: 8 Kupfer-Fehler + Boost-Loop-Instabilität behoben

User: „Any other logical issues or something that will ruin the pcb?" — Antwort: ja, mehrere.
Methode: headless geometrisches ERC (Python) über alle 7 Sheets — jeder Pin-Anker
gegen jedes Wire-Segment, Label-Anker gegen Kreuzungspunkte, Union-Find-Netzbau,
Hier-Label↔Root-Sheet-Pin-Namensabgleich. Jeder Fund im Generator-Quelltext verifiziert.

### KRITISCH — Kurzschlüsse (Pin-/Label-Anker exakt auf fremden Wires)

1. **power_tree: USB D+ UND D− hart auf +5V** — der U5-LDO-Block (120,80) sass im
   USB-Daten-Korridor: EN-Pin (111.11, 77.46) lag AUF dem USB_DP-Wire, IN-Pin
   (111.11, 82.54) AUF dem USB_DM-Wire, Rail-Drop x=110 überlappte den D1-VBUS-Wire.
   → USB tot, H7-USB-PHY-Gefahr. Fix: LDO-Block nach (130,130), Rail-Tap x=120.
2. **mcp: I2C_SCL hart auf GND** — C5 (U2-VDD-100nF) hing 7,62 mm nach unten;
   Pin 9 (VDD) und Pin 12 (SCL) liegen exakt 3 Rasterzeilen = 7,62 mm auseinander →
   C5-GND-Pin (108, 121.43) sass AUF dem SCL-Wire. → kompletter I²C-Bus tot
   (U2 + U6 + U10 = alle Switches, alle LEDs). Fix: C5/C5b nach x=93/88.
3. **audio: PCM_XSMT hart auf GND** — C8a/C8b-GND-Pins (120/124, 96.19) sassen AUF
   dem XSMT-Wire (Pin 17, gleiche 7,62-mm-Falle wie #2). → DAC permanent gemutet.
   Fix: Caps nach oben geklappt (rot=180, GND oberhalb).
4. **audio: I2S_LRCK hart auf GND** — C_LDOO-GND-Pin (117, 101.27) sass AUF dem
   LRCK-Wire (Pin 15, dieselbe Falle). → kein Wordclock, Audio tot. Fix: hochgeklappt.
5. **stm32: BOOT0 permanent HIGH (2 Fehler)** — (a) +3V3-Flag sass bei (100,184) =
   exakt der BOOT0-Rail-Punkt → +3V3 direkt auf BOOT0; (b) der SW_BOOT-Pin-1-Wire
   lief DURCH den Pin-2-Anker → Taster dauerhaft überbrückt. → H7 bootet IMMER in
   den ROM-Bootloader, nie in die Firmware („totes Board"). Fix: Pfad unten herum,
   +3V3-Flag oben an R_BOOT_SW.
6. **stm32: VDDA mit VDD verkupfert** — der VDDA-Pin-21-Stub lief horizontal DURCH
   den VDD-Pin-100-Anker (145.08, 61.42) → FB2-Filter überbrückt. Fix: Stub senkrecht
   nach oben (wie alle Top-Pins).
7. **battery: C_BOOT kurzgeschlossen (Label-Falle)** — das U8_SW_NODE-Label bei
   (154, 83.65) sass exakt auf der Kreuzung SW-Wire × boot-up-Wire → KiCad hätte
   BOOT- und SW-Netz verschmolzen → kein Bootstrap, Boost startet nicht. Fix: Label
   entfernt (Netz benennt das Label bei x=141).

### KRITISCH — Unterbrechungen

8. **lcd: J3 komplett unverbunden (alle 8 Pins)** — Verdrahtung nahm KiCad-Standard-
   Pins links (−5.08) an; die Custom-Lib Conn_01x08 hat Pins RECHTS (+3.81/180°).
   → GND, VCC, SPI, Backlight: alles floatend. Fix: J3 rot=180 + jpy()/PINX neu.
9. **stm32: J4 SWD-Header alle 3 Pins floatend** — gleiche −5.08-Annahme. → Board
   nicht flash-/debugbar. Fix: Stubs rechtsseitig an die echten Pin-Anker.
10. **stm32: FB2 beidseitig floatend** — rotation=90 (Pins vertikal), Wires horizontal.
    → VDDA ohne Versorgung über den Filter (nur der Zufalls-Kurzschluss #6 versorgte
    sie). Fix: rotation=0.
11. **stm32: lib_symbols-Name „STM32H743VIT6" ohne „MCU:"-Prefix** — die Instanz
    referenziert `MCU:STM32H743VIT6`, KiCad matcht exakt → U1 wäre in KiCad ein
    unaufgelöstes Symbol (keine Pins, kein Netlist-Export). Fix: Prefix ergänzt.

### KRITISCH — Boost-Regelkreis (TPS61089, TI SLVSD38C nachgerechnet)

12. **R_COMP 22k / C_COMP 1nF → 6,2k / 10nF; C_BOOST_OUT 1× → 3× 22 µF.**
    Gl. 15/17/18 mit VREF 1,212 V, GEA 190 µS, Rsense 0,08 Ω: fRHPZ ≈ 47 kHz
    (VIN 3,0 V, 2 A) → fc-Limit fRHPZ/5 ≈ 9,5 kHz. Alt: fc ≈ 87 kHz — ÜBER der
    RHP-Nullstelle → Loop-Oszillation unter Last bei leerem Akku. Neu: fc ≈ 8 kHz.
    Formeln gegen TIs eigenes 9-V/2-A-Referenzdesign validiert (reproduziert exakt
    deren 17,4k/4,7nF). Output-Caps: TI „typically three 22 µF", EC-Tabelle rechnet
    Soft-Start mit 47 µF effektiv; 1× 22 µF-0805 hat bei 5-V-Bias nur ~12 µF eff.
    (Ripple wäre ~150 mV); der 470-µF-Bulk liegt HINTER D3 → Regelknoten sieht ihn
    nicht. Neu: 3× C45783 → CO_eff ≈ 36 µF, Ripple ~50 mV. **Neues Teil: R 6,2k
    0603 1% = C4260 (0603WAF6201T5E, JLC Basic, 219k Stock — live verifiziert).**

### Metadaten / Hygiene (JLC bestückt nach C-Nummer — Werte-Text log)

- **C45783 = CL21A226MAQNNNE 22 µF 25 V** (live verifiziert): STM32-VDD-Bank und
  C_BAT_IN behaupteten „4,7 µF CL21A475KQFNNNE" — falsch beschriftet (bestückt
  worden wäre 22 µF; elektrisch unkritisch, Doku/BOM-Texte korrigiert).
- **C15850 = CL21A106KAYNNNE 10 µF 25 V** (live verifiziert): 8× MPN-Suffix
  „KOQNNNE" (16-V-Variante) korrigiert.
- **C14663 = CC0603KRX7R9BB104** (live verifiziert): 5× falscher MPN
  „CL10B104KO8NNNC" (+2× „-class"-Pseudo-MPNs) vereinheitlicht.
- mcp: U10 LED8–15 (Pins 15–22, unbenutzt) mit expliziten No-Connect-Markern.
- battery: Rest-Stub (75,86.19)→(75,80) aus verworfenem Bus-Ansatz entfernt.
- lcd: freischwebendes „+3V3"-Label entfernt.

### Verifikation

- Geometrisches ERC: **0 Fehler auf allen 7 Sheets** (vorher: 22 Fehler/kritische
  Merges). Hier-Label↔Root-Sheet-Pin: alle Namen matchen. Generator deterministisch
  (2 Läufe, identische MD5). `jlc_bom.csv`: 56 unique Parts, 202 Placements.
- kicad-cli 7.0.11 kann das v9-Format der Sheets nicht laden (Distro-Limit) —
  ERC-/GUI-Pass in KiCad 9 bleibt Human-TODO wie gehabt.

---

## v0.7-r18.79 (2026-07-01) — Elektrik-Audit: 3 kritische Power-Fehler behoben

User: „Überprüfe nochmal BOM und PCB components und connections. Nicht
mechanik. Schaue dass keine kritischen fehler existieren."

Systematischer Elektrik-Review: Hier-Label↔Root-Pin-Matching, Root-Verdrahtung
(Union-Find über Wire-Endpunkte + Label-Merge), hängende Netze, Refdes-
Dubletten, I²C-Adressen, Pull-ups, Boost-Schaltung gegen das TI-Datenblatt
(SLVSD38C, Formeln von den gerenderten PDF-Seiten abgelesen, nicht geraten).

### 🔴 Fund 1 — Boost-FB-Teiler: Rail wäre 7,43 V statt 5 V gewesen

- R23/R24 = 200k/39k, VREF laut TI-EC-Tabelle **1,212 V** → VOUT = 1,212 ×
  (1+200/39) = **7,43 V**. PAM8403 (abs max 5,5 V) und der geplante TPS22918
  (5,5 V) wären beim ersten Einschalten zerstört worden, AP7361C (6 V max)
  überfahren.
- **Fix:** R23 = **121k** (0603WAF1213T5E, **C25809**, 71k Stock, live
  verifiziert) → VOUT = **4,97 V**. (122k für exakt 5,00 V hat keinen
  verifizierbaren LCSC-Bestand; −0,6 % ist die sichere Richtung.)

### 🔴 Fund 2 — R_ILIM 20k = 51,5 A Stromlimit (faktisch keins)

- TI Gl. 4: ILIM = 1.030.000/R_ILIM. Der Generator-Kommentar behauptete
  „20k → ~4 A“ — real wären es **51,5 A**; der Induktor (Isat min 6,75 A)
  hätte im Fehlerfall ungebremst gesättigt.
- **Fix:** R_ILIM = **174k** (0603WAF1743T5E, **C22890**, live verifiziert)
  → 5,92 A typ / 5,12 A min (≥ Worst-Case-Peak ~4,7 A) / ~6,7 A max
  (≤ Isat-min 6,75 A).

### 🔴 Fund 3 — Q1-Power-Path: Backfeed + Fuse-Bypass

- Alt: Q1 P-FET S=VBUS (pre-fuse), D=+5V-Rail, G→GND — UND power_tree
  exportierte den Rail direkt hinter F1. Ohne USB: Boost-5V → Q1-Body-Diode
  (und parallel durch F1, Polyfuses leiten bidirektional) → VBUS ≈ 4,3 V →
  Gate-Vgs −4,3 V → Q1 voll leitend → **Lader U7 (VDD=VBUS) lädt den Akku aus
  dessen eigenem Boost** (Selbstentladeschleife ~1,5× Ladestrom), USB-Detect
  (MCP GPA7) dauerhaft HIGH, 5 V am offenen USB-C-Stecker. Mit USB: Laststrom
  lief über Q1 **an F1 vorbei** (pre-fuse→post-fuse) — Kurzschlussschutz
  ausgehebelt.
- **Fix:** Q1 + R22 entfernt; **Dioden-OR**: USB → F1 → [D2-TVS pre-Diode] →
  **D3B** (2. SS34, gleicher Code C8678) → Rail ‖ Boost → D3 → Rail. Kein
  neues/unverifiziertes Bauteil; Kosten ~0,35 V Drop im USB-Pfad (Rail ~4,6 V
  an USB — LDO braucht >3,6 V, PAM8403 2,5–5,5 V: unkritisch).

### 🟡 Kleinere Funde

- R_FSW 360k = **~440 kHz** (TI Gl. 3), nicht „1,21 MHz“ wie seit r12-B11
  kommentiert — 440 kHz ist zulässig (200 kHz–2,2 MHz) und weit über dem
  Audioband; Widerstand bleibt, Kommentare/Doku korrigiert.
- FSW-Widerstand hängt korrekt am SW-Node — TI-DS sagt ausdrücklich
  „resistor between this pin and the SW pin" (mein anfänglicher
  GND-Verdacht war falsch — per Datenblatt geklärt, nicht geraten).
- PINMAP: „AP7361A-33ER“ → AP7361C-33 (Doku-Drift); PCB_BOM-Restdrift auf
  r18.70-Stand gezogen (C_BULK2 C23742, LED_CHRG C965800, VCAP C23630).
- Root-Sheet: `+3V3_OUT`/`GND_OUT`-Sheet-Pins hängen unverdrahtet (Rails
  laufen über globale Power-Symbole — kosmetisch, ERC-Hinweis für Aron).

### ✅ Ohne Befund verifiziert

Hier-Labels ↔ Root-Pins vollständig; Root-Verdrahtung verbindet alle
Partner-Pins; 0 Refdes-Dubletten (200 Instanzen); I²C 0x20/0x40/0x41
kollisionsfrei (U10-A0 an +3V3 nachgemessen); BOOT0 10k-Pull-down + 1k-Serie
korrekt; NRST 10k+100nF; CC1/CC2 je eigener 5,1k; VCAP 2×2,2 µF; USBLC6-
Verdrahtung; MCP_INT→PC13; PCM5102A-Konfigpins + Charge-Pump-Caps;
Cell-/Modifier-/Encoder-Netze. KiCad-GUI-ERC bleibt finaler Gate (Aron).

---

## v0.7-r18.77 (2026-07-01) — L1-Boost-Inductor: toter LCSC-Link + nicht existente MPN gefunden + behoben

User klickte auf L1 in der Aron-BOM-HTML ("SWPA6045 2.2µH") — die LCSC-Seite
existierte nicht.

### 🔄 L1: SWPA6045S2R2MT/C83455 → SWPA6045S2R2NT/C36500

- **C83455 404t** — nie ein echtes Listing, trotz einer r18.20c-Notiz die es
  fälschlich als "✓ Extended verifiziert" führte.
- **Die MPN war auch falsch:** `SWPA6045S2R2MT` existiert laut Sunlords
  eigenem Datenblatt (Item 2, Produkt-ID-Schema) gar nicht — die
  "M"-Toleranz-Endung (±20%) gibt es nur ab 4,3 µH aufwärts; 2,2 µH gibt es
  nur mit "N"-Endung (±30%). Der r18.37-BOM↔Generator-String-Diff-Audit
  hatte das nicht gefunden, weil BOM_MASTER und Generator **denselben**
  falschen Code trugen — ein Konsistenz-Check zwischen zwei Dokumenten fängt
  keinen Fehler, der in beiden identisch falsch ist.
- **Echtes, verifiziertes Teil:** SWPA6045S2R2NT, LCSC **C36500** — live via
  JLCPCB-Katalog geprüft und gegen jeden Wert in Sunlords offiziellem
  SWPA6045S-Datenblatt (Item 12, Elektrische Charakteristiken) abgeglichen:
  2,2 µH, DCR 18 mΩ max, Isat 6,75 A max / 7,40 A typ, Irms 4,60 A max /
  5,00 A typ.
- **Bonus-Fund:** der `value`-String im Schematic beschrieb noch ein
  **komplett anderes, älteres Bauteil** — "Sumida CDR63B-2R2" im "0630"-
  Gehäuse (6,0×3,0mm) — ein Relikt aus einer früheren Design-Iteration,
  bevor auf das Sunlord SWPA6045S (6,0×6,0×4,5mm) gewechselt wurde. Auch in
  `PCB_FOOTPRINT_RISK_AUDIT.md` steckte ein fabrizierter "Isat 4,5A"-Wert,
  der zu keiner Datenblatt-Zeile passte — korrigiert auf die echten Werte.
  `ADR-0011` (Gehäuse-Z-Budget) hatte fälschlich 3,0mm Bauhöhe (Sumida-Ära)
  statt der echten 4,5mm (Sunlord) — der Encoder (19mm) dominiert das
  Z-Budget trotzdem weiterhin, keine Kaskaden-Auswirkung.
- Aktualisiert: Generator (Footprint-Value-String + MPN + LCSC + FP_NOTE),
  regenerierte Schematics/BOM/Aron-HTML, `BOM_MASTER.md`, `PCB_BOM.md`,
  `field_ambience_pcb_SPEC_v0.7.md`, `PCB_FOOTPRINT_RISK_AUDIT.md`,
  `mechanical/3d_models/MANIFEST.md` (hatte zusätzlich Q1s LCSC-Code statt
  L1s eigenem), `ADR-0011-enclosure-thickness.md`.

---

## v0.7-r18.75 (2026-07-01) — Cells: direkt gelöteter Kailh-Choc-V1 statt Hotswap-Socket

User: „This is wrong. How is this meant to be soldered onto a pcb? maybe we can
just directly solder the kalih choc on the pcb? because i don't know how this
would work."

### 🔄 Cells: Hotswap-Socket → Direct-Solder (r18.74 → r18.75)

- Der r18.74-Plan (Kailh-Choc-V1/V2-Hotswap-Socket) hatte zwei echte Probleme:
  (1) der Socket selbst hatte **keine saubere Hersteller-/LCSC-Teilenummer**
  (Keyboard-Markt-Ware), (2) er hätte eine **nicht offensichtliche Klein-SMD-
  Handlöttechnik** gebraucht (2 winzige SMD-Pads von hinten löten, Switch klickt
  separat von vorne rein) — der User fragte zu Recht nach, wie das überhaupt
  gehen soll.
- **Fix:** der Kailh-Choc-**V1**-Switch (**CPG135001D01**, LCSC **C400229**,
  rot/linear) wird jetzt **direkt auf die Platine gelötet** — 2 THT-Beinchen
  durch 2 Löcher, von hinten verlötet, **exakt dieselbe Technik wie jeder
  andere Button/Connector in diesem Design**. Kein Socket mehr, keine
  Spezialtechnik.
- Footprint + 3D-STEP-Modell direkt von LCSC/EasyEDA für dieses exakte Teil
  gezogen: `easyeda2kicad --full --lcsc_id=C400229` — genau der Weg, den
  dieses Repo bereits für alle anderen Custom-Footprints vorschreibt (TS-1088,
  MST-12D18, PJ-320D). Vendored als `field_ambience:SW_KailhChoc_CPG1350_THT_2P`
  + zugehöriges STEP. Nicht aus einer Keyboard-Hobby-Bibliothek — direkt vom
  Hersteller-Listing.
- 2 elektrische THT-Pins + 3 unbestückte Mechanik-Löcher (die eigenen
  Locator-Pegs des Switch-Gehäuses geben seitliche Stabilität ohne Plate).
- **Trade-off:** der Switch ist jetzt fest verlötet, nicht mehr tauschbar wie
  beim Hotswap-Ansatz — eingetauscht gegen Löt-Einfachheit und ein wirklich
  verifiziertes Bauteil statt eines unverifizierten Zwischenteils.
- Elektrisch **unverändert** seit r18.73/74: `CELL1..5_BTN` auf MCP23017
  GPA0–GPA4, Pull-Up, IRQ — nur das physische Bauteil + Footprint ändern sich.
- Modifier-Buttons SW6–SW10 bleiben unverändert (HX B3F-4055).
- Aktualisiert: Generator (nur SW1–5-Block + neu vendorte Footprint/STEP-Dateien
  in `field_ambience.pretty`/`field_ambience.3dshapes`), regenerierte
  Schematics/BOM/Aron-HTML, `BOM_MASTER.md` §7, `PCB_BOM.md`, `PINMAP.md`,
  `KICAD_BLUEPRINT.md`, `SCHEMATIC_WALKTHROUGH.md`,
  `MECHANICAL_REQUIREMENTS.md` §1.5, `PCB_FOOTPRINT_RISK_AUDIT.md`
  (UNKNOWN-Zähler zurück auf 0), `mechanical_coordinates.md` §3.4, `ADR-0013`,
  `field_ambience_pcb_SPEC_v0.7.md` §5.6a, `PROJECT_STATUS.md`,
  `COST_ESTIMATE.md`, `MANUFACTURING_START.md`.

---

## v0.7-r18.74 (2026-07-01) — Cells: echter Kailh-Choc-Keyswitch statt Modifier-Tactile (UX-Fix)

User: „die 5 cells hast du in der html stehen als normale tactile switches,
aber es wäre ja besser wenn es trotzdem so tastatur keyboard dinger sind und
nicht wie die modifier, auch einfach tactile buttons.. das macht das ux kaputt"

### 🔄 Cells: HX-B3F-Tactile → Kailh-Choc-Hotswap (elektrisch unverändert)

- r18.73 hatte SW1–SW5 auf **dasselbe Bauteil wie die Modifier SW6–SW10**
  gesetzt (HX B3F-4055-Y THT-Tactile) — das machte die spielbaren Cells
  ununterscheidbar von simplen Modifier-Knöpfen, kein "Tastatur"-Gefühl mehr.
- **Fix:** Cells bleiben elektrisch digital (identische Netze `CELL1..5_BTN`
  auf MCP23017 GPA0–GPA4, Pull-Up, IRQ), bekommen aber einen **echten Kailh-
  Choc-V1/V2-Keyswitch über Hot-Swap-Socket** zurück — ~3 mm echter
  mechanischer Hub, Switch klickt von vorne rein (kein Löten), tauschbar.
  Genau die „Plain Choc V2"-Option aus ADR-0013s eigener Vergleichstabelle.
- Footprint: `Switch_Keyboard_Hotswap_Kailh:SW_Hotswap_Kailh_Choc_V1V2_Plated_1.00u`
  — bereits vendored im Repo (MIT, `keyswitch-kicad-library`), bereits in
  `fp-lib-table` registriert, community-verifiziert (verbreitet in
  produktiven mechanischen-Tastatur-PCBs). **Nicht** unabhängig gegen Kailhs
  eigene Maßzeichnung re-verifiziert — Pad-Pitch/Bohrungen vor Bestellung
  gegenchecken.
- **Der Hot-Swap-Socket selbst hat keine saubere Hersteller-/LCSC-Teilenummer**
  — Keyboard-Markt-Ware (z. B. Chosfox "Kailh Choc PG1350 Hot Swap Socket"
  ~$1.45/10 Stk, auch Kailh direkt/Mechkeys), offen als
  `UNVERIFIED — NEEDS HUMAN CHECK` markiert statt geraten.
- Der Choc-Switch, der reinklickt (nicht gelötet): ein reales, verifiziertes
  Beispiel bei LCSC **C400229** (Kailh CPG135001D01, rot/linear) — Farbe/
  Feel/V1-vs-V2 ist Industrial-Design-Entscheidung, keine Schematic-Frage.
- Modifier SW6–SW10 bleiben **unverändert** HX-B3F-4055 — bewusster
  UX-Unterschied (Cells = echtes Keyboard-Feel, Modifier = simples Tactile).
- Aktualisiert: Generator (nur SW1–5-Block), regenerierte Schematics/BOM/
  Aron-HTML, `BOM_MASTER.md` §7, `PCB_BOM.md`, `PINMAP.md`, `KICAD_BLUEPRINT.md`,
  `SCHEMATIC_WALKTHROUGH.md`, `MECHANICAL_REQUIREMENTS.md` §1.5,
  `PCB_FOOTPRINT_RISK_AUDIT.md`, `mechanical_coordinates.md` §3.4, `ADR-0013`,
  `PROJECT_STATUS.md`, `COST_ESTIMATE.md`.

---

## v0.7-r18.73 (2026-06-30) — Cells → digitale I²C-Switches (ADR-0013 SUPERSEDED)

User: „mach lieber das, austauschen … HiChord macht es sehr wahrscheinlich nicht
mit Gateron Magnetic Switches + Hall-Sensoren. … Mach die Cells erstmal digital
wie HiChord Batch 4+. Mechanische Switches, Caps/Plate, I2C Expander."

### 🔄 Cells: Hall/ADC → digitale Switches am MCP23017

- **Entfernt** (STM32-Sheet): 5× DRV5056A4 Hall-Sensor (J_CELL1–5, C2152902),
  5× R_CELL 1 kΩ (C21190), 5× C_CELL 10 nF (C57112). STM32-ADC-Pins
  PC0/PC1/PA4/PB0/PB1 → NC-Reserve (Rev-B).
- **Neu** (mcp-Sheet): SW1–SW5 Tactile-Switches auf MCP23017 GPA0–GPA4
  (Netze `CELL1..5_BTN`, Pin → GND, MCP-interner Pull-Up + IRQ-on-change),
  exakt wie die Modifier SW6–SW10. **Gleiches Bauteil:** HX B3F-4055-Y
  (C36498965). **Kein neues Bauteil** — MCP23017 + Switch standen bereits
  verifiziert in der BOM.
- HiChord-Batch-4+-Topologie (Switch → I²C-GPIO-Expander → MCU). Stellt die
  ursprüngliche SPEC-v0.6-§7-„10 Switches"-Topologie wieder her (5 Cells +
  5 Modifier am Expander).
- Hall + Magnet bleibt als dokumentierte Option (ADR-0013) nur falls echte
  Drucktiefe/Velocity später gewünscht ist.
- Aktualisiert: Generator + regenerierte `.kicad_sch`, `jlc_bom.csv`,
  `docs/hardware/bom_overview.html` (Aron), `BOM_MASTER.md`, `PCB_BOM.md`,
  `PINMAP.md`, `KICAD_BLUEPRINT.md`, `SCHEMATIC_WALKTHROUGH.md`,
  `MECHANICAL_REQUIREMENTS.md`, `ADR-0013`, `PROJECT_STATUS.md`.

---

## v0.7-r18.30 (2026-06-15) — leds.c + Menü-Encoder + MIDI deferred

User: „vielleicht brauchen wir gar kein MIDI? Rest ausbauen."

### 🟡 MIDI deferred (ADR-0004 r18.30)

J9 wird im 5er-Prototyp-Run **NICHT bestückt** (DNP). Hardware-Vorarbeit
konserviert (Footprint + Edge-Cutout + PD5-Pin-Reservierung), Code bleibt
(`src/midi.c` + `src/hal_h743/midi_uart_h743.c`), aber `midi_tx_init()` ist
in `main_h743.c` auskommentiert. Reaktivierung später = J9 + 2× 220 Ω
bestücken + 1 Zeile uncommenten. ADR-0004 als „DEFERRED" markiert mit
Original-Diskussion erhalten.

### NEU leds.c + leds.h — controls/modifier state → PCA9685 16-ch PWM

Hardware-unabhängiges LED-Render-Modul (16. Suite):
- 16-Kanal-Mapping per SPEC §7.2 (vs Generator-Z.4459 verifiziert)
- Per-Channel-Fade-Engine: 0↔TARGET über LED_FADE_MS = 120 ms
- Per-Farbe-Duty-Matching (gelb 70 %, grün 100 %, weiß 80 % wegen Vf-Diff)
- ADR-0008-r2-konform: gelb (ch 5/7/9/11/13) zeigt `controls_hold_base[c]`,
  grün (ch 6/8/10/12/14) zeigt `controls_hold_shift[c]` — **unabhängig**
- Clear-Flash auf ch 4 (250 ms on Clear-Press)
- Backlight (ch 15) eigenständig settbar
- API: `leds_render(now, dt, out[16])` → der HAL pusht `out[]` per
  `pca_set_pwm()` über I²C

### NEU test_leds.c (16. Suite, 28 Checks)

Boot-Dark, alle Modifier-Channels, Cell-Pärchen (base+shift gleichzeitig =
Oktav-Stack), Clear-Flash + Decay, Backlight, Fade-Out, Mid-Fade-Interpolation.
16/16 Suiten PASS.

### Menü-Encoder verdrahtet

`src/hal_h743/main_h743.c`: DISPLAY-Encoder-Rotate → `menu_rotate(delta)`,
Push → `menu_push()`. LED-Render-Loop bei 60 Hz mit `pca_set_pwm`-Burst.

### Firmware-LOGIK-Stand: komplett ✅

DSP-Engine, cells (Velocity), controls (Hold-Latch + Modifier), params
(Encoder-Bindings), leds (16-ch-PWM + Fade), menu-Encoder-Binding —
**alles hardware-unabhängig + host-getestet**. Der STM32-Build muss nur
noch die HAL-Reads/-Writes (HAL_GetTick, mcp_read, adc_read, pca_set_pwm,
oled_show) gegen ST-HAL füllen.

### Verbleibt für lauffähigen STM32-Build (Step 13.3)

ARM-GCC-Toolchain-File, Linker-Script, Startup-File, CubeH7-HAL-Sources,
SystemClock_Config (PLL1 480 MHz, PLL3 11.2896 MHz), 6× HAL-Body-Stubs
mit echten `HAL_*`-Calls füllen.

---

## v0.7-r18.29 (2026-06-15) — params.c + STM32-Main-Loop-Verdrahtung

Fortsetzung des Firmware-Ausbaus.

### NEU params.c + params.h — Encoder → Engine-Parameter

Die 3 Audio-Knöpfe an die Engine gebunden, mit der SPEC-§5-Velocity-
Acceleration (langsam = 1 %/Klick, schnell bis ×8):
- EN1 DRIVE → engine_set_reverb_drive (0..100 %)
- EN2 BRIGHT → engine_set_brightness (−600..+800 Hz, 20 Hz/Detent)
- EN4 VOLUME → engine_set_master_volume (0..100 %)
- EN3 DISPLAY → ignoriert (Menü besitzt diesen Encoder)
Per-Encoder-Acceleration-State, Clamp an Range-Grenzen, Defaults = engine_init-
Werte (drive 15 %, volume 60 %, bright 0).

### Test (15. Suite)

`test/test_params.c` — 12 Checks: Defaults, langsame Detents = 1 %/Step,
Richtung, Clamp 0/100, Acceleration (fast > slow), Brightness-Hz + Clamp,
DISPLAY ignoriert. 15/15 Suiten PASS.

### STM32-Main-Loop verdrahtet (main_h743.c)

`src/hal_h743/main_h743.c` Main-Loop konkretisiert: routet
Encoder-Events → `params_encoder()` / Menü, MCP23017-Button-Edges →
`controls_modifier()`, Cell-Hall-ADC → `cells_update()` → `controls_cell_*()`.
Die gesamte Spiel-LOGIK ist hardware-unabhängig + getestet — die verbleibenden
TODOs sind nur noch HAL-Reads (HAL_GetTick, adc_read, mcp_read), keine Logik.

controls.c + params.c in CMake-DSP_SOURCES (target-unabhängig, alle 3 Targets).

### Firmware-Logik-Stand

Komplett + host-getestet: DSP-Engine, cells (Velocity), controls (Hold-Latch +
Modifier), params (Encoder-Bindings). Verbleibt: STM32-Toolchain + ST-HAL-
Bodies (Step 13.3), SystemClock-Config, Menü-Navigation-Feinschliff.

---

## v0.7-r18.28 (2026-06-15) — controls.c: Hold-Latch + Modifier-Handler

User: „wieso meintest du alles ist fertig wenn wir noch nicht mal die Firmware
drumherum haben? Ausbauen." → Berechtigt. „Schematic order-fähig" hatte ich
fälschlich mit „Gerät fertig" vermischt. Beginn des Firmware-Ausbaus mit der
zentralen Logik-Lücke.

### NEU controls.c + controls.h — hardware-unabhängige Spiel-Logik

Die Bedien-Logik, die bisher NUR im Web-Sim lebte, jetzt als getestetes
C-Modul (Single Source für STM32 + Bench):
- **Hold-Latch-State-Machine (ADR-0008 r2):** `hold_base[5]` + `hold_shift[5]`,
  zwei unabhängige Bit-Arrays → Cell kann base, shift, oder BEIDE (Oktav-Stack)
  halten. Tap toggelt den vom Shift-State gewählten Branch.
- **Modifier-Handler:** Shift/Hold (latching), Drone/Generate (latch +
  forward an engine_set_drone / engine_set_generative), Clear (momentary:
  wipe alle Holds + Silence).
- **Momentary-Modus** (ohne Hold): Cell-Press = Note an, Release = aus;
  Shift wählt Oktave.
- **Velocity** kommt aus cells.c (ADR-0013), als amp-Parameter durchgereicht.
- Voice-Routing: base → source 0..4, shift → source 9..13 (kollidiert nicht
  mit Gen-Bed-Source 8).

### Test (14. Suite)

`test/test_controls.c` — 19 Checks: momentary tap+release, Hold-Latch-Toggle,
Shift+Hold unabhängig von base, Oktav-Stack (beide Bits), Clear wischt +
Tail decayt, Drone/Generate latchen + klingen, Release-Edge lässt Hold-Latch
in Ruhe. Alle 14 Suiten PASS.

### Was der STM32-Button-Handler jetzt nur noch tun muss

`src/hal_h743/main_h743.c`: MCP23017-Button-Edges in `controls_modifier()` /
`controls_cell_press/release()` einspeisen — die gesamte Spiel-Logik liegt
hardware-unabhängig vor und ist getestet.

### Verbleibend im Firmware-Ausbau

- Encoder→Engine-Param-Bindings (DRIVE/BRIGHT/VOLUME/DISPLAY) mit Acceleration
- STM32-Toolchain (ARM-GCC, Linker, Startup) + ST-HAL-Bodies (Step 13.3)
- SystemClock-Config (PLL1 480 MHz, PLL3 für SAI)

---

## v0.7-r18.27 (2026-06-15) — Firmware-HAL-Reorg: STM32 → Produkt, Pico → Bench

User: „weiter. aber wir nutzen ja kein pico mehr." → Pico-Build wird auf reines
Bench-Tool (display_hw_test) reduziert; STM32 wird Default-Target.

### Reorg

8 Pico-spezifische Files via `git mv` nach `src/hal_pico/`:
audio.c → audio_pico.c, audio_i2s.pio, encoders.c → encoders_pico.c,
lcd_st7789.c → lcd_st7789_pico.c, main.c → main_pico.c, mcp23017.c →
mcp23017_pico.c, midi_pio.c, midi_tx.pio.

6 STM32-Skelett-Files NEU unter `src/hal_h743/`:
- audio_h743.c — SAI1 Block A Master + DMA-Plan (PE4/5/6 AF6, PLL3-P
  @ 11.2896 MHz für jitter-freies 44.1 kHz)
- encoders_h743.c — TIM1/2/3/4 Hardware-Encoder-Mode (kein PIO/Polling)
- lcd_st7789_h743.c — SPI1 (PA5/PA7) + GPIO (PA6/PC4/PC5)
- mcp23017_h743.c — I²C1 @ 400 kHz Fast (PB6/PB7), EXTI13 für MCP_INT
- midi_uart_h743.c — USART2 @ 31250 Baud (PD5, AF7)
- main_h743.c — Boot-Sequenz + Hold-Latch-Logik-Plan (ADR-0008 r2)

Jedes Skelett: API matched bestehende Headers (include/audio.h etc.), Body
ist `TODO(Step 13.3)`-Stub mit ST-HAL-Plan in Kommentaren. Step 13.3 füllt
die TODOs gegen STM32CubeH7.

### CMake

CMakeLists.txt neu: `-DTARGET=h743|pico|host`-Schalter, default h743.
- `h743` baut field_ambience_h743 aus 19 DSP-Files + 6 hal_h743-Skelett-Files
  (linkt erst ab Step 13.3 mit ST-HAL)
- `pico` baut NUR display_hw_test (Bench-Tool, kein Produktions-Build mehr)
- `host` baut DSP-Static-Lib für die Offline-Renderer

### Test-Stabilität

19 reine DSP/Logic-Module bleiben unverändert in `src/` —
`test/run_tests.sh` linkt nur diese, fasst kein HAL-File an. 13/13 Suiten
PASS unverändert.

### NATIVE_PORT_PLAN

Step 13.2 als DONE ✅ markiert, Step 13.3 neu definiert (ST-HAL-Integration:
Toolchain-File, Linker-Script, Startup, TODOs füllen).

---

## v0.7-r18.24 (2026-06-14) — 3 offene Verifikations-Punkte geschlossen

## v0.7-r18.24 (2026-06-14) — Drei offene Verifikations-Punkte geschlossen

Aus der „gibt es noch offene Fragen"-Bestandsaufnahme die 3 autonom lösbaren
Punkte abgeräumt.

### 🟠 Weiße-LED-Package-Bug (neu gefunden)

LED_HB (Heartbeat) hatte MPN „XL-1608UWC-04" (0603) + 0603-Footprint, aber
**LCSC C965818 = XL-2012UWC, ein 0805-Teil** (live verifiziert). Package-
Mismatch — 0805-LED auf 0603-Land-Pattern. Fix: **C965808** (echtes
XL-1608UWC-04 0603, 2.5 M Stock). BOM_MASTER hatte zusätzlich die 3 Modifier-
Weiß-LEDs fälschlich auf C965818 → ebenfalls auf C965808 korrigiert.

### 🟠 VREF+ Decoupling ergänzt (Audit-Punkt 5)

VREF+ (Pin 20) war nur an VDDA_3V3 gebunden, **kein dedizierter Cap am Pin**.
ST-Empfehlung: 1 µF + 100 nF nah am VREF+. Ergänzt: **C_VREF1 (1 µF) +
C_VREF2 (100 nF)** VREF+ → GND. Reduziert ADC-Sample-Jitter bei der
Hall-Velocity (ratiometrisch, daher Referenz-Fehler unkritisch, aber Rauschen
zählt). +2 Bauteile (C15849, C14663 — beide schon im BOM).

### 🟢 ADC-Channels DS-bestätigt (Audit-Punkt 4)

ST-PDF via Distrelec-Mirror geparst (pdftotext): **PA4=ADC12_INP18,
PB0=ADC12_INP9, PB1=ADC12_INP5 verbatim aus DS12110 bestätigt**;
PC0=ADC123_INP10 (ST-Community + DS), PC1=ADC123_INP11 (PCx-Sequenz). Alle 5
auf ADC1 → Scan-Mode reicht. SPEC §5.6a von „vor ADC-Init bestätigen" auf
„DS-bestätigt" hochgestuft.

### Verifizierung

8/8 paren-balanced, LED_HB C965808 (0 C965818-Reste außer Audit-Notiz),
C_VREF1/2 present, SPEC „DS-bestätigt", Firmware 13/13 PASS.

### Files

generate_kicad_project.py (LED_HB-LCSC + VREF+-Caps), stm32h743.kicad_sch regen,
SPEC §5.6a, BOM_MASTER (LEDs + VREF-Caps), CHANGELOG.

### Verbleibende offene Punkte (nicht autonom lösbar)

GUI-ERC (User), PCB-Layout (großer Block), Display-Pin-Order vs gekauftes Modul,
MIDI-Entscheidung (ADR-0004), STM32-Firmware-Port, Gehäuse/Plate-CAD.

---

## v0.7-r18.23 (2026-06-14) — Cell-LED-Logik: XOR → Independent Latches (ADR-0008 r2)

User: „Es können eigentlich sowohl grün als auch gelb gleichzeitig erkennbar
sein. Funktional sinnvoller. Es kann ja beide gleichzeitig geben, rein logisch."

**Berechtigt.** Die XOR-Wahl in r18.9 war eine Annahme („eine Cell nur eine
Pitch"), nicht eine Notwendigkeit. „Cell hält Grundoktave" und „Cell hält
Shift-Oktave" sind **logisch unabhängig** — beide simultan = **Oktav-Stack**
(klassischer Ambient-Drone-Effekt).

### Hardware: NICHTS

Beide LEDs hingen schon vorher an unabhängigen PCA9685-Kanälen. XOR war reine
Firmware-Logik. Schaltplan, Footprint, BOM unverändert.

### Sim sofort umgesetzt

`tools/display_sim.html`:
- State: `cells[i] = 'off'|'yellow'|'green'` (1 Wert)
  → `cells[i] = {base: bool, shift: bool}` (2 unabhängige Bits)
- Tap-Logik: Hold-armed Tap toggelt nur den vom Shift-State bestimmten Branch;
  der andere bleibt
- LED-Render: gelb ↔ base, grün ↔ shift — unabhängig (beide gleichzeitig
  erlaubt)
- Clear setzt beide Bits auf 0
- Header-Kommentar + Help-Text aktualisiert
- JS-Syntax-Check OK

### Firmware-Side (zu bauen mit STM32-Port)

ADR-0008 r2 dokumentiert verbindlich:
- State-Modell `cell_hold[i] = (base_bit, shift_bit)`
- Voice-Routing Cell `i` base = source `i`, Cell `i` shift = source `i+5`
- `PAD_MAX` 8 → 12 (5 Cells × 2 Oktaven = 10 + 2 Headroom Generate/Drone)
- `MAX_SOURCES = 16` reicht
- Master-Soft-Clip in `engine.c` fängt die +6 dB bei voller Stack-Belegung
  ohne neuen Eingriff

Firmware-Tests 13/13 unverändert PASS (Sim ist HTML, keine C-Änderung).

### Files

`firmware-c-next/tools/display_sim.html` (State + Tap + Render + Doku),
`docs/decisions/ADR-0008-cell-led-xor-shift-hold.md` (Amendment r2 vor dem
Original-XOR-Text, Original als Kontext erhalten).

---

## v0.7-r18.22 (2026-06-14) — User-Audit: Encoder-NRND + Display-Qualität

User: „Er ist nochmal alles gegen checken und verifizieren. Glaube die Encoder
waren markiert als Not-Recommended-for-future-designs? Und das Display darf
nicht schlecht sein." → **Beide Punkte berechtigt, beide gefixt.**

### 🔴 HIGH — Encoder NRND-Pivot (3 von 4 Encodern betroffen)

Zwei unabhängige Verifikationen (Octopart + RS Online + ALPS-Hersteller-Seite +
LCSC-Cross-Check) bestätigten:

| Teil | Rolle | Status |
|---|---|---|
| **EC11E18244AU** (C202365) | EN3 Display, push+detent | **ACTIVE** ✅ |
| **EC11E183440C** (C370986) | EN1/2/4 Smooth | **NRND** 🔴 |
| EC11E1834403 (C361165) | Kandidat-Ersatz | **AUCH NRND** 🔴 |

ALPS hat die gesamte **„EC11E 0-Detent + Push-Switch"-SKU-Familie phased out**
(jeder Standard-EC11E hat heute Detents). Kein aktives Drop-in existiert.

**Pivot: alle 4 Encoder = EC11E18244AU (active, ~3.052 LCSC-Stock).** Die ur-
sprüngliche „smooth"-UX-Anforderung („1 % pro langsamem Klick") wird vom
Firmware-Acceleration-Layer erfüllt (langsam = 1 %/Klick, schnell = ×8/Klick),
**die Detents stören dabei nicht** — sie WAREN die ursprüngliche Lösung. Bonus:
alle 4 identisch → einfachere Lagerhaltung. Generator + BOM_MASTER + ADR-0012
nachgezogen.
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

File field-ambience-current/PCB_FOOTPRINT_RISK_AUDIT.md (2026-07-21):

# AMBIENT PCB Footprint Risk Audit

**Stand:** r18.75 (2026-07-01, cells → digital MCP wiring kept, real Kailh Choc V1 keyswitch feel, direct-solder THT instead of an unverified hot-swap socket; Hall path removed)
**Scope:** Risk-based footprint classification per the AMBIENT Footprint Verification Brief. Not a full manual audit of every passive — those pass with package-match only.
**Source of truth:** `BOM_MASTER.md` (Bestell/Lese-Sicht) + `kicad/generate_kicad_project.py` (technisch). Where this audit disagrees with the generator, the generator wins.
**Coverage caveat:** This audit classifies risk and flags what needs to be done before layout/order. It does NOT itself perform pad-by-pad geometry comparison or 1:1 print verification — those are the targeted next actions listed in §12.

---

## 1. Executive Summary

The repository is **NOT blocked by standard passive footprints**. All 0603/0805/1210 R + C land on KiCad-Standard packages and only need the matching audit (BOM ↔ LCSC ↔ KiCad package), which is already encoded in the generator.

The PCB is blocked by **a small number of high-risk parts that still need targeted verification**:

- **POWER_CRITICAL (2):** U8 TPS61089 (VQFN-HR HotRod, custom FP — datasheet layout review not yet done) and L1 Sunlord SWPA6045 (custom FP, current path matters).
- **MECH_CRITICAL (10):** USB-C J1, Audio Jack J8, Battery JST J_BAT, Display Header J3, Encoders EN1–EN4, Cell Keyswitches SW1–SW5 (Kailh Choc V1, direct-solder, digital, r18.75), Modifier Buttons SW6–SW10, Service Buttons SW11 + SW_BOOT, Cell-LEDs (15× under cell-cap windows). None has a *1:1 print or CAD overlay against the enclosure recorded*.
- **EXACT_MODEL_SAFE electrically, MECH_CRITICAL physically (overlap):** all connectors above.
- **PACKAGE_SAFE pinout-pending (9):** U1 STM32H743, U2 MCP23017, U3 PCM5102A, U4 PAM8403H, U5 AP7361C LDO, U6 PCA9685, U7 BQ24074 (r19.18: pin map verified against TI SLUS810N + JLC land pattern, ERC double-check remains cheap), D1 USBLC6, Q2 2N7002. Symbol↔footprint pin mapping must be checked once in KiCad ERC. (Q1 removed r18.79; diode-OR D3B removed r19.18 — single-source rail per ADR-0023.)
- **UNKNOWN (0):** r18.74 briefly reopened this at 1 (a Kailh Choc hot-swap
  socket with no clean manufacturer/LCSC part number). **r18.75 closed it**:
  switched to direct-solder Kailh Choc V1 (CPG135001D01, LCSC C400229) — a
  real, verified part with a footprint + 3D STEP pulled straight from
  LCSC/EasyEDA (`easyeda2kicad --full --lcsc_id=C400229`), same method as
  this repo's other custom footprints. See SW1–SW5 row below.

**Bottom line:** The next step is not a full-footprint audit of everything. It is (a) one datasheet layout pass on TPS61089, (b) a 1:1-print pass against enclosure for the ten mech-critical parts, and (c) one ERC + symbol-pin check on the nine package-safe ICs. After that the project is layout-ready.

---

## 2. Current Repository Footprint Status

### Custom footprints in `field-ambience-current/kicad/libraries/field_ambience.pretty/` (6 total, all actively referenced)

| File | Used by | Source quality |
|---|---|---|
| `Crystal_HC49-US-SMD_ABLS.kicad_mod` | Y1 | EasyEDA-derived, matches MPN ABLS-8.000MHZ-B4-T |
| `Texas_VQFN-HR-11_2x2.5mm_P0.5mm_RNR0011A.kicad_mod` | U8 (TPS61089RNR) | Custom-built to TI drawing; **needs datasheet layout review** |
| `L_Sunlord_SWPA6045.kicad_mod` | L1 | EasyEDA, r18.20c phantom-name fix verified |
| `Jack_3.5mm_PJ-320D_SMT.kicad_mod` | J8 (and J9 DNP) | EasyEDA, SHOU HAN PJ-320D verified r18.19 |
| `SW_HX_12x12x7.3_SMD-4P.kicad_mod` | SW6–SW10 (5×) | EasyEDA, MPN HX 12×12×7.3 TPFT-B |
| `SW_TS1088_SMD.kicad_mod` | SW11 + SW_BOOT | EasyEDA-verified, MPN XUNPU TS-1088-AR02016 |

### Custom STEP models in `field-ambience-current/kicad/libraries/field_ambience.3dshapes/` (7 total)

All present, all referenced: LQFP-100 (U1), HC-49 SMD (Y1), VQFN-HR (U8), SWPA6045 (L1), PJ-320D (J8/J9), JST-PH-SMD (J_BAT), TS-1088 (SW11/SW_BOOT). Z-height table in `mechanical/3d_models/MANIFEST.md`.

### Everything else
KiCad-Standard libraries (`Package_QFP`, `Package_SO`, `Package_TO_SOT_SMD`, `Resistor_SMD`, `Capacitor_SMD`, `LED_SMD`, `Connector_PinHeader_2.54mm`, `Connector_USB`, `Connector_JST`, `Rotary_Encoder`, `Fuse`, `Diode_SMD`, `Inductor_SMD`). Package-match enforced by generator string.

---

## 3. Component Risk Classification Table

| Ref / Group | Component | MPN | LCSC | KiCad Footprint | Risk Class | Required Check | Current Status | Blocking? | Notes |
|---|---|---|---|---|---|---|---|---|---|
| **U1** | STM32H743VIT6 | STM32H743VIT6 | C114409 | `Package_QFP:LQFP-100_14x14mm_P0.5mm` | PACKAGE_SAFE | Pin 1 + symbol↔pad pin map (ERC) | OK pkg, pinout not re-checked since gen | No | Symbol generated programmatically; verify VCAP/VBAT/BOOT0/VREF+ wiring in ERC |
| **Y1** | HSE crystal | ABLS-8.000MHZ-B4-T | C596838 | `field_ambience:Crystal_HC49-US-SMD_ABLS` | EXACT_MODEL_SAFE | Pad layout + 2× 27 pF C0G placement | OK | No | 2× C107045 already in BOM |
| **J1** | USB-C 16-pin | TYPE-C-31-M-12 (HRO) | C165948 | `Connector_USB:USB_C_Receptacle_HRO_TYPE-C-31-M-12` | EXACT_MODEL_SAFE + **MECH_CRITICAL** | Board-edge cutout, mouth alignment, shell pads, VBUS/GND/CC1/CC2/D±/SBU | Electrical OK, **mech not verified vs case** | **YES (mech)** | r18.19 revert ensured 16-pin variant; confirm board-edge X/Y once enclosure CAD lands |
| **D1** | USB-C ESD | USBLC6-2SC6 | C2687116 | `Package_TO_SOT_SMD:SOT-23-6` | PACKAGE_SAFE | Pin 1 + D±/CC mapping | OK pkg | No | Standard 6-pin SOT-23, check pins in ERC |
| **F1** | PTC fuse | 1812L300/16GR | C18198349 | `Fuse:Fuse_1812_4532Metric` | DEFAULT_SAFE | Package | OK | No | 3 A trip |
| **D2** | TVS | SMAJ5.0A | C113952 | `Diode_SMD:D_SMA` | DEFAULT_SAFE | Package + polarity mark | OK | No | |
| **U8** | Boost converter | TPS61089RNR | C165129 | `field_ambience:Texas_VQFN-HR-11_2x2.5mm_P0.5mm_RNR0011A` | **POWER_CRITICAL** | Pad geom incl exposed thermal, pin 1, SW/VIN/VOUT/FB/EN/BOOT, datasheet layout, current loops, L1+C_OUT placement | Pin 11 = SW + thermal verified r18.7; **layout not yet drawn** | **YES** | TI datasheet SLVSD38C §10 recommended layout MUST be followed for HotRod package |
| **L1** | Boost inductor | SWPA6045S2R2NT 2.2 µH (r18.77: was SWPA6045S2R2MT — that MPN doesn't exist per Sunlord's own datasheet) | C36500 (r18.77: was C83455, a dead link) | `field_ambience:L_Sunlord_SWPA6045` | POWER_CRITICAL | Footprint dimensions vs datasheet, current rating ≥3 A, placement next to U8 pin 11 | OK pkg post-r18.20c phantom fix; placement still open | YES (layout) | Verified against Sunlord's official SWPA6045S datasheet (Item 12 table): Isat 6.75 A max / 7.40 A typ, Irms 4.60 A max / 5.00 A typ (r18.77 corrected — previous "4.5A/4.3A" figures here did not match any datasheet row) — confirmed adequate for 5 V/1 A boost |
| **D3** | Schottky | SS34 | C8678 | `Diode_SMD:D_SMA` | DEFAULT_SAFE | Package + polarity | OK | No | If used as boost rectifier check VR/IF; if TVS-style protection treat as default |
| **F2** | Battery-path PTC (r19.18, ADR-0023 — replaces the removed D3B diode-OR row) | SMD1812P260TF/16 | C438899 | `Fuse:Fuse_1812_4532Metric` | DEFAULT_SAFE | 1812 standard footprint | OK | No | 2.6 A hold / 5 A trip / 16 V |
| **U5** | 3.3 V LDO | AP7361C-33Y5-13 | C460397 | `Package_TO_SOT_SMD:SOT-89-5` | PACKAGE_SAFE (close to POWER_CRITICAL) | Pin 1 (1=EN, 2=GND, 3=ADJ, 4=IN, 5=OUT) + thermal pad copper for >500 mA loads | Pinout DS-verified r18.6 | No | Diodes DS confirmed; ensure GND tab has copper area |
| **U7** | Li-Ion power-path charger (r19.18, ADR-0023) | BQ24074RGTR | C54313 | `Package_DFN_QFN:QFN-16-1EP_3x3mm_P0.5mm_EP1.7x1.7mm` | PACKAGE_SAFE + POWER-adjacent | Pin map per TI SLUS810N Table 7-1 ('74 column); footprint matched against JLC/EasyEDA land pattern for C54313 (pitch 0.5, EP 1.7×1.7) | OK pkg | No | ICHG 0.89 A (R_ISET 1k), IIN 1.34 A (R_ILIM_IN 1.2k); EP must tie to VSS |
| **C_BULK** | Polymer tantal 470 µF/10 V | TPSE477K010R0100 (Kyocera) | C444831 | `Capacitor_SMD:CP_Tantalum_Case-E_EIA-7343-43_Reflow` | DEFAULT_SAFE | Pkg + polarity, but **polarised** | OK | No | Case-E 7.3×4.3 mm, ESR 100 mΩ |
| **C_BULK2** | MLCC 100 µF/10 V 1210 | LMK325ABJ107MM-T | C2880380 | `Capacitor_SMD:C_1210_3225Metric` | DEFAULT_SAFE | Pkg | OK | No | Parallel to C_BULK to handle transient ESR |
| **J_BAT** | JST-PH 2-pin SMT | S2B-PH-SM4-TB(LF)(SN) | C295747 | `Connector_JST:JST_PH_S2B-PH-SM4-TB_1x02-1MP_P2.00mm_Horizontal` | EXACT_MODEL_SAFE + **MECH_CRITICAL** | Orientation vs LiPo pouch slot in bottom case | Electrical OK | YES (mech) | Bottom-case slot per ADR-0011 (LiPo 503759, 2000 mAh) |
| **U3** | DAC | PCM5102APWR | C107671 | `Package_SO:TSSOP-20_4.4x6.5mm_P0.65mm` | PACKAGE_SAFE | Pin 1, I²S pins (BCK/LRCK/DIN), power, analog out, mode pins (FMT/FLT/DEMP/XSMT) | OK pkg | No | Verify mode pin pull strategy in ERC |
| **U4** | Class-D amp | PAM8403DR-H | C17337 | `Package_SO:SOIC-16_3.9x9.9mm_P1.27mm` | PACKAGE_SAFE | Pin 1, OUT_L+/–, OUT_R+/–, power | OK pkg | No | BTL outputs — never short to GND |
| **FB1 / FB2** | Ferrite 0603 600 Ω | BLM18AG601SN1D | C19330/C84094 | `Inductor_SMD:L_0603_1608Metric` | DEFAULT_SAFE | Pkg | OK | No | Power-supply decoupling |
| **J8** | 3.5 mm TRS jack | PJ-320D (SHOU HAN) | C431535 | `field_ambience:Jack_3.5mm_PJ-320D_SMT` | EXACT_MODEL_SAFE + **MECH_CRITICAL** | 4 SMD + 2 NPTH pad layout, switch contact, board-edge | EasyEDA r18.19 vendored | YES (mech) | Cutout must match exact PJ-320D — generic SJ-3523 was wrong, do not regress |
| ~~J9~~ | MIDI jack DNP | – | – | s. J8 | N/A | – | DNP per ADR-0004 r18.30 | No | FP + edge cutout conserved for later reactivation |
| **J6 / J7** | Speaker pads (2-pin) | – | – | `Connector_PinHeader_2.54mm:PinHeader_1x02_P2.54mm_Vertical` | DEFAULT_SAFE | Pkg | Placeholder OK | No | Manual solder of CMS-402811-28SP leads |
| **U2** | GPIO expander | MCP23017-E/SS | C506653 | `Package_SO:SSOP-28_5.3x10.2mm_P0.65mm` | PACKAGE_SAFE | Pin 1, I²C (SDA/SCL), GPA/GPB ports, A0/A1/A2 address pins, RESET, INT | OK pkg | No | I²C address conflict check vs PCA9685 (U6) — both default 0x20/0x40 ranges, no overlap |
| **U6** | PWM LED driver | PCA9685PW,118 | C2678753 | `Package_SO:TSSOP-28_4.4x9.7mm_P0.65mm` | PACKAGE_SAFE | Pin 1, I²C (SDA/SCL), 16× LED outputs, OE, A0–A5 address | OK pkg | No | 16/16 channels used (5 modifier + 10 cell + 1 backlight); confirm no spare-pin shorts |
| **J3** | 1×8 receptacle | (generic) | – | `Connector_PinHeader_2.54mm:PinHeader_1x08_P2.54mm_Vertical` | DEFAULT_SAFE + **MECH_CRITICAL** | Display module pin order verification | Pkg OK; **pin order vs Waveshare 1.9" module not 1:1 verified** | YES | r18.22 note explicit: Waveshare pin order varies per vendor — must verify against shipped module before final layout |
| **LCD module** | Waveshare 1.9" 170×320 ST7789V2 | – | – | Module (sits in J3) | MECH_CRITICAL | Window cutout + screen-to-bezel alignment | Module-only | YES (mech) | Per r18.22 pivot from bare AliExpress |
| **Q2** | Backlight FET | 2N7002,215 | C8545 | `Package_TO_SOT_SMD:SOT-23` | PACKAGE_SAFE | Pin 1, G/D/S | OK pkg | No | |
| **EN1–EN4** | Rotary encoders | ALPS EC11E18244AU | C202365 | `Rotary_Encoder:RotaryEncoder_Alps_EC11E-Switch_Vertical_H20mm` | EXACT_MODEL_SAFE + **MECH_CRITICAL** | Shaft height 20 mm + tab spacing + knob clearance + panel cutout, A/B/C + push-switch pins | Pkg OK per ADR-0012 r18.22 pivot | YES (mech) | All four use same MPN (NRND-pivot consolidated); confirm 3D-printed knob ID matches shaft diameter |
| **SW1–SW5** | Cell keyswitches, direct-solder (digital, r18.75) | Kailh Choc V1, CPG135001D01 | [C400229](https://www.lcsc.com/product-detail/C400229.html) — verified real listing; ⚠ 0 stock at time of writing (restocks common) | `field_ambience:SW_KailhChoc_CPG1350_THT_2P` | EXACT_MODEL_SAFE + **MECH_CRITICAL** | Cap window/optional plate cutouts in top panel, MX 19 mm pitch, 15×15 mm switch envelope, ~3 mm real travel, 2 THT pins + 3 unplated locator holes | Footprint + 3D STEP pulled directly from LCSC/EasyEDA for this exact part via `easyeda2kicad` — sourced from the manufacturer's own listing, same method as this repo's other custom footprints (TS-1088, MST-12D18, PJ-320D) | YES (mech) | Cells went digital on MCP23017 GPA0–4 (ADR-0013 superseded, r18.73); r18.74 tried a hot-swap socket (had no clean part number, needed fiddly hand-soldering); r18.75 simplified to direct-solder — same THT technique as every other button here, switch now permanent instead of swappable. Replaces the former DRV5056A4 Hall + RC. |
| **SW6–SW10** | Modifier tactiles | HX B3F-4055-Y | C36498965 | `field_ambience:SW_TC1212-7.3_THT_4P` | EXACT_MODEL_SAFE + **MECH_CRITICAL** | Cap window cutouts in top panel, button height ≈7.3 mm | Custom FP — verify HX B3F THT pin pattern at GUI-ERC | YES (mech) | All 5 identical — Shift / Hold / Drone / Generate / Clear; same part as the cells |
| **SW11** | Reset tactile | XUNPU TS-1088-AR02016 | C720477 | `field_ambience:SW_TS1088_SMD` | EXACT_MODEL_SAFE + **MECH_CRITICAL** | Service hole in bottom plate aligned to button | EasyEDA-verified r18.14 | YES (mech) | Bottom-plate access hole |
| **SW_BOOT** | BOOT0 service | (= SW11 part) | C720477 | (= SW11 FP) | EXACT_MODEL_SAFE + **MECH_CRITICAL** | Service hole in bottom plate | OK | YES (mech) | DFU-flash access; 1 kΩ pull-up R_BOOT_SW present |
| **R_BOOT_SW** | 1 kΩ 0603 | (= R_CELL) | C21190 | (= R_CELL) | DEFAULT_SAFE | Pkg | OK | No | |
| **Modifier-LED Hold (yellow)** | KT-0603Y | KT-0603Y | C2287 | `LED_SMD:LED_0603_1608Metric` | DEFAULT_SAFE | Pkg + polarity | OK | No | |
| **Modifier-LED Shift (green)** | KT-0603G | KT-0603G | C12624 | `LED_SMD:LED_0603_1608Metric` | DEFAULT_SAFE | Pkg + polarity | OK | No | |
| **Modifier-LEDs Drone/Gen/Clear (3× white)** | XL-1608UWC-04 | – | C965808 | `LED_SMD:LED_0603_1608Metric` | DEFAULT_SAFE | Pkg + polarity | OK | No | |
| **Cell-LEDs 5× yellow + 5× green** | KT-0603Y / KT-0603G | – | C2287 / C12624 | `LED_SMD:LED_0603_1608Metric` | DEFAULT_SAFE + **MECH_CRITICAL** | LED X/Y must align under cell-cap light window | OK electrically; mech position not 1:1 verified vs printed cell caps | YES (mech) | XOR latch per ADR-0008 r2 — each cell has one yellow + one green |
| **LED_HB** | Heartbeat | XL-1608UWC-04 (0603) | C965808 | `LED_SMD:LED_0603_1608Metric` | DEFAULT_SAFE | Pkg | OK (r18.24 fixed 0805 mismatch) | No | |
| **LED_CHRG** | Charger status amber | (generic) | C72041 | `LED_SMD:LED_0603_1608Metric` | DEFAULT_SAFE | Pkg | OK | No | |
| **LED ballast 15× 390 Ω 0603** | 0603WAF3900T5E | – | C23151 | `Resistor_SMD:R_0603_1608Metric` | DEFAULT_SAFE | Pkg | OK | No | Anode-to-+5V, sinked by PCA9685 |
| **J4** | SWD service header | TC2030-IDC 3-pin | – | `Connector_PinHeader_1.27mm:PinHeader_1x03_P1.27mm_Vertical` | EXACT_MODEL_SAFE + light mech | TC2030 pad spacing 1.27 mm — verify against Tag-Connect drawing; alignment notches in PCB | OK pkg | No (light) | Optional dev-only; PCB notches per Tag-Connect TC2030 footprint guide |
| **All §10 generic passives** | 0603 R + C, 0805 C, 1210 C | various | various | `*_SMD:*_1608Metric` / `*_2012Metric` / `*_3225Metric` | DEFAULT_SAFE | Pkg + value | OK (encoded in generator) | No | Generator string-matches package per LCSC |

---

## 4. Components That Do Not Need Full Manual Audit (DEFAULT_SAFE)

All 0603 / 0805 / 1210 / 1812 / SOD passives + simple LEDs + LED ballast resistors + boot pullup. Verification = (a) value matches BOM, (b) LCSC package matches KiCad footprint package. This is encoded in `generate_kicad_project.py` string-by-string and does not need a separate pass.

Specifically: F1 (Polyfuse 1812), D2 (D_SMA), D3 (D_SMA), C_BULK (Case-E reflow), C_BULK2 (1210), FB1/FB2 (L_0603), all §10 R + C, all LEDs except where flagged mech-critical, R_CELL, C_CELL, R_BOOT_SW, all LED ballasts.

---

## 5. Components That Need Pinout Verification Only (PACKAGE_SAFE)

These pass a generic KiCad ERC + a one-time human eyeball comparing symbol pin order against datasheet table. None requires custom geometry.

- **U1 STM32H743VIT6** — LQFP-100, 100 pins; the highest-leverage one to ERC because of VCAP/VBAT/BOOT0/VREF+/PA13/PA14 (SWD) wiring.
- **U2 MCP23017** — SSOP-28, I²C address pins A0/A1/A2.
- **U3 PCM5102A** — TSSOP-20, mode pins (FMT/FLT/DEMP/XSMT) need explicit pull strategy.
- **U4 PAM8403H** — SOIC-16, BTL outputs OUTL±/OUTR±.
- **U5 AP7361C** — SOT-89-5, non-standard pin order 1=EN/2=GND/3=ADJ/4=IN/5=OUT (DS-verified r18.6, easy to wire wrong).
- **U6 PCA9685** — TSSOP-28, 16 LED outputs + I²C address.
- **U7 BQ24074** — VQFN-16 3×3 EP; ISET/ILIM/TS resistors set charge/input current (r19.18).
- **D1 USBLC6-2SC6** — SOT-23-6, D± routing.
- ~~Q1 DMG2305UX~~ — removed r18.79 (diode-OR replaces the power-path).
- **Q2 2N7002** — SOT-23 N-Ch.

**Action:** Run ERC once + visually compare each IC symbol pin numbers against its datasheet Table 4-1 / Pin Configuration. ~30 minutes total.

---

## 6. Mechanically Critical Components

Order roughly by tolerance pain (tight → loose):

1. **SW1–SW5 (Cell keyswitches, digital, direct-solder — r18.75)** — 5× Kailh Choc V1 switches directly soldered on the MX 19 mm grid (15×15 mm envelope, ~3 mm travel), cap windows/optional plate cutouts in the top panel must align to switch centres. Replaces the former Hall sensors under Gateron magnets (no more magnet-to-sensor stack-height constraint) — and replaces r18.73's small tactile button (which had made the cells feel identical to the modifiers) and r18.74's hot-swap socket (unverified sourcing).
2. **EN1–EN4 (Encoders)** — 20 mm shaft + knob alignment with top panel + tab spacing for through-hole mounting tabs.
3. **SW6–SW10 (Modifier buttons)** — 5× cap windows in top panel must align to button centres.
4. **J1 (USB-C)** — board-edge cutout, mouth alignment with side wall, shell-to-shield contact.
5. **J8 (Audio jack)** — board-edge / side wall cutout for plug insertion.
6. **J_BAT (Battery JST)** — orientation vs LiPo pouch slot in bottom case.
7. **J3 + LCD module** — pin order varies per Waveshare batch (r18.22 note), and the screen window + bezel must align.
8. **SW11 + SW_BOOT** — service holes in bottom plate.
9. **Cell-LEDs (10×)** — each must sit under the cell-cap's light window for the XOR-latch indicator to be visible.
10. **J6 / J7 (Speaker leads)** — pad position vs speaker driver position when mounted in top panel.

**Action:** Once `mechanical/coordinates/mechanical_coordinates.md` covers all of these, generate a 1:1 print of the PCB + enclosure outline + cutouts and physically check.

---

## 7. Power-Critical Components

Only two:

### U8 TPS61089RNR (boost converter, VQFN-HR HotRod 2×2.5 mm)
- Exposed thermal pad on pin 11 = SW (TI DS SLVSD38C Table 6-1 verified r18.7).
- **Datasheet §10 "Layout Guidelines" not yet visibly executed**: input cap on VIN/PGND with shortest possible loop; output cap on VOUT/PGND with shortest possible loop; SW node small but with enough copper to handle inductor current; do NOT run sensitive signals under SW node.
- L1 (SWPA6045) must sit immediately next to SW pin with thick polygon.
- Recommend GND pour on inner layer right under U8 + L1.

### L1 Sunlord SWPA6045S2R2NT (r18.77: corrected from the nonexistent "...MT" MPN)
- Custom FP from EasyEDA (r18.20c phantom-name fix). Pad geometry should match Sunlord drawing — **not yet 1:1 verified against the PDF**.
- Saturation Isat 6.75 A max / 7.40 A typ (r18.77: corrected from a fabricated "4.5 A" figure that didn't match any datasheet row) is fine for 5 V/1 A boost (peak ≈1.5 A).

### Soft-power-critical (mentioned for completeness, not flagged blocking):
- U7 BQ24074 charger: QFN-16 exposed pad MUST be soldered to a VSS copper pour with thermal vias (linear power path dissipates ~0.7 W worst case while charging).
- U5 AP7361C LDO: same — copper for the GND tab (pin 2) to act as heatsink at the typical 100-300 mA loads here.

---
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

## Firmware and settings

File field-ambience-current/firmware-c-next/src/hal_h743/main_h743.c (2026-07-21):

/*
 * main_h743.c — STM32H743 product firmware entry point (r18.86, Step 13.3 —
 * the boot TODOs are now real code; vendor startup/linker/clock live in
 * this directory + vendor/).
 *
 * Boot sequence:
 *   1. I/D caches on, HAL_Init (SysTick 1 kHz), SystemClock_Config:
 *      HSE 8 MHz → PLL1 → 480 MHz core / 240 MHz AHB / 120 MHz APB;
 *      PLL3 → 11.289609 MHz SAI1 kernel (jitter-free 44.1 kHz).
 *   2. Init order below: LCD splash → I²C expander/LED drivers (dark) →
 *      encoders → DSP/brain/engine → menu/controls/params/leds/vu →
 *      audio (SAI1+DMA pump live, SPEC §8.3 /SHDN → /MUTE → XSMT).
 *   3. Main loop routes hardware events into the host-tested logic
 *      (controls.c / params.c / menu.c) — no gameplay logic lives here.
 *
 * r18.87 (User): VU-Meter komplett entfernt (U10 + vu.c + pca2-API) — nur
 * die Cell- und Modifier-LEDs auf U6 bleiben.
 *
 * Hold-latch logic (ADR-0008 r2) lives in controls.c (host-tested); this
 * loop only feeds it press/release edges from the MCP23017.
 */

#include "engine.h"
#include "v2/synth_host.h"
#include "brain.h"
#include "dsp.h"
#include "audio.h"
#include "diag.h"
#include "psram.h"
#include "encoders.h"
#include "mcp23017.h"
#include "oled.h"
#include "oled_color.h"  /* accent crossfade tick (world → screen tint) */
#include "overlay.h"     /* r19.21: transient knob-value overlay */
#include "knobs.h"       /* r19.21: encoder push short/long actions */
#include "scenes.h"      /* r19.22: parameter locks + 5 scene slots */
#include "bloom.h"       /* r19.23: chord-bloom cell mode */
#include "landscape.h"   /* r19.27: layer-role cell mode */
#include "tuning.h"      /* r19.27: tuning_hz for the Bed/Motif layer pitches */
#include "gesture.h"     /* r19.25: gesture loop (record/replay cells) */
#include <stdio.h>       /* snprintf (status overlay, control-rate only) */
#include "midi.h"
#include "controls.h"    /* hold-latch + modifier state machine (ADR-0008 r2) */
#include "params.h"      /* encoder → engine param bindings */
#include "leds.h"        /* controls/modifier state → PCA9685 16-ch PWM */
#include "menu.h"        /* menu state machine */
#include "battery.h"     /* r18.92: BAT_SENSE ADC -> % + USB glyph */
#include "h743_hal.h"    /* SystemClock_Config, enc_set_ext_push */

/* MCP23017 GPIO bit map (SPEC §7.2 / mcp23017_h743.c) — which expander bit is
 * which modifier button. Modifier push of EN1/2/4 also lands on GPB. */
/* Modifier bit positions are defined ONCE in mcp23017.h as MCP_BIT_MOD_*
 * (GPB0-4 = bits 8-12, because mcp_read_gpio packs (GPB<<8)|GPA). Do not
 * redefine them here — the old local 0-4 values read GPA, not GPB (bug). */

/* Cells sind seit r18.73 DIGITAL (MCP23017 GPA0-4) — feste Tap-Velocity wie
 * im Pico-HAL (CELL_VOICE_AMP 0.12 dort; controls.c skaliert identisch). */
#define CELL_TAP_AMP 0.12f

/* Jack-detect debounce (mechanical TRS contact bounce ≪ 50 ms). */
#define JACK_DEBOUNCE_MS 50u

/* Menu → engine binding (ADR-0017 Phase 4, r18.58 Reddit-macro pass).
 * Menu slots are now World/Space/Atmos/Motion/Age — Tone was dropped (it
 * duplicated the Brightness encoder) and Drums was dropped (adaptive drums
 * is its own can of worms; we ship sound, not timing). Synchronous from
 * menu_rotate/menu_push, never from the audio thread. */
/* r18.88: after a world change, re-pitch latched voices so held notes
 * follow the new key instead of clashing with the new drone/bed. */
static void hal_set_world      (int   idx) { engine_set_world(idx);
                                             controls_refresh_held_pitches(); }
/* r18.98: KEY follows the same rule — future notes + drone re-key, held
 * latched notes re-pitch so they never clash with the new tonic. */
static void hal_set_key        (int   pc)  { engine_set_key_pc(pc);
                                             controls_refresh_held_pitches(); }
static void hal_set_voice      (int   idx) { engine_set_voice(idx); }
static void hal_set_tuning     (int   just){ engine_set_tuning(just); }
static void hal_set_space      (float v)   { engine_set_space(v); }
static void hal_set_shimmer    (float v)   { engine_set_shimmer(v); }
static float s_atmos_base = 0.35f;                  /* r19.27: world/menu atmos level, restored when the Landscape ATMOS layer releases */
static void hal_set_atmosphere (float v)   { s_atmos_base = v; engine_set_atmosphere(v); }
static void hal_set_motion     (float v)   { engine_set_motion(v); }
static void hal_set_age        (float v)   { engine_set_age(v); }
static void hal_set_echo       (float v)   { engine_set_echo(v); }
static void hal_set_blur       (float v)   { engine_set_blur(v); }
static void hal_set_synth      (int   idx) { engine_set_synth(idx); }
static void hal_set_bass       (int   mode){ bloom_set_bassmode(mode); }   /* r19.31 */
static void hal_set_color      (int   col) { bloom_set_color(col); }        /* r19.32 */
static void hal_set_fx         (int   m)   { engine_set_fx_mode(m); }       /* r19.41 */
/* cell play mode — 0 Note (r19.26), 1 Harmony (r19.29, chord + voice-leading),
 * 2 Landscape (r19.27, sound layers). */
enum { CELL_NOTE = 0, CELL_HARMONY = 1, CELL_LAND = 2 };
static int s_cell_mode = CELL_NOTE;
static uint32_t s_field_seed = 0x1234u;             /* r19.24: New-Field seed source */
static const char *const STEER_NAME[5] =            /* r19.24: cell → intent */
    { "HOME", "LIFT", "DARK", "OPEN", "TENSION" };

/* r19.27 — Landscape layer callbacks: map the abstract role state machine
 * (landscape.c) onto the engine's existing layers. Bed/Motif pitches come
 * from brain.c's clean pentatonic (r19.26); ATMOS boosts over, then restores,
 * the world/menu baseline; MEMORY drives the r19.25 gesture loop. */
#define BED_LAYER_AMP   0.16f
#define MOTIF_LAYER_AMP 0.20f
#define ATMOS_LAYER_HI  0.72f
static void ls_drone(bool on)             { engine_set_drone(on); }
/* r19.35: BED is a soft breathing tonic triad (pad sources 1..3), not a lone
 * tone — the "broad slowly-breathing chord" the layer role wants. Uses the
 * world's home chord (degree I) as a stable harmonic ground under the motif. */
#define BED_SRC0 1
static void ls_bed  (bool on, uint8_t c)  {
    (void)c;
    if (on) {
        int chord[3];
        int n = brain_color_chord(1, 0 /*PURE triad*/, chord, 3);
        for (int i = 0; i < n && i < 3; ++i)
            engine_note_on((uint8_t)(BED_SRC0 + i), tuning_hz((float)chord[i]),
                           BED_LAYER_AMP * 0.62f);
    } else {
        for (int i = 0; i < 3; ++i) engine_note_off((uint8_t)(BED_SRC0 + i));
    }
}
static void ls_motif(uint8_t c)           {
    /* +1 octave: Motif is the "high light" role — a fragile bell above the bed. */
    engine_motif_strike(tuning_hz((float)brain_cell_root(c) + 12.0f), MOTIF_LAYER_AMP);
}
static void ls_atmos(bool on)             {
    engine_set_atmosphere(on ? (s_atmos_base > ATMOS_LAYER_HI ? s_atmos_base
                                                              : ATMOS_LAYER_HI)
                             : s_atmos_base);
}
static void ls_memory(uint32_t now)       {
    gesture_toggle(now);
    gesture_state_t g = gesture_state();
    overlay_show("MEMORY",
                 g == GESTURE_REC  ? "REC"  :
                 g == GESTURE_PLAY ? "LOOP" : "OFF", now, 0);
}
static const landscape_iface_t s_ls_iface = {
    ls_drone, ls_bed, ls_motif, ls_atmos, ls_memory
};

/* r19.25: the single cell-routing path — used by the physical buttons AND
 * by the gesture-loop playback, so a replayed cell behaves exactly like a
 * live one in the current mode (generate-steer / bloom / landscape / note). */
static void route_cell(uint8_t c, bool pressed, uint32_t now) {
    if (c >= 5) return;
    if (controls_modifier_active(MOD_GENERATE)) {
        if (pressed) { engine_generative_nudge(c, now);
                       overlay_show("STEER", STEER_NAME[c], now, 0); }
    } else if (s_cell_mode == CELL_HARMONY) {
        if (pressed) bloom_press(c, CELL_TAP_AMP,
                                 controls_modifier_active(MOD_HOLD), now);
        else         bloom_release(c, now);
    } else if (s_cell_mode == CELL_LAND) {
        if (pressed) landscape_press(c, controls_modifier_active(MOD_HOLD), now);
        else         landscape_release(c, now);
    } else {
        if (pressed) controls_cell_press(c, CELL_TAP_AMP);
        else         controls_cell_release(c);
    }
}
static void hal_set_cell(int mode) {
    if (mode < CELL_NOTE || mode > CELL_LAND) mode = CELL_NOTE;
    if (mode == s_cell_mode) return;
    /* Modewechsel: die Stimmen/Latches des verlassenen Modus sauber beenden. */
    switch (s_cell_mode) {
        case CELL_HARMONY: bloom_all_off();          break;
        case CELL_LAND:  landscape_all_off(0);     break;
        default:         engine_all_off();         break;   /* NOTE latches */
    }
    /* r19.31: HARMONY owns the bass (own octave/glide per mode); NOTE/LAND let
     * the engine auto-follow the lowest held note again. */
    engine_bass_follow(mode != CELL_HARMONY);
    s_cell_mode = mode;
}

/* r19.16 — V2 sound-core backend: thin adapters so the engine keeps no link
 * dependency on src/v2 (host tests link engine.c without it). */
static void be_select  (int id)              { synth_host_select((synth_id_t)id); }
static void be_note_on (int midi, float vel) { synth_host_note_on(midi, vel); }
static void be_note_off(void)                { synth_host_note_off(); }
static void be_panic   (void)                { synth_host_panic(); }
static void be_render  (int16_t *b, int n)   { synth_host_render(b, n); }
static const engine_synth_backend_t s_v2_backend = {
    be_select, be_note_on, be_note_off, be_panic, be_render
};

/* Klinke drin → NUR den PAM8403 muten (AMP_nMUTE = PB15 LOW), Line-Out
 * bleibt live — NICHT audio_mute() rufen (das wuerde auch XSMT ziehen und
 * den Line-Out toeten). Design: ADR / v0.7. */
static bool s_jack_plugged = false;   /* r19.21: fuer das Status-Overlay */

static void apply_amp_mute_for_jack(bool plugged) {
    s_jack_plugged = plugged;
    HAL_GPIO_WritePin(GPIOB, GPIO_PIN_15,
                      plugged ? GPIO_PIN_RESET : GPIO_PIN_SET);
}

/* r19.22: Scenes-Flash-Backend (scenes_flash_h743.c, Bank-2-Sektor). */
bool scenes_flash_write(const void *blob, unsigned len);
bool scenes_flash_read(void *blob, unsigned len);

/* r19.22: DISPLAY kurz/lang sind kontextabhaengig —
 *   Scenes-Browser offen: kurz = schliessen
 *   Menue BROWSE:         kurz = menu_push, lang = Scenes oeffnen
 *   Menue EDIT:           kurz = menu_push, lang = Parameter-Lock toggeln */
static void display_short_dispatch(void) {
    if (scenes_ui_active()) { scenes_ui_close(); return; }
    menu_push();
}
static void display_long_dispatch(void) {
    uint32_t now = HAL_GetTick();
    if (scenes_ui_active()) { scenes_ui_close(); return; }
    if (menu_mode() == MENU_EDIT) {
        bool locked = menu_toggle_lock_current();
        overlay_show(menu_current_label(), locked ? "LOCKED" : "UNLOCKED",
                     now, 0);
    } else {
        scenes_ui_open(now);
    }
}

/* r19.21: VOLUME lang gedrueckt → Batterie/USB + Ausgangsstatus. */
static void knob_status_lines(char *l1, unsigned n1, char *l2, unsigned n2) {
    snprintf(l1, n1, battery_usb_present() ? "BAT %d%% +USB" : "BAT %d%%",
             battery_pct());
    snprintf(l2, n2, "%s", s_jack_plugged ? "PHONES" : "SPEAKERS");
}

/* --- MIDI note tap (r19.14) ---------------------------------------------
 * Mirror the PLAYED cell notes (base sources 0..4, shift 9..13) to MIDI out.
 * The generative bed/drone/sparkle/melody sources are intentionally NOT
 * forwarded — MIDI out represents what the PLAYER performs, not the autoplay.
 * Runs at control rate (engine note path, not the audio ISR), so the FIFO
 * enqueue is safe. One note tracked per source for a correct note-off. */
static int8_t s_midi_src_note[16];
static bool midi_src_is_played(uint8_t s) { return s <= 4 || (s >= 9 && s <= 13); }

static void midi_note_tap(int on, uint8_t source, float freq_hz, float amp) {
    if (on < 0) {                                  /* engine_all_off */
        midi_send_all_notes_off();
        for (int i = 0; i < 16; ++i) s_midi_src_note[i] = -1;
        return;
    }
    if (source >= 16 || !midi_src_is_played(source)) return;
    if (on) {
        int note = midi_note_from_hz(freq_hz);
        if (note < 0) return;
        if (s_midi_src_note[source] >= 0)          /* retrigger: off the old */
            midi_send_note_off((uint8_t)s_midi_src_note[source]);
        midi_send_note_on((uint8_t)note, midi_vel_from_amp(amp));
        s_midi_src_note[source] = (int8_t)note;
    } else if (s_midi_src_note[source] >= 0) {
        midi_send_note_off((uint8_t)s_midi_src_note[source]);
        s_midi_src_note[source] = -1;
    }
}

/* DTCM/D2 DSP-buffer regions (stm32h743_flash.ld): the startup file zeroes
 * only the main .bss, so these must be zeroed here before ANY engine code
 * runs — C globals rely on zero-init. */
extern uint32_t _sdtcm_bss, _edtcm_bss, _sd2_bss, _ed2_bss;

int main(void) {
    /* Zero the out-of-.bss DSP regions first (see linker script). */
    for (uint32_t *p = &_sdtcm_bss; p < &_edtcm_bss; ++p) *p = 0u;
    for (uint32_t *p = &_sd2_bss;   p < &_ed2_bss;   ++p) *p = 0u;

    /* Denormal protection (r18.90): flush-to-zero on the M7 FPU. Reverb,
     * echo and pluck feedback tails decay THROUGH the denormal range; on
     * ARMv7-M denormal arithmetic takes a slow support path — a classic
     * embedded-audio CPU spike exactly when the instrument goes quiet.
     * FZ in FPSCR covers thread mode; FPDSCR seeds the FPSCR on exception
     * entry (the audio render runs in the DMA IRQ). Host tests are by
     * definition unaffected (this is device-only code). */
    __set_FPSCR(__get_FPSCR() | (1u << 24));            /* FZ, thread   */
    FPU->FPDSCR |= (1u << 24);                          /* FZ, handlers */

    /* Cortex-M7 caches next (the 480 MHz core is crippled without them),
     * then the HAL time base, then the real clock tree. */
    SCB_EnableICache();
    SCB_EnableDCache();
    HAL_Init();                       /* SysTick 1 kHz + NVIC grouping */
    SystemClock_Config();             /* 480 MHz core, PLL3 → SAI 44.1 kHz */

    oled_init();
    mcp_init();
    enc_init();
    /* MIDI Out activated (r19.14): message core + USART2/PD5 driver both
     * complete since r18.86; the note tap below mirrors played cells to J10
     * (PJ-320D TRS Type A + 2x 220R). ⚠ On real hardware, verify the TRS-A
     * vs -B wiring against the receiver before relying on it (BRING_UP). */
    midi_init();
    midi_hw_init();
    dsp_init();
    brain_init();
    engine_init();
    engine_boot_mute();       /* r19.20 SPEC boot: silent until params_init
                               * sets the 30 % target → ~350 ms fade-in */
    for (int i = 0; i < 16; ++i) s_midi_src_note[i] = -1;
    engine_set_note_hook(midi_note_tap);   /* played cells → MIDI out */
    synth_host_init();
    engine_set_synth_backend(&s_v2_backend);   /* r19.16: SYNTH menu slot live */
    {
        /* ADR-0017 Phase 4 + r18.58 Reddit-macro menu */
        menu_callbacks_t cb = {
            .set_world      = hal_set_world,
            .set_key        = hal_set_key,
            .set_tuning     = hal_set_tuning,
            .set_voice      = hal_set_voice,
            .set_space      = hal_set_space,
            .set_shimmer    = hal_set_shimmer,
            .set_atmosphere = hal_set_atmosphere,
            .set_motion     = hal_set_motion,
            .set_age        = hal_set_age,
            .set_echo       = hal_set_echo,
            .set_blur       = hal_set_blur,
            .set_synth      = hal_set_synth,
            .set_cell       = hal_set_cell,
            .set_bass       = hal_set_bass,
            .set_color      = hal_set_color,
            .set_fx         = hal_set_fx,
        };
        menu_init(&cb);
    }
    controls_init();          /* hold-latch + modifier state (ADR-0008 r2) */
    bloom_init();             /* r19.23: chord-bloom cell mode */
    landscape_init(&s_ls_iface); /* r19.27: layer-role cell mode */
    gesture_init(route_cell); /* r19.25: gesture loop replays via route_cell */
    params_init();            /* encoder param values → engine defaults */
    overlay_init();
    {   /* r19.21: Encoder-Push-Belegung (DISPLAY kurz = Menue wie bisher;
         * DISPLAY lang bleibt fuer Scenes reserviert). */
        knobs_callbacks_t kcb = { 0 };
        kcb.display_push = display_short_dispatch;   /* r19.22: kontextabhaengig */
        kcb.display_long = display_long_dispatch;    /* r19.22: Lock / Scenes    */
        kcb.status_lines = knob_status_lines;
        knobs_init(&kcb);
    }
    {   /* r19.22: Scenes aus dem Flash laden (Bank-2-Sektor, dual-bank —
         * Audio laeuft beim Speichern weiter). */
        scenes_init(scenes_flash_write, scenes_flash_read);
    }
    leds_init();              /* 16-ch PWM render */
    leds_set_backlight((uint16_t)(LED_PWM_MAX * 70 / 100));   /* 70 % boot */
    bat_adc_init();           /* r18.92: BAT_SENSE (PA3) — battery UI */
    audio_init();
    audio_set_renderer(engine_render);

    /* --- Bring-up diagnostics (r19.14): hold CELL1 at power-on to enter a
     * live readout (profiler load/WCET/misses/clips, battery, voices) + a
     * QSPI-PSRAM self-test on CELL2. A bench instrument, not a play mode — it
     * never returns (power-cycle to exit). Drives a heavy scene so the load%
     * is meaningful. CELL bits are active-low (MCP pull-ups). */
    if (!(mcp_state() & (1u << MCP_BIT_CELL1))) {
        engine_set_world(0);
        engine_set_drone(true);
        engine_set_generative(true, 0);
        engine_set_reverb_size(1.0f); engine_set_echo(1.0f);
        engine_set_blur(1.0f);        engine_set_shimmer(1.0f);
        int psram_pass = 0, psram_ran = 0;
        for (;;) {
            uint32_t now = HAL_GetTick();
            engine_generative_tick(now);
            if (!psram_ran && !(mcp_state() & (1u << MCP_BIT_CELL2))) {
                psram_ran  = 1;
                psram_pass = (psram_init() && psram_selftest()) ? 1 : 0;
            }
            diag_draw(psram_pass, psram_ran);
            oled_show();
            HAL_Delay(120);
        }
    }

    /* Initial jack state (mcp_init primed the cache): plugged at boot →
     * speaker amp stays muted from the first un-mute onwards. */
    uint16_t prev_gpio = mcp_state();
    apply_amp_mute_for_jack((prev_gpio & (1u << MCP_BIT_JACK)) != 0);

    /* Jack-detect debounce state (0xFF = nothing pending). */
    uint8_t  jack_pending  = 0xFF;
    uint32_t jack_edge_ms  = 0;

    /* UI frame pacing. */
    uint32_t last_frame_ms = 0;
    bool     ui_dirty      = true;     /* draw the first frame immediately */

    /* Main loop. All gameplay LOGIC is hardware-independent (controls.c /
     * params.c / menu.c, host-tested) — this loop only ROUTES hardware
     * events into it. */
    for (;;) {
        uint32_t now = HAL_GetTick();

        /* --- 1. Encoder rotate/push → params + menu ---
         * r18.92: SHIFT + DISPLAY = backlight (SPEC transient overlay rule
         * — a hardware modifier, not a menu row). 5 %/detent, 10..100 %. */
        static int backlight_pct = 70;
        enc_event_t ev;
        while (enc_pop_event(&ev)) {
            if (ev.kind == ENC_EVENT_ROTATE) {
                if (ev.id == PARAM_ENC_DISPLAY) {
                    if (controls_modifier_active(MOD_SHIFT)) {
                        backlight_pct += ev.value * 5;
                        if (backlight_pct < 10)  backlight_pct = 10;
                        if (backlight_pct > 100) backlight_pct = 100;
                        leds_set_backlight((uint16_t)(LED_PWM_MAX *
                                                      backlight_pct / 100));
                    } else {
                        menu_rotate(ev.value);          /* DISPLAY: Menü   */
                        ui_dirty = true;
                    }
                } else {
                    /* r19.21: DRIVE/BRIGHT/VOLUME → params + Overlay */
                    knobs_rotate(ev.id, ev.value, now);
                }
            } else if (ev.kind == ENC_EVENT_PUSH) {
                /* r19.21: BEIDE Flanken in die Kurz/Lang-Klassifikation.
                 * DISPLAY-kurz ruft menu_push ueber den Callback (feuert
                 * jetzt auf der Loslass-Flanke statt auf Druck — noetig
                 * fuer die Lang-Druck-Unterscheidung). */
                knobs_push(ev.id, ev.value != 0, now);
                if (ev.id == PARAM_ENC_DISPLAY && !ev.value)
                    ui_dirty = true;            /* Menue evtl. veraendert */
            }
        }
        knobs_tick(now);                        /* Lang-Druck-Schwelle */
        scenes_ui_tick(now);                    /* Scenes-Idle-Timeout  */
        bloom_tick(now);                        /* r19.23: Akkord-Einsaetze */
        gesture_tick(now);                      /* r19.25: Gesten-Wiedergabe */

        /* --- 2. MCP23017 → cells + modifiers + EN4-push + jack-detect ---
         * INT-driven: INTA (PC13, EXTI) latches s_irq_pending; mcp_service()
         * reads both ports (auto-clears the MCP interrupt). No polling —
         * the I²C bus stays free for the 60 Hz LED/VU writes.
         * r18.82: Cells sind DIGITALE Switches (GPA0-4, aktiv-LOW mit
         * Pull-up), keine Hall-ADCs mehr. Gleicher Edge-Pfad wie die
         * bench-erprobte Pico-Implementierung, geroutet durch die host-
         * getestete controls.c-Statemachine. */
        if (mcp_irq_pending()) {
            uint16_t gpio = mcp_service();
            uint16_t fell = (uint16_t)(prev_gpio & ~gpio);   /* 1→0 = press */
            uint16_t rose = (uint16_t)(~prev_gpio & gpio);   /* 0→1 = release */
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

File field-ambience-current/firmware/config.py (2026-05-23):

"""Field Ambience — Pico 2 (RP2350) Pin Mapping & Constants.

Per SPEC v0.6.3-r6 §5. These constants MUST match the KiCad schematic.
Changing a pin here without updating the schematic (and vice versa) is a
guaranteed hardware-firmware mismatch bug.

Verified against:
- Pico 2 / RP2350 datasheet pin functions
- field_ambience_pcb_SPEC_v0.6.md §5 (Pico pin allocation)
- MCP23017 §7 (button + XSMT assignment)
"""

# ---------------------------------------------------------------------------
# Firmware identity (sent in the "hello" event so the bridge can log it)
# ---------------------------------------------------------------------------
FW_VERSION = "fam-pico-1.0"

# ---------------------------------------------------------------------------
# UART0 → Raspberry Pi Zero 2 W (115200 baud, 8N1)
# Pico GP0 (TX) → Pi GPIO15 (RX, pin 10)
# Pico GP1 (RX) ← Pi GPIO14 (TX, pin 8) via R1 1k series
# ---------------------------------------------------------------------------
UART_ID = 0
PIN_UART_TX = 0
PIN_UART_RX = 1
UART_BAUD = 115200

# ---------------------------------------------------------------------------
# I²C1 → MCP23017 (400 kHz)
# ---------------------------------------------------------------------------
I2C_ID = 1
PIN_I2C_SDA = 2
PIN_I2C_SCL = 3
I2C_FREQ = 400_000
MCP23017_ADDR = 0x20          # A0=A1=A2=GND

# ---------------------------------------------------------------------------
# SPI0 → OLED SSD1322 (256×64, 4-wire SPI, up to 10 MHz)
# ---------------------------------------------------------------------------
SPI_ID = 0
PIN_OLED_SCK = 6              # SPI0 SCK
PIN_OLED_MOSI = 7            # SPI0 TX
PIN_OLED_MISO = 4            # SPI0 RX (unused by SSD1322, but reserved)
PIN_OLED_CS = 5
PIN_OLED_DC = 8
PIN_OLED_RES = 9
SPI_BAUD = 8_000_000

# ---------------------------------------------------------------------------
# 4× EC11 rotary encoders (A, B, push-switch). All Pico GPIO with RC debounce
# (100nF + 10k = 1ms) on the PCB; firmware adds quadrature decode.
#   index 0 = Drive, 1 = Brightness, 2 = Display(menu), 3 = Volume
# ---------------------------------------------------------------------------
#
# The `dir` field (+1 or -1) flips the rotation sense. The quadrature decoder
# is mathematically correct, but which physical direction reads as "+1" depends
# on the EC11 wiring and panel mounting — only verifiable on real hardware.
# If a knob feels backwards on first bring-up, flip its `dir` from 1 to -1.
ENCODERS = (
    # (name,      pin_A, pin_B, pin_SW, encoder_id, dir)
    ("drive",     10,    11,    12,     1,          1),   # EN1
    ("bright",    13,    14,    15,     2,          1),   # EN2
    ("display",   16,    17,    18,     3,          1),   # EN3 = menu controller
    ("volume",    19,    20,    21,     4,          1),   # EN4
)

# ---------------------------------------------------------------------------
# Misc Pico GPIO
# ---------------------------------------------------------------------------
PIN_MCP_INT = 22             # ← MCP23017 INTA (active low, MIRROR=1)
PIN_STATUS_LED = 26          # warm-white status LED via R19 820Ω
PIN_AMP_nSHDN = 27           # → PAM8403 /SHDN  (HIGH = chip enabled)
PIN_AMP_nMUTE = 28           # → PAM8403 /MUTE  (HIGH = un-muted)

# ---------------------------------------------------------------------------
# MCP23017 GPIO bit assignments (16-bit: GPA0..7 = bits 0..7, GPB0..7 = 8..15)
# ---------------------------------------------------------------------------
# GPA0-4 = CELL1-5 (inputs, internal pull-up, active low)
MCP_CELL_BITS = (0, 1, 2, 3, 4)      # bit index → cell id 1..5
# GPA5 = PCM_XSMT (output; HIGH = PCM5102A un-muted)
MCP_XSMT_BIT = 5
# GPA6 = JACK_DETECT (input; HIGH = headphone/line plug inserted)
# Set JACK_DETECT_ACTIVE_HIGH=False if your jack's switch polarity is inverted.
MCP_JACKDET_BIT = 6
JACK_DETECT_ACTIVE_HIGH = True
# GPB0-4 = modifier switches (inputs, pull-up, active low)
#   GPB0=SHIFT(id1) GPB1=HOLD(id2) GPB2=DRONE(id3) GPB3=GENERATE(id4) GPB4=CLEAR(id5)
MCP_MOD_BITS = (8, 9, 10, 11, 12)    # bit index → mod id 1..5

# Modifier IDs (must match field_ambience_bridge.py PicoBridge constants)
MOD_SHIFT = 1
MOD_HOLD = 2
MOD_DRONE = 3
MOD_GENERATE = 4
MOD_CLEAR = 5

# ---------------------------------------------------------------------------
# Power-sequencing timing (ms) — per SPEC v0.6.3-r6 §8 corrected order
# ---------------------------------------------------------------------------
PWR_RAIL_SETTLE_MS = 50      # wait after +5V/+3V3 stable before waking amp
PWR_SHDN_TO_MUTE_MS = 50     # wait after /SHDN HIGH before un-muting

# If no message from the Pi for this long, assume Pi crashed → mute audio.
PI_WATCHDOG_MS = 5000

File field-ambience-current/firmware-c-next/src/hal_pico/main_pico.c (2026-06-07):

/*
 * Field Ambience — native C firmware.
 *
 *   - Step 1: USB CDC heartbeat + STATUS LED on GP26 @ 1 Hz
 *   - Step 2: SSD1322 OLED, banner
 *   - Step 3: I²C + MCP23017 + 10 switches + jack-detect
 *   - Step 4: 4× EC11 encoders (quadrature + push)
 *   - Step 5: I²S DMA + 440 Hz test sine, SPEC §8 pop-suppression
 *   - Step 7: polyphonic voice pool (sine + ASR per cell tap).
 *   - Step 9: famPadCore (detuned-saw pad) replaces the placeholder sine.
 *   - Step 11: famReverbMaster + engine mix-bus (pad → dry + reverb send).
 *   - Step 10: famTexture noise bed under everything (quiet idle ambience).
 *   - Step 8: famSubBass + famDeepBass under the lowest held cell.
 *   - Step 12a (here): harmonic brain. Cell→pitch is now real scale/mode/
 *     family harmony — each cell sounds the chord root of its scale degree
 *     (default C4 ionian, warm/add9), replacing the placeholder pentatonic.
 *     The menu, USB-MIDI and encoder→param bindings (Step 12b) are still to
 *     come; key/mode/vibe currently sit at their defaults.
 *
 * Engine-Port order is 9→11→10→8→12 (hörbarkeits-first, see
 * NATIVE_PORT_PLAN.md); Steps 8 and 10 are still pending.
 * (Step 6 was the schematic update that removed the Pi — no firmware change.)
 */

#include <stdio.h>
#include <stdlib.h>
#include <string.h>
#include "pico/stdlib.h"
#include "version.h"
#include "oled.h"
#include "mcp23017.h"
#include "encoders.h"
#include "audio.h"
#include "dsp.h"
#include "engine.h"
#include "brain.h"
#include "midi.h"

#define PIN_STATUS_LED  26

/* Cell→pitch now comes from the harmonic brain (Step 12a): each cell plays a
 * single pad voice on the chord ROOT of its scale degree, for the current
 * key/mode/vibe. Defaults: C4 ionian, warm/add9. */
#define CELL_VOICE_AMP 0.12f

/* ---------------------------------------------------------------------------
 * DEMO_AUTOPLAY — hear the full instrument with ONLY a Pico + a DAC.
 *
 * Set to 1 to make the firmware play a slow chord progression by itself, with
 * NO MCP23017 and NO buttons wired. The cells are triggered on a timer instead
 * of by hardware. Perfect for the breadboard listening test when the buttons
 * won't fit: you only solder the DAC and wire 5 lines + the XSMT/SCK/FMT
 * bridges. The DAC's XSMT must be tied high in hardware (jumper H3 → H, or the
 * XSMT pin → 3V3), since with no MCP the firmware can't release XSMT itself.
 *
 * Set back to 0 for the normal build (cells played by the real buttons).
 * ------------------------------------------------------------------------- */
#define DEMO_AUTOPLAY 0

/* Slow ambient progression over the scale degrees (cells 0..4). Each step is
 * held for DEMO_STEP_MS; the long pad release + reverb tail overlap the steps
 * so it never sounds choppy. A gentle I–IV–V–vi-ish wander. */
#define DEMO_STEP_MS 5000
static const uint8_t DEMO_SEQ[] = { 0, 3, 4, 2, 0, 4, 1, 3 };
#define DEMO_SEQ_LEN (sizeof DEMO_SEQ / sizeof DEMO_SEQ[0])

static void draw_banner_static(void) {
    oled_text( 72,  0, "FIELD AMBIENCE", 0x0F);
    oled_text( 88,  8, "V0.9 STEP 12A",  0x0A);
    oled_text(  0, 16, "TAP A CELL",     0x07);
}

/* --- Step 3 button display (preserved, compact form on bottom rows) --- */
static void draw_buttons_state(uint16_t v) {
    /* Labels (Step 3 style, compacted onto y=48). */
    oled_text(0, 48, "C", 0x06);
    const int cell_x[5] = { 16, 32, 48, 64, 80 };
    for (int i = 0; i < 5; ++i) {
        bool pressed = !(v & (1u << (MCP_BIT_CELL1 + i)));
        char ch[2] = { pressed ? 'O' : '.', 0 };
        oled_text(cell_x[i], 48, " ", 0);
        oled_text(cell_x[i], 48, ch, pressed ? 0x0F : 0x05);
    }
    oled_text(96, 48, "M", 0x06);
    const int mod_x[5] = { 112, 128, 144, 160, 176 };
    for (int i = 0; i < 5; ++i) {
        bool pressed = !(v & (1u << (MCP_BIT_MOD_SHIFT + i)));
        char ch[2] = { pressed ? 'O' : '.', 0 };
        oled_text(mod_x[i], 48, " ", 0);
        oled_text(mod_x[i], 48, ch, pressed ? 0x0F : 0x05);
    }
    bool jack_in = (v & (1u << MCP_BIT_JACK)) != 0;
    oled_text(200, 48, " ", 0);
    oled_text(200, 48, "J", jack_in ? 0x0F : 0x05);
}

/* --- Step 4 encoder display --- */

/* Render a signed position into a fixed-width 5-char field: e.g. "+0123".
 * Range clamped to ±9999; values outside print as "+9999" / "-9999". */
static void format_signed(int32_t v, char out[6]) {
    bool neg = (v < 0);
    long n = neg ? -(long)v : (long)v;
    if (n > 9999) n = 9999;
    out[0] = neg ? '-' : '+';
    out[1] = (char)('0' + (n / 1000) % 10);
    out[2] = (char)('0' + (n / 100)  % 10);
    out[3] = (char)('0' + (n / 10)   % 10);
    out[4] = (char)('0' + (n)        % 10);
    out[5] = 0;
}
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

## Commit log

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2026-05-12 Add Sheet 2 (Pico 2) + fix Y-axis convention bug in Sheet 1
    CRITICAL FIX in Sheet 1: lib_symbol pins use Y-UP (math) convention,
    but schematic placement uses Y-DOWN (screen). Conversion is
    abs_pin_y = sym_y - local_pin_y. The original Sheet 1 had USB-C
    VBUS pins (A1/A4/B1/B4) actually wired to the GND trunk and GND
    pins (A12/A9/B9/B12) wired to the +5V trunk — a power short if built.
    Both sheets now use Y-DOWN coords throughout with explicit pin position
    constants. The analyzer confirms correct pin_nets assignment:
    - J1 (USB-C): VBUS pins → +5V_USB ✓, GND pins → GND ✓
    - U1 (Pico 2): all 40 pins map to correct signals per SPEC v0.6 §5
    Sheet 2 contents per SPEC v0.6 §5:
    - U1 Rasp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
    [field_ambience.kicad_sch, pico.kicad_sch]
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2026-05-12 Add Sheet 4 (MCP23017 + 10 Switches) per SPEC v0.6 §7
    U2 MCP23017-E/SS (SSOP-28, C506653) als I/O-Expander mit:
    - I²C-Adresse 0x20 (A0=A1=A2=GND, Pin 15/16/17)
    - Pin 12 SCL, Pin 13 SDA → Pico GP3/GP2 via Hier-Labels
    - R4 4.7k SDA Pull-Up, R5 4.7k SCL Pull-Up zu +3V3
    - Pin 9 VDD → +3V3 mit C5 100nF + C5b 10nF Decoupling
    - Pin 10 VSS → GND
    - Pin 18 ~RESET → R6 10k Pull-Up zu +3V3
    - Pin 20 INTA → R20 10k Pull-Up zu +3V3 (SPEC v0.6 H3-Fix)
    + Hier-Output MCP_INT zu Pico GP22
    - Pin 19 INTB → NC (MIRROR=1 in IOCON Firmware-config)
    10 Switches Kailh Choc V2 Hot-Swap (user-supplied, JLC stockt nicht):
    - SW1-SW5 (Cells, 2u): GPA0-GPA4 → CELL1-CELL5
    - SW6-SW10 (Modifier, 1u): GPB0-GP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
    [field_ambience.kicad_sch, mcp.kicad_sch, pico.kicad_sch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]
2026-05-15 Add Sheet 5 (4x EC11 Encoder + RC-Debounce) per SPEC v0.6 §5/§M4
    4 EC11-Encoder mit Push-Switch + Pull-Ups + Debounce-Caps:
    - EN1 Drive (GP10/11/12)
    - EN2 Brightness (GP13/14/15)
    - EN3 Display (GP16/17/18)
    - EN4 Volume (GP19/20/21)
    Per encoder:
    - A-Pin: R pull-up 10k zu +3V3, C debounce 100nF zu GND (v0.6 M4 Fix)
    - B-Pin: R pull-up 10k, C debounce 100nF
    - C-Pin: direkt zu GND (Common)
    - SW1-Pin: R pull-up 10k, Hier-Output zu Pico
    - SW2-Pin: direkt zu GND
    BOM Sheet 5: 12× R 10k (8 für A/B-Pull-Ups R7-R14 + 4 für SW R15-R18),
    8× C 100nF (Debounce C10-C17), 4× EC11 Encoder.
    Root sheet umstrukturiert für Layout-Platz:
    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
    [encoder.kicad_sch, field_ambience.kicad_sch, mcp.kicad_sch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]
2026-05-16 Add Sheet 6 (Audio) per SPEC v0.6 §8 + H2/M2/C2 Fixes
    U3 PCM5102A (TSSOP-20, C107671) I²S DAC:
    - Pin 1-3: I2S_LRCK/BCK/DOUT ← hier-inputs (von Sheet 7 Pi-Header später)
    - 3-wire mode: SCK (pin 18) → GND (internal PLL aus BCK)
    - FMT (8) → GND I²S mode, FLT (5) → GND, DEMP (6) → GND
    - XSMT (7) → R_XSMT 10k pull-up zu +3V3 (un-muted by default)
    - VCOM (14): C_VCOM 1µF filter, VNEG (11): C_VNEG 1µF filter
    - CPVDD (13): C_CPVDD 10µF + 100nF (charge pump supply)
    - DVDD (19): C8a 10µF + C8b 100nF (digital)
    - AVDD (15): via FB1 BLM18AG601 + C7a 10µF + C7b 100nF (v0.6 M2 Fix)
    - VOUTL (9), VOUTR (16) → coupling zu PAM8403
    FB1 BLM18AG601 (C19330) Ferrit-Bead zwischen +3V3 und AV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
    [audio.kicad_sch, encoder.kicad_sch, field_ambience.kicad_sch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]
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2026-05-16 Fix PCM5102A and PAM8403 pinouts per official datasheets (Review Fix)
    CRITICAL FIX from PR #1 review: Audio-IC symbols had invented pinouts
    instead of official datasheet-correct mappings. Any PCB layout from
    the previous version would have routed I²S, power and audio-out to
    the wrong physical pads.
    PCM5102A (TI SLAS859C, TSSOP-20) — corrected pinout:
    Old (wrong) → New (per TI datasheet)
    Pin 1 = LRCK → CPVDD
    Pin 2 = BCK → CAPP (charge pump fly cap +)
    Pin 3 = DIN → CPGND
    Pin 4 = GND → CAPM (charge pump fly cap -)
    Pin 5 = FLT → VNEG (1µF to GND)
    Pin 6 = DEMP → OUTL (audio ou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
    [audio.kicad_sch, encoder.kicad_sch, mcp.kicad_sch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]
2026-05-16 Fix PAM8403H pinout using official datasheet PDF (PAM8403H.PDF)
    The previous v0.6.1 fix for PAM8403 was based on a wrong DS31295
    guess. With the actual Diodes Inc PAM8403H datasheet PDF now in the
    repo (PAM8403H.PDF Rev 1-0 Nov 2012), the symbol can be verified
    pin-by-pin against the JLCPCB C17337 part.
    PAM8403H verified pinout (LCSC C17337):
    Pin 1: -OUT_L (Left negative output, BTL)
    Pin 2: PGND
    Pin 3: +OUT_L (Left positive output, BTL)
    Pin 4: PVDD
    Pin 5: MUTE (active LOW)
    Pin 6: VDD
    Pin 7: INL
    Pin 8: VREF ← bypass cap to GND REQUIRED per datasheet
    Pin 9: NC
    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
    [audio.kicad_sch, encoder.kicad_sch, mcp.kicad_sch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]
2026-05-17 CRITICAL FIX: USB-C VBUS/GND pin numbers swapped per USB Type-C Spec
    External review caught a hard hardware blocker. The Connector:USB_C_
    Receptacle symbol had VBUS on pin-numbers A1/A4/B1/B4 and GND on
    A12/A9/B9/B12. This is WRONG against the USB Type-C Spec Rev 2.1
    Table 3-1.
    Correct standard USB-C receptacle pinout:
    GND = A1, A12, B1, B12
    VBUS = A4, A9, B4, B9
    CC1 = A5
    CC2 = B5
    D+ = A6 (+ B6 reversed orientation)
    D- = A7 (+ B7 reversed orientation)
    SBU1 = A8
    SBU2 = B8
    PCB-killer scenario without this fix: When the PCB layout used the
    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
    [audio.kicad_sch, encoder.kicad_sch, mcp.kicad_sch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]
2026-05-17 v0.6.3-r2: PAM8403 SHDN/MUTE pull-downs + UART naming + TODO list
    Addresses 2nd-iteration ChatGPT review findings (most that don't need
    KiCad GUI). All TODO items documented in PCB_TODO.md.
    B4: PAM8403H /SHDN and /MUTE hardware pull-downs
    - R_MUTE_PD 10k from pin 5 (/MUTE) to GND
    - R_SHDN_PD 10k from pin 12 (/SHDN) to GND
    - Default state during Pico boot/reset = both LOW = Amp OFF + MUTED
    - Pico firmware drives HIGH only after power-sequencing per SPEC §5
    - Prevents undefined Amp state during boot transients (pop/click safety)
    I7: UART net naming disambiguated
    - Old: UART0_TX / UART0_RX (perspective-ambiguous)
    - New:
    - PICO_TX_PI_RX (Pico GP0 → Pi GPIO15 pin 10)
    - PI_TX_PICO_RX (Pi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
    [audio.kicad_sch, field_ambience.kicad_sch, pi.kicad_sch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]
2026-05-17 v0.6.3-r3: Important + Nice-to-Have items (all non-KiCad-GUI doable)
    Addresses I1-I6 + N2 + N3 from PCB_TODO.md. Only schematic-level
    hardware change is N2 (I²S series resistors); rest are doc updates.
    N2 — I²S Series-Resistoren am Pi-Header (HARDWARE):
    - R_BCK 33Ω 0603 between Pi pin 12 (GPIO18 PCM_CLK) and I2S_BCK hier
    - R_LRCK 33Ω 0603 between Pi pin 35 (GPIO19 PCM_FS) and I2S_LRCK hier
    - R_DOUT 33Ω 0603 between Pi pin 40 (GPIO21 PCM_DOUT) and I2S_DOUT hier
    - Dämpft Overshoot/Reflexionen über lange I²S-Strecke (~100mm Layer-Hop)
    - LCSC C23138 (RC0603FR-0733RL)
    I1 — Power-Budget realistisch (Doc):
    - Was 1.4 A peak in v0.6 → realistisch 2.48 A peak im Worst-Case
    - PAM8403 @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
    [pi.kicad_sch]
2026-05-17 v0.6.3-r4: SPEC body cleanup + audio gain fix (R_VOL 10k→20k)
    Addresses 3rd-round ChatGPT review: spec internal inconsistencies +
    real audio clipping risk.
    Audio fix — R_VOL_L/R 10kΩ → 20kΩ:
    - PAM8403H datasheet (DS31295): RI minimum = 18 kΩ for spec'd 24 dB gain.
    - With RI = 10kΩ: AVD = 2*142k/10k = 28.4 = 29 dB (exceeds spec, more
    clipping headroom needed in firmware).
    - With RI = 20kΩ: AVD = 2*142k/20k = 14.2 = 23 dB (within datasheet spec).
    - LCSC C25092 (RC0603FR-0720KL) instead of C25804 (10kΩ).
    SPEC body section cleanup (was contradicting v0.6.3-r3 errata):
    - §3 Power Budget: 1.405A peak (old, optimistic) → 2.48A realistic table
    - §3 USB-C Power Delivery: "5.1k = 3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
    [audio.kicad_sch]
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2026-05-19 v0.6.3-r5 N1-Fix: PCM5102A XSMT via MCP23017 GPA5 GPIO control
    User-Wunsch: "lieber direkt haben als nicht haben" — explizite GPIO-
    gesteuerte Pop-Suppression für PCM5102A statt nur statischem Pull-Up.
    Hardware-Änderungen:
    audio.kicad_sch (PCM5102A Pin 17 XSMT):
    - BEFORE: R_XSMT 10k pull-up zu DVDD (chip statisch un-muted)
    - AFTER:
    - R_XSMT_PD 10k pull-down zu GND (boot-safe default LOW = muted)
    - hier-input PCM_XSMT (vom MCP23017 via I²C-Steuerung)
    → Während Pico-Reset/Boot: XSMT bleibt LOW (DAC stumm), egal was
    der PCM5102A intern macht.
    mcp.kicad_sch (MCP23017 GPA5 = Pin 26):
    - BEFORE: NC_GPA5 reserve label (Pin ungenutzt)
    - AFTER: hier-output PCM_XSMT (drives PCM510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
    [audio.kicad_sch, field_ambience.kicad_sch, mcp.kicad_sch]
2026-05-19 v0.6.3-r6: Stabilization pass — PVDD decoupling, startup sequence, SPEC consolidation
    No new features. Pure stabilization per senior-engineer review.
    === HIGH fixes ===
    1. PAM8403H PVDD decoupling (pins 4, 13) — was missing
    Datasheet (PAM8403H.PDF "Application Information") requires:
    "1.0µF ceramic close to VDD" (HF) + "20µF or greater" (bulk).
    Previous: only C9 10µF + C9b 100nF at VDD (pin 6). PVDD pins 4 (L)
    and 13 (R) had no local decoupling → Class-D 250kHz switching
    transients would modulate PVDD → distortion at volume + EMI.
    Fix:
    - Left (VDD pin6 + PVDD-L pin4): C9 10µF→22µF (C45783), C9b 100nF→1µF
    - Right (PVDD-R pin13): NEW C_PVDDR 22µF +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
    [audio.kicad_sch, field_ambience.kicad_sch, pico.kicad_sch]
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2026-05-22 v0.7-pre: Choc V2 footprint fix + Line-Out/Headphone block (J8)
    Two real design improvements requested after the device evaluation.
    === 1. Switch footprint mismatch fixed (Choc V2) ===
    BUG: generator referenced Button_Switch_Keyboard:SW_Hotswap_Kailh_MX_*
    (MX hotswap) while BOM/SPEC specify Kailh Choc V2 throughout. MX and
    Choc V2 are physically incompatible (pin spacing, height, keycap stem).
    Building the MX footprint with Choc V2 sockets → parts don't fit.
    FIX: footprints → Switch_Keyboard_Hotswap_Kailh:SW_Hotswap_Kailh_Choc_V1V2_*
    (1.00u modifiers, 2.00u cells). Verified: 0 MX refs remain, 10 Choc refs.
    LIBRARY: these are NOT in KiCad standard libs. Requires the kiswitch
    keyswitch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
    [audio.kicad_sch, encoder.kicad_sch, field_ambience.kicad_sch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]
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2026-05-22 v0.7: close all open engineering decisions (power, inrush, mechanical, footprints)
    Resolved every remaining design decision and TBD so nothing blocks the
    PCB-layout phase except inherently-GUI tasks. Reconciled doc vs. design
    where they had drifted.
    POWER (I1/I2) — decided:
    - 5V/3A USB-C supply is now a HARD requirement; no PD controller in the
    prototype. Worst-case 2.45A < 3A, so the board may run at full output and
    the firmware volume-clamp is no longer a power-protection requirement
    (kept only as an optional acoustic measure for the 40mm drivers).
    - F1 polyfuse 2A/4A -> 3A/6A (Littelfuse 1812L300, LCSC C18198349). The old
    2A-hold derates to ~1.5A at ~50C enclosure temp and woul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
    [audio.kicad_sch, encoder.kicad_sch, field_ambience.kicad_sch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]
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2026-05-28 fix(pcb): add missing C1/C2 +5V-rail HF decoupling; reconcile BOM
    Component audit (SPEC §3 decoupling + §4 BOM) vs. every placed part found
    three BOM↔schematic discrepancies:
    - C1 (10µF X5R 0805) + C2 (100nF X7R 0603) were specced & counted (6×10µF /
    8×100nF) but never placed by power_tree_sheet(). The +5V rail had only
    C_BULK (1000µF Elko, poor HF response) + D2 TVS, no ceramic HF bypass.
    Now placed at rail taps x=80/86 (clear of R2/R3 and D1), GND drop with
    auto-junctions. 10µF instance count now = 6 (BOM-conform).
    - C_audio_filt (2×220nF) dropped from §4 BOM: never in schematic, PCM5102A
    has internal filter, TI ref design uses no output cap. §8 note added.
    - R_RUN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
    [power_tree.kicad_sch]
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2026-05-29 feat(bom): assign LCSC numbers to C1/C2 — every part now sourced
    C1/C2 were the only two components missing a part number (added this
    session). Both resolved to JLCPCB Basic parts via jlcsearch (no extended-
    part assembly fee, in stock, voltage far above the 5V rail):
    C1 = C15850 Samsung CL21A106KAYNNNE 10uF 25V X5R 0805
    C2 = C14663 Yageo CC0603KRX7R9BB104 100nF 50V X7R 0603
    Audit: all 97 placed components now have BOTH a footprint and an LCSC/MPN.
    Zero sourcing gaps remaining. MEINE_TODO Abschnitt 0 updated.
    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
    [power_tree.kicad_sch]
2026-05-29 bom: stock/price check of all LCSC parts; swap R1 to Basic
    Verified all 23 distinct LCSC numbers via jlcsearch (2026-05-29):
    - 22/23 resolve cleanly; ~$3.62 SMT component cost per board.
    - R1 was the only accidental Extended part (Yageo RC0603FR-071KL/C22548).
    Swapped to Uni Royal 0603WAF1001T5E/C21190 — same family as every other
    resistor, JLC Basic, 15.8M stock. No extended-part setup fee.
    Flagged for the user (no blind change made):
    - J8 jack C2884109 not in parts DB — confirm against the real purchased
    part before order (SMD candidate C431535). Tied to footprint check B0b.
    - U2 MCP23017 C506653 stock only 357 — fine for one proto, watch for order.
    MEINE_TODO Abschnitt 0 upd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
    [pi.kicad_sch]
2026-05-29 fix(bom): make entire BOM correctly JLC-orderable — 7 real part errors fixed
    Verified every LCSC number against jlcsearch for existence, stock, AND that
    it resolves to the intended value/package. Found 7 parts that would have
    built WRONG or were unorderable:
    CRITICAL value/package errors (LCSC pointed at the wrong part):
    - R_VOL_L/R: C25092 = 22ohm 0402 -> C4184 (real 20k 0603, Basic).
    Was wrong value AND footprint; would have wrecked the PAM8403 input gain.
    - R_LO_L/R: C22962 = 220ohm -> C23345 (real 22ohm 0603, Basic).
    - R_BCK/LRCK/DOUT: C23138 = 330ohm -> C23140 (real 33ohm 0603, Basic).
    Unorderable -> assigned real in-stock parts:
    - J8 jack: C2884109 (nonexistent) -> C431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
    [audio.kicad_sch, encoder.kicad_sch, mcp.kicad_sch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]
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2026-05-30 feat(native): Step 6 — Pi removed from schematic + BOM (97→92 parts)
    Now that the RP2350 owns display, buttons, encoders, and I²S audio
    (Steps 1-5), the Raspberry Pi Zero 2 W comes out of the device.
    generate_kicad_project.py:
    - Deleted pi.kicad_sch (Sheet 7, Pi header); removed it from the kicad_pro
    sheet list, the root sheet hierarchy, and main()'s writer.
    - 5 components removed: J2 (40-pin Pi header), R1 (UART RX series),
    R_BCK/R_LRCK/R_DOUT (Pi-side I²S series Rs). Real component count 97→92.
    - pico_sheet: GP0/GP1/GP4 repurposed from UART TX/RX + unused OLED MISO
    to I2S_BCK / I2S_LRCK / I2S_DOUT (RP2350 PIO I²S master). Fixed a
    pin-number vs GP-number slip so I2C_SDA/SC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
    [field_ambience.kicad_sch, pi.kicad_sch, pico.kicad_sch]
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2026-05-31 pcb(gen): r10-LED — KiCad-Generator nachgezogen (PCA9685 + 10 LEDs + SW-MPN-Swap)
    Erste Hälfte von r10-B9/r7-B3 (Generator-Update). Schließt die r10-LED-Lücke
    zwischen SPEC (committed in 3a10761) und KiCad-Schematic-Output.
    SPEC-Fix (parallel): PCA9685 EXTCLK Pin 25 von "NC" auf "GND". NXP-Datasheet
    Rev 4 S.7 Footnote [2] schreibt explizit Ground vor wenn unused — wäre latenter
    Bug (undefined HF-Pickup, Oscillator-Destabilisierung). Datasheet via WebFetch
    + PDF-Read verifiziert.
    Generator-Änderungen in generate_kicad_project.py:
    - NEU `_pca9685pw_lib_symbol()` (TSSOP-28, alle 28 Pins per NXP-Datasheet)
    + LIB_SYMBOLS-Composition-Append
    - SW6-SW10 Footprint/MPN-Swap: Kailh Choc V2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
    [audio.kicad_sch, encoder.kicad_sch, mcp.kicad_sch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]
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2026-06-01 pcb(gen): kicad-Analyzer-Bugfixes (ERC: 8 errors→6, NT-001 33→16)
    Schematic-Analyzer fand drei klassen von echten Connectivity-Bugs in den
    beiden Generator-Catchup-Commits (50b5e02 + 0a3a740). Alle gefixt.
    Bug 1: Label-Position 3mm neben Wire-Endpunkt → 33 dangling-pin-Nets
    - r10-LED PCA-pin-Labels (10 LEDs + 5 NC + STATUS_LED_K) saßen bei
    PCA_PIN_*_X±8 statt ±5 → keine 10 LEDs waren physisch an PCA9685
    connected. Fix: Labels auf Wire-Endpunkt verschoben.
    Bug 2: Sub-mm-Gaps (0.19mm) zwischen Wires und Resistor-Pins
    - R rotation=90 horizontal hat pin1/pin2 bei sx±3.81 (X.19/X.81).
    Meine Wires endeten bei integer-mm → 0.19mm Gap = dangling.
    - Fixed: R_OE (mcp_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
    [battery.kicad_sch, field_ambience.kicad_sch, mcp.kicad_sch]
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2026-06-01 pcb(bom): r12-B12 — 9 falsche LCSC-Codes via jlcsearch-Audit korrigiert + r12-B11 TPS-Package-Blocker
    JLC-Pricing-Estimate-Run hat 9 falsche LCSC-Codes im Generator aufgedeckt.
    Alle MPN-Strings waren korrekt, aber die zugewiesenen LCSC-Codes pointed
    auf völlig andere Teile. Bei sofortiger JLC-Bestellung wäre der Prototyp
    DOA gewesen (BAT_SENSE-Divider 130Ω/130Ω statt 100k/100k, Boost-FB 15Ω/0.21k
    statt 200k/39k, alle LEDs nicht-existent, etc.).
    Korrigierte Mappings (via jlcsearch-API-Verifikation):
    - 100kΩ 0603 (R_BAT_DIV_TOP/BOT, R_VBUS_PD): C22796 → C25803 (Basic)
    - 200kΩ 0603 (R23): C22810 → C25811 (Basic)
    - 39kΩ 0603 (R24): C25090 → C23153 (Basic)
    - 390Ω 0603 (R_LED6-15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
    [battery.kicad_sch, mcp.kicad_sch, pico.kicad_sch]
2026-06-01 pcb(gen): r12-B11 RESOLVED — TPS61089-Refactor RNSR → RNR (JLC-soviel-wie-möglich)
    User-Decision: Option 1 (JLC-Bestücken-Strategie). TPS61089RNSR (QFN-12 3×3
    nicht bei LCSC verfügbar) gegen TPS61089RNR (VQFN-11 HotRod 2×2.5 + ePAD,
    LCSC C165129 Extended $0.41, 2.775 Stock) getauscht.
    Generator-Changes:
    - _tps61089_lib_symbol() komplett neu auf 11 Pins per TI Datasheet SLVSD38C:
    FSW, VCC, FB, COMP, GND, VOUT (left); SW, BOOT, VIN, ILIM, EN (right); ePAD
    - battery_sheet U8-Block komplett umverdrahtet — neuer Pinout, alle 11 Pins
    + ePAD korrekt connected
    - 6 neue externe Bauteile (alle BASIC oder PREFERRED, keine Extended-Fees!):
    * C_VCC 1µF (C15849) — interne LDO-Decoupli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
    [audio.kicad_sch, battery.kicad_sch, encoder.kicad_sch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]
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2026-06-03 repo: cleanup — archive pre-Step-6 artefacts under legacy/, sort datasheet
    Three-block tidy of the working tree:
    A · Local-only (already .gitignored, not in the commit):
    firmware-c/build (~25 MB), kicad/analysis (~19 MB, 6 snapshots all dated
    2026-06-01, regenerable via kicad-skill), __pycache__/. ~44 MB disk freed.
    B · Archive obsolete pre-Step-6 sources under legacy/ (git mv, history kept):
    firmware/ → legacy/firmware-mpy/ (MicroPython UI, replaced
    by firmware-c/ in Step 6)
    field_ambience_bridge.py → legacy/bridge.py
    field_ambience_panel.html → legacy/panel.html
    field_ambience_skill.md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
    [config.py, encoders.py, main.py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]
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2026-06-07 r16: SSD1322 OLED → 1.9" ST7789 IPS LCD + UI polish + display sim (#17)
    * fix(engine): master stage — DC blocker + volume + clean limiter (hörtest)
    On-device listening test surfaced "earrape / übersteuert / überbasst /
    brummt" — not like the webapp. Root cause was the master stage, not the
    layering (contra the on-the-fly analysis):
    1. NO DC blocker anywhere. The Step-11 plan called for "LeakDC" and it was
    never implemented. DC + subsonic energy from the brown-noise texture bed,
    the sub-bass and especially the reverb feedback loop accumulated into
    low-frequency rumble → the "brummt".
    2. The master was tanf(L * 0.9) — a CONTINUOUS distortion, not the webapp's
    masterV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
    [oled.h]
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2026-06-11 pcb(r18.5): Schematic-Migration Phase 3 — STM32H743 + LCD im Generator, Repo-Audit-Fixes
    KERN: generate_kicad_project.py erzeugt jetzt die H7-Architektur.
    NEU stm32h743.kicad_sch (ersetzt pico.kicad_sch -> kicad/legacy_pico2/):
    - 100-Pin-Symbol 1:1 aus offizieller KiCad-Lib (MCU_ST_STM32H7),
    doppelt verifiziert gegen SPEC v0.7 §5 / DS12110 Rev 5 Table 8 —
    alle 52 belegten Zuordnungen identisch (zwei unabhängige Quellen)
    - alle SPEC-§5-Netze verdrahtet, 48 Reserve-GPIOs no_connect
    - Support: HSE Y1 ABLS-8.000MHZ-B4-T (C596838) + 2x22pF, VCAP 2x2.2uF
    (DS12110 Tab.24), 5x(4.7uF+100nF) VDD-Bank, VDDA-Ferrit C84094 +
    1uF+100nF, BOOT0-PD 10k, NRST-PU 10k+100nF, SWD-J4 (PA13/PA14/GN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
    [audio.kicad_sch, encoder.kicad_sch, field_ambience.kicad_sch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]
2026-06-11 pcb(r18.6): Engineering-Verifikation — AP7361C-Pinout-Fix, TPS61089-Quelle, Custom-FP, BOM-LCSC, ADR-MIDI
    Reaktion auf User-Korrekturen aus öffentlichen Datasheets. Vier
    🔴-Blocker geschlossen, einer auf eine Design-Entscheidung umklassifiziert.
    === AP7361A-Pinout war FALSCH — gefixt + AP7361C ===
    r18.5-Annahme: 1=ADJ/NC, 2=OUT, 3=IN, 4=GND, 5=EN.
    Korrekt (Diodes-DS via mouser.de/datasheet/3/175/1/AP7361.pdf,
    User-verifiziert):
    1=EN, 2=GND, 3=ADJ/NC, 4=IN, 5=OUT
    Hätte zu einem totem Board geführt (IN/OUT/EN vertauscht).
    Zusätzlich:
    - Symbol auf AP7361C umbenannt (Diodes markiert AP7361 als NRND ->
    use AP7361C; gleicher SOT-89-5-Pinout)
    - AP7361C-33Y5-13 = LCSC C460397 (SO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
    [audio.kicad_sch, battery.kicad_sch, encoder.kicad_sch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]
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2026-06-12 pcb(r18.10): Engineering-Realitaetscheck — SW_BOOT, USB-C-Upgrade, BOM-Sync (ADR-0009)
    User-Frage: welche Entscheidungen sinnvoll, welche nicht. Vier Fix-Cluster.
    === KRITISCH: BOOT-Button gefehlt ===
    Befund: BOOT0 hatte nur 10k-Pulldown. USB-DFU-Flash setzt BOOT0=HIGH
    beim Reset voraus -> war physikalisch unmoeglich. SPEC §1-Diagramm
    behauptete faelschlich "USB-DFU oder ST-Link".
    Fix stm32h743_sheet:
    - SW_BOOT (Switch:SW_Push, TS-1185A-C-A / C720477) Pin1 -> BOOT0_PIN
    - R_BOOT_SW 1k 0603 (C21190) zwischen SW_BOOT-Pin2 und +3V3
    - 1k-Serie limitiert Querstrom auf 3 mA falls SW_RESET gleichzeitig gedrueckt
    - Bedienung: SW_BOOT halten -> NRST tippen -> loslassen -> System-Boot-Loader
    ST-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
    [power_tree.kicad_sch, stm32h743.kicad_sch]
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2026-06-12 pcb+fw(r18.14): Komponenten-Definition — 3D-Lib, 2 kritische BOM-Fixes, Encoder-Strategie (ADR-0012), Cell-Keys Magnetic-Hall (ADR-0013)
    User-Direktive: Komponenten vor Layout definieren, 3D-Daten zu allem, Cells
    wie HiChord mit langen Caps + Stabilizern, Encoder-Split + smooth + gleich
    hoch + flach (Kick75), Encoder-UX-Bug fixen.
    🔴 Kritische BOM-Fixes (via 3D-CAD-Abruf entdeckt):
    - USB-C: C165935 war ein STF18N65M5-MOSFET (TO-220F-3)! Korrekt: C283540
    (TYPE-C-31-M-17, LCSC-verifiziert). Falsch seit r18.10.
    - SW_BOOT: C720477 ist XUNPU TS-1088-AR02016 (nicht TS-1185A-C-A);
    FP von generisch TL3342 auf EasyEDA-verifiziertes SW_TS1088_SMD.
    3D-STEP-Library:
    - kicad/libraries/field_amb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
    [encoder.kicad_sch, power_tree.kicad_sch, stm32h743.kicad_sch]
2026-06-12 pcb(r18.14b): Komponenten-IDs verifiziert — EC11E + DRV5056
    Drei verbleibende TBD-VERIFY-Punkte aus r18.14a geschlossen:
    - EN3 Display: EC11E18244AU = C202365 (ALPS, 18P/36D + push, LCSC in stock)
    - EN1/2/4 Smooth: EC11E183440C = C370986 (ALPS, 18P/no-detent + push,
    selbe Bauform → alle 4 gleich hoch verifiziert)
    - Hall-Sensor: DRV5056A4QDBZR = C2152902 (TI SOT-23, 3.3V ratiometrisch)
    DRV5056-Pinout aus TI-DS Table 4-1 verifiziert (statt geraten):
    SOT-23: Pin 1=VCC, Pin 2=OUT, Pin 3=GND — matched 1:1 zur 1×3-Site.
    TO-92-Variante (Prototyp) hat ABWEICHENDE Belegung (1=VCC/2=GND/3=OUT) —
    Beine für Breadboard swappen.
    Generator + SPEC §4 mit echten LCSC-IDs + Datasheet-URLs vers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
    [encoder.kicad_sch, stm32h743.kicad_sch]
2026-06-13 fw(r18.15): Cell-Velocity-Modell implementiert (ADR-0013 Code-Seite)
    ADR-0013 hatte die Magnetic-Hall-Architektur im Schematic fixiert; der Pfad
    Hall-ADC → Velocity → Note war nur beschrieben. Jetzt implementiert + getestet.
    Neues Modul cells.{h,c}:
    - Per-Cell-State-Machine REST→ARMED→HELD, gefüttert mit normierter Position 0..1
    - Velocity = Banddurchlaufzeit (0.15→0.55): ≤6ms=laut, ≥70ms=leise
    - Note-On am Trigger, Note-Off mit Hysterese (Release 0.30) gegen Chatter
    - Velocity → Amplitude 0.05..0.22 (Gamma 0.8); pure Logic, kein SDK
    - robust gegen grobes Sampling (Single-Sample-Slam = Max-Velocity)
    Engine-Integration:
    - engine_cell_sample(cell, pos, now_ms): PRESS spielt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
    [cells.h]
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
